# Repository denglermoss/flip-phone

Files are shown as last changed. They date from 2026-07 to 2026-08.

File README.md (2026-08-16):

# Custom Phone Project

## Overview

Designing and building a custom cell phone from scratch — hardware (PCB, electronics), embedded firmware, cellular communication, and eventually mechanical/enclosure design. Candybar / single-board form factor (locked 2026-08-16 — flip/clamshell deferred to v2). Long-term vision: the phone is the hub of a personal ecosystem of USB-connected devices. See `docs/ref/problem-definition.md` for full architecture, MVP, risks, and ecosystem vision.

## Goals

- **Learning / Portfolio**: Deepen hardware and embedded systems skills; build something impressive.
- **Actually Usable**: End goal is a device that can make real phone calls on a real cellular network.
- **The Challenge**: Push beyond prior experience (microcontrollers, simple PCBs) into RF, cellular comms, power management, and eventually mechanical integration.

## Scope

### In Scope
- Custom PCB design (candybar / single-board — display via ZIF connector, no hinge flex)
- Microcontroller + off-the-shelf cellular module architecture
- Firmware: call handling, UI, contacts, power management
- Making real phone calls on a real network
- Mechanical/enclosure design (deferred — decided after electronics are proven)
- Hardware selection constrained to preserve USB connectivity for future ecosystem modules

### Out of Scope (for now)
- Custom cellular modem / baseband processor design
- FCC certification (prototype stage; revisit if moving toward production)
- App store, browser, or smartphone features (camera IS included on rev1 — see `docs/ref/project-log.md` 2026-08-16)
- Custom OS (will use RTOS or bare metal)
- Ecosystem module design (car system, etc.) — future projects, not this one

## Documentation

Full doc index and source-of-truth assignments in `AGENTS.md`. Key docs:

- `docs/ref/problem-definition.md` — architecture, MVP, risks, ecosystem vision
- `docs/ref/requirements.md` — functional & non-functional requirements
- `docs/ref/constraints.md` — technical, budget, regulatory constraints
- `docs/ref/project-log.md` — decision log (dated), phase breakdown
- `docs/ref/bom.md` — bill of materials with prices and links
- `docs/work/` — active planning docs (block-diagram, pin assignment, task tracker, schematic completion plan, UI design)
- `docs/archive/` — completed/superseded plans + all revisit prompts

## Status

**Phase 1 (Research & Component Selection) — Complete.** All guiding hardware decisions locked: MCU (STM32H743ZI), modem (SIM7600NA-H), codec (ALC5651-CG), display (ST7789V SPI TFT), keypad (SMD tactile switches), USB architecture (modem-direct tethering, no ULPI). Zephyr development environment set up (2026-06-29).

**Phase 2 (HAT-Based Prototype) — Complete.** MVP achieved (2026-07-13): MCU firmware places and receives VoLTE calls with audio on Mint LTE. Keypad integrated + verified (2026-07-18): standalone dialer — user types phone numbers and places real calls with no PC involvement. See `docs/ref/project-log.md` Phase Breakdown.

**Phase 3 (Schematic Design) — In Progress (2026-07-28).** All parts sourced with KiCad models (no consignment). Schematic approach: flat sheet + global labels, MPCIe modem form factor (primary), LGA fallback. **Per-sheet progress** (see `docs/work/schematic-completion-plan.md` for details): Power ✅, MCU ~92%, Modem ~90%, Codec ✅ (restored), Keypad ✅, Display main ~80% (backlight FET pending), Display daughter ~70%, SIM/SD ✅. ERC: 0 errors, 15 warnings. Remaining work tracked in `docs/work/schematic-completion-plan.md`; full Phase 3-5 plan in `docs/work/task-tracker.md`.

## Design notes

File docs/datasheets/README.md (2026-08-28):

---
status: reference
updated: 2026-08-02
---
# Reference Documentation

Local copies of vendor datasheets, reference manuals, hardware design docs, and saved wiki pages that this project relies on. These are **not** version-controlled (see `.gitignore` — everything in this directory except this README is ignored). They are large binary files that vendors update independently. This index records what belongs here, the exact part numbers, and where to download each so anyone can re-fetch the current version.

## How to populate

Download each file below into this directory (`docs/datasheets/`). Browser "Save Page As" creates an `.html` file plus a `_files/` subdirectory of assets — both belong here. The `.gitignore` excludes everything except this README, so the files stay local-only.

## Mandatory: add missing datasheets before citing them

**If you need to reference a datasheet that is not already in this directory, you MUST find and download it first — do not cite specs from memory, web search snippets, or session context alone.** The local PDF is the source of truth for every part used in this project.

Workflow when a datasheet is missing:
1. Find the official PDF on the vendor's website (manufacturer product page → "Datasheet" link) or a reputable mirror (LCSC product page, Mouser, DigiKey, Analog Devices, TI, ST, etc.).
2. Download it into `docs/datasheets/` with a descriptive lowercase filename (e.g., `max17048.pdf`, `tps7a02.pdf`).
3. Add a row to the "Index → PDFs" table below with the filename, part/document name (including revision if known), and source URL.
4. Then cite the local PDF in project docs (e.g., `docs/datasheets/max17048.pdf §Pin Description`).

This rule exists because datasheet specs vary by revision and package variant — citing from memory risks the kind of pinout/voltage/package errors that are expensive to catch after PCB fab. If a datasheet cannot be found (rare — most parts have public datasheets), say so explicitly in the project log and flag the spec as unverified.

## Index

### PDFs

| File | Part / Document | Source |
|---|---|---|
| `SIM7600 Series Hardware Design_V1.03.pdf` | SIMCom SIM7600 Series Hardware Design Manual V1.03 (the version cited in project docs — §3.6 PCM interface, Table 32 1.8V Digital I/O) | https://simcom.ee/documents/SIM7600E/SIM7600%20Series%20Hardware%20Design_V1.03.pdf |
| `SIM7600_Series_PCIE_Hardware_Design_V1.03.pdf` | SIMCom SIM7600 Series PCIE Hardware Design Manual V1.03 (2020-03-20, 59pp) — Mini PCIe form factor variant. §2.2 edge connector pin description (PCM on pins 45/47/49/51 for PCIE variant, NC for PCIEA variant). §3.10.1 PCM interface spec (master, short sync, 16-bit, 2048kHz — same as LGA). §3.7 USIM (manual claims onboard SIM socket but Techship spec lists it as optional `o` — stock card does NOT have it; both variants need PCB SIM socket). §3.8 UART (1.8V logic — level shifter needed for 3.3V MCU). §3.6 USB 2.0 HS. Key: PCIE = no onboard codec = PCM digital audio (what we want); PCIEA = onboard NAU8810 = analog audio. | https://www.simcom.com/download/list-863-en.html (SIMCom download portal — search "SIM7600 PCIE Hardware Design") |
| `SIM7600_Series_Hardware_Design_V1.08.pdf` | SIMCom SIM7600 Series Hardware Design Manual V1.08 (newer, same PCM spec, may have fixes) | https://edworks.co.kr/wp-content/uploads/2022/04/SIM7600_Series_Hardware_Design_V1.08.pdf |
| `max9880a.pdf` | Analog Devices MAX9880A datasheet (Rev 2) — dual-port codec, TQFN-48. **SUPERSEDED 2026-07-19**: MAX9880A replaced by ALC5651 (see below). Retained for historical reference. | https://www.analog.com/media/en/technical-documentation/data-sheets/MAX9880A.pdf |
| `alc5651.pdf` | Realtek ALC5651 datasheet (Rev 0.9) — dual I2S/PCM audio hub codec, QFN-40 5×5mm. **Current codec (LOCKED 2026-07-19).** §7.5.1 Two I2S/PCM Interface (PCM Mode A = short sync, compatible with SIM7600). §7.4.1 PLL (2.048–40MHz input). §10 Application Circuit (Figure 36). Pinout Figure 4 (40-pin QFN). | https://www.lcsc.com/product-detail/C963633.html (datasheet link) |
| `tps63021.pdf` | Texas Instruments TPS6302x (TPS63020/TPS63021) datasheet (SLVS916I, Rev. I, Oct 2019) — 4A-switch buck-boost converter, VSON-14 (DSJ). TPS63021 = fixed 3.3V out; TPS63020 = adjustable. Covers L1 inductor selection (§8.2.1, recommended 1.5µH Coilcraft XFL4020-152ML). | https://www.ti.com/lit/ds/symlink/tps63021.pdf |
| `max17048.pdf` | Analog Devices/Maxim MAX17048-MAX17049 datasheet (Rev 7, Nov 2016, 19pp) — 3µA 1-Cell/2-Cell ModelGauge fuel gauge, TDFN-8 2×2mm + WLP. **MAX17048 senses battery voltage on VDD (pin 3); CELL (pin 2) is NC on the 1-cell part.** §Pin/Bump Descriptions p6, §Quick-Start p9, §Hibernate Mode p9. | https://www.analog.com/media/en/technical-documentation/data-sheets/MAX17048-MAX17049.pdf (mirror used: https://media.digikey.com/pdf/Data%20Sheets/Maxim%20PDFs/MAX17048-49_Rev7_Nov2016.pdf) |
| `mcp73831.pdf` | Microchip MCP73831/MCP73832 datasheet (DS20001984H, Rev H, 2020, 29pp) — Li-Ion/Li-Po linear charge management controller. **DFN-8 2×3mm + SOT-23-5 variants** (LCSC C150772 maps to DFN-8 despite "/MC" suffix). Pinout p1, electrical characteristics §1.0 p3-4. | https://ww1.microchip.com/downloads/aemDocuments/documents/APID/ProductDocuments/DataSheets/MCP73831-Family-Data-Sheet-DS20001984H.pdf (mirror used: https://cdn.sparkfun.com/assets/5/b/0/3/1/MCP73831_Datasheet.pdf) |
| `usblc6-2.pdf` | STMicroelectronics USBLC6-2 datasheet (DS4260 Rev 7, Dec 2021, 14pp) — very low capacitance ESD protection for USB 2.0. **Protects D+, D-, AND VBUS** (6-pin SOT-23-6: pins 1/6 = I/O1 D+, pins 3/4 = I/O2 D-, pin 2 = GND, pin 5 = VBUS). IEC 61000-4-2 Level 4 (±15kV air, ±8kV contact). 3.5pF max capacitance — USB 2.0 high-speed compatible. | https://www.st.com/content/ccc/resource/technical/document/datasheet/06/1d/48/9c/6c/20/4a/b2/CD00050750.pdf/files/CD00050750.pdf/jcr:content/translations/en.CD000507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 (mirror used: https://file.huaqiu.com/web1/M00/7F/9E/pIYBAFwjN3uAIFePAANr_4V7kNY752.pdf?filename=USBLC6-2_ST.pdf) |
| `stm32h743zi.pdf` | STMicroelectronics STM32H743ZI datasheet (LQFP-144 electrical/mechanical/pinout) | https://www.st.com/resource/en/datasheet/stm32h743zi.pdf |
| `dm00314099-stm32h742-stm32h743753-and-stm32h750-value-line-advanced-armbased-32bit-mcus-stmicroelectronics.pdf` | STMicroelectronics RM0433 Rev 8 — STM32H742/H743/753/H750 reference manual (peripheral registers, 3353 pp) | https://www.st.com/resource/en/reference_manual/dm00314099-stm32h742-stm32h743753-and-stm32h750-value-line-advanced-armbased-32bit-mcus-stmicroelectronics.pdf |
| `dm00499160-stm32h7-nucleo144-boards-mb1364-stmicroelectronics.pdf` | STMicroelectronics UM2407 Rev 5 — STM32H7 Nucleo-144 boards (MB1364) user manual (board schematics, jumper config, ST-Link) | https://www.st.com/resource/en/user_manual/dm00499160-stm32h7-nucleo144-boards-mb1364-stmicroelectronics.pdf |
| `ST7789V.pdf` | Sitronix ST7789V LCD controller datasheet (240RGB×320, 262K color TFT controller/driver) — covers main display (ST7789T3). ~~Also covered outer display (ST7789V3)~~ **outer display DROPPED 2026-08-16** (candybar pivot). Datasheet still valid for main display. | https://newhavendisplay.com/content/datasheets/ST7789V.pdf |
| `HS20HS072RX-main-display.pdf` | HS HS20HS072RX panel datasheet — 2.0" IPS TFT, 240×RGB×320, ST7789T3, 12-pin 0.5mm ZIF FPC (main display, LOCKED 2026-07-19). Pinout: 1=GND, 2=CS, 3=RS(DC), 4=SCL, 5=SDA, 6=RST, 7=NC, 8=I/O-VCC, 9=VCC, 10=LEDA, 11=LEDK, 12=GND. **SPI 4-wire** (not I2C — SCL/SDA are Sitronix SPI naming, confirmed against ST7789V §8.4). Backlight: 4 white LEDs in parallel, Vf=3.0V, IL=80mA. **Schematic pinout verified 2026-08-27** — J_DISP1 matches datasheet (was previously wrong, corrected). ⚠️ Re-review FPC connector orientation during PCB layout. | https://www.lcsc.com/product-detail/C5329582.html |
| ~~`ER-TFT1.14-2-outer-display.pdf`~~ | ~~EastRising ER-TFT1.14-2 panel datasheet~~ — **DROPPED 2026-08-16** (outer display eliminated with candybar pivot). ~~1.14" IPS TFT, 135×240, ST7789V, 8-pin 0.5mm FPC (outer display, LOCKED 2026-07-19).~~ PDF retained in datasheets/ for historical reference but part is no longer in the design. See project-log.md 2026-08-16 Form Factor Pivot. | https://www.buydisplay.com/1-14-inch-tft-lcd-display-ips-panel-screen-135x240-for-smart-watch |
| `sn74axc4t774.pdf` | TI SN74AXC4T774 datasheet (SCES898C, Rev C, May 2022) — 4-bit dual-supply bus transceiver with independent direction control. TSSOP-16 (PWR suffix). Used as U12 for I2S-2 level shifting (3.3V↔1.8V) between MCU and ALC5651 codec. Direction-controlled (not auto-sensing like TXB0108 — TXB0108 is NOT recommended for I2S per TI SCEA135). LCSC C1849453. | https://www.ti.com/lit/ds/symlink/sn74axc4t774.pdf |
| `alps-ssss8.pdf` | ALPS Alpine SSSS8 Series slide switch datasheet — 1.4(H)mm, 1.5/2.0mm-travel, surface mount (reflow) SPDT. SSSS811101 = horizontal actuator, 1-pole 2-position, 300mA 5V DC, 10k cycles, 6.7×2.6×1.4mm. **SUPERSEDED 2026-08-02**: SSSS811101 (maintained slide) replaced by SSAL120100 (momentary pushbutton) for soft on/off + 5s hard off architecture. See project-log 2026-08-02. LCSC C109335. **Note: the previous `alps-ssss2.pdf` (SSSS2 Series, 3.5mm through-hole) was the wrong series datasheet — SSSS811101 is SSSS8 Series (1.4mm SMD). Replaced 2026-07-28.** | https://tech.alpsalpine.com/cms.media/product_catalog_sw_02_ssss8_en_e99db3d0b9.pdf |
| *(not downloaded)* | ALPS Alpine SSAL120100 — momentary SPDT slide switch ("Single-side Recoil Type", spring-return). 7.6×1.2×4.1mm, SMD right-angle, 10mA@5V DC, gull wing. LCSC C335996. **Datasheet PDF not downloadable** — ALPS tech site returns 403 on direct PDF access, LCSC returns HTML wrapper. Specs verified from ALPS product page (https://tech.alpsalpine.com/e/products/detail/SSAL120100/) and LCSC product page (https://www.lcsc.com/product-detail/C335996.html). If the PDF becomes accessible, download as `alps-ssal120100.pdf`. | https://tech.alpsalpine.com/e/products/detail/SSAL120100/ |
| `gct-usb4085.pdf` | GCT (Global Connector Technology) USB4085-GF-A product drawing — USB 2.0 Type-C receptacle, 16-pin through-hole, right-angle horizontal, 5A VBUS, 10k cycles. Replaces SMD TYPE-C-31-M-12. DigiKey + LCSC C7095263. | https://gct.co/files/drawing/usb4085.pdf |
| `tps7a02.pdf` | Texas Instruments TPS7A02 datasheet (SBVS277C, Rev. C) — nanopower-IQ (25 nA), 200-mA LDO with enable. Covers all fixed-output variants incl. **TPS7A0218PDBVR** (1.8V fixed, SOT-23-5/DBV, 5-pin) used as U9 (1.8V codec rail). §Pin Functions (DBV: 1=IN, 2=GND, 3=EN, 4=NC, 5=OUT), §Electrical Characteristics, §8.2 Application Circuit (1µF Cin, 1µF Cout min, EN smart pulldown). VIN 1.5–6.0V, VOUT 0.8–5.0V fixed, 1.5% accuracy, 205mV typ dropout @200mA (3.3V). | https://www.ti.com/lit/ds/symlink/tps7a02.pdf |

### Saved wiki pages (HTML + `_files/` subdirectory)

| File (+ assets dir) | Resource | Source URL |
|---|---|---|
| `2inch LCD Module - Waveshare Wiki.html` (+ `2inch LCD Module - Waveshare Wiki_files/`) | Waveshare 2inch LCD Module wiki — pinout, schematic, example code (ST7789VW) | https://www.waveshare.com/wiki/2inch_LCD_Module |
| `SIM7600NA-H 4G HAT - Waveshare Wiki.html` (+ `SIM7600NA-H 4G HAT - Waveshare Wiki_files/`) | Waveshare SIM7600NA-H 4G HAT wiki — HAT pinout, audio port, AT commands, antennas | https://www.waveshare.com/wiki/SIM7600NA-H_4G_HAT |

### Non-PDF references (bookmark, don't download)

| Resource | URL |
|---|-----|
| Waveshare 2inch LCD Module product page | https://www.waveshare.com/2inch-lcd-module.htm |
| Waveshare SIM7600NA-H 4G HAT product page | https://www.waveshare.com/product/sim7600na-h-4g-hat.htm |
| STMicroelectronics STM32H743/753 documentation hub | https://www.st.com/en/microcontrollers-microprocessors/stm32h743-753/documentation.html |
| ~~Analog Devices MAX9880A product page~~ **SUPERSEDED** | https://www.analog.com/en/products/max9880a.html |

## Exact part numbers (for cross-checking on vendor sites)

- **MCU**: STM32H743ZIT6 (LQFP-144, 2MB Flash, 1MB RAM)
- **MCU dev board**: NUCLEO-H753ZI (substitute for obsolete NUCLEO-H743ZI; H753 = H743 + crypto, identical for this project)
- **Cellular module (final PCB)**: SIM7600NA-H (JLC pre-order C5380303; "SIM7600A-H" was a misnomer — corrected 2026-07-19)
- **Cellular module (prototyping HAT)**: SIM7600NA-H (Waveshare HAT, SKU 30717)
- **Audio codec**: Realtek ALC5651-CG (QFN-40, 5×5mm) — LCSC C963633 (JLC Extended)
- **Display dev module**: Waveshare 2inch LCD Module, SKU 17344 (ST7789VW driver)
- **Display controller**: ST7789V (Sitronix; Waveshare module uses ST7789VW variant — same datasheet covers both)
- **Display raw panel (final PCB — LOCKED 2026-07-19)**: HS HS20HS072RX (LCSC C5329582) — 2.0" IPS TFT, ST7789T3, 12-pin 0.5mm ZIF FPC
- ~~**Outer display raw panel (final PCB — LOCKED 2026-07-19)**: EastRising ER-TFT1.14-2 (BuyDisplay) — 1.14" IPS TFT, ST7789V, 8-pin 0.5mm FPC (purchased from BuyDisplay, not LCSC — user assembles post-PCB)~~ **DROPPED 2026-08-16** — outer display eliminated with candybar pivot. See project-log.md 2026-08-16 Form Factor Pivot.

## Maintenance

When a vendor publishes a new revision, replace the local file and update the "Source" URL (and the version in the filename) in this index. If a document is cited by version in the project docs (e.g., "Hardware Design Manual V1.03 §3.6"), note the version change in `docs/ref/project-log.md` so the citation trail stays accurate.

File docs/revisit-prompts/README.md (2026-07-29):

# Revisit Prompts

## Active

| Prompt | Status | Created | Summary |
|---|---|---|---|
| _(none — all prompts resolved and archived)_ | — | — | — |

## Archived

The following prompts have been resolved and locked. The files are in `archive/` and retained for historical reference only — do not re-run them.

| Prompt | Status | Archived | Resolution |
|---|---|---|---|
| Parts Sourcing (`parts-sourcing-revisit.md`) | RESOLVED | 2026-07-28 | 16 of 16 items resolved; 2 deferred to Phase 7 (speakers LS1/LS2 — case-mounted, not PCB-assembled). All parts sourced: J3 nano-SIM = SHOU HAN NANO SIM XG6P H1.35 (C7529386), J4 microSD = Molex 472192001 (C164170). All other parts: U1-U12 ICs (U5 codec = ALC5651-CG), USBC1 USB-C (Korean Hroparts), J2 test points, J5/J6 U.FL (Hirose), J7-J10 FPC (HDGC 0.5K-HX), SW1-SW20 (ALPS SKQGABE010), Y1 crystal (ECS AEC-Q200), L1 inductor (Coilcraft XFL4020-152MEC), MK1 mic (ZILLTEK ZTS6117). **No consignment parts remain. All parts have KiCad models.** |
| Cellular Module Selection (`modem-revisit.md`) | RESOLVED & LOCKED | 2026-06-28 | SIM7600 confirmed after two rounds. LARA-R6401 disqualified (911 not supported). EC25-AF documented as PCB fallback. |
| Codec / Audio Path (`codec-audio-path-revisit.md`) | RESOLVED & LOCKED | 2026-06-28 | ~~MAX9880A dual-port codec selected~~ → **Realtek ALC5651-CG** (2026-07-19 — JLC Extended, no consignment). MCU not in voice path. Fallback: MCU bridge with NAU8822. |
| Display Type (`display-decision.md`) | RESOLVED & LOCKED | 2026-06-28 | ST7789V SPI color TFT (2.0" 240×320, RGB565) selected. Five options evaluated. |
| USB HS / ULPI (`zephyr-usb-hs-ulpi-revisit.md`) | RESOLVED & LOCKED | 2026-06-28 | USB3300 ULPI dropped. SIM7600's own USB 2.0 HS port does tethering directly. MCU USB OTG_FS sufficient. |

See `docs/project-log.md` for the full decision log and rationale.

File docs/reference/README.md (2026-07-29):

# Reference Documentation

Local copies of vendor datasheets, reference manuals, hardware design docs, and saved wiki pages that this project relies on. These are **not** version-controlled (see `.gitignore` — everything in this directory except this README is ignored). They are large binary files that vendors update independently. This index records what belongs here, the exact part numbers, and where to download each so anyone can re-fetch the current version.

## How to populate

Download each file below into this directory (`docs/reference/`). Browser "Save Page As" creates an `.html` file plus a `_files/` subdirectory of assets — both belong here. The `.gitignore` excludes everything except this README, so the files stay local-only.

## Mandatory: add missing datasheets before citing them

**If you need to reference a datasheet that is not already in this directory, you MUST find and download it first — do not cite specs from memory, web search snippets, or session context alone.** The local PDF is the source of truth for every part used in this project.

Workflow when a datasheet is missing:
1. Find the official PDF on the vendor's website (manufacturer product page → "Datasheet" link) or a reputable mirror (LCSC product page, Mouser, DigiKey, Analog Devices, TI, ST, etc.).
2. Download it into `docs/reference/` with a descriptive lowercase filename (e.g., `max17048.pdf`, `tps7a02.pdf`).
3. Add a row to the "Index → PDFs" table below with the filename, part/document name (including revision if known), and source URL.
4. Then cite the local PDF in project docs (e.g., `docs/reference/max17048.pdf §Pin Description`).

This rule exists because datasheet specs vary by revision and package variant — citing from memory risks the kind of pinout/voltage/package errors that are expensive to catch after PCB fab. If a datasheet cannot be found (rare — most parts have public datasheets), say so explicitly in the project log and flag the spec as unverified.

## Index

### PDFs

| File | Part / Document | Source |
|---|---|---|
| `SIM7600 Series Hardware Design_V1.03.pdf` | SIMCom SIM7600 Series Hardware Design Manual V1.03 (the version cited in project docs — §3.6 PCM interface, Table 32 1.8V Digital I/O) | https://simcom.ee/documents/SIM7600E/SIM7600%20Series%20Hardware%20Design_V1.03.pdf |
| `SIM7600_Series_PCIE_Hardware_Design_V1.03.pdf` | SIMCom SIM7600 Series PCIE Hardware Design Manual V1.03 (2020-03-20, 59pp) — Mini PCIe form factor variant. §2.2 edge connector pin description (PCM on pins 45/47/49/51 for PCIE variant, NC for PCIEA variant). §3.10.1 PCM interface spec (master, short sync, 16-bit, 2048kHz — same as LGA). §3.7 USIM (manual claims onboard SIM socket but Techship spec lists it as optional `o` — stock card does NOT have it; both variants need PCB SIM socket). §3.8 UART (1.8V logic — level shifter needed for 3.3V MCU). §3.6 USB 2.0 HS. Key: PCIE = no onboard codec = PCM digital audio (what we want); PCIEA = onboard NAU8810 = analog audio. | https://www.simcom.com/download/list-863-en.html (SIMCom download portal — search "SIM7600 PCIE Hardware Design") |
| `SIM7600_Series_Hardware_Design_V1.08.pdf` | SIMCom SIM7600 Series Hardware Design Manual V1.08 (newer, same PCM spec, may have fixes) | https://edworks.co.kr/wp-content/uploads/2022/04/SIM7600_Series_Hardware_Design_V1.08.pdf |
| `max9880a.pdf` | Analog Devices MAX9880A datasheet (Rev 2) — dual-port codec, TQFN-48. **SUPERSEDED 2026-07-19**: MAX9880A replaced by ALC5651 (see below). Retained for historical reference. | https://www.analog.com/media/en/technical-documentation/data-sheets/MAX9880A.pdf |
| `alc5651.pdf` | Realtek ALC5651 datasheet (Rev 0.9) — dual I2S/PCM audio hub codec, QFN-40 5×5mm. **Current codec (LOCKED 2026-07-19).** §7.5.1 Two I2S/PCM Interface (PCM Mode A = short sync, compatible with SIM7600). §7.4.1 PLL (2.048–40MHz input). §10 Application Circuit (Figure 36). Pinout Figure 4 (40-pin QFN). | https://www.lcsc.com/product-detail/C963633.html (datasheet link) |
| `tps63021.pdf` | Texas Instruments TPS6302x (TPS63020/TPS63021) datasheet (SLVS916I, Rev. I, Oct 2019) — 4A-switch buck-boost converter, VSON-14 (DSJ). TPS63021 = fixed 3.3V out; TPS63020 = adjustable. Covers L1 inductor selection (§8.2.1, recommended 1.5µH Coilcraft XFL4020-152ML). | https://www.ti.com/lit/ds/symlink/tps63021.pdf |
| `max17048.pdf` | Analog Devices/Maxim MAX17048-MAX17049 datasheet (Rev 7, Nov 2016, 19pp) — 3µA 1-Cell/2-Cell ModelGauge fuel gauge, TDFN-8 2×2mm + WLP. **MAX17048 senses battery voltage on VDD (pin 3); CELL (pin 2) is NC on the 1-cell part.** §Pin/Bump Descriptions p6, §Quick-Start p9, §Hibernate Mode p9. | https://www.analog.com/media/en/technical-documentation/data-sheets/MAX17048-MAX17049.pdf (mirror used: https://media.digikey.com/pdf/Data%20Sheets/Maxim%20PDFs/MAX17048-49_Rev7_Nov2016.pdf) |
| `mcp73831.pdf` | Microchip MCP73831/MCP73832 datasheet (DS20001984H, Rev H, 2020, 29pp) — Li-Ion/Li-Po linear charge management controller. **DFN-8 2×3mm + SOT-23-5 variants** (LCSC C150772 maps to DFN-8 despite "/MC" suffix). Pinout p1, electrical characteristics §1.0 p3-4. | https://ww1.microchip.com/downloads/aemDocuments/documents/APID/ProductDocuments/DataSheets/MCP73831-Family-Data-Sheet-DS20001984H.pdf (mirror used: https://cdn.sparkfun.com/assets/5/b/0/3/1/MCP73831_Datasheet.pdf) |
| `usblc6-2.pdf` | STMicroelectronics USBLC6-2 datasheet (DS4260 Rev 7, Dec 2021, 14pp) — very low capacitance ESD protection for USB 2.0. **Protects D+, D-, AND VBUS** (6-pin SOT-23-6: pins 1/6 = I/O1 D+, pins 3/4 = I/O2 D-, pin 2 = GND, pin 5 = VBUS). IEC 61000-4-2 Level 4 (±15kV air, ±8kV contact). 3.5pF max capacitance — USB 2.0 high-speed compatible. | https://www.st.com/content/ccc/resource/technical/document/datasheet/06/1d/48/9c/6c/20/4a/b2/CD00050750.pdf/files/CD00050750.pdf/jcr:content/translations/en.CD000507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 (mirror used: https://file.huaqiu.com/web1/M00/7F/9E/pIYBAFwjN3uAIFePAANr_4V7kNY752.pdf?filename=USBLC6-2_ST.pdf) |
| `stm32h743zi.pdf` | STMicroelectronics STM32H743ZI datasheet (LQFP-144 electrical/mechanical/pinout) | https://www.st.com/resource/en/datasheet/stm32h743zi.pdf |
| `dm00314099-stm32h742-stm32h743753-and-stm32h750-value-line-advanced-armbased-32bit-mcus-stmicroelectronics.pdf` | STMicroelectronics RM0433 Rev 8 — STM32H742/H743/753/H750 reference manual (peripheral registers, 3353 pp) | https://www.st.com/resource/en/reference_manual/dm00314099-stm32h742-stm32h743753-and-stm32h750-value-line-advanced-armbased-32bit-mcus-stmicroelectronics.pdf |
| `dm00499160-stm32h7-nucleo144-boards-mb1364-stmicroelectronics.pdf` | STMicroelectronics UM2407 Rev 5 — STM32H7 Nucleo-144 boards (MB1364) user manual (board schematics, jumper config, ST-Link) | https://www.st.com/resource/en/user_manual/dm00499160-stm32h7-nucleo144-boards-mb1364-stmicroelectronics.pdf |
| `ST7789V.pdf` | Sitronix ST7789V LCD controller datasheet (240RGB×320, 262K color TFT controller/driver) — covers both main display (ST7789T3) and outer display (ST7789V3) | https://newhavendisplay.com/content/datasheets/ST7789V.pdf |
| `HS20HS072RX-main-display.pdf` | HS HS20HS072RX panel datasheet — 2.0" IPS TFT, 240×RGB×320, ST7789T3, 12-pin 0.5mm ZIF FPC (main display, LOCKED 2026-07-19). Pinout: 1=GND, 2=CS, 3=RS(DC), 4=SCL, 5=SDA, 6=RST, 7=NC, 8=I/O-VCC, 9=VCC, 10=LEDA, 11=LEDK, 12=GND. | https://www.lcsc.com/product-detail/C5329582.html |
| `ER-TFT1.14-2-outer-display.pdf` | EastRising ER-TFT1.14-2 panel datasheet — 1.14" IPS TFT, 135×240, ST7789V, 8-pin 0.5mm FPC top contact (outer display, LOCKED 2026-07-19). Pinout: 1=LEDA, 2=GND, 3=RESET, 4=RS(DC), 5=SDA, 6=SCL, 7=VDD, 8=CS. Purchased from BuyDisplay (not LCSC) — assembled by user post-PCB-assembly. | https://www.buydisplay.com/1-14-inch-tft-lcd-display-ips-panel-screen-135x240-for-smart-watch |
| `sn74axc4t774.pdf` | TI SN74AXC4T774 datasheet (SCES898C, Rev C, May 2022) — 4-bit dual-supply bus transceiver with independent direction control. TSSOP-16 (PWR suffix). Used as U12 for I2S-2 level shifting (3.3V↔1.8V) between MCU and ALC5651 codec. Direction-controlled (not auto-sensing like TXB0108 — TXB0108 is NOT recommended for I2S per TI SCEA135). LCSC C1849453. | https://www.ti.com/lit/ds/symlink/sn74axc4t774.pdf |
| `alps-ssss2.pdf` | ALPS Alpine SSSS2 Series slide switch datasheet — 3.5(H)mm, 2mm-travel, through-hole SPDT. SSSS213100 = horizontal actuator, 1-pole 2-position, 300mA 6V DC, 10k cycles. Used as SW21 (power on/off via TPS63021 EN pin). LCSC C115374. **Note: SSSS213100 not confirmed on DigiKey — may need LCSC sourcing or C&K SS-12D1505-G 2 alternative.** | http://www.stm32circle.com/resources/Datasheets/ALPS_SSSS2.pdf |
| `gct-usb4085.pdf` | GCT (Global Connector Technology) USB4085-GF-A product drawing — USB 2.0 Type-C receptacle, 16-pin through-hole, right-angle horizontal, 5A VBUS, 10k cycles. Replaces SMD TYPE-C-31-M-12. DigiKey + LCSC C7095263. | https://gct.co/files/drawing/usb4085.pdf |

### Saved wiki pages (HTML + `_files/` subdirectory)

| File (+ assets dir) | Resource | Source URL |
|---|---|---|
| `2inch LCD Module - Waveshare Wiki.html` (+ `2inch LCD Module - Waveshare Wiki_files/`) | Waveshare 2inch LCD Module wiki — pinout, schematic, example code (ST7789VW) | https://www.waveshare.com/wiki/2inch_LCD_Module |
| `SIM7600NA-H 4G HAT - Waveshare Wiki.html` (+ `SIM7600NA-H 4G HAT - Waveshare Wiki_files/`) | Waveshare SIM7600NA-H 4G HAT wiki — HAT pinout, audio port, AT commands, antennas | https://www.waveshare.com/wiki/SIM7600NA-H_4G_HAT |

### Non-PDF references (bookmark, don't download)

| Resource | URL |
|---|-----|
| Waveshare 2inch LCD Module product page | https://www.waveshare.com/2inch-lcd-module.htm |
| Waveshare SIM7600NA-H 4G HAT product page | https://www.waveshare.com/product/sim7600na-h-4g-hat.htm |
| STMicroelectronics STM32H743/753 documentation hub | https://www.st.com/en/microcontrollers-microprocessors/stm32h743-753/documentation.html |
| ~~Analog Devices MAX9880A product page~~ **SUPERSEDED** | https://www.analog.com/en/products/max9880a.html |

## Exact part numbers (for cross-checking on vendor sites)

- **MCU**: STM32H743ZIT6 (LQFP-144, 2MB Flash, 1MB RAM)
- **MCU dev board**: NUCLEO-H753ZI (substitute for obsolete NUCLEO-H743ZI; H753 = H743 + crypto, identical for this project)
- **Cellular module (final PCB)**: SIM7600NA-H (JLC pre-order C5380303; "SIM7600A-H" was a misnomer — corrected 2026-07-19)
- **Cellular module (prototyping HAT)**: SIM7600NA-H (Waveshare HAT, SKU 30717)
- **Audio codec**: Realtek ALC5651-CG (QFN-40, 5×5mm) — LCSC C963633 (JLC Extended)
- **Display dev module**: Waveshare 2inch LCD Module, SKU 17344 (ST7789VW driver)
- **Display controller**: ST7789V (Sitronix; Waveshare module uses ST7789VW variant — same datasheet covers both)
- **Display raw panel (final PCB — LOCKED 2026-07-19)**: HS HS20HS072RX (LCSC C5329582) — 2.0" IPS TFT, ST7789T3, 12-pin 0.5mm ZIF FPC
- **Outer display raw panel (final PCB — LOCKED 2026-07-19)**: EastRising ER-TFT1.14-2 (BuyDisplay) — 1.14" IPS TFT, ST7789V, 8-pin 0.5mm FPC (purchased from BuyDisplay, not LCSC — user assembles post-PCB)

## Maintenance

When a vendor publishes a new revision, replace the local file and update the "Source" URL (and the version in the filename) in this index. If a document is cited by version in the project docs (e.g., "Hardware Design Manual V1.03 §3.6"), note the version change in `docs/project-log.md` so the citation trail stays accurate.

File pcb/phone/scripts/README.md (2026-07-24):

# Schematic Generation Scripts

These Python scripts generate KiCad schematic sheets (`.kicad_sch`) via direct
s-expression manipulation. They were used during Phase 3 (schematic design) to
create the hierarchical sub-sheets from the block diagram.

## Scripts

| Script | Output |
|---|---|
| `gen_schematics.py` | Root sheet (`phone.kicad_sch`) — hierarchical sheet boxes |
| `gen_modem_sch.py` | `modem.kicad_sch` — MPCIe socket + TXB0108 level shifter |
| `gen_codec_sch.py` | `codec.kicad_sch` — ALC5651 codec + I2S shifter + transducers |
| `gen_display_sch.py` | `display.kicad_sch` + `display_daughter.kicad_sch` |
| `gen_keypad_sch.py` | `keypad.kicad_sch` — 5×4 tactile switch matrix |
| `gen_sim_sd.py` | `sim_sd.kicad_sch` — SIM socket + microSD |

## Usage

```powershell
cd pcb/phone/scripts
python gen_schematics.py   # generates root sheet
python gen_modem_sch.py    # generates modem sheet
# etc.
```

## Notes

- These scripts are snapshots of the initial schematic generation. The `.kicad_sch`
  files have since been edited directly (via MCP tools, Python scripts, and KiCad
  GUI). Re-running these scripts will **overwrite** manual edits.
- Library tools (rebuild, verify, extract pins) are in `pcb/phone/lib/`, not here.

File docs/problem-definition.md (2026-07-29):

# Problem Definition

## The Problem

Design and build a custom cell phone from scratch that can make and receive real voice calls on a live cellular network in the United States. The device must eventually become a usable daily-driver, not just a lab prototype.

**Form factor: flip/clamshell (LOCKED 2026-07-19).** Two PCBs (main board + display daughterboard) connected via a hinge flex cable. The display daughterboard is trivial (~5 components + 3 ZIF connectors). Hinge mechanism and enclosure design are deferred to Phase 7 (mechanical). See `docs/project-log.md` 2026-07-19 Display Panel Selection + Flip Form Factor Locked.

## Modular Ecosystem Vision (Future — Does Not Affect MVP)

The phone is the first and primary project. However, the long-term vision is a **personal ecosystem of targeted devices** that can connect to the phone (or each other) for connectivity and shared data. The phone acts as the hub — providing LTE, contacts, music storage — while satellite modules handle specific tasks with their own UIs.

**First envisioned module: Car System**
- Display navigation (Google Maps alternatives — Organic Maps, OsmAnd, Mapbox)
- Play music (local files, phone storage, Spotify via librespot)
- Connect to phone via **USB** for tethered LTE + data + charging (primary), or Bluetooth/WiFi (future wireless modules)
- This is essentially a custom head unit / infotainment system

**Design principle**: The phone's hardware and firmware decisions must not prevent ecosystem integration. Specifically, the phone must expose connectivity interfaces (USB at minimum) that allow a future module to access LTE tethering, file storage, and potentially audio. This does not change the MVP scope — it only constrains hardware choices to leave the door open.

**Tethering architecture (updated 2026-06-28)**: LTE tethering to the car module uses the **SIM7600's own USB 2.0 HS port (480 Mbps)** directly — the modem presents itself as a USB network adapter (RNDIS/ECM via `AT+CUSBPIDSWITCH`), bypassing the MCU entirely. The MCU's USB (OTG_FS, 12 Mbps) handles firmware updates, file/MSC transfer, and debug. A future internal USB 2.0 hub (USB2514) presents both the modem (LTE) and the MCU (files) to the car module over one USB-C cable. The earlier "MCU bridges LTE to USB CDC ECM, needs USB HS via ULPI" plan is superseded — no USB3300 ULPI transceiver needed. See `docs/project-log.md` 2026-06-28 USB HS/ULPI Revisit.

## Why This Is Hard

A cell phone is a convergence of five engineering disciplines, each non-trivial on its own:

1. **Cellular Communication** — The device must register on a real LTE network, authenticate via SIM, and establish VoLTE calls. This requires a cellular module, correct AT command sequencing, audio path configuration, and antenna integration. Get any of this wrong and there's no call.

2. **Hardware / PCB Design** — MCU, cellular module, power management, audio circuit, display, keypad, SIM, and antenna all on a custom PCB. RF trace impedance control, power rail integrity for 2A+ module peaks, and component placement all matter.

3. **Embedded Firmware** — An RTOS must concurrently manage: UART communication with the cellular module (parsing async AT responses), UI rendering on a display, keypad input handling, call state machine, and power management policies. All within tight memory and power constraints.

4. **Power Management** — Cellular modules draw 2A+ peaks during transmission. The battery, regulators, and charging circuit must handle this while fitting in a small enclosure. Standby time needs to be at least 24 hours.

5. **Mechanical Integration** (Phase 7) — Enclosure, keypad feel, display mounting, antenna placement, and hinge mechanism. Form factor is locked (flip/clamshell); mechanical design is a separate phase that depends on the electronics being proven first.

## Architecture (Flip/Clamshell — Locked 2026-07-19)

```
┌─────────────────────────────┐
│        Main Board            │
│  - MCU (RTOS)                │
│  - Cellular Module (LTE)     │
│  - SIM Card Slot             │
│  - Keypad                    │
│  - Mic + Battery + Charging  │
│  - Power Regulation          │
│  - Antenna                   │
│  - USB (data + power) ←──┐   │ ← Ecosystem interconnect
│  - (future: BT/WiFi)     │   │
└──────────────────────────┼──┘
                           │
    ┌──────────────────────┘
    │ Hinge flex (14-pin 0.5mm FFC)
    │ — display SPI, backlight,
    │   earpiece, outer display CS2/DC2
    │
┌─────────────────────────────┐
│   Display Daughterboard       │
│  - Main display (ST7789V 2.0")│
│  - Outer display (1.14" TFT)  │
│  - Earpiece speaker            │
│  - Backlight FET + resistors  │
└─────────────────────────────┘

    ┌──────────────────────┐
    │  Future Module (Car)  │
    │  - SBC (Linux)         │
    │  - Display (5-7" TFT)  │
    │  - Audio out            │
    │  - USB host to phone    │
    │  - Uses phone LTE       │
    └────────────────────────┘
Ecosystem modules are future scope.
```

## MVP Definition

**Minimum Viable Phone**: A device that can make and receive voice calls on a US LTE network.

| Feature | MVP | Daily Driver |
|---|-----|---|
| Make calls | ✅ | ✅ |
| Receive calls | ✅ | ✅ |
| Contacts | ❌ | ✅ |
| SMS | ❌ | ✅ |
| Menu system | ❌ | ✅ |
| Battery indicator | ❌ | ✅ |
| Signal indicator | ❌ | ✅ |
| Bluetooth | ❌ | Maybe |
| USB data (ecosystem) | ❌ | ✅ |
| Enclosure | Test jig | ✅ |

## Key Constraints Summary

| Constraint | Value |
|---|---|
| Region | United States |
| Network | LTE (VoLTE) |
| Carrier | T-Mobile/Mint recommended (prepaid) |
| Firmware | Zephyr RTOS |
| PCB EDA | KiCad |
| Budget | Keep low; flexible |
| Prototype BOM | < $150/unit |
| Form factor | Flip/clamshell (LOCKED 2026-07-19) — two PCBs + hinge flex; mechanical design in Phase 7 |
| Assembly | Hand-solderable for prototypes |
| Enclosure | 3D print (FDM/SLA) or CNC |
| Ecosystem interconnect | USB (data + power); BT/WiFi deferred |

## Key Risks

1. **VoLTE configuration** — Getting VoLTE working via AT commands may require carrier-specific settings. Need to validate early with a breakout board before committing to PCB design.
2. **Antenna/RF** — LTE antenna design on a custom PCB may have poor performance. May need PCB respin.
3. **Power budget** — Meeting 24h standby with a small battery while powering an LTE module is tight.
4. **Carrier device whitelisting** — Some US carriers block unknown IMEIs. T-Mobile prepaid is the most lenient, but this needs validation.
5. **Mechanical/form factor** — Flip/clamshell locked 2026-07-19 (two PCBs + hinge flex). Hinge mechanism, enclosure fit, and keypad feel are Phase 7 concerns. The display daughterboard is trivial (~5 components); the main board complexity is unchanged vs single-board.
6. **Ecosystem compatibility** (future risk) — Hardware choices (MCU USB capability, modem USB routing, connector selection) must not preclude future module connectivity. **Resolved 2026-06-28**: tethering uses the SIM7600's own USB 2.0 HS port directly (no MCU USB HS / ULPI needed); rev1 routes the modem USB to a connector footprint to preserve the option, with an internal USB hub planned for the ecosystem respin. Low risk.
7. ~~**MAX9880A codec availability/compatibility**~~ **→ ALC5651 codec availability/compatibility** (pre-PCB risk — **FULLY RESOLVED 2026-07-19**): ~~The selected dual-port codec (MAX9880A) has been verified...~~ **SUPERSEDED 2026-07-19**: MAX9880A replaced by **Realtek ALC5651-CG** (LCSC C963633, QFN-40 5×5mm, JLC Extended — no consignment). All three pre-PCB items verified for ALC5651: (1) PCM short-frame sync is confirmed compatible — ALC5651 §7.5.1 PCM Mode A (short sync, Figures 10-11) in slave mode matches SIM7600 §3.6 (master, short sync, 16-bit, 2048/4096kHz BCLK); (2) stock is available at LCSC (407 units, JLC Extended — no consignment needed); (3) SIM7600 PCM pin voltage is 1.8V — confirmed 2026-06-30 from HW Design Manual V1.03 (Table 32 + §3.6.2). PCM lines connect directly to the ALC5651 (also 1.8V). Datasheet (Rev 0.9, 134pp) is complete — full pinout, registers, application circuit, timing, package. The fallback (MCU bridge with NAU8822) remains documented. The Waveshare HAT prototyping (NAU8810) validates the SIM7600 PCM voice output independent of this risk. See project-log.md 2026-07-19 Codec Swap MAX9880A→ALC5651.

## Success Criteria

- **MVP**: ~~Successfully place and receive a voice call from the custom-built device to another phone, with intelligible audio, on a US LTE network.~~ **ACHIEVED 2026-07-13** — MCU firmware places outgoing VoLTE call (`ATD6078821755;` → `VOICE CALL: BEGIN` → `VOICE CALL: END`) and receives incoming calls (detects `RING` URC → auto-answers with `ATA` → `VOICE CALL: BEGIN`). Audio works both directions through HAT's NAU8810 codec. Running on Nucleo H753ZI + Waveshare SIM7600NA-H HAT (not yet custom PCB). See project-log.md 2026-07-13.
- **Daily driver**: Use the device as primary phone for one week, including contacts, SMS, and acceptable battery life.

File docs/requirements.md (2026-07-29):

# Requirements

## Functional Requirements

### FR-1: Cellular Communication
- **FR-1.1**: Device shall place outgoing voice calls to any phone number.
- **FR-1.2**: Device shall receive incoming voice calls and alert the user (ring).
- **FR-1.3**: Device shall support SMS send/receive (post-MVP, required for daily-driver).
- **FR-1.4**: Device shall connect to a real cellular network via a standard SIM card.
- **FR-1.5**: Device shall operate on networks currently active in the user's region (see constraints — 2G sunset issue).

### FR-2: User Interface
- **FR-2.1**: Device shall have a numeric keypad (0-9, *, #) plus call/end buttons.
  - **Prototype status (2026-07-18)**: Implemented on the Nucleo+HAT prototype using a 4×4 matrix keypad (Adafruit PID 3844) via Zephyr's `gpio-kbd-matrix` input driver. Keys: 0-9/\*/# = digits, A = Call, B = End/Cancel/Reject, C = Backspace, D = Menu (future). Final PCB will use SMD tactile switches in a 5×4 matrix (same driver, different devicetree pins).
- **FR-2.2**: Device shall have a display capable of showing: call status, dialed digits, contacts list, signal strength, battery level.
  - **Prototype status (2026-07-18)**: Call status + dialed digits implemented (LVGL labels on ST7789V). Signal strength and battery level not yet implemented (signal indicator is next; battery indicator is PCB-phase — needs MAX17048 fuel gauge in the battery power path).
- **FR-2.3**: Device shall support navigation buttons (up/down/select or D-pad) for menu interaction.
- **FR-2.4**: Device shall provide audible feedback (ringtones, key tones, call audio).

### FR-3: Contacts & Storage
- **FR-3.1**: Device shall store contacts locally (name + phone number). (Post-MVP)
- **FR-3.2**: Device shall persist contacts across power cycles. (Post-MVP)
- **FR-3.3**: Device shall allow adding, deleting, and editing contacts. (Post-MVP)

### FR-4: Power Management
- **FR-4.1**: Device shall be battery-powered and rechargeable via USB.
- **FR-4.2**: Device shall monitor and display battery level.
- **FR-4.3**: Device shall enter low-power mode when idle (display off, modem standby).
- **FR-4.4**: Device shall support a standby time of at least 24 hours (target).

### FR-5: Form Factor (Flip/Clamshell — LOCKED 2026-07-19)
- **FR-5.1**: Device form factor is flip/clamshell — two PCBs (main board + display daughterboard) connected via a 14-pin 0.5mm hinge flex cable. Main display (ST7789V 2.0") + outer display (1.14" TFT) on the daughterboard; keypad, MCU, modem, battery, and connectors on the main board.
- **FR-5.2**: Mechanical design (enclosure, hinge mechanism, keypad feel) is deferred to Phase 7 — depends on electronics being proven first. See `docs/project-log.md` 2026-07-19 Display Panel Selection + Flip Form Factor Locked.
- **FR-5.3**: User has access to FDM, SLA, and CNC for enclosure fabrication.

### FR-6: Ecosystem Connectivity (Future — Constrains Hardware Selection Now)
- **FR-6.1**: Device MCU shall have USB capability (device or OTG mode) to enable future module connectivity. This is a hardware selection constraint, not an MVP feature.
- **FR-6.2**: Device PCB shall include a USB data connector (not charge-only) routed to the MCU. Physical connector type TBD.
- **FR-6.3**: Future scope (post-daily-driver): USB tethering to expose LTE connectivity to external modules. **Architecture (2026-06-28)**: tethering uses the SIM7600's own USB 2.0 HS port directly (RNDIS/ECM via `AT+CUSBPIDSWITCH`), bypassing the MCU — the modem is the USB network adapter, not the MCU. The MCU's USB (OTG_FS) is not in the tethering path. See project-log.md 2026-06-28 USB HS/ULPI Revisit.
- **FR-6.4**: Future scope: File access (contacts, music storage) over USB for external modules.
- **FR-6.5**: Bluetooth/WiFi for wireless ecosystem modules is deferred — not a hardware selection constraint at this time.

## Non-Functional Requirements

### NFR-1: Performance
- Call setup time < 10 seconds from pressing "call" to hearing ringback.
- UI response time < 200ms for keypad input.
- Boot time (MCU firmware ready + UI displayed): < 15 seconds. Note: full LTE network registration is a separate, longer sequence (~15–30s depending on carrier and signal) and is not included in this target. The phone shall show a "searching for network" indicator during registration.

### NFR-2: Reliability
- Device shall not crash during a phone call.
- Device shall recover gracefully from network disconnection.
- Device shall handle power-on/power-off cycles without data loss.

### NFR-3: Manufacturability
- PCB design shall be producible by standard PCB fab houses (e.g., JLCPCB, PCBWay).
- Components shall be sourced from available distributors (DigiKey, Mouser, LCSC).
- Assembly shall be feasible with hand soldering for prototypes, **except the cellular module** — all LTE/VoLTE modules are LGA and require reflow or JLCPCB assembly. Realistic approach: JLCPCB assembles the modem section (~$57–72), hand-solder the rest. No LTE module exists in a hand-friendly package; this is an industry reality. (Updated 2026-06-28 per modem revisit.) **MPCIe option (primary 2026-07-22)**: the SIM7600NA-H-PCIE Mini PCIe socketed card plugs into an SMD socket that reflows with the rest of the board — no LGA reflow, no JLC PCBA required for the modem. The MPCIe card is the primary form factor; bare LGA is the fallback. See `docs/constraints.md` MPCIe section and `docs/project-log.md` 2026-07-22 Schematic Approach entry.

### NFR-4: Maintainability
- Firmware shall be modular and well-structured.
- Hardware design files shall be version-controlled and documented.
- Schematics and PCB layouts shall be in KiCad (open-source EDA).

### NFR-5: Cost
- Prototype BOM cost target: < $150 per unit (excluding PCB fab costs).
- Total project budget: keep relatively low; avoid gold-plating.

## Resolved Decisions

- **Region**: United States
- **Network**: LTE with VoLTE (2G/3G are shut down in the US)
- **Carrier**: No preference — will use cheapest/easiest prepaid SIM. T-Mobile/Mint recommended (most lenient with non-certified devices, good LTE band coverage).
- **MVP scope**: Voice calls only (make/receive). Contacts, SMS, menus are post-MVP.
- **Daily-driver scope**: Calls + contacts + SMS + basic menu system (feature phone experience).
- **Display**: ST7789V SPI color TFT, 2.0" 240×320, RGB565. See research-notes.md Display Options section and project-log.md 2026-06-28 Display Selection.
- **Keypad**: SMD tactile switches on custom PCB traces (LOCKED 2026-06-28). See Resolved Questions below and project-log.md 2026-06-28 Keypad Selection.
- **Enclosure/Form factor**: Flip/clamshell — two PCBs (main board + display daughterboard) connected via hinge flex cable. **LOCKED 2026-07-19** (supersedes 2026-06-28 deferral). Hinge mechanism + enclosure design deferred to Phase 7 (mechanical design). User has FDM, SLA, and CNC access.
- **Firmware**: Zephyr RTOS — balances concurrency needs with maintainability for a daily-driver device. See project-log.md 2026-06-28 RTOS Selection.

## Open Questions (Requirements)

- [ ] **MCU-to-modem UART stress test** (post-MVP, pre-PCB): Run a long-duration stress test of the LPUART1 ↔ SIM7600 UART link — send 100+ AT commands back-to-back with no delay, verify zero data loss (every response contains expected result code). Test with varied response sizes (short `AT`→`OK`, long `AT+CGMM`, multi-line `AT+COPS?`). Also test GPS NMEA streaming (continuous data into the 1KB ring buffer — verify no overflow). This validates the interrupt-driven UART + ring buffer architecture is reliable enough for the final PCB. Deferred until after the MVP call works — the current 4-command test is sufficient for MVP development. See project-log.md 2026-07-13 entries.

## Resolved Questions (moved from Open)

- [x] **Bluetooth support**: Deferred to post-MVP. Will be added as an external module (e.g., BM83 for classic BT + BLE) when the Bluetooth feature (rated 6) is implemented. Neither STM32H7 nor ESP32-S3 has classic BT (A2DP), so an external module is needed regardless of MCU choice.
- [x] **MCU selection**: STM32H743ZI (LQFP-144, 480MHz Cortex-M7). See project-log.md 2026-06-28 MCU Selection.
- [x] **FreeRTOS vs Zephyr**: Zephyr RTOS. See project-log.md 2026-06-28 RTOS Selection.
- [x] **USB mode (partial)**: ~~USB FS (built-in PHY) for MVP; USB HS via external ULPI transceiver (USB3300) is a board-level upgrade path preserved by the LQFP-144 package.~~ **SUPERSEDED 2026-06-28**: USB FS (built-in PHY, 12 Mbps) is the committed MCU USB path for all MCU-originated USB (firmware, files/MSC, CDC ACM debug). USB HS via ULPI is **dropped** — no longer needed: the SIM7600's own USB 2.0 HS port (480 Mbps) does ecosystem tethering directly via RNDIS/ECM (`AT+CUSBPIDSWITCH`), bypassing the MCU. Do NOT populate USB3300. The phone (MCU) and the modem are both USB **devices** in ecosystem scenarios (car module is host); a future internal USB 2.0 hub (USB2514) presents both to the host over one cable. OTG host capability is a bonus, not a requirement. See project-log.md 2026-06-28 USB HS/ULPI Revisit.
- [x] **USB mode (device-only vs OTG)**: The phone (MCU) and modem are both USB **devices** in ecosystem scenarios — the car module is the USB host. OTG host capability on the MCU is a bonus, not a requirement. The STM32H743's OTG_FS supports device mode (sufficient for firmware, files, debug). No scenario currently requires the phone to be a USB host. See FR-6.1 and project-log.md 2026-06-28 USB HS/ULPI Revisit.
- [x] **Modem revisit (2026-06-28, first round)**: SIM7600 selection confirmed after reviewing standby power, B71 validation, simultaneous VoLTE+data, and LGA assembly. Two changes: (1) switch prototyping HAT to SIM7600NA-H (~$89, has B71 + NAU8810 codec) — resolves B71 validation gap; (2) make simultaneous VoLTE+data the first HAT test — if it fails, it blocks a future ecosystem feature (not the MVP). Standby power figure corrected: 17.5 mA idle/DRX (not 3 mA deep-sleep). NFR-3 updated to acknowledge LGA assembly reality. See project-log.md 2026-06-28 Modem Revisit.
- [x] **Modem revisit (2026-06-28, second round — LOCKED)**: SIM7600 selection **locked** after full re-evaluation. Key findings: (1) **LARA-R6401 disqualified** — 911/E911 not supported (safety disqualifier); (2) **EC25-AF evaluated** as fallback — T-Mobile voice certified, B71, but no codec breakout and higher idle current (23.3 mA); (3) **PDP context conflict is AT+NETOPEN-specific** — the project uses CMUX+PPP which bypasses it (standard pattern: Linux n_gsm, RT-Thread, ESP-IDF); (4) **simultaneous VoLTE+data is NOT a requirement** — not needed for MVP or daily driver; "pause data during call" is acceptable for the future ecosystem too. EC25-AF documented as PCB fallback if SIM7600 HAT testing reveals a blocking issue. See project-log.md 2026-06-28 Modem Revisit (Second Round).
- [x] **Codec selection (2026-06-28 — LOCKED, updated 2026-07-19)**: ~~**MAX9880A** selected as audio codec (Maxim/ADI, TQFN-48, ~$1.70).~~ **SUPERSEDED 2026-07-19**: MAX9880A replaced by **Realtek ALC5651-CG** (LCSC C963633, QFN-40 5×5mm, JLC Extended — no consignment). Same dual-port architecture: SIM7600 PCM → codec I2S-1 (voice), STM32H743 I2S → codec I2S-2 (music). **MCU is NOT in the voice audio path during calls.** Key findings: (1) all common codecs (WM8960, NAU8810, NAU8822, SGTL5000, TLV320AIC3204/3104, ES8316/8388) have only ONE digital audio port — cannot accept PCM and I2S simultaneously (the original "single codec unifies voice and music" claim was false); (2) the SIM7600 outputs PCM only (fixed master mode, short-frame sync, 16-bit linear — no I2S mode); (3) dual-port codecs are rare — MAX9880A (Maxim/ADI) and ALC5651/ALC5640/ALC5642 (Realtek) are the hobbyist-accessible options. ALC5651 selected over MAX9880A because it's JLC-sourced (eliminates Mouser consignment), has better specs (100dBA DAC vs 96dB, 94dBA ADC vs 82dB), smaller package (QFN-40 5×5mm vs TQFN-48 6×6mm), and has ASRC (asynchronous sample rate conversion per interface). PCM compatibility verified: ALC5651 §7.5.1 PCM Mode A (short sync) matches SIM7600 §3.6 (master, short sync, 16-bit, 2048/4096kHz). Fallback: MCU bridge with NAU8822 if ALC5651 unavailable. See project-log.md 2026-07-19 Codec Swap MAX9880A→ALC5651 and research-notes.md Codec Selection section.
- [x] **Display selection (2026-06-28 — LOCKED)**: **ST7789V SPI color TFT** (2.0" 240×320, 4-wire SPI, RGB565, ~$5–8). Five options evaluated: (1) ST7789V TFT — selected; (2) SSD1351 color OLED — rejected (actually higher power ~57–71mA vs TFT ~30–50mA, 3–5x cost at $15–24, 128×128 too low, not in Zephyr main tree); (3) E-ink — **DISQUALIFIED** (blocks three 5+ features: camera preview 6 at ~0.5–3fps refresh, photo capture 6 with spot-color only, video 5; true color e-ink not available at 1.5–2.4"); (4) LTDC parallel RGB — rejected (20–28 GPIO, needs external SDRAM, overkill res); (5) ST7735 1.8" — rejected (too low res). ST7789v driver (`display_st7789v.c`) is the most mature SPI display driver in Zephyr main tree with native LVGL support. 6 GPIO pins, 150KB framebuffer fits internal 1MB SRAM (no external SDRAM), color-capable (satisfies "no 5+ blocked"), lower power than the OLED alternative. Backlight PWM-dimmable/off during standby (modem dominates standby power). Pre-PCB: verify ST7789v driver on STM32H7 + target Zephyr version (MIPI DBI API conversion had teething issues). See project-log.md 2026-06-28 Display Selection and research-notes.md Display Options section.
- [x] **Keypad selection (2026-06-28 — LOCKED)**: **SMD tactile switches on custom PCB traces** for the final PCB. Three options evaluated: (1) SMD tactile switches — selected (snappy, cheap ~$1–2, easy to source, no custom tooling); (2) conductive-rubber (silicone dome) over PCB pads — phone-like feel but requires custom silicone sheet (~$50–150 mold run); (3) membrane keypad (PET stack) — sealed but flat feel, hard to source in small qty. 5×4 matrix = 9 GPIO for ~20 keys (12 numeric + 2 call/end + 3–5 nav + 1 spare). Matrix/GPIO allocation identical regardless of switch technology. Phase 2 prototyping: off-the-shelf 4×4 matrix module + loose tactile buttons (identical electrical interface, no firmware rework). Keypad feel is a Phase 7 (mechanical/enclosure) concern. See project-log.md 2026-06-28 Keypad Selection.
- [x] **USB-C connector type (2026-07-19 — LOCKED)**: 16-pin USB-C (USB 2.0) for the main MCU USB connector. USB FS/HS only needs D+/D- — 24-pin USB 3.x is unnecessary. Micro-USB is obsolete and not considered. See project-log.md 2026-07-19.
- [x] **Modem USB HS port on rev1 (2026-07-19 — LOCKED)**: Route SIM7600 USB HS D+/D- to an **unpopulated connector footprint** on rev1. Preserves tethering + modem FW update + USB diagnostics + GNSS-over-USB + ecosystem options without a respin. MCU USB OTG_FS goes to the main populated USB-C. See project-log.md 2026-07-19.
- [x] **GNSS antenna on rev1 (2026-07-19 — LOCKED)**: Include **U.FL footprint** for GNSS antenna on rev1. SIM7600 has built-in GNSS (validated 2026-07-12). User wants this board to potentially be the final version — deferring would mean a respin. See project-log.md 2026-07-19.
- [x] **Loudspeaker on rev1 (2026-07-19 — LOCKED)**: Include **both earpiece and loudspeaker** on rev1. MAX9880A stereo outputs drive both at no extra codec cost. See project-log.md 2026-07-19.
- [x] **SIM + microSD connector strategy (2026-07-19 — DEFERRED TO SOURCING)**: Combo SIM+microSD socket vs separate sockets — decision deferred to BOM finalization based on reliable availability. If combo is reliably sourceable, use it (saves space); else use separate sockets. Both blocks appear in the block diagram. See project-log.md 2026-07-19.

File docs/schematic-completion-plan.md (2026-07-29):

# Schematic Completion Plan

> **Created**: 2026-07-28
> **Purpose**: Track remaining work to complete the PCB schematic (Phase 3) based on a full per-sheet review.
> **Source**: Per-sheet subagent reviews (9 sheets) + KiCad MCP ERC run + git history investigation.

---

## Current State (verified 2026-07-28)

| Sheet | Status | Notes |
|---|---|---|
| Power | ✅ Complete | Functionally done; refdes mismatches with docs (see §A) |
| MCU | ✅ ~92% | VDDA ferrite + caps DONE 2026-07-28. Still missing bulk cap, footprint fixes (see §B) |
| Modem | ✅ ~90% | C20 footprint assigned (2026-07-28). USB not routed, socket part doc discrepancy (see §C) |
| Codec | ✅ Restored from git HEAD 2026-07-28 | Was accidentally wiped in working tree by `add_headphone_jack.py` script. Restored via `git checkout HEAD -- pcb/phone/codec.kicad_sch`. ERC now clean (0 violations on codec sheet). HP_DET still dangling (headphone jack not yet added). (see §D) |
| Keypad | ✅ Complete | Footprint overrides blanked; no key labels (see §E) |
| Display (main) | ⚠️ ~80% | Missing backlight FET (see §F) |
| Display daughter | ⚠️ ~70% | Missing backlight FET, J_HINGE2 footprint empty (see §G) |
| SIM/SD | ✅ Complete | **Initially flagged as broken by subagent — RE-VERIFIED via ERC: no errors, no shorts.** Subagent's coordinate-based analysis was wrong. Sheet is fine. |

**ERC result (2026-07-28, after VDDA ferrite + caps)**: 0 errors, 15 warnings (lib_symbol_mismatch ×9 including 3 new for VDDA parts, endpoint_off_grid ×4, isolated_pin_label ×1 for HP_DET, unconnected_wire_endpoint ×1). All 8 sub-sheets individually clean.

---

## Action Items

### §A — Power Sheet: Reference Designator Mismatches

**Status**: DONE 2026-07-28 (docs updated to match schematic — no schematic changes needed)

**DONE 2026-07-28**: Docs updated to match schematic refdes (not the other way around). The schematic refdes are canonical. 12 refdes were updated across 11 doc files:

| Component | Doc (old) | Schematic (canonical) |
|---|---|---|
| ALC5651 codec | U3 | U5 |
| TPS63021 buck-boost | U4 | U8 |
| TPS7A0218 LDO | U5 | U9 |
| MCP73831 charger | U6 | U11 |
| MAX17048 fuel gauge | U7 | U10 |
| TXB0108 level shifter | U8 | U3 |
| SN74AXC4T774 level shifter | U9 | U12 |
| USBLC6-2 ESD | U10 | D1 |
| ESDA6V1 ESD (SIM) | U11 | U6 |
| ESDA6V1 ESD (SD) | U11 | U7 |
| USB-C connector | J1 | USBC1 |
| Battery connector | J_BATT | CN1 |
| Slide switch | SW1 | SW21 |

Note: ESDA6V1 was a single U11 in docs but is two separate chips in the schematic (U6 for SIM, U7 for SD). U1 (MCU) and U2 (modem/MPCIe socket) were already consistent.

- [x] Get user approval for refdes direction (docs match schematic)
- [x] Update all 11 doc files via automated script (update_refdes.py)
- [x] Fix historical project-log.md entries that described the old schematic→doc rename
- [x] Handle ESDA6V1 (U11→U6/U7) manually — one doc refdes maps to two schematic refdes
- [ ] Run ERC to verify no breakage (N/A — no schematic changes, docs only)

### §B — MCU Sheet: Missing Components & Footprint Fixes

- [x] **Add VDDA ferrite bead + 1µF + 10nF caps** — **DONE 2026-07-28.** Added BLM18KG601SN1D ferrite bead (L1) between +3.3V and VDDA/VREF+, with 1µF (C18, GRM188R61C105KA93D) and 10nF (C19, CC0603KRX7R9BB103) decoupling caps to GND. Added PWR_FLAG on VDDA net for ERC. Also added CC0603KRX7R9BB103 to passives.kicad_sym library. ERC: 0 errors, 15 warnings (3 new lib_symbol_mismatch for new parts, rest pre-existing).
- [ ] **Add 4.7µF bulk cap** on +3.3V near MCU (docs say "100nF per pair + 4.7µF bulk")
- [ ] **Fix C4/C13 part-number mismatch** — lib_id is 4.7µF (GRM188R61C475KE11D) but value overridden to "2.2µF". Either use correct 2.2µF part or update value to match.
- [ ] **Fix R1/R2/R3 footprints** — have `C0603` instead of `R0603`
- [ ] **Assign USBC1 (SWD header) footprint** — Conn_01x04 with empty footprint
- [ ] **Add NRST to SWD header** (optional) — expand to 5-pin for debug reset
- [ ] **Add UART debug header** (optional) — for Zephyr console
- [ ] **Add test points** (optional) — SWDIO, SWCLK, NRST, USB_DP/DN, VBUS
- [ ] **Add hardware reset button** (optional) — tactile switch on NRST to GND
- [ ] **Update `docs/mcu-pin-assignment.md`** — add HP_DET on PA2; correct VDD/VSS pin numbers

### §C — Modem Sheet: Missing Footprint & USB Routing

- [x] **Assign C20 footprint** (470µF tantalum) — **DONE 2026-07-28.** Temp library `temp_470uf` already had both symbol (`6TPF470MAH`) and footprint (`CAP-SMD_L7.3-W4.3`, Case E 7.3×4.3mm). The schematic instance had an empty Footprint property override blanking the library-level value. Set instance Footprint to `temp_470uf:CAP-SMD_L7.3-W4.3`. ERC verified: 0 errors, 11 warnings (all pre-existing), Modem sheet 0 violations.
- [ ] **Route modem USB or document deferral** — pins 36/38 (USB_DN/DP) marked NC. AGENTS.md says "Rev1 routes modem USB to a connector footprint." Either route + ESD, or document deferral in project-log.
- [ ] **Resolve socket part discrepancy** — AGENTS.md says Techship S2-109KS-Z30G9; schematic uses SOFNG PCIE-52P40H (C444926). Reconcile docs.
- [ ] **Add PWR_FLAG symbols** on +3.3V and +1V8 (if needed for ERC)
- [ ] **Add OE RC ramp cap** (optional) — on TXB0108 OE pin for power sequencing
- [ ] **Add test points** (optional)

### §D — Codec Sheet: RESTORED FROM GIT (DONE)

**The codec sheet was complete at git HEAD but accidentally wiped in the working tree by the `add_headphone_jack.py` script (untracked, deleted 4856 lines, leaving only lib_symbols).**

**RESTORED 2026-07-28** via `git checkout HEAD -- pcb/phone/codec.kicad_sch`. ERC verified: 0 violations on codec sheet, I2S2/PCM isolated-pin warnings resolved.

HEAD version contains: U5 (ALC5651), U12 (SN74AXC4T774 level shifter), C23-C26/C41-C45 (caps), R10/R11 (resistors), J_MIC1 (mic connector), J_SPK1 (speaker connector), CN (connector), 37 power symbols, wires, and global labels.

- [x] **Restore codec sheet from HEAD** — DONE 2026-07-28
- [x] **Verify restored content** — ERC clean (0 violations on codec sheet)
- [ ] **Re-review restored codec sheet** for completeness against `docs/block-diagram.md` §Codec
- [ ] **Open questions to verify after restore**:
  - Does ALC5651 symbol have a RESETB pin? (subagent flagged it missing — verify against `docs/reference/alc5651.pdf`)
  - DCVDD (pin 40) pin type — `power_in` but docs say internal LDO (needs datasheet check)
  - MCLK level-shifting — 5th channel beyond U12's 4 bits (design decision needed)
  - Loudspeaker amp — ALC5651 has no integrated speaker driver; is an external amp in the design?
  - Headphone jack — the `add_headphone_jack.py` script was attempting to add one; HP_DET still dangling. Decide whether to re-attempt carefully.
- [ ] **Clean up**: delete or fix `pcb/phone/scripts/add_headphone_jack.py`
- [ ] **Update `docs/task-tracker.md`** — codec "Done" entry is now correct again

### §E — Keypad Sheet: Footprint Fixes & Labels

- [ ] **Fix 9 resistor footprint overrides** — R8-R18 have instance Footprint = `""` (blanked), should inherit `easyeda2kicad:R0603`
- [ ] **Add key-function text labels** — SW1-SW20 need silkscreen labels (1, 2, ..., CALL, END, UP, DOWN, OK, SPARE)
- [ ] **Add scan-algorithm note** — document the mixed pull-up/pull-down topology (active-low column drive, read rows)
- [ ] **Update `docs/block-diagram.md` §Keypad** — remove "to be specified", add SKQGABE010 part + topology + matrix map
- [ ] **Add project-log entry** for SKQGABE010 selection and pull topology

### §F — Display (Main Board): Backlight FET

- [ ] **Add N-channel logic-level MOSFET** for backlight PWM switching (CRITICAL — without it, MCU GPIO would need to sink ~64-80mA, exceeding 20mA max)
  - Recommended: AO3400A (LCSC C20917), SI2302 (C66355), or BSS138 (C85568)
  - Drain → LEDK, Source → GND, Gate → MCU PWM GPIO (BL_PWM)
- [ ] **Add gate resistor** (100Ω-1kΩ) on FET gate
- [ ] **Add gate pull-down** (10kΩ-100kΩ) to ensure backlight OFF during MCU reset
- [ ] **Resolve backlight architecture** — docs say FET + resistors on main board with LEDA/LEDK through hinge; schematic uses BL_PWM through hinge with R19 on daughterboard. Decide which architecture and update docs.
- [ ] **Add ESD protection on EARPIECE+/-** (optional — user's ear is ESD source)
- [ ] **Reconcile net names** — DISP_MOSI/SCK vs docs' DISP_SDA/SCL; EARPIECE+/- vs docs' SPK+/SPK-

### §G — Display Daughterboard: Footprint & Backlight

- [ ] **Fix J_HINGE2 footprint** — empty footprint property, should be `easyeda2kicad:FPC-SMD_14P-P0.50_HDGC_0.5K-HX-14PWB`
- [ ] **Add backlight FET** (if architecture decision puts it on daughterboard — see §F)
- [ ] **Add second decoupling cap** for outer display (C27 only covers main display)
- [ ] **Address outer display backlight** — ER-TFT1.14-2 has its own LED backlight; no resistor/FET for it
- [ ] **Verify earpiece coupling caps** — check ALC5651 datasheet if AC-coupling needed on EARPIECE+/-
- [ ] **Verify connector shell pins tied to GND** — 12P/14P/8P shell tabs

### §H — SIM/SD Sheet: NO ACTION NEEDED

**Initially flagged as broken by subagent (labels shifted by one pin pitch). Re-verified via KiCad MCP ERC: 0 errors, no shorts.** The subagent's coordinate-based net connectivity inference was incorrect — it miscalculated the socket symbol's geometric transform. The sheet is electrically correct.

- [x] ~~Re-align SIM socket labels~~ — NOT NEEDED (ERC clean)
- [x] ~~Re-align SD socket labels~~ — NOT NEEDED (ERC clean)
- [ ] (Optional) Add test points on USIM_VDD, USIM_DATA, SD_CMD, SD_CK
- [ ] (Optional) Document SD card-detect choice (pins tied to GND = polling-only)

### §I — Structural / Cross-Sheet Issues

- [ ] **Page number conflict** — Codec and Keypad both assigned page 4 in root sheet
- [ ] **Delete orphan `main.kicad_sch`** — not referenced by project, empty skeleton
- [ ] **Reconcile flat-vs-hierarchical structure** — docs say "flat sheet + global labels"; actual implementation uses hierarchical sheets (with no sheet pins, global labels only). Functionally equivalent but contradicts documented decision. Either update docs or restructure.
- [ ] **Add title blocks** to all sheets (no title/date/rev metadata currently)

### §J — Documentation Sync

- [ ] **`docs/task-tracker.md`**: Update §3.2-3.8 checkboxes to reflect actual completion; fix cap refdes (C40/C41/C42 → C18-C22); codec entry correct for HEAD but note working-tree issue
- [ ] **`docs/block-diagram.md`**: Update sections marked "to be specified" that are actually drawn (MCU, modem, keypad, display, SIM/SD); reconcile backlight architecture (LEDA/LEDK vs BL_PWM); reconcile net names (DISP_SDA/SCL vs DISP_MOSI/SCK, SPK+/SPK- vs EARPIECE+/-)
- [ ] **`docs/project-log.md`**: Add entries for SKQGABE010 keypad switch selection, SOFNG socket selection, backlight architecture change, codec sheet restore
- [ ] **`AGENTS.md`**: Reconcile refdes (USBC1, CN1, U8-U10, D1) and socket part (Techship vs SOFNG) with schematic

---

## Priority Order

1. **§D: Restore codec sheet from git HEAD** ✅ DONE 2026-07-28
2. **§F: Add backlight FET** (critical — without it, MCU GPIO will be damaged)
3. **§B: Fix MCU footprints** (C4/C13, R1-R3, USBC1) + add VDDA ferrite + bulk cap
4. **§C: Assign C20 footprint** (blocks PCB layout)
5. **§G: Fix J_HINGE2 footprint** (blocks PCB layout)
6. **§E: Fix keypad resistor footprints** (blocks PCB layout)
7. **§A: Reconcile power refdes** (needs user approval — locked section)
8. **§I: Structural fixes** (page numbers, orphan file)
9. **§J: Documentation sync** (after all schematic fixes are done)

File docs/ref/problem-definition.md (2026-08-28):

---
status: reference
updated: 2026-08-27
---
# Problem Definition

## The Problem

Design and build a custom cell phone from scratch that can make and receive real voice calls on a live cellular network in the United States. The device must eventually become a usable daily-driver, not just a lab prototype.

**Form factor: candybar / single-board (LOCKED 2026-08-16).** One PCB with all components — display mounts directly via ZIF connector, no hinge flex, no daughterboard. Flip/clamshell deferred to a potential v2. See `docs/ref/project-log.md` 2026-08-16 Form Factor Pivot.

## Modular Ecosystem Vision (Future — Does Not Affect MVP)

The phone is the first and primary project. However, the long-term vision is a **personal ecosystem of targeted devices** that can connect to the phone (or each other) for connectivity and shared data. The phone acts as the hub — providing LTE, contacts, music storage — while satellite modules handle specific tasks with their own UIs.

**First envisioned module: Car System**
- Display navigation (Google Maps alternatives — Organic Maps, OsmAnd, Mapbox)
- Play music (local files, phone storage, Spotify via librespot)
- Connect to phone via **USB** for tethered LTE + data + charging (primary), or Bluetooth/WiFi (future wireless modules)
- This is essentially a custom head unit / infotainment system

**Design principle**: The phone's hardware and firmware decisions must not prevent ecosystem integration. Specifically, the phone must expose connectivity interfaces (USB at minimum) that allow a future module to access LTE tethering, file storage, and potentially audio. This does not change the MVP scope — it only constrains hardware choices to leave the door open.

**Tethering architecture (updated 2026-08-27)**: LTE tethering to the car module uses the **SIM7600's own USB 2.0 HS port (480 Mbps)** directly — the modem presents itself as a USB network adapter (RNDIS/ECM via `AT+CUSBPIDSWITCH`), bypassing the MCU entirely. The MCU's USB (OTG_FS, 12 Mbps) handles firmware updates, file/MSC transfer, and debug. An **internal USB 2.0 HS hub (USB2512)** on rev1 presents both the modem (LTE) and the MCU (files) to the car module over a **single USB-C cable** — ecosystem is a hard rev1 requirement, no future respin needed. The earlier "MCU bridges LTE to USB CDC ECM, needs USB HS via ULPI" plan is superseded — no USB3300 ULPI transceiver needed. See `docs/ref/project-log.md` 2026-06-28 USB HS/ULPI Revisit and 2026-08-27 USB Hub on Rev1.

## Why This Is Hard

A cell phone is a convergence of five engineering disciplines, each non-trivial on its own:

1. **Cellular Communication** — The device must register on a real LTE network, authenticate via SIM, and establish VoLTE calls. This requires a cellular module, correct AT command sequencing, audio path configuration, and antenna integration. Get any of this wrong and there's no call.

2. **Hardware / PCB Design** — MCU, cellular module, power management, audio circuit, display, keypad, SIM, and antenna all on a custom PCB. RF trace impedance control, power rail integrity for 2A+ module peaks, and component placement all matter.

3. **Embedded Firmware** — An RTOS must concurrently manage: UART communication with the cellular module (parsing async AT responses), UI rendering on a display, keypad input handling, call state machine, and power management policies. All within tight memory and power constraints.

4. **Power Management** — Cellular modules draw 2A+ peaks during transmission. The battery, regulators, and charging circuit must handle this while fitting in a small enclosure. Standby time needs to be at least 24 hours.

5. **Mechanical Integration** (Phase 7) — Enclosure, keypad feel, display mounting, antenna placement. Form factor is locked (candybar / single-board); mechanical design is a separate phase that depends on the electronics being proven first.

## Architecture (Candybar / Single-Board — Locked 2026-08-16)

```
┌─────────────────────────────────┐
│        Single Board              │
│  - MCU (RTOS)                    │
│  - Cellular Module (LTE)         │
│  - SIM Card Slot                 │
│  - Keypad                        │
│  - Mic + Battery + Charging      │
│  - Power Regulation              │
│  - Antenna                       │
│  - USB (data + power) ←──┐       │ ← Ecosystem interconnect
│  - (future: BT/WiFi)     │       │
│  - Main display (ST7789V 2.0")   │ ← ZIF connector, mounts on board
│  - Earpiece speaker              │
│  - Loudspeaker                   │
│  - 3.5mm headphone jack (rev1)   │ ← Wired audio out (2026-08-16)
│  - Camera module (rev1, OV5640)  │ ← DCMI, OV5640 5MP AF (selected 2026-08-17)
│  - Notification LED (rev1)       │ ← Missed-call/SMS alert (2026-08-16)
│  - Vibration motor driver (rev1) │ ← Silent alert, off-board motor (2026-08-16)
│  - Backlight FET + resistors     │
│  - microSD slot                  │
│  - GNSS U.FL footprint           │
└──────────────────────────────────┘

    ┌──────────────────────┐
    │  Future Module (Car)  │
    │  - SBC (Linux)         │
    │  - Display (5-7" TFT)  │
    │  - Audio out            │
    │  - USB host to phone    │
    │  - Uses phone LTE       │
    └────────────────────────┘
Ecosystem modules are future scope.
```

## MVP Definition

**Minimum Viable Phone**: A device that can make and receive voice calls on a US LTE network.

| Feature | MVP | Daily Driver |
|---|-----|---|
| Make calls | ✅ | ✅ |
| Receive calls | ✅ | ✅ |
| Contacts | ❌ | ✅ |
| SMS | ❌ | ✅ |
| Menu system | ❌ | ✅ |
| Battery indicator | ❌ | ✅ |
| Signal indicator | ❌ | ✅ |
| Bluetooth | ❌ | Maybe |
| USB data (ecosystem) | ❌ | ✅ |
| Enclosure | Test jig | ✅ |

## Key Constraints Summary

| Constraint | Value |
|---|---|
| Region | United States |
| Network | LTE (VoLTE) |
| Carrier | T-Mobile/Mint recommended (prepaid) |
| Firmware | Zephyr RTOS |
| PCB EDA | KiCad |
| Budget | Keep low; flexible |
| Prototype BOM | < $150/unit |
| Form factor | Candybar / single-board (LOCKED 2026-08-16) — one PCB, display via ZIF; flip deferred to v2 |
| Assembly | Hand-solderable for prototypes |
| Enclosure | 3D print (FDM/SLA) or CNC |
| Ecosystem interconnect | USB (data + power); BT/WiFi deferred |

## Key Risks

1. **VoLTE configuration** — Getting VoLTE working via AT commands may require carrier-specific settings. Need to validate early with a breakout board before committing to PCB design.
2. **Antenna/RF** — LTE antenna design on a custom PCB may have poor performance. May need PCB respin.
3. **Power budget** — Meeting 24h standby with a small battery while powering an LTE module is tight.
4. **Carrier device whitelisting** — Some US carriers block unknown IMEIs. T-Mobile prepaid is the most lenient, but this needs validation.
5. **Mechanical/form factor** — Candybar / single-board locked 2026-08-16 (one PCB, display via ZIF). Enclosure fit and keypad feel are Phase 7 concerns. The single-board approach eliminates hinge mechanism risk (deferred to v2 with the flip form factor).
6. **Ecosystem compatibility** (rev1 hard requirement) — Hardware choices (MCU USB capability, modem USB routing, USB hub, single USB-C connector) must enable module connectivity on rev1. **Resolved 2026-06-28 + 2026-08-27**: tethering uses the SIM7600's own USB 2.0 HS port directly (no MCU USB HS / ULPI needed); an internal USB2512 hub on rev1 presents both modem (LTE) and MCU (files) over one USB-C. No second physical port. Low risk.
7. ~~**MAX9880A codec availability/compatibility**~~ **→ ALC5651 codec availability/compatibility** (pre-PCB risk — **FULLY RESOLVED 2026-07-19**): ~~The selected dual-port codec (MAX9880A) has been verified...~~ **SUPERSEDED 2026-07-19**: MAX9880A replaced by **Realtek ALC5651-CG** (LCSC C963633, QFN-40 5×5mm, JLC Extended — no consignment). All three pre-PCB items verified for ALC5651: (1) PCM short-frame sync is confirmed compatible — ALC5651 §7.5.1 PCM Mode A (short sync, Figures 10-11) in slave mode matches SIM7600 §3.6 (master, short sync, 16-bit, 2048/4096kHz BCLK); (2) stock is available at LCSC (407 units, JLC Extended — no consignment needed); (3) SIM7600 PCM pin voltage is 1.8V — confirmed 2026-06-30 from HW Design Manual V1.03 (Table 32 + §3.6.2). PCM lines connect directly to the ALC5651 (also 1.8V). Datasheet (Rev 0.9, 134pp) is complete — full pinout, registers, application circuit, timing, package. The fallback (MCU bridge with NAU8822) remains documented. The Waveshare HAT prototyping (NAU8810) validates the SIM7600 PCM voice output independent of this risk. See project-log.md 2026-07-19 Codec Swap MAX9880A→ALC5651.

## Success Criteria

- **MVP**: ~~Successfully place and receive a voice call from the custom-built device to another phone, with intelligible audio, on a US LTE network.~~ **ACHIEVED 2026-07-13** — MCU firmware places outgoing VoLTE call (`ATD6078821755;` → `VOICE CALL: BEGIN` → `VOICE CALL: END`) and receives incoming calls (detects `RING` URC → auto-answers with `ATA` → `VOICE CALL: BEGIN`). Audio works both directions through HAT's NAU8810 codec. Running on Nucleo H753ZI + Waveshare SIM7600NA-H HAT (not yet custom PCB). See project-log.md 2026-07-13.
- **Daily driver**: Use the device as primary phone for one week, including contacts, SMS, and acceptable battery life.

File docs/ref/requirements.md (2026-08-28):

---
status: reference
updated: 2026-08-27
---
# Requirements

## Functional Requirements

### FR-1: Cellular Communication
- **FR-1.1**: Device shall place outgoing voice calls to any phone number.
- **FR-1.2**: Device shall receive incoming voice calls and alert the user (ring).
- **FR-1.3**: Device shall support SMS send/receive (post-MVP, required for daily-driver).
- **FR-1.4**: Device shall connect to a real cellular network via a standard SIM card.
- **FR-1.5**: Device shall operate on networks currently active in the user's region (see constraints — 2G sunset issue).

### FR-2: User Interface
- **FR-2.1**: Device shall have a numeric keypad (0-9, *, #) plus call/end buttons.
  - **Prototype status (2026-07-18)**: Implemented on the Nucleo+HAT prototype using a 4×4 matrix keypad (Adafruit PID 3844) via Zephyr's `gpio-kbd-matrix` input driver. Keys: 0-9/\*/# = digits, A = Call, B = End/Cancel/Reject, C = Backspace, D = Menu (future). Final PCB will use SMD tactile switches in a 5×4 matrix (same driver, different devicetree pins).
- **FR-2.2**: Device shall have a display capable of showing: call status, dialed digits, contacts list, signal strength, battery level.
  - **Prototype status (2026-07-18)**: Call status + dialed digits implemented (LVGL labels on ST7789V). Signal strength and battery level not yet implemented (signal indicator is next; battery indicator is PCB-phase — needs MAX17048 fuel gauge in the battery power path).
- **FR-2.3**: Device shall support navigation buttons (up/down/select or D-pad) for menu interaction.
- **FR-2.4**: Device shall provide audible feedback (ringtones, key tones, call audio).

### FR-3: Contacts & Storage
- **FR-3.1**: Device shall store contacts locally (name + phone number). (Post-MVP)
- **FR-3.2**: Device shall persist contacts across power cycles. (Post-MVP)
- **FR-3.3**: Device shall allow adding, deleting, and editing contacts. (Post-MVP)

### FR-4: Power Management
- **FR-4.1**: Device shall be battery-powered and rechargeable via USB.
- **FR-4.2**: Device shall monitor and display battery level.
- **FR-4.3**: Device shall enter low-power mode when idle (display off, modem standby).
- **FR-4.4**: Device shall support a standby time of at least 24 hours (target).
- **FR-4.5**: Device shall power on via a maintained power switch that physically connects the battery to the system. Flipping the switch on brings up the +BATT net → TPS63021 EN rises → +3.3V rail comes up → MCU boots. See `docs/ref/project-log.md` 2026-08-17 Power Switch Simplification.
- **FR-4.6**: Device shall support soft off — MCU enters STOP mode after an inactivity timer expires. This is firmware-driven. All firmware behavior details (modem sleep state, wake sources, timer duration, graceful shutdown sequence, network reachability during sleep) are deferred until after PCB is ordered. See `docs/ref/project-log.md` 2026-08-17.
- **FR-4.7**: Device shall support hard power off via the maintained power switch — physically disconnects the battery from the system, resulting in 0 power draw. No latch circuit, no MCU involvement. Charging while off is not supported (accepted tradeoff). See `docs/ref/project-log.md` 2026-08-17.

### FR-5: Form Factor (Candybar / Single-Board — LOCKED 2026-08-16)
- **FR-5.1**: Device form factor is candybar / single-board — one PCB with all components. Display (ST7789V 2.0") mounts directly via ZIF connector (J7, 12-pin 0.5mm). No hinge flex, no daughterboard, no outer display. Flip/clamshell deferred to v2. See `docs/ref/project-log.md` 2026-08-16 Form Factor Pivot.
- **FR-5.2**: Mechanical design (enclosure, keypad feel) is deferred to Phase 7 — depends on electronics being proven first. Single-shell enclosure (no hinge mechanism).
- **FR-5.3**: User has access to FDM, SLA, and CNC for enclosure fabrication.

### FR-6: Camera (rev1 expansion — 2026-08-16)
- **FR-6.1**: Device shall include a camera module connected via the MCU DCMI interface (8-bit parallel). Camera module selected: OV5640 (5MP, auto-focus, 8-bit DVP via 20-pin FPC). See `docs/ref/project-log.md` 2026-08-17.
- **FR-6.2**: Device shall support photo capture to SD card storage. (Post-MVP firmware; hardware present on rev1.)
- **FR-6.3**: Device display (ST7789V, color) shall be capable of showing a live camera preview. (Post-MVP firmware.)
- **FR-6.4**: Camera module selection shall be finalized before schematic entry for the camera section. See `docs/ref/project-log.md` 2026-08-16.

### FR-7: Audio Output (rev1 expansion — 2026-08-16)
- **FR-7.1**: Device shall include a 3.5mm TRS headphone jack for wired audio output from the ALC5651 codec.
- **FR-7.2**: Device shall mute the earpiece and loudspeaker when headphones are inserted (jack-detect GPIO).
- **FR-7.3**: Device shall support MP3/music playback via SD card storage + codec I2S-2 path. (Firmware-only — hardware already on rev1: SD card + codec I2S-2 + level shifter. See `docs/ref/feature-wishlist.md`.)

### FR-8: Notifications (rev1 expansion — 2026-08-16)
- **FR-8.1**: Device shall include an LED notification light for missed-call/SMS alerts (single GPIO + LED).
- **FR-8.2**: Device shall include a vibration motor for silent call/SMS alerts (GPIO + N-FET driver + off-board motor via connector).

### FR-9: Ecosystem Connectivity (Rev1 Hard Requirement — updated 2026-08-27)
- **FR-9.1**: Device MCU shall have USB capability (device mode) for ecosystem connectivity. This is a hardware selection constraint, satisfied by STM32H743 OTG_FS.
- **FR-9.2**: Device PCB shall include a single USB-C data connector (not charge-only) as the ecosystem interconnect port. USB-C 16-pin (USB 2.0), LOCKED 2026-07-19.
- **FR-9.3**: Device shall expose LTE tethering to external USB hosts via the SIM7600's own USB 2.0 HS port (RNDIS/ECM via `AT+CUSBPIDSWITCH`), bypassing the MCU — the modem is the USB network adapter, not the MCU. The MCU's USB (OTG_FS) is not in the tethering path. See project-log.md 2026-06-28 USB HS/ULPI Revisit.
- **FR-9.4**: Device shall present both the modem (LTE tethering) and the MCU (file access / firmware / debug) to an external USB host over the **single USB-C port** via an **internal USB 2.0 HS hub** (USB2512-class) on rev1. No second physical USB port. See project-log.md 2026-08-27 USB Hub on Rev1.
- **FR-9.5**: File access (contacts, music storage) over USB for external modules is enabled by the hub (MCU enumerates as MSC device on hub downstream 2).
- **FR-9.6**: Bluetooth/WiFi for wireless ecosystem modules is deferred — not a hardware selection constraint at this time.

## Non-Functional Requirements

### NFR-1: Performance
- Call setup time < 10 seconds from pressing "call" to hearing ringback.
- UI response time < 200ms for keypad input.
- Boot time (MCU firmware ready + UI displayed): < 15 seconds. Note: full LTE network registration is a separate, longer sequence (~15–30s depending on carrier and signal) and is not included in this target. The phone shall show a "searching for network" indicator during registration.

### NFR-2: Reliability
- Device shall not crash during a phone call.
- Device shall recover gracefully from network disconnection.
- Device shall handle power-on/power-off cycles without data loss.

### NFR-3: Manufacturability
- PCB design shall be producible by standard PCB fab houses (e.g., JLCPCB, PCBWay).
- Components shall be sourced from available distributors (DigiKey, Mouser, LCSC).
- Assembly shall be feasible with hand soldering for prototypes, **except the cellular module** — all LTE/VoLTE modules are LGA and require reflow or JLCPCB assembly. Realistic approach: JLCPCB assembles the modem section (~$57–72), hand-solder the rest. No LTE module exists in a hand-friendly package; this is an industry reality. (Updated 2026-06-28 per modem revisit.) **MPCIe option (primary 2026-07-22)**: the SIM7600NA-H-PCIE Mini PCIe socketed card plugs into an SMD socket that reflows with the rest of the board — no LGA reflow, no JLC PCBA required for the modem. The MPCIe card is the primary form factor; bare LGA is the fallback. See `docs/ref/constraints.md` MPCIe section and `docs/ref/project-log.md` 2026-07-22 Schematic Approach entry.

### NFR-4: Maintainability
- Firmware shall be modular and well-structured.
- Hardware design files shall be version-controlled and documented.
- Schematics and PCB layouts shall be in KiCad (open-source EDA).

### NFR-5: Cost
- Prototype BOM cost target: < $150 per unit (excluding PCB fab costs).
- Total project budget: keep relatively low; avoid gold-plating.

## Resolved Decisions

- **Region**: United States
- **Network**: LTE with VoLTE (2G/3G are shut down in the US)
- **Carrier**: No preference — will use cheapest/easiest prepaid SIM. T-Mobile/Mint recommended (most lenient with non-certified devices, good LTE band coverage).
- **MVP scope**: Voice calls only (make/receive). Contacts, SMS, menus are post-MVP.
- **Daily-driver scope**: Calls + contacts + SMS + basic menu system (feature phone experience).
- **Display**: ST7789V SPI color TFT, 2.0" 240×320, RGB565. See research-notes.md Display Options section and project-log.md 2026-06-28 Display Selection.
- **Keypad**: SMD tactile switches on custom PCB traces (LOCKED 2026-06-28). See Resolved Questions below and project-log.md 2026-06-28 Keypad Selection.
- **Enclosure/Form factor**: Candybar / single-board — one PCB, display via ZIF connector. **LOCKED 2026-08-16** (supersedes 2026-07-19 flip/clamshell, which is deferred to v2). Enclosure design deferred to Phase 7 (mechanical design). Single-shell enclosure, no hinge. User has FDM, SLA, and CNC access.
- **Firmware**: Zephyr RTOS — balances concurrency needs with maintainability for a daily-driver device. See project-log.md 2026-06-28 RTOS Selection.

## Open Questions (Requirements)

- [ ] **MCU-to-modem UART stress test** (post-MVP, pre-PCB): Run a long-duration stress test of the LPUART1 ↔ SIM7600 UART link — send 100+ AT commands back-to-back with no delay, verify zero data loss (every response contains expected result code). Test with varied response sizes (short `AT`→`OK`, long `AT+CGMM`, multi-line `AT+COPS?`). Also test GPS NMEA streaming (continuous data into the 1KB ring buffer — verify no overflow). This validates the interrupt-driven UART + ring buffer architecture is reliable enough for the final PCB. Deferred until after the MVP call works — the current 4-command test is sufficient for MVP development. See project-log.md 2026-07-13 entries.

## Resolved Questions (moved from Open)

Full rationale for each decision is in `docs/ref/project-log.md` — entries below are one-line summaries with links.

- [x] **Bluetooth support**: Deferred to post-MVP (external module needed — no MCU has classic BT A2DP). See project-log.md 2026-06-28.
- [x] **MCU selection**: STM32H743ZI. See project-log.md 2026-06-28 MCU Selection.
- [x] **FreeRTOS vs Zephyr**: Zephyr. See project-log.md 2026-06-28 RTOS Selection.
- [x] **USB mode**: USB FS only (12 Mbps) for MCU; ULPI/USB3300 dropped — SIM7600's own USB HS does tethering. See project-log.md 2026-06-28 USB HS/ULPI Revisit.
- [x] **USB device vs OTG**: Device-only sufficient (car module is host). See project-log.md 2026-06-28 USB HS/ULPI Revisit.
- [x] **Modem selection**: SIM7600 locked after two rounds. LARA-R6401 disqualified (no 911). EC25-AF is PCB fallback. See project-log.md 2026-06-28 Modem Revisit (Second Round).
- [x] **Codec selection**: ALC5651-CG (dual I2S/PCM, MCU not in voice path). ~~MAX9880A~~ superseded. See project-log.md 2026-07-19 Codec Swap.
- [x] **Display selection**: ST7789V SPI TFT 2.0" (color-capable, no 5+ features blocked). See project-log.md 2026-06-28 Display Selection.
- [x] **Keypad selection**: SMD tactile switches, 5×4 matrix. See project-log.md 2026-06-28 Keypad Selection.
- [x] **USB-C connector type**: 16-pin USB-C (USB 2.0). See project-log.md 2026-07-19.
- [x] **Modem USB HS port on rev1**: ~~Routed to unpopulated connector footprint.~~ **SUPERSEDED 2026-08-27**: Routed to USB hub downstream port (USB2512). No second physical connector. See project-log.md 2026-08-27 USB Hub on Rev1.
- [x] **GNSS antenna on rev1**: U.FL footprint included. See project-log.md 2026-07-19.
- [x] **Loudspeaker on rev1**: Both earpiece and loudspeaker included. See project-log.md 2026-07-19.
- [x] **SIM + microSD connector strategy**: Resolved during sourcing — separate sockets. See `docs/ref/bom.md` and project-log.md 2026-07-19.

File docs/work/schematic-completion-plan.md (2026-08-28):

---
status: active
updated: 2026-08-27
---
# Schematic Completion Plan

> **Created**: 2026-07-28
> **Purpose**: Track remaining work to complete the PCB schematic (Phase 3) based on a full per-sheet review.
> **Source**: Per-sheet subagent reviews (9 sheets) + KiCad MCP ERC run + git history investigation.

---

## Current State (verified 2026-07-28)

| Sheet | Status | Notes |
|---|---|---|
| Power | ✅ Complete | Functionally done; refdes mismatches with docs (see §A) |
| MCU | ✅ ~92% | VDDA ferrite + caps DONE 2026-07-28. Still missing bulk cap, footprint fixes (see §B) |
| Modem | ✅ ~90% | C20 footprint assigned (2026-07-28). USB now routes to hub (2026-08-27 — see §C). Socket part doc discrepancy (see §C) |
| Codec | ✅ Restored from git HEAD 2026-07-28 | Was accidentally wiped in working tree by `add_headphone_jack.py` script. Restored via `git checkout HEAD -- pcb/phone/codec.kicad_sch`. ERC now clean (0 violations on codec sheet). HP_DET still dangling (headphone jack not yet added). (see §D) |
| Keypad | 🔶 **SOFT-LOCKED** | **Reviewed 2026-08-27 (netlist-based). All 20 switches (SW1-SW20) + 9 pull resistors (R8/R9/R12-R18) correctly wired in 5×4 matrix. All 9 MCU pins match pin-assignment doc. May change during layout/enclosure modeling — switch placement/part selection could shift. See §E.** |
| Display (main) | 🔒 **LOCKED** | **Reviewed 2026-08-27 (netlist-based). J_DISP1 pinout corrected to match HS20HS072RX datasheet (was almost entirely wrong — 1/12 pins correct). Backlight FET circuit added (Q1 AO3400A + R20 100Ω gate + R5 10kΩ pulldown + R19 4.7Ω current-limit). R19 MPN fixed (was 470Ω part with 4.7Ω value — swapped to RC0603JR-074R7L). All 14 pins verified correct, ERC 0 violations. ⚠️ Re-review FPC connector orientation (pin 1 side, contact-side vs solder-side) during PCB layout — schematic doesn't encode mechanical orientation. See §F.** |
| ~~Display daughter~~ | **DROPPED 2026-08-16** | Sheet removed from scope — candybar form factor eliminates the daughterboard. J8/J9 hinge connectors and J10 outer display removed. See §G. |
| SIM/SD | 🔒 **LOCKED** | **Reviewed 2026-08-27 (netlist-based). R20 (10kΩ USIM_DATA pull-up) removed — violated SIM7600 datasheet ("Do not pull it up or down externally", page 14 Table 3). Re-reviewed by 2 parallel kicad-inspector subagents: SIM side PASS, SD side PASS, zero collateral impact. All pins correct on J_SIM1, U6, C28, J_SD1, U7, R29-R33, C29. MCU SDMMC1 pins match pin-assignment doc.** |

**ERC result (2026-07-28, after VDDA ferrite + caps)**: 0 errors, 15 warnings (lib_symbol_mismatch ×9 including 3 new for VDDA parts, endpoint_off_grid ×4, isolated_pin_label ×1 for HP_DET, unconnected_wire_endpoint ×1). All 8 sub-sheets individually clean.

---

## Action Items

### §A — Power Sheet: Reference Designator Mismatches

**Status**: DONE 2026-07-28 (docs updated to match schematic — no schematic changes needed)

**DONE 2026-07-28**: Docs updated to match schematic refdes (not the other way around). The schematic refdes are canonical. 12 refdes were updated across 11 doc files:

| Component | Doc (old) | Schematic (canonical) |
|---|---|---|
| ALC5651 codec | U3 | U5 |
| TPS63021 buck-boost | U4 | U8 |
| TPS7A0218 LDO | U5 | U9 |
| MCP73831 charger | U6 | U11 |
| MAX17048 fuel gauge | U7 | U10 |
| TXB0108 level shifter | U8 | U3 |
| SN74AXC4T774 level shifter | U9 | U12 |
| USBLC6-2 ESD | U10 | D1 |
| ESDA6V1 ESD (SIM) | U11 | U6 |
| ESDA6V1 ESD (SD) | U11 | U7 |
| USB-C connector | J1 | USBC1 |
| Battery connector | J_BATT | CN1 |
| Slide switch | SW1 | SW21 | *(2026-08-27: switch on EN pin — signal-level OS102011MA1QN1, 100mA SPDT. Was battery-path 2026-08-17, reversed 2026-08-27. See project-log 2026-08-27.)* |

Note: ESDA6V1 was a single U11 in docs but is two separate chips in the schematic (U6 for SIM, U7 for SD). U1 (MCU) and U2 (modem/MPCIe socket) were already consistent.

- [x] Get user approval for refdes direction (docs match schematic)
- [x] Update all 11 doc files via automated script (update_refdes.py)
- [x] Fix historical project-log.md entries that described the old schematic→doc rename
- [x] Handle ESDA6V1 (U11→U6/U7) manually — one doc refdes maps to two schematic refdes
- [ ] Run ERC to verify no breakage (N/A — no schematic changes, docs only)

### §B — MCU Sheet: Missing Components & Footprint Fixes

**Required for Phase 3 gate:**

- [x] **Add VDDA ferrite bead + 1µF + 10nF caps** — **DONE 2026-07-28.** Added BLM18KG601SN1D ferrite bead (L1) between +3.3V and VDDA/VREF+, with 1µF (C18, GRM188R61C105KA93D) and 10nF (C19, CC0603KRX7R9BB103) decoupling caps to GND. Added PWR_FLAG on VDDA net for ERC. Also added CC0603KRX7R9BB103 to passives.kicad_sym library. ERC: 0 errors, 15 warnings (3 new lib_symbol_mismatch for new parts, rest pre-existing).
- [ ] **Add 4.7µF bulk cap** on +3.3V near MCU (docs say "100nF per pair + 4.7µF bulk")
- [ ] **Fix C4/C13 part-number mismatch** — lib_id is 4.7µF (GRM188R61C475KE11D) but value overridden to "2.2µF". Either use correct 2.2µF part or update value to match.
- [ ] **Fix R1/R2/R3 footprints** — have `C0603` instead of `R0603`
- [ ] **Assign USBC1 (SWD header) footprint** — Conn_01x04 with empty footprint
- [ ] **Add USB2512 hub** (new component — 2026-08-27 USB Hub on Rev1 decision): 2-port USB 2.0 HS hub (QFN-24). Upstream → USBLC6-2 ESD → USB-C. Downstream 1 → modem USB (pins 36/38). Downstream 2 → MCU OTG_FS. Needs 24MHz crystal, decoupling caps, +3.3V power, reset (RC or 1 MCU GPIO), VBUS_DET (tap existing VBUS net via divider). Likely new schematic sheet or lives on modem sheet. See project-log.md 2026-08-27.
- [ ] **Re-route MCU USB OTG_FS to hub downstream 2** — was direct to USB-C via USBLC6-2; now routes to USB2512 hub downstream 2. The USBLC6-2 ESD stays on the USB-C side (upstream of hub). No ESD needed between hub and MCU (short on-board traces).
- [ ] **Update `docs/work/mcu-pin-assignment.md`** — add HP_DET on PA2; correct VDD/VSS pin numbers

**Optional / defer:**

- [ ] **Add NRST to SWD header** — expand to 5-pin for debug reset
- [ ] **Add UART debug header** — for Zephyr console
- [ ] **Add test points** — SWDIO, SWCLK, NRST, USB_DP/DN, VBUS
- [ ] **Add hardware reset button** — tactile switch on NRST to GND

### §C — Modem Sheet: Missing Footprint & USB Routing

**Required for Phase 3 gate:**

- [x] **Assign C20 footprint** (470µF tantalum) — **DONE 2026-07-28.** Temp library `temp_470uf` already had both symbol (`6TPF470MAH`) and footprint (`CAP-SMD_L7.3-W4.3`, Case E 7.3×4.3mm). The schematic instance had an empty Footprint property override blanking the library-level value. Set instance Footprint to `temp_470uf:CAP-SMD_L7.3-W4.3`. ERC verified: 0 errors, 11 warnings (all pre-existing), Modem sheet 0 violations.
- [ ] **Route modem USB to hub downstream 1** — pins 36/38 (USB_DN/DP) were marked NC. Per 2026-08-27 USB Hub on Rev1 decision, these now route to the USB2512 hub downstream port 1 (ecosystem tethering, RNDIS/ECM). No ESD needed on-board (short traces, ESD is upstream at USB-C). See project-log.md 2026-08-27.
- [ ] **Resolve socket part discrepancy** — AGENTS.md says Techship S2-109KS-Z30G9; schematic uses SOFNG PCIE-52P40H (C444926). Reconcile docs.
- [ ] **Add PWR_FLAG symbols** on +3.3V and +1V8 (if needed for ERC)

**Optional / defer:**

- [ ] **Add OE RC ramp cap** — on TXB0108 OE pin for power sequencing
- [ ] **Add test points**

### §D — Codec Sheet: RESTORED FROM GIT (DONE)

**The codec sheet was complete at git HEAD but accidentally wiped in the working tree by the `add_headphone_jack.py` script (untracked, deleted 4856 lines, leaving only lib_symbols).**

**RESTORED 2026-07-28** via `git checkout HEAD -- pcb/phone/codec.kicad_sch`. ERC verified: 0 violations on codec sheet, I2S2/PCM isolated-pin warnings resolved.

HEAD version contains: U5 (ALC5651), U12 (SN74AXC4T774 level shifter), C23-C26/C41-C45 (caps), R10/R11 (resistors), J_MIC1 (mic connector), J_SPK1 (speaker connector), CN (connector), 37 power symbols, wires, and global labels.

- [x] **Restore codec sheet from HEAD** — DONE 2026-07-28
- [x] **Verify restored content** — ERC clean (0 violations on codec sheet)
- [ ] **Re-review restored codec sheet** for completeness against `docs/work/block-diagram.md` §Codec
- [ ] **Open questions to verify after restore**:
  - Does ALC5651 symbol have a RESETB pin? (subagent flagged it missing — verify against `docs/datasheets/alc5651.pdf`)
  - DCVDD (pin 40) pin type — `power_in` but docs say internal LDO (needs datasheet check)
  - MCLK level-shifting — 5th channel beyond U12's 4 bits (design decision needed)
  - Loudspeaker amp — ALC5651 has no integrated speaker driver; is an external amp in the design?
  - Headphone jack — the `add_headphone_jack.py` script was attempting to add one; HP_DET still dangling. Decide whether to re-attempt carefully.
- [ ] **Clean up**: delete or fix `pcb/phone/scripts/add_headphone_jack.py`
- [ ] **Update `docs/work/task-tracker.md`** — codec "Done" entry is now correct again

### §E — Keypad Sheet: 🔶 SOFT-LOCKED (Reviewed 2026-08-27)

**Full netlist-based review completed 2026-08-27.** All 20 switches (SW1-SW20, SKQGABE010) verified in 5×4 matrix. All 9 pull resistors (R8/R9/R12-R14 row pull-ups to +3.3V, R15-R18 column pull-downs to GND) verified. All 9 MCU pins (PE7-PE15) match `docs/work/mcu-pin-assignment.md`. No wiring errors.

**Soft-locked**: Electrically correct and reviewed, but switch placement/part selection may change during PCB layout and enclosure modeling. The matrix topology (5×4, 9 GPIO) is unlikely to change, but physical switch refdes or part numbers could shift.

- [x] **Full netlist review** — DONE 2026-08-27 (PASS, no errors)
- [ ] **Fix 9 resistor footprint overrides** — R8-R18 have instance Footprint = `""` (blanked), should inherit `easyeda2kicad:R0603`
- [ ] **Add key-function text labels** — SW1-SW20 need silkscreen labels (1, 2, ..., CALL, END, UP, DOWN, OK, SPARE)
- [ ] **Add scan-algorithm note** — document the mixed pull-up/pull-down topology (rows pulled to +3.3V, columns pulled to GND, active-low column drive, read rows)
- [ ] **Update `docs/work/block-diagram.md` §Keypad** — remove "to be specified", add keypad topology + matrix design intent (pin-level detail lives in the schematic)
- [ ] **Add project-log entry** for SKQGABE010 selection and pull topology

### §F — Display (Single Board): 🔒 LOCKED (Reviewed 2026-08-27)

> **2026-08-16 update**: The backlight FET architecture conflict is **resolved** by the candybar pivot. The FET lives on the single board, directly switching LEDK — no hinge flex, no daughterboard, no "which board does the FET live on?" question. The old conflict (docs said FET on main board with LEDA/LEDK through hinge; schematic used BL_PWM through hinge with R19 on daughterboard) no longer applies.
>
> **2026-08-27 update**: Full review completed. J_DISP1 pinout was almost entirely wrong (1/12 pins correct) — corrected to match HS20HS072RX datasheet page 11. Backlight FET circuit (Q1 + R20 + R5) added. R19 MPN fixed (470Ω → 4.7Ω). Sheet is LOCKED. Any change requires explicit approval + project-log entry per `pcb/AGENTS.md` rule 9.

**Completed:**

- [x] **Add N-channel logic-level MOSFET** — Q1 (AO3400A, LCSC C20917), drain → LEDK (pin 11), source → GND, gate → BL_PWM via R20
- [x] **Add gate resistor** — R20 (100Ω, 0603WAF1000T5E, LCSC C22775) in series between BL_PWM and FET gate
- [x] **Add gate pull-down** — R5 (10kΩ, RC0603JR-0710KL) from gate to GND — ensures backlight OFF during MCU reset
- [x] **Remove hinge flex connectors (J8/J9)** — done during 2026-08-27 display restructure
- [x] **Remove outer display connector (J10)** + OUTER_CS/OUTER_DC — done during 2026-08-27 display restructure
- [x] **Wire display directly** — J_DISP1 (12-pin ZIF) connects directly to MCU SPI + GPIO + power + backlight
- [x] **Reconcile net names** — schematic uses DISP_MOSI/DISP_SCK (SPI naming), datasheet uses SDA/SCL (Sitronix SPI terminology for same signals). Both correct — see ST7789V §8.4. EARPIECE+/- net names retained.
- [x] **Fix J_DISP1 pinout** — all 14 pins now match HS20HS072RX datasheet page 11
- [x] **Fix R19 MPN** — was RC0603JR-07470RL (470Ω) with 4R7 value; swapped to RC0603JR-074R7L (correct 4.7Ω part, LCSC C137621)

**⚠️ Re-review during PCB layout (Phase 4):**

- [ ] **FPC connector orientation** — The schematic doesn't encode mechanical orientation. Verify during layout that J_DISP1 is placed with pin 1 on the correct side, contacts facing the correct direction (toward the display panel, not away), and the FPC insertion direction matches the physical display module. A 180° rotation or wrong contact-side would mirror the pinout and break everything. Check against the HS20HS072RX datasheet §5 (Module Outline Dimension) for the FPC exit direction and contact side.

**Optional / defer:**

- [ ] **Add ESD protection on EARPIECE+/-** — user's ear is ESD source
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

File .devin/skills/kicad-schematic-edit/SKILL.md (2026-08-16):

---
name: kicad-schematic-edit
description: "DORMANT (2026-08-16 role change): Governed write workflow for .kicad_sch files. Invoke only on explicit user request — user now drives all KiCad edits, agent reviews."
status: dormant
triggers:
  - user
subagent: true
agent: kicad-author
---

> **DORMANT as of 2026-08-16** — Per the Workflow Role Change decision (project-log.md 2026-08-16), the user handles all KiCad work and the agent acts as reviewer/guide. This skill remains available but should only be invoked when the user **explicitly** asks the agent to make a KiCad edit. Do not auto-invoke. The active review path is `/kicad-review` (read-only, via kicad-inspector subagent).
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

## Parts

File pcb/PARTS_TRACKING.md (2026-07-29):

# PCB Parts Library Tracking

> **Purpose**: Track the sourcing status of every part for the phone PCB. Update this as you download footprints/symbols/3D models from JLC, SnapEDA, Ultra Librarian, or create them from datasheets.
>
> **Library location**: `pcb/phone/lib/` — project-local KiCad library
> - `lib/passives.kicad_sym` — resistors, capacitors, inductors, ferrite beads, LEDs (16 symbols)
> - `lib/ics.kicad_sym` — ICs: MCU, modem, codec, power, level shifters, ESD, mic (12 symbols)
> - `lib/connectors.kicad_sym` — USB-C, SIM, microSD, U.FL, FPC, battery connectors (8 symbols)
> - `lib/electromech.kicad_sym` — tactile switches, crystals (2 symbols)
> - `lib/easyeda2kicad.pretty/` — footprint libraries (KiCad `.pretty` format)
> - `lib/easyeda2kicad.3dshapes/` — 3D STEP/WRL models
>
> **Library rebuild 2026-07-22**: All 38 symbols have correct pin electrical types
> (were all `unspecified`/`input` from easyeda2kicad auto-generation), `ki_description`
> properties (<20 char), and consistent property ordering. The original single
> `easyeda2kicad.kicad_sym` was split into 4 categorized libraries. Schematic
> references updated from `easyeda2kicad:SYM` to `passives:/ics:/connectors:SYM`.
> Old `easyeda2kicad.kicad_sym` and `missing_parts.kicad_sym` removed
> (superseded by the 4 split libraries).
>
> **How to use**: When you download a part from JLC/SnapEDA/etc., drop the files into the appropriate `lib/` subfolder and check the boxes below. Record the JLC part # (C-number) so the BOM can be filled in later.

## Status legend
- [ ] **Not sourced** — part not yet downloaded
- [x] **Sourced** — files downloaded and placed in `lib/`
- [~] **N/A** — part uses KiCad built-in library (no download needed)
- [!] **Blocker** — needs decision or datasheet work before sourcing

---

## A. ICs (downloaded from JLC via easyeda2kicad — 2026-07-19)

| Ref | Part | Package | JLC Part # | Source | Symbol | Footprint | 3D | Notes |
|-----|---|---|---|---|---|---|-----|---|
| U1 | STM32H743ZIT6 | LQFP-144 | C114408 | JLC (in stock) | [x] | [x] | [x] | ST OEM. 131 in stock. |
| U2 | SIM7600NA-H | LCC+LGA 119-pin | C5380303 | JLC (pre-order) | [x] | [x] | [!] | SIMCom OEM. 3D model not available (pre-order part). 135 pads in footprint — verify against HW Design Manual V1.08. |
| U5 | Realtek ALC5651-CG (dual I2S/PCM audio hub codec) | QFN-40-EP 5×5mm | C963633 | JLC (Extended, 407 in stock at LCSC) | [x] | [x] | [x] | **LOCKED 2026-07-19 (replaces MAX9880A).** Dual I2S/PCM interface audio codec — I2S-1 = PCM voice from SIM7600 (slave mode, PCM Mode A short-sync), I2S-2 = I2S music from MCU. ASRC per interface (asynchronous independent clocks). 100dBA DAC SNR, 94dBA ADC SNR. Stereo differential mic inputs + adjustable MICBIAS. Stereo cap-free headphone amp + line out + PDM output for ext Class-D. 1.8V analog (AVDD/DACREF/CPVDD), 1.2V digital core (internal LDO), 3.3V MICVDD. I2C control. QFN-40 5×5mm (smaller than MAX9880A's TQFN-48 6×6mm). **JLC Extended — no consignment needed** (eliminates the last Mouser consignment part). 407 in stock at LCSC. **PCM compatibility verified**: SIM7600 HW Design Manual V1.08 §3.6 = master mode, short sync, 16-bit linear, 2048/4096kHz BCLK; ALC5651 §7.5.1 supports PCM Mode A (short sync) in slave mode — exact match. KiCad model downloaded via easyeda2kicad: symbol `ALC5651-CG`, footprint `QFN-40_L5.0-W5.0-P0.40-BL-EP3.7`, 3D `QFN-40_L5.0-W5.0-H0.9-P0.4-BL-EP`. Datasheet: `docs/datasheets/alc5651.pdf` (Rev 0.9, 134pp — full pinout, registers, application circuit, timing, package dimensions). See project-log.md 2026-07-19 Codec Swap MAX9880A→ALC5651. |
| U8 | TPS63021DSJR | VSON-14 (DSJ, 3×4mm) + EP | C202140 | JLC (in stock) | [x] | [x] | [x] | **RESOLVED & LOCKED 2026-07-19.** Fixed 3.3V, 4A switches / ~3A output, Vin 1.8–5.5V. Downloaded via easyeda2kicad: symbol `TPS63021DSJR`, footprint `VSON-14_L4.0-W3.0-P0.50-BL-EP_TI_DSJ`, 3D `VSON-14_L4.0-W3.0-H1.0-P0.50`. **"TPS630201" was a phantom part number** (TI never made it) — carried in docs since 2026-06-28, corrected 2026-07-19. TPS63021 is the real fixed-3.3V part; TPS63020 (C15483) is the adjustable sibling (rejected — would need feedback divider). JLC-stocked → no consignment needed. See project-log.md 2026-07-19 U8 Buck-Boost Correction. |
| U9 | TPS7A0218PDBVR | SOT-23-5 | C3748843 | JLC | [x] | [x] | [x] | TI OEM. 1284 in stock. |
| U11 | MCP73831-2ACI/MC | TDFN-8 2×3mm | C150772 | JLC | [x] | [x] | [x] | Microchip OEM. 318 in stock. |
| U10 | MAX17048G+T10 | TDFN-8 2×2mm | C2682616 | JLC | [x] | [x] | [x] | ADI/Maxim OEM. 10228 in stock. |
| U3 | TXB0108PWR | TSSOP-20 | C53406 | JLC | [x] | [x] | [x] | TI OEM. **PWR (TSSOP-20) used instead of DGSR (VSSOP-20)** — DGSR (C44861261) failed EasyEDA API fetch. PWR matches block diagram spec, larger/easier to hand-solder. 45,922 in stock. |
| U12 | TXB0104D | SOIC-14 | C1549752 | JLC | [x] | [x] | [x] | TI OEM. 37 in stock. |
| D1 | USBLC6-2SC6 | SOT-23-6 | C7519 | JLC | [x] | [x] | [x] | ST OEM (swapped from TECH PUBLIC clone C2827654). |
| U6/U7 | ESDA6V1-5SC6 | SOT-23-6 | C6650 | JLC | [x] | [x] | [x] | ST OEM (swapped from TECH PUBLIC clone C2827672). Two chips: U6 for SIM ESD, U7 for SD ESD. 3D model shared with C7519 (same SOT-23-6 package). |

## B. Connectors (download from JLC or SnapEDA)

| Ref | Part | Package | JLC Part # | Source | Symbol | Footprint | 3D | Notes |
|-----|---|---|---|---|---|---|-----|---|
| USBC1 | Korean Hroparts TYPE-C-31-M-12 (USB-C 16-pin, USB 2.0, 5A, 10K cycles) | SMD USB-C 7.35mm | C165948 | JLC (94,755 in stock) | [x] | [x] | [x] | **LOCKED 2026-07-19.** 16-pin USB 2.0 (matches block diagram spec — not 24-pin USB 3.x). 5A/20V (headroom for future power-path chargers; MCP73831 only needs 500mA). 10,000 mating cycles. Korean Hroparts Elec (HRO) — reputable Korean USB-C connector brand, higher tier than generic Shenzhen brands. $0.186 qty 5+. Low C-number (C165948) = long-standing JLC catalog part, well-supported for assembly. KiCad model downloaded via easyeda2kicad: symbol `TYPE-C-31-M-12`, footprint `USB-C_SMD-TYPE-C-31-M-12_1`, 3D `USB-C_SMD-TYPE-C-31-M-12_1` (.wrl + .step). See project-log.md 2026-07-19 USBC1 USB-C Selection. |
| J2 | Modem USB — test points only (DNP rev1) | 4 test pads (VBUS, D+, D-, GND) | N/A | KiCad built-in | [~] | [~] | [~] | **LOCKED 2026-07-19.** Test points only — no connector. Per SIM7600 HW Design Manual V1.08 §3.4: "The USB interface is a frequently used debug port; it is suggested to reserve test points." Future ecosystem respin routes modem USB through internal USB 2.0 hub (USB2514) to USBC1 — J2 will never be user-facing. Use KiCad built-in `TestPoint:TestPoint_Pad_D1.0mm` or similar. See project-log.md 2026-07-19 J2/J3/J4 Decisions. |
| J3 | SHOU HAN NANO SIM XG6P H1.35 (nano-SIM hinged 6-pin) | SMD hinged, 1.45mm height | C7529386 | JLC (Extended, 38,255 at LCSC / 22,052 at JLC) | [x] | [x] | [x] | **LOCKED 2026-07-19.** Nano-SIM (4FF), hinged lid, 6-pin (no card detect — SIM7600 manual §3.5.1 says optional, "keep USIM_DET open" if unused). 1.45mm height, -20°C to +85°C. $0.146 qty 5+. SHOU HAN (Shenzhen connector brand — lower tier than Amphenol/Molex but established, 38K+ stock). Amphenol G85D1160022HHR (C5429441) rejected — out of stock + expensive. Molex doesn't make nano-SIM hinged (78800 hinged = micro-SIM only; 104224 nano-SIM = push-pull only). Hinged chosen over push-push per user preference (top-loading, no lateral clearance needed). KiCad model downloaded via easyeda2kicad: symbol `NANO SIM XG6P H1.35`, footprint `SIM-SMD_NANO-SIM-XG6P-H1.35` (10 pads = 6 signal + 4 shell/mounting), 3D `.wrl` + `.step`. See project-log.md 2026-07-19 J3/J4 Sourcing. |
| J4 | Molex 472192001 (microSD hinged 8-pin) | SMD hinged, 1.9mm height | C164170 | JLC (16,177 at LCSC / 9,107 at JLC) | [x] | [x] | [x] | **LOCKED 2026-07-19.** MicroSD (TF), hinged lid, 8-pin, 1.10mm pitch. 1.9mm height, -20°C to +85°C (LCSC) / -40°C to +85°C (Molex datasheet). No card detect. 5,000 mating cycles. Gold-over-nickel contacts, stainless steel shell, shielded. Molex OEM (top-tier US connector brand). $0.765 qty 1, $0.502 qty 100+. Hinged chosen over push-push per user preference. KiCad model downloaded via easyeda2kicad: symbol `472192001`, footprint `TF-SMD_472192001` (12 pads = 8 signal + 4 shell/mounting), 3D `.wrl` + `.step`. See project-log.md 2026-07-19 J3/J4 Sourcing. |
| J5 | Hirose U.FL-R-SMT-1(10) (cellular antenna) | U.FL SMD | C88373 | JLC (53,805 in stock) | [x] | [x] | [x] | **LOCKED 2026-07-19.** Original U.FL connector from Hirose (invented the U.FL standard). 6 GHz, 50Ω, 53,805 in stock, $0.227 qty 5+. KiCad model downloaded via easyeda2kicad: symbol `U.FL-R-SMT-1`, footprint `ANT-SMD_UFL-R-SMT-1-10`, 3D `ANT-SMD_UFL-R-SMT-1-10` (.wrl + .step). See project-log.md 2026-07-19 B4/B6/B10 Sourcing. |
| J6 | Hirose U.FL-R-SMT-1(10) (GNSS antenna) | U.FL SMD | C88373 | (same as J5) | [x] | [x] | [x] | Same part as J5. |
| J7 | HDGC 0.5K-HX-12PWB (12-pin 0.5mm FPC, hinged lid, double-sided, 1mm) | SMD FFC/FPC | C2919494 | JLC | [x] | [x] | [x] | **LOCKED 2026-07-19.** For main display HS20HS072RX (C5329582), 12-pin 0.5mm ZIF. Pinout: 1=GND, 2=CS, 3=RS(DC), 4=SCL, 5=SDA, 6=RST, 7=NC, 8=I/O-VCC, 9=VCC, 10=LEDA, 11=LEDK, 12=GND. Double-sided contacts eliminate top/bottom orientation risk (FPC folds under panel — contacts face down). 1mm height — thinnest available. Same series as J8/J9/J10. **KiCad model downloaded** via easyeda2kicad: symbol `0.5K-HX-12PWB`, footprint `FPC-SMD_12P-P0.50_HDGC_0.5K-HX-12PWB` (14 pads = 12 signal + 2 mounting, verified). |
| J8 | HDGC 0.5K-HX-14PWB (14-pin 0.5mm FPC, hinged lid, double-sided, 1mm) | SMD FFC/FPC | C2919495 | JLC | [x] | [x] | [!] | **LOCKED 2026-07-19.** Hinge flex between main board and display daughterboard. ~13 signals on 14-pin FFC (1 spare). Same series as J7/J9/J10. Need matching 14-pin 0.5mm FFC cable (deferred to Phase 7 — length depends on hinge geometry). **KiCad model downloaded** via easyeda2kicad: symbol `0.5K-HX-14PWB`, footprint `FPC-SMD_14P-P0.50_HDGC_0.5K-HX-14PWB` (16 pads = 14 signal + 2 mounting, verified). **No 3D model** from JLC — 3D view will be missing for J8 (acceptable). |
| J9 | HDGC 0.5K-HX-14PWB (14-pin 0.5mm FPC, hinged lid, double-sided, 1mm) | SMD FFC/FPC | C2919495 | JLC | [x] | [x] | [!] | Same part as J8. Daughterboard side of hinge flex. No 3D model (same as J8). |
| J10 | HDGC 0.5K-HX-8PWB (8-pin 0.5mm FPC, hinged lid, double-sided, 1mm) | SMD FFC/FPC | C2919492 | JLC | [x] | [x] | [x] | **LOCKED 2026-07-19.** For outer display ER-TFT1.14-2 (BuyDisplay, $3.27), 8-pin 0.5mm FPC. Pinout: 1=LEDA, 2=GND, 3=RESET, 4=RS(DC), 5=SDA, 6=SCL, 7=VDD, 8=CS. Double-sided contacts (datasheet says top contact, but double-sided works either way). Same series as J7/J8/J9. **Panel purchased separately from PCB — user plugs into ZIF post-assembly.** **KiCad model downloaded** via easyeda2kicad: symbol `0.5K-HX-8PWB`, footprint `FPC-SMD_8P-P0.50_HDGC_0.5K-HX-8PWB` (10 pads = 8 signal + 2 mounting, verified). |
| CN1 | JST S2B-PH-SM4-TB(LF)(SN) (battery, 2-pin PH, SMD right-angle) | SMD, P=2mm, 7.9×8.6×5.5mm | C295747 | JLC (Extended) | [x] | [x] | [x] | **LOCKED 2026-07-21.** Battery connector for single-cell LiPo. JST PH series, 2-pin, 2mm pitch, 2A rated (matches modem 2A TX bursts), SMD right-angle (chosen over through-hole C173752 — SMD goes through JLC pick-and-place, no wave soldering surcharge). Mates with standard JST-PH plugs pre-crimped on Adafruit/SparkFun/Amazon LiPo batteries. "Extended" = JLC sources on-demand. KiCad model downloaded via easyeda2kicad: symbol `S2B-PH-SM4-TB`, footprint `CONN-SMD_P2.00_S2B-PH-SM4-TB-LF-SN`, 3D `.wrl` + `.step`. **Battery itself is NOT JLC-sourced** (hazmat shipping) — buy separately from Adafruit/Amazon/AliExpress with JST-PH plug attached. See project-log.md 2026-07-21 Battery Connector. |

## C. Switches (keypad matrix — ~20 switches)

| Ref | Part | Package | JLC Part # | Source | Symbol | Footprint | 3D | Notes |
|-----|---|---|---|---|---|---|-----|---|
| SW1–SW20 | ALPS SKQGABE010 (5.2×5.2×1.5mm, 1.57N, 1M cycles) | 5.2×5.2×1.5mm SMD | C115351 | JLC (1,344 in stock; 41,590 at LCSC) | [x] | [x] | [x] | **LOCKED 2026-07-19.** Symbol+footprint+3D downloaded via easyeda2kicad. Force 160gf (in 160–180gf target), 1M cycle life (exceeds 300K min), 0.25mm travel (low end of numeric-keypad range — accepted for thinness), 1.5mm height (thinnest practical SMD tactile with push plate). Same 5.2×5.2mm footprint across SKQG stem-height variants (3.1/3.4/5.0mm) — can swap up without respin if feel is too snappy. ~$0.089 @ 50+ qty → ~$3.50 for 40 switches (2 boards × 20 + overage). See project-log.md 2026-07-19 Keypad Switch Selection. |

## D. Transducers

| Ref | Part | Package | JLC Part # | Source | Symbol | Footprint | 3D | Notes |
|-----|---|---|---|---|---|---|-----|---|
| LS1 | Earpiece speaker (10mm, 8Ω, DEFERRED) | 10mm round, wire leads | TBD | External (not JLC PCB-assembled) | [~] | [~] | [~] | **DEFERRED 2026-07-19.** Speakers are case-mounted mechanical parts (wire-soldered during final assembly, not PCB-assembled by JLC). No need to spec now — PCB will have wire solder pads (2× 1mm pads, ~5mm apart). Candidate: Taoglas SPKM.10.8.A (C6297624, 10mm, 8Ω, 500mW, 100Hz-11kHz, Irish brand) — 0 stock on JLC but available from other distributors. Revisit at Phase 7 (mechanical/enclosure). |
| LS2 | Loudspeaker (20mm+, 8Ω, DEFERRED) | 20mm+ round/square, wire leads | TBD | External (not JLC PCB-assembled) | [~] | [~] | [~] | **DEFERRED 2026-07-19.** Same as LS1 — case-mounted, not PCB-assembled. PCB will have wire solder pads. Candidates: CUI CMS0201KLX (C3312002, 20×20mm, 2W, 424Hz-20kHz, 9.5mm), PUI Audio AS02708CO-WR-R (C7217683, 27×20mm, 1W, 250Hz-20kHz, 6.3mm), PUI Audio AS02008MR-5-R (C3311274, 20mm, 500mW, 500Hz-4kHz, 3.8mm). Revisit at Phase 7. |
| MK1 | ZILLTEK ZTS6117 (MEMS analog microphone) | SMD-4P 2.75×1.85mm | C481300 | JLC (5,129 in stock) | [x] | [x] | [x] | **LOCKED 2026-07-19.** Analog output (pairs directly with ALC5651 differential mic inputs IN1P/IN2P/IN2N + adjustable MICBIAS 0.9×MICVDD ≈ 2.97V). -42dB sensitivity, 59dB SNR, omnidirectional, 1.5V-3.6V supply, 120µA current, 2.75×1.85×0.9mm. ZILLTEK (钰太) — Taiwanese MEMS sensor brand. $0.53. 5,129 in stock. Knowles SPU0410LR5H-QB (C2918083, gold standard, -38dB/63dB SNR) has 0 stock on JLC — ZILLTEK is best available. TDK InvenSense MMICT390200012 (C3171752) is EOL + PDM digital (more complex). KiCad model downloaded via easyeda2kicad: symbol `ZTS6117`, footprint `MIC-SMD_4P-L2.8-W1.9-P1.84-TL_ZTS6117`, 3D `MIC-SMD_4P-L2.8-W1.9-P1.84-TL_ZTS6117` (.wrl + .step). See project-log.md 2026-07-19 B4/B6/B10 Sourcing. |

## E. Crystal / Inductor / LEDs

| Ref | Part | Package | JLC Part # | Source | Symbol | Footprint | 3D | Notes |
|-----|---|---|---|---|---|---|-----|---|
| Y1 | ECS ECS-80-12-33Q-GN-TR (8MHz crystal HSE) | SMD 3225 4-pin (3.2×2.5mm) | C2595911 | JLC (150 in stock) | [x] | [x] | [x] | **LOCKED 2026-07-19.** 8MHz, 12pF CL, ±30ppm tolerance, ±30ppm stability, ESR 500Ω, -40 to +85°C. ECS Inc (US brand), AEC-Q200 automotive qualified. STM32H743 datasheet Table 34 confirms HSE characterized with 8MHz crystal at CL=10pF; Figure 20 shows "Typical application with an 8 MHz crystal." Load caps: with CL=12pF crystal and Cs≈3pF, CL1=CL2=18pF each. $1.39 qty 1, 150 in stock (enough for prototyping). LIMING 3225-8.00-12-10-10/A (C518155, ±10ppm, $0.32, 1,973 stock) is the production fallback — same SMD3225-4P footprint. KiCad model downloaded via easyeda2kicad: symbol `ECS-80-12-33Q-GN-TR`, footprint `CRYSTAL-SMD_4P-L3.2-W2.5-BL`, 3D `CRYSTAL-SMD_4P-L3.2-W2.5-BL` (.wrl + .step). See project-log.md 2026-07-19 B4/B6/B10 Sourcing. |
| L1 | Coilcraft XFL4020-152MEC (1.5µH, Isat 4.4A @20% drop, DCR 14.4mΩ, Irms 9.1A) | SMD 4×4×2.1mm | C3033018 | JLC (Extended, 757 in stock at LCSC) | [x] | [x] | [x] | **LOCKED 2026-07-19.** Datasheet-recommended part for TPS63021DSJR (TI SLVS916I Table 2 + Table 4 — XFL4020-152ME/ML family). 1.5µH ±20%, magnetic shielded. Isat 4.4A at 20% inductance drop (Coilcraft datasheet authoritative — LCSC's "4.6A" is at 30% drop; TI datasheet's "5.1A" uses a looser definition). DCR 14.4mΩ typ / 15.8mΩ max — lowest DCR available at this size → best efficiency on the 3.3V rail. Irms 9.1A (40°C rise) — way above any phone load. Isat 4.4A vs the datasheet's "20% above calculated peak" guidance (≥4.8A): adequate because (a) 4A is the TPS63021 switch current LIMIT (fault), not operating current; (b) actual phone peak currents are 2–3A (modem TX burst + display + audio + MCU); (c) calculated peak inductor current at 3A out buck mode ≈ 3.1A, at 3A out boost mode ≈ 3.7A — both well under 4.4A. Alternative rejected: Taiyo Yuden LSDND4040WKT1R5MM (C6653414, Isat 7A but DCR 35mΩ — 2.4× higher, noticeable efficiency hit on the most critical rail). The "ML" low-DCR variant from TI Table 4 is not on LCSC (broker-only). KiCad model downloaded via easyeda2kicad: symbol `XFL4020-152MEC`, footprint `IND-SMD_L4.0-W4.0-A`, 3D `IND-SMD_L4.0-W4.0-A` (.wrl + .step). See project-log.md 2026-07-19 L1 Inductor Selection. |
| D1–D3 | LEDs (status/notification) | 0603 | C99290 | JLC | [x] | [x] | [x] | LITEON LTST-C191TBKT blue LED 0603, 468nm. Downloaded. Pick color(s) — currently blue; may want different colors for status vs notification. |

## F. Passives (downloaded from JLC + KiCad built-in)

| Ref | Part | JLC Part # | Source | Notes |
|-----|---|---|---|---|
| 100nF decoupling caps | YAGEO CC0603KRX7R9BB104 | C14663 | JLC (downloaded) | 0603, X7R, 50V. 43M+ in stock. Use for per-IC decoupling. |
| 10uF bulk caps | muRata GRM21BR61H106KE43L | C440198 | JLC (downloaded) | 0805, X5R, 50V. 2.4M in stock. |
| 22uF bulk caps | muRata GRM21BR61A226ME51L | C77074 | JLC (downloaded 2026-07-21) | 0805, X5R, 10V, ±20%. Same GRM21BR family as 10uF bulk (C440198) — uniform 0805 bulk-cap footprint. Used for TPS63021 VOUT (3× 22µF on +3V3 to GND, per datasheet §8.2.2.4). 10V rating gives 3× margin on the 3.3V rail. KiCad symbol `GRM21BR61A226ME51L`, footprint `C0805` (shared with 10uF cap), 3D `C0805_L2.0-W1.3-H1.3`. |
| 4.7µF cap | muRata GRM188R61C475KE11D | C77045 | JLC (downloaded 2026-07-21) | 0603, X5R, 16V, ±10%. Used for MCP73831 VBUS bypass. KiCad symbol `GRM188R61C475KE11D`, footprint `C0603` (shared), 3D `C0603_L1.6-W0.8-H0.8`. |
| 1µF cap | muRata GRM188R61C105KA93D | C77404 | JLC (downloaded 2026-07-21) | 0603, X5R, 16V, ±10%. Used for TPS7A0218 input/output + MCU VDDA decoupling. KiCad symbol `GRM188R61C105KA93D`, footprint `C0603` (shared), 3D `C0603_L1.6-W0.8-H0.8`. |
| Bulk caps (VBAT) | 100–470µF ceramic + tantalum | TBD | JLC | Values TBD from schematic — VBAT rail stability |
| 1MΩ resistor | YAGEO RC0603JR-071ML | C107698 | JLC (downloaded 2026-07-21) | 0603, 1MΩ ±5%, 100mW, 75V, thick film. Used for TPS63021 EN pin pullup to VBAT (always-on). Matches our Yageo 0603 passive standard. KiCad symbol `RC0603JR-071ML`, footprint `R0603`. |
| 2kΩ resistor | YAGEO RC0603FR-072KL | C105576 | JLC (downloaded 2026-07-21) | 0603, 2kΩ ±1%, 100mW, thick film. Used for MCP73831 R_PROG (500mA charge current). 1% precision matters — sets charge current. KiCad symbol `RC0603FR-072KL`, footprint `R0603` (shared), 3D `R0603`. |
| 470Ω resistor | YAGEO RC0603JR-07470RL | C114433 | JLC (downloaded 2026-07-21) | 0603, 470Ω ±5%, 100mW, thick film. Used for LED current limiting. KiCad symbol `RC0603JR-07470RL`, footprint `R0603` (shared), 3D `R0603`. |
| 10kΩ resistor | YAGEO RC0603JR-0710KL | C99198 | JLC (downloaded 2026-07-21) | 0603, 10kΩ ±5%, 100mW, thick film. Used for STAT/PG/ALRT pullups. KiCad symbol `RC0603JR-0710KL`, footprint `R0603` (shared), 3D `R0603`. |
| 100kΩ resistor | YAGEO RC0603FR-07100KL | C14675 | JLC (downloaded 2026-07-21) | 0603, 100kΩ ±1%, 100mW, thick film. Used for VBUS voltage divider (high side). 1% precision matters for ADC reading. KiCad symbol `RC0603FR-07100KL`, footprint `R0603` (shared), 3D `R0603`. |
| 47kΩ resistor | YAGEO RC0603FR-0747KL | C105579 | JLC (downloaded 2026-07-21) | 0603, 47kΩ ±1%, 100mW, thick film. Used for VBUS voltage divider (low side). 1% precision matters for ADC reading. KiCad symbol `RC0603FR-0747KL`, footprint `R0603` (shared), 3D `R0603`. |
| 5.1kΩ resistor | YAGEO RC0603FR-075K1L | C105580 | JLC (downloaded 2026-07-21) | 0603, 5.1kΩ ±1%, 100mW, thick film. Used for USB-C CC pull-downs (Rd). 1% tolerance per USB-C spec for correct UFP identification. KiCad symbol `RC0603FR-075K1L`, footprint `R0603` (shared), 3D `R0603`. |
| 4.7kΩ resistor | YAGEO RC0603JR-074K7L | C105428 | JLC (downloaded 2026-07-21) | 0603, 4.7kΩ ±5%, 100mW, thick film. Used for I2C pullups. KiCad symbol `RC0603JR-074K7L`, footprint `R0603` (shared), 3D `R0603`. |
| Ferrite bead (VDDA) | muRata BLM18KG601SN1D | C85833 | JLC (downloaded 2026-07-21) | 0603, 600Ω ±25% @ 100MHz, 150mΩ DCR, 1.3A. Used for MCU VDDA analog rail isolation. muRata BLM18K high-current series. KiCad symbol `BLM18KG601SN1D`, footprint `L0603`, 3D `L0603_L1.6-W0.8-H0.5_BEAD`. |
| Other resistors | 0402/0603 | — | KiCad built-in `Device:R` | Pullups, dividers — values from schematic. Will download specific LCSC parts as values are finalized. |

---

## Decisions needed before all parts can be sourced

These block the parts marked [!] above:

1. **Modem USB connector type** (J2) — USB-C vs micro-USB for the unpopulated rev1 footprint
2. ~~**SIM/microSD: combo vs separate** (J3, J4) — check JLC stock for combo sockets~~ **RESOLVED 2026-07-19** — separate sockets, both sourced and KiCad models downloaded. See project-log.md 2026-07-19 J3/J4 Sourcing.
3. ~~**Specific keypad switch** (SW1–SW20)~~ **RESOLVED 2026-07-19** — ALPS SKQGABE010 (C115351). See project-log.md 2026-07-19 Keypad Switch Selection.
4. ~~**Specific ST7789V panel** (J7) — needed to know FPC pin count~~ **RESOLVED 2026-07-19** — HS HS20HS072RX (C5329582), 12-pin 0.5mm ZIF FPC. See project-log.md 2026-07-19 Display Panel Selection. J7 blocker cleared — now just need to source a 12-pin 0.5mm ZIF receptacle. New connectors J8-J10 added for flip form factor (hinge FFC + outer OLED).
5. **Loudspeaker part** (LS2) — pick a JLC-stocked 20mm+ mylar speaker
6. **Microphone part** (MK1) — pick a JLC-stocked MEMS mic
7. **Earpiece confirmation** (LS1) — is Taoglas SPKM.10.8.A the final choice, or pick a JLC-stocked alternative?
8. **Power inductor for TPS63021DSJR** (L1) — must meet datasheet specs *(part reference corrected from TPS630201 2026-07-19)*
9. **8MHz crystal** (Y1) — pick a specific JLC-stocked part

## Sourcing priority

1. **JLC parts library** (parts.jlcpcb.com) — for anything JLC will place. Get the C# for the BOM.
2. **Ultra Librarian** (manufacturer official) — for ST, TI, Microchip, ADI ICs not on JLC.
3. **SnapEDA** — fallback for anything not on Ultra Librarian.
4. **KiCad built-in** — passives, U.FL (if standard), LEDs, generic crystals.

## Workflow

1. Search JLC for each part below.
2. Download the KiCad footprint + symbol + 3D model (JLC offers these on each part page).
3. Drop files into `pcb/phone/lib/` (symbols into `.kicad_sym` libs, footprints into `easyeda2kicad.pretty/`, 3D into `easyeda2kicad.3dshapes/`).
4. Record the JLC C# in the table above.
5. Check the Symbol/Footprint/3D boxes.
6. Once all parts are sourced, import the libraries into KiCad (Preferences → Manage Libraries → add project-local `lib/` paths).

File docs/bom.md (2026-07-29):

# Bill of Materials (BOM)

> **Status**: Preliminary — reflects component selections locked as of 2026-06-28 (MCU, modem, codec, display, keypad). Items not yet selected (power ICs, transducers) are listed as candidates with price ranges. Prices are USD, captured 2026-06-28 from publicly listed distributor pages. Verify current pricing/stock before ordering. **Updated 2026-06-28 (documentation review)**: VBAT buck regulator removed (direct-from-LiPo); 3.3V buck-boost (TPS630201) and fuel gauge (MAX17048) added; ESD protection added; MCP73831 note corrected. **Updated 2026-06-28 (keypad selection)**: Keypad locked — SMD tactile switches on custom PCB traces; prototyping keypad module added to §1. **Updated 2026-06-28 (Nucleo substitution)**: NUCLEO-H743ZI/ZI2 obsolete — NUCLEO-H753ZI is the substitute (H753 = H743 + crypto, identical for this project). DigiKey links added for all prototyping parts. Order consolidation: DigiKey (electronics) + Waveshare (HAT + display) + Mint Mobile (SIM).

## How to Read This BOM

- **LOCKED**: Component decision is final (see `docs/project-log.md`). Do not substitute without a documented revisit.
- **CANDIDATE**: Component not yet locked. Listed option(s) are recommended based on current docs; a selection revisit is pending.
- **TBD**: No candidate selected yet — deferred to a later phase per the docs.
- Prices are unit price at qty 1 unless noted. Bulk pricing reduces cost significantly for most components.

---

## 1. Prototyping Platform (Phase 2 — HAT-Based Prototype)

These items are for Phase 2 validation (VoLTE on a real carrier) before any custom PCB work. See `docs/project-log.md` Phase Breakdown.

**Order consolidation (3 sources, all free/fast shipping):**
- **DigiKey** (one order): Nucleo H753ZI, Adafruit keypad, tactile buttons, breadboard, jumper wires
- **Amazon** (free shipping): SIM7600NA-H HAT + 2" LCD (Waveshare parts — Amazon is cheaper than Waveshare direct once shipping is factored in; Waveshare ships from China with paid shipping and 1-2 week delivery)
- **Mint Mobile**: SIM + plan

| # | Component | Part Number | Status | Qty | Unit Price | Ext Price | Source / Link |
|---|---|---|---|-----|---|---|---|
| 1 | LTE Cat-4 HAT (NA variant, B71, NAU8810 codec, GNSS) | Waveshare SIM7600NA-H 4G HAT (SKU 30717) | LOCKED | 1 | ~$77–89 | ~$77–89 | [Amazon — SIM7600NA-H HAT](https://www.amazon.com/SIM7600NA-H-4G-HAT-Communication-Positioning/dp/B0F24NBYKC) · [Waveshare direct](https://www.waveshare.com/sim7600na-h-4g-hat.htm) |
| 2 | Prepaid SIM (T-Mobile/Mint, most lenient with non-cert devices) | Mint Mobile Starter Kit / plan | CANDIDATE | 1 | ~$0–15 (starter) + $15–30/mo plan | ~$15–45 | [Mint Mobile](https://www.mintmobile.com) · [Amazon — Mint plans](https://www.amazon.com/Mint-Mobile-Wireless-Unlimited-3-Months/dp/B0741FV7ZV) |
| 3 | STM32H7 dev board (Nucleo-144, for MCU-side prototyping with HAT) | NUCLEO-H753ZI (substitute — see note) | CANDIDATE | 1 | $28.15 | $28.15 | [DigiKey — NUCLEO-H753ZI](https://www.digikey.com/en/products/detail/stmicroelectronics/NUCLEO-H753ZI/21348937) · [Mouser — NUCLEO-H753ZI](https://www.mouser.com/ProductDetail/STMicroelectronics/NUCLEO-H753ZI) |
| 4 | 2.0" SPI IPS TFT display (ST7789VW, for MCU prototyping) | Waveshare 2inch LCD Module (SKU 17344) | LOCKED | 1 | $14.39 | $14.39 | [Amazon — 2inch LCD Module](https://www.amazon.com/waveshare-2inch-LCD-Display-Module/dp/B081Q79X2F) · [Waveshare direct](https://www.waveshare.com/product/2inch-lcd-module.htm) |
| 5 | 4×4 matrix keypad module (membrane, for firmware prototyping) | Adafruit 4×4 Matrix Keypad (PID 3844) | CANDIDATE | 1 | $5.95 | $5.95 | [DigiKey — Adafruit 3844](https://www.digikey.com/en/products/detail/adafruit-industries-llc/3844/9561536) | 16-key membrane matrix. For Phase 2 firmware development (matrix scan + debounce). Electrical interface (rows/cols → MCU GPIO) identical to final PCB. |
| 6 | Tactile buttons, 6×6mm, for call/end/nav (breadboard) | Adafruit Tactile Button Switch 6mm, 20-pack (PID 367) | CANDIDATE | 1 | $2.50 | $2.50 | [DigiKey — Adafruit 367](https://www.digikey.com/en/products/detail/adafruit-industries-llc/367/10669771) | Loose buttons on breadboard for call/end/nav keys not on the 4×4 matrix. |
| 7 | Breadboard, 830 tie-point, solderless | Adafruit Full-size Breadboard (PID 239) | CANDIDATE | 1 | $2.95 | $2.95 | [DigiKey — Adafruit 239](https://www.digikey.com/en/products/detail/adafruit-industries-llc/239/7244929) | Standard full-size breadboard for prototyping. |
| 8 | Jumper wires, M/M, 40×3" (75mm) | Adafruit Premium M/M Jumper Wires (PID 759) | CANDIDATE | 1 | $1.95 | $1.95 | [DigiKey — Adafruit 759](https://www.digikey.com/en/products/detail/adafruit-industries-llc/759/5353615) | 40 male-to-male jumpers for breadboard connections. |
| | **Prototyping subtotal** | | | | | **~$148–180** | |

> **Nucleo board note (2026-06-28)**: Both NUCLEO-H743ZI2 and NUCLEO-H743ZI are **obsolete** on DigiKey and ST eStore. The **NUCLEO-H753ZI** is the recommended substitute — the STM32H753ZI is an STM32H743ZI with crypto peripherals (AES, HASH, TRNG) added; everything else (core, Flash, RAM, package, peripherals, pinout) is identical. The crypto peripherals are irrelevant to this project. The locked MCU decision (STM32H743ZIT6 for the final PCB) is unaffected — the Nucleo is only for prototyping. DigiKey has 387 in stock ($28.15); Mouser has 898 in stock ($27.00). DigiKey is recommended to consolidate with the Adafruit parts (Mouser does not carry the Adafruit keypad).

> **Bare chip stock (STM32H743ZIT6, for final PCB — not needed now)**: Confirmed in stock at ST eStore ($14.61), Mouser (360 units, $17.37), DigiKey (limited stock, $16.54). No supply concern for the PCB phase.

---

## 2. Core Components — LOCKED (Final PCB)

These are the locked component decisions per `docs/project-log.md`. Prices reflect the bare component for PCB assembly.

| # | Component | Part Number | Package | Status | Qty | Unit Price | Ext Price | Source / Link | Notes |
|---|---|---|---|---|-----|---|---|---|---|
| 4 | MCU — STM32H7 Cortex-M7 480MHz, 2MB Flash, 1MB RAM | STM32H743ZIT6 | LQFP-144 20×20mm | LOCKED | 1 | $14.61 (qty 1) / $9.13 (10ku) | $14.61 | [ST eStore](https://estore.st.com/en/stm32h743zit6-cpn.html) · [DigiKey](https://www.digikey.com/en/products/detail/stmicroelectronics/STM32H743ZIT6/6371188) | Hand-solderable LQFP. USB OTG_FS built-in (12 Mbps). USB HS via ULPI **dropped** 2026-06-28 — modem-direct USB tethering replaces it. LQFP-144 retained for GPIO margin (41 spare). |
| 5 | Cellular module — LTE Cat-4, VoLTE, B66/B71, NA variant | SIM7600NA-H | LCC+LGA 30×30mm, 119-pin | LOCKED | 1 | ~~$31.42~~ **$59.00 (JLC pre-order, corrected 2026-07-22)** | $59.00 | [JLC pre-order — SIM7600NA-H (C5380303)](https://jlcpcb.com/partdetail/SIMCom_WirelessSolutions-SIM7600NA-H/C5380303) | LGA — requires JLCPCB assembly or DIY reflow (hardest DIY part). **JLC price corrected 2026-07-22**: was $31.42 in docs (stale, from 2026-07-19) — current JLC price is **$59.00/ea**, 8-day lead time. **Broker quotes (2026-07-22, bare modules shipped to you)**: UniKey $35/ea (DC 26+, 5-8 working days, EXW Hong Kong), Worldway $41/ea (DC 23+, 3-4 days). **MPCIe form factor (primary 2026-07-22)**: SIM7600NA-H-PCIE (S2-109KS-Z30G9) from Techship ~$50/ea — Mini PCIe socketed card, eliminates LGA reflow. Same B71/B66/VoLTE/GNSS/PCM specs. **PCM CONFIRMED** from SIM7600 Series PCIE Hardware Design V1.03 §2.2 + §3.10.1: pins 45/47/49/51 (PCM_CLK/OUT/IN/SYNC), master/short-sync/16-bit/2048kHz/1.8V = exact match to ALC5651 PCM Mode A. All MPCIe socket options are **SMD** (0.8mm pitch, right-angle — not through-hole): Amphenol G633A0520022U (C357792, 1589 stock, ~5mm), SOFNG PCIE-52P40H (C444926, 3039 stock, 4mm), Hanbo PCI-E-H52-52P (C3039346), **JLC basic C9900027618** (5.2mm, no extended fee). Socket ~$1-5. SIM socket NOT onboard (§3.7 says "contact local sales" — Techship spec lists as optional `o`, stock card does NOT have it; both variants need PCB SIM socket). No PWRKEY pin on edge connector (TBD how module powers on). **Approach: MPCIe is the primary form factor for the schematic + PCB layout; LGA is the fallback (pivot only if MPCIe proves difficult).** See project-log.md 2026-07-22 Schematic Approach + MPCIe Primary. **Part name corrected 2026-07-19**: "SIM7600A-H" was a misnomer — SIMCom's actual product code is `SIM7600NA-H` (North America H-series). The old LCSC link (C2995537) pointed to the non-H `SIM7600A`, a different/older product (87-pin LCC, not 119-pin LCC+LGA). SIM7600G-H (C5355477, $46.95, 39 in stock) shares the identical 119-pin LCC+LGA package and is the **footprint fallback** if NA-H library data is incomplete. SA-H and E-H are 87-pin LCC (different package) and lack B71 — disqualified. Fallback modem: EC25-AF. See project-log.md 2026-07-19 SIM7600 Variant Selection. |
| 6 | Audio codec — dual I2S/PCM (PCM voice + I2S music) | Realtek ALC5651-CG | QFN-40 5×5mm | LOCKED | 1 | ~$1.00 (LCSC qty 1) | ~$1.00 | [LCSC — ALC5651-CG (C963633)](https://www.lcsc.com/product-detail/C963633.html) · [JLC — C963633](https://jlcpcb.com/partdetail/Realtek-ALC5651CG/C963633) | ~~MAX9880AETM+T~~ **SUPERSEDED 2026-07-19** (was Mouser consignment — replaced to eliminate last consignment part). ALC5651 is JLC Extended (no consignment). Dual I2S/PCM audio hub: I2S-1 = PCM voice from SIM7600 (slave, PCM Mode A short-sync), I2S-2 = I2S music from MCU. 100dBA DAC, 94dBA ADC, ASRC, 7-band EQ, DRC/AGC. 1.8V analog + 1.2V digital (internal LDO) + 3.3V MICVDD. QFN-40 5×5mm (smaller than MAX9880A TQFN-48 6×6mm). PCM compatibility verified (ALC5651 §7.5.1 PCM Mode A = SIM7600 §3.6 short sync). Datasheet: `docs/reference/alc5651.pdf`. KiCad model downloaded. See project-log.md 2026-07-19 Codec Swap. |
| | **Core subtotal** | | | | | **~$43–47** | | |

---

## 3. Supporting Components — Recommended/Candidate

These components are required for the phone but have not been formally locked in `docs/project-log.md` (except the display, which is locked — see §3a). Candidates are listed with prices; a selection revisit is pending for keypad and power ICs.

### 3a. Display (LOCKED — ST7789V SPI color TFT)

| # | Component | Part Number | Status | Qty | Unit Price | Ext Price | Source / Link | Notes |
|---|---|---|---|-----|---|---|---|---|
| 7 | 2.0" SPI IPS TFT color display, 240×320, ST7789VW | Waveshare 2inch LCD Module (SKU 17344) | LOCKED | 1 | $11.99 | $11.99 | [Waveshare — 2inch LCD Module](https://www.waveshare.com/product/2inch-lcd-module.htm) | IPS, 262K color, 4-wire SPI, 58×35mm module. ST7789VW driver. 150KB framebuffer fits internal 1MB SRAM. 6 GPIO pins. See project-log.md 2026-06-28 Display Selection. |
| 7b | 2.0" ST7789V raw panel (FPC, for PCB integration) | HS HS20HS072RX (LCSC C5329582) | LOCKED | 1 | $3.42 | $3.42 | [LCSC — HS20HS072RX (C5329582)](https://www.lcsc.com/product-detail/C5329582.html) · [JLC part page](https://jlcpcb.com/partdetail/HS-HS20HS072RX/C5329582) | **LOCKED 2026-07-19.** 2.0" IPS TFT, 240×RGB×320, ST7789T3 (compatible variant — same Zephyr driver), 4-wire SPI, 262K color. Outline 51.80×36.20×2.1mm. 12-pin 0.5mm ZIF FPC (backlight LEDs broken out as LEDA/LEDK — enables PWM dimming). 4 parallel white LEDs, 80mA, Vf 3.0V. LCSC: 1,786 in stock. JLC: Extended (pre-order). EasyEDA footprint available. See project-log.md 2026-07-19 Display Panel Selection. **Backlight**: 4 parallel white LEDs (common anode, ~3.0V Vf, 80mA total). Driven by 3.3V rail through current-limiting resistors + PWM-controlled N-FET on a timer-output GPIO. No dedicated LED driver IC needed. |
| 7c | 1.14" ST7789V raw panel (FPC, outer display for flip lid) | EastRising ER-TFT1.14-2 (BuyDisplay) | LOCKED | 1 | $3.27 | $3.27 | [BuyDisplay — ER-TFT1.14-2](https://www.buydisplay.com/1-14-inch-tft-lcd-display-ips-panel-screen-135x240-for-smart-watch) | **LOCKED 2026-07-19** (replaces Wisevision N114 — see note). 1.14" IPS TFT, 135×240, ST7789V (same driver family as main display — Zephyr `solomon,st7789v`), 4-wire SPI, 65K/262K color. Outline 17.6×31.0×1.6mm. Active area 14.86×24.91mm. **8-pin 0.5mm pitch FPC (top contact)** — standard JLC-stockable ZIF connector (HDGC C2919539). Backlight: 1 white LED, 3.0V, 15mA (PWM dimmable). Supply 2.5–3.3V (3.3V only — no boost converter). Brightness 400 cd/m². Contrast 500:1. Pinout: 1=LEDA, 2=GND, 3=RESET, 4=RS(DC), 5=SDA, 6=SCL, 7=VDD, 8=CS. **Purchased separately from PCB and assembled by user** (ZIF FPC plugs in post-PCB-assembly). 10-year continuity supply promise. See project-log.md 2026-07-19 Outer Display Re-Selection. **Note**: Replaces Wisevision N114-2413THBIG01-H13 (C2890618) — that panel used 0.7mm FPC pitch, which is non-standard and has no JLC-stocked connectors. |

### 3b. Power (CANDIDATE)

| # | Component | Part Number | Status | Qty | Unit Price | Ext Price | Source / Link | Notes |
|---|---|---|---|-----|---|---|---|---|
| 8 | LiPo battery, 3.7V, ~1000–1200mAh (24h standby needs ≥420mAh) | Adafruit 258 (1200mAh) | CANDIDATE | 1 | $9.95 | $9.95 | [Adafruit — 1200mAh LiPo](https://www.adafruit.com/product/258) | 34×62×5mm. 1200mAh gives ~45h standby. Currently out of stock at Adafruit — check alternatives. |
| 9 | Battery charger IC, single-cell LiPo, USB input | MCP73831-2ACI/MC | CANDIDATE | 1 | ~$1.00 | ~$1.00 | [DigiKey — MCP73831](https://www.digikey.com/en/products/detail/microchip-technology/MCP73831-2ACI-MC/1874108) · [Microchip](https://www.microchip.com/en-us/product/mcp73831) | DFN-8 2×3mm, up to 500mA charge current. Charges battery from USB; battery supplies modem peaks (2A+). For production: consider a power-path charger (e.g., BQ25895, 5A) that can supply system load + charge simultaneously. For prototype, MCP73831 is sufficient — battery handles transient peaks. |
| 10 | 3.3V buck-boost regulator (MCU/system rail from LiPo) | TPS63021DSJR (3.3V fixed, 4A switches / ~3A output) | LOCKED | 1 | ~$3.50 | ~$3.50 | [LCSC — TPS63021DSJR (C202140)](https://www.lcsc.com/product-detail/DC-DC-Converters_Texas-Instruments-TPS63021DSJR_C202140.html) | LiPo (3.0–4.2V) → 3.3V. Buck-boost needed: LiPo drops below 3.3V at ~40% charge. Powers MCU, display, SD card, codec I2S side, level shifter. **Part corrected 2026-07-19**: "TPS630201" was a phantom part number (TI never made it). TPS63021DSJR is the real fixed-3.3V part (VSON-14/DSJ, 4A switches, ~3A output — exceeds the original 2A spec). JLC-stocked (C202140) — no consignment needed. See project-log.md 2026-07-19 U8 Buck-Boost Correction. |
| 10a | Power inductor for item 10 (TPS63021DSJR) | Coilcraft XFL4020-152MEC (1.5µH, Isat 4.4A, DCR 14.4mΩ) | LOCKED | 1 | ~$1.25 | ~$1.25 | [LCSC — XFL4020-152MEC (C3033018)](https://www.lcsc.com/product-detail/C3033018.html) | **LOCKED 2026-07-19.** Datasheet-recommended part (TI SLVS916I Table 2 + Table 4 — XFL4020-152ME/ML family). 1.5µH ±20%, 4×4×2.1mm, magnetic shielded. Lowest DCR available at this size (14.4mΩ) → best efficiency on the 3.3V rail. Isat 4.4A at 20% inductance drop — adequate for actual phone load currents (2–3A peak; 4A is the switch current limit, not operating current). JLC "Extended" (757 in stock at LCSC). KiCad model downloaded. Alternative rejected: Taiyo Yuden LSDND4040WKT1R5MM (C6653414, Isat 7A but DCR 35mΩ — 2.4× higher). See project-log.md 2026-07-19 L1 Inductor Selection. |
| 11 | 1.8V LDO regulator (for ALC5651 codec supply, from 3.3V rail) | TPS7A0218PDBVR | CANDIDATE | 1 | ~$0.84 | ~$0.84 | [DigiKey — TPS7A0218PDBVR](https://www.digikey.com/en/products/detail/texas-instruments/TPS7A0218PDBVR/12165118) | 1.8V fixed, 200mA, SOT-23-5. Fed from 3.3V buck-boost (item 10). Low current (~10–20mA codec). |
| 12 | Battery fuel gauge (coulomb-counting, I2C) | MAX17048G+T10 | CANDIDATE | 1 | ~$2.50 | ~$2.50 | [DigiKey — MAX17048](https://www.digikey.com/en/products/detail/analog-devices-inc-maxim-integrated/MAX17048G-T10/5263689) | ModelGauge IC, I2C. Provides state-of-charge (%), voltage, current estimation. Required for FR-4.2 (battery level display). Shares I2C bus with ALC5651. 3.3V-compatible. Alternative: ADC voltage-only (cheaper, less accurate — no coulomb counting). |
| | **Power subtotal** | | | | | **~$9–10** | | |

### 3c. Audio Transducers (CANDIDATE)

| # | Component | Part Number | Status | Qty | Unit Price | Ext Price | Source / Link | Notes |
|---|---|---|---|-----|---|---|---|---|
| 13 | Earpiece speaker, 10mm, 8Ω | Taoglas SPKM.10.8.A | CANDIDATE | 1 | ~$1.69 | ~$1.69 | [Taoglas — SPKM.10.8.A](https://www.taoglas.com/product/10-mm-round-miniature-speaker-500mw/) · [ichome](https://www.ichome.com/product-detail/taoglas/spkm-10-8-a) | 10×4mm, 200mW RMS. For call audio (held to ear). |
| 14 | Loudspeaker (ringtones, speakerphone) | TBD — 20mm+ mylar speaker | CANDIDATE (include on rev1 — locked 2026-07-19) | 1 | ~$2–5 | ~$2–5 | — | Rated 3 on wishlist. ALC5651 has stereo outputs for both. **Rev1 decision (2026-07-19)**: include both earpiece + loudspeaker — stereo outputs drive both at no extra codec cost. Specific part TBD at schematic time. |
| 15 | Microphone (MEMS or electret) | TBD — e.g. Knowles SPQ | TBD | 1 | ~$1–3 | ~$1–3 | — | MEMS preferred for SMD. |
| | **Audio transducer subtotal** | | | | | **~$5–10** | | |

### 3d. Level Shifting (CANDIDATE — required for ALC5651 1.8V↔3.3V)

| # | Component | Part Number | Status | Qty | Unit Price | Ext Price | Source / Link | Notes |
|---|---|---|---|-----|---|---|---|---|
| 16 | 4-bit bidirectional level shifter, 1.8V↔3.3V | TXB0104D | CANDIDATE | 1 | ~$0.76 | ~$0.76 | [TI — TXB0104](https://www.ti.com/product/TXB0104) · [Digi-Key via DiGi Electronics](https://www.digi-electronics.com/en/products/detail/texas-instruments/TXB0104D/1837198.html) | SOIC-14. For MCU I2S lines (SCK, FS, SD, MCLK) to ALC5651. Unidirectional — simple divider also works. |
| | **Level shifting subtotal** | | | | | **~$1** | | |

### 3e. Connectors (CANDIDATE)

| # | Component | Part Number | Status | Qty | Unit Price | Ext Price | Source / Link | Notes |
|---|---|---|---|-----|---|---|---|---|
| 17 | USB-C receptacle, 16-pin, SMD (data + power) — main MCU USB | GCT USB4081 or similar | LOCKED (USB-C locked 2026-07-19) | 1 | ~$1–3 | ~$1–3 | [DigiKey — GCT USB-C](https://www.digikey.com/en/product-highlight/g/gct/usb-type-c) | USB-C 16-pin for USB 2.0 + power. Routes to MCU USB OTG_FS (firmware/files/debug). |
| 17b | USB-C receptacle (or micro-USB) — modem USB HS port footprint | TBD | CANDIDATE (unpopulated on rev1 — locked 2026-07-19) | 1 | ~$1–3 | ~$0 (unpopulated) | — | **Rev1 decision (2026-07-19)**: route SIM7600 USB HS D+/D- to an unpopulated connector footprint. Preserves tethering + modem FW update + diagnostics + GNSS-over-USB + ecosystem options. May be USB-C (consistent) or micro-USB (smaller footprint) — TBD at schematic time. |
| 18 | Nano SIM card socket, SMD, hinged | SHOU HAN NANO SIM XG6P H1.35 | LOCKED | 1 | $0.146 | $0.15 | [LCSC — C7529386](https://www.lcsc.com/product-detail/C7529386.html) | **LOCKED 2026-07-19.** Nano-SIM (4FF), hinged lid, 6-pin (no card detect — optional per SIM7600 manual), 1.45mm height. 38,255 in stock. Hinged chosen over push-push (top-loading, no lateral clearance). See project-log.md 2026-07-19 J3/J4 Sourcing. |
| 19 | MicroSD card socket, SMD, hinged | Molex 472192001 | LOCKED | 1 | $0.765 | $0.77 | [LCSC — C164170](https://www.lcsc.com/product-detail/C164170.html) | **LOCKED 2026-07-19.** MicroSD (TF), hinged lid, 8-pin, 1.9mm height, 1.10mm pitch. Molex OEM. 16,177 in stock. 5,000 cycles. For music/photo storage (rated 7). See project-log.md 2026-07-19 J3/J4 Sourcing. |
| 20a | FPC ZIF connector 12-pin 0.5mm (main display J7) | HDGC 0.5K-HX-12PWB | LOCKED | 1 | ~$0.11 | ~$0.11 | [JLC — C2919494](https://jlcpcb.com/partdetail/HDGC-0_5K_HX12PWB/C2919494) | **LOCKED 2026-07-19.** Hinged lid, double-sided contacts, 1mm height. Same series as J8/J9/J10. Double-sided eliminates top/bottom contact orientation risk (FPC folds under display). |
| 20b | FPC ZIF connector 8-pin 0.5mm (outer display J10) | HDGC 0.5K-HX-8PWB | LOCKED | 1 | ~$0.11 | ~$0.11 | [JLC — C2919492](https://jlcpcb.com/partdetail/HDGC-0_5K_HX8PWB/C2919492) | **LOCKED 2026-07-19.** Same series as J7/J8/J9. For ER-TFT1.14-2 outer display. |
| 20c | FPC ZIF connector 14-pin 0.5mm (hinge flex J8 + J9) | HDGC 0.5K-HX-14PWB | LOCKED | 2 | ~$0.11 | ~$0.22 | [JLC — C2919495](https://jlcpcb.com/partdetail/HDGC-0_5K_HX14PWB/C2919495) | **LOCKED 2026-07-19.** Same series as J7/J10. Two needed (one on main board, one on daughterboard). Need matching 14-pin 0.5mm FFC cable. |
| | **Connector subtotal** | | | | | **~$3–10** | | |

### 3f. Antenna (CANDIDATE)

| # | Component | Part Number | Status | Qty | Unit Price | Ext Price | Source / Link | Notes |
|---|---|---|---|-----|---|---|---|---|
| 20 | LTE cellular antenna, U.FL/IPEX, 700–2700MHz | Pulse W3907B0100 | CANDIDATE | 1 | $5.54 | $5.54 | [ArcAntenna — W3907B0100](https://www.arcantenna.com/products/antenna-for-embedded-iot-modules-lte-catm1-catnb1-egprs-like-quectel-bg96-w3907b0100-with-100mm-cable-ufl-ipex-mhf-connector) | Flexible patch, 100mm cable, U.FL. Covers B2/B4/B66/B71. |
| 21 | GNSS antenna (for SIM7600 built-in GNSS) | TBD — U.FL GPS antenna | CANDIDATE (include on rev1 — locked 2026-07-19) | 1 | ~$2–5 | ~$2–5 | — | SIM7600 has built-in GNSS (validated 2026-07-12 on HAT — valid fix in ~60s cold start). **Rev1 decision (2026-07-19)**: include U.FL footprint on rev1 — user wants this board to potentially be the final version; deferring would mean a respin. Specific antenna part TBD at schematic time. |
| | **Antenna subtotal** | | | | | **~$8–11** | | |

### 3g. Keypad (LOCKED — SMD tactile switches on custom PCB traces)

| # | Component | Part Number | Status | Qty | Unit Price | Ext Price | Source / Link | Notes |
|---|---|---|---|-----|---|---|---|---|
| 22 | SMD tactile switches, 5.2×5.2×1.5mm (keypad matrix) | ALPS Alpine SKQGABE010 (LCSC C115351) | LOCKED | ~20 | ~$0.089 | ~$1.78 | [LCSC — C115351](https://www.lcsc.com/product-detail/C115351.html) · [JLCPCB part page](https://jlcpcb.com/partdetail/ALPSALPINE-SKQGABE010/C115351) | **LOCKED 2026-07-19**: ALPS SKQGABE010 selected. Specs: 1.57N (160gf), 0.25mm travel, 1M cycle life, 1.5mm height, SPST-NO gull-wing SMD. LCSC stock 41,590; JLC stock 1,344. KiCad model downloaded to `pcb/phone/lib/`. Same 5.2×5.2mm footprint across SKQG stem-height variants (3.1/3.4/5.0mm) — swap up without respin if feel is too snappy. See project-log.md 2026-07-19 Keypad Switch Selection. |
| | **Keypad subtotal** | | | | | **~$1–2** | | |

### 3h. ESD Protection (CANDIDATE — required for external connectors)

| # | Component | Part Number | Status | Qty | Unit Price | Ext Price | Source / Link | Notes |
|---|---|---|---|-----|---|---|---|---|
| 23 | USB-C ESD protection (D+/D- lines) | USBLC6-2SC6 | CANDIDATE | 1 | ~$0.50 | ~$0.50 | [DigiKey — USBLC6-2SC6](https://www.digikey.com/en/products/detail/stmicroelectronics/USBLC6-2SC6/6035358) | SOT-23-6, bidirectional ESD for USB 2.0. Protects MCU USB OTG_FS D+/D-. |
| 24 | SIM/SD ESD protection (data lines) | ESDA6V1-5SC6 or similar | CANDIDATE | 1 | ~$0.50 | ~$0.50 | [DigiKey — ESDA6V1-5SC6](https://www.digikey.com/en/products/detail/stmicroelectronics/ESDA6V1-5SC6/6034568) | 5-line ESD array for SIM + microSD data lines. |
| | **ESD subtotal** | | | | | **~$1** | |
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

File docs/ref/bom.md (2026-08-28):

---
status: reference
updated: 2026-08-27
---
# Bill of Materials (BOM)

> **Status**: Preliminary — reflects component selections locked as of 2026-06-28 (MCU, modem, codec, display, keypad). Items not yet selected (power ICs, transducers) are listed as candidates with price ranges. Prices are USD, captured 2026-06-28 from publicly listed distributor pages. Verify current pricing/stock before ordering. **Updated 2026-06-28 (documentation review)**: VBAT buck regulator removed (direct-from-LiPo); 3.3V buck-boost (TPS630201) and fuel gauge (MAX17048) added; ESD protection added; MCP73831 note corrected. **Updated 2026-06-28 (keypad selection)**: Keypad locked — SMD tactile switches on custom PCB traces; prototyping keypad module added to §1. **Updated 2026-06-28 (Nucleo substitution)**: NUCLEO-H743ZI/ZI2 obsolete — NUCLEO-H753ZI is the substitute (H753 = H743 + crypto, identical for this project). DigiKey links added for all prototyping parts. Order consolidation: DigiKey (electronics) + Waveshare (HAT + display) + Mint Mobile (SIM).
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

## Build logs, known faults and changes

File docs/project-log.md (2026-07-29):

# Project Log

## User Background

- Senior year Computer and Systems Engineering student.
- Experience level: between "some hardware experience" and "moderate hardware" — has worked with microcontrollers and designed a few simple PCBs.
- Wants this project to push beyond prior experience into RF, cellular comms, power management, and multi-discipline integration.
- Open to simplifying initial versions but wants the overall project to be challenging and time-consuming.
- Has access to FDM, SLA, and CNC for enclosure fabrication.

## Decision Log

### 2026-06-28: Problem Definition Session
- **Decision**: Target US market — LTE with VoLTE is the only viable network path.
  - *Rationale*: 2G and 3G are shut down in the US. No point building for dead networks.
- **Decision**: Carrier-agnostic, but recommend T-Mobile/Mint for testing.
  - *Rationale*: T-Mobile is most lenient with non-certified devices on prepaid. Good LTE band 2/4/66 coverage.
- **Decision**: MVP = voice calls only (make/receive). Contacts, SMS, menus are post-MVP.
  - *Rationale*: Get to a working call as fast as possible to validate the hardest part (cellular + audio + firmware). Everything else is additive.
- **Decision**: Use RTOS (FreeRTOS or Zephyr) for firmware, not bare metal.
  - *Rationale*: Concurrent requirements (AT command parsing, UI, power management, call state machine) make bare metal unwieldy for a daily-driver. RTOS provides task scheduling without sacrificing control. FreeRTOS vs Zephyr TBD.
- **Decision**: ~~Form factor/mechanical design deferred. Start with single-board design.~~
  - *Rationale*: ~~The hard problems (cellular, firmware, power, RF) are form-factor independent. Locking into flip early adds constraints (flex cable, hinge, multi-board) before core electronics are validated. Decide mechanical design after the phone works on a single board.~~
  - **SUPERSEDED 2026-07-19**: Flip form factor re-locked. Two PCBs (main + display daughterboard) + hinge flex. The display daughterboard is trivial (~5 components), and the main board is the same complexity either way — deferring flip no longer reduces rev1 risk meaningfully. See "2026-07-19: Display Panel Selection + Flip Form Factor Locked" entry below.
- **Decision**: ~~Display type deferred — will recommend based on constraints.~~
  - **SUPERSEDED 2026-06-28**: Display selected — ST7789V SPI color TFT (2.0" 240×320, RGB565). See "Display Selection" decision below.
- **Decision**: ~~Keypad design deferred to Phase 2 prototyping.~~
  - **SUPERSEDED 2026-06-28**: Keypad selected — SMD tactile switches on custom PCB traces (LOCKED). Phase 2 prototyping uses off-the-shelf 4×4 matrix module + loose tactile buttons. See "Keypad Selection" decision below.

### 2026-06-28: Modular Ecosystem Vision
- **Decision**: Adopt a long-term vision of a personal ecosystem of targeted devices, with the phone as the connectivity hub.
  - *Rationale*: Building one perfect do-everything phone is unrealistic as a first project. Decomposing into targeted modules (car system, etc.) makes each piece achievable. The phone remains the primary project.
- **Decision**: First envisioned module is a car system (navigation + music), connecting to phone via USB.
  - *Rationale*: Car dock scenario makes USB ideal — provides data + power in one cable, higher bandwidth than Bluetooth, lower latency. Phone charges while docked. Android USB tethering is native. Car system offloads the hardest work (cellular) to the phone.
- **Decision**: USB is the primary ecosystem interconnect; Bluetooth/WiFi deferred for future wireless modules.
  - *Rationale*: USB is simpler, higher bandwidth, and provides power. Wireless is needed only for modules that can't be physically docked — that's a future problem.
- **Decision**: Ecosystem vision does not change MVP scope, but does constrain hardware selection — MCU must have USB capability.
  - *Rationale*: Selecting an MCU without USB would preclude future ecosystem integration. This is a low-cost constraint (many candidate MCUs have USB) that keeps the door open.

### 2026-06-28: Cellular Module Architecture & Selection
- **Decision**: Use Architecture A — LTE Cat 4 data module + external MCU + external audio codec (not OpenCPU, not analog-audio voice module, not premium carrier-certified module).
  - *Rationale*: Four architectures were evaluated:
    - A: Cat 4 module + MCU + codec (SIM7600/EG25-G class)
    - B: Cat 1 voice module with analog audio pins (Quectel EG912U-GL) — eliminates codec for voice, but music playback needs a separate DAC, creating two audio paths instead of one
    - C: OpenCPU/QuecPython smart module (module IS the MCU, Python firmware) — eliminates MCU/RTOS learning, which is a core project goal
    - D: Premium carrier-certified module (u-blox LARA-R6401, now Trasna) — best VoLTE/carrier support but **disqualified: 911/E911 not supported** (updated 2026-06-28 second round; originally eliminated for supply chain risk, but the 911 issue is the real disqualifier)
  - Architecture A chosen because: (1) music player goal requires a real audio DAC regardless of module, so the codec isn't redundant — it handles both voice (PCM from module) and music (I2S from MCU); (2) preserves full MCU + RTOS + embedded firmware learning; (3) lowest supply risk; (4) Cat 4 gives headroom for ecosystem tethering. **Note (2026-06-28)**: The original claim that a single codec "unifies" PCM and I2S "into one audio path" was found to be false for common single-port codecs (WM8960, NAU8810, etc.) — they have only one digital audio port. The MAX9880A (dual-port codec) is what makes Architecture A actually work. See Codec Selection decision below.
- **Decision**: Select SIMCom SIM7600 series as the cellular module (not Quectel EG25-G).
  - *Rationale*: SIM7600A-H (NA variant) has B66 and B71 (T-Mobile 600MHz Extended Range LTE); EG25-G lacks both. SIM7600A-H has explicit T-Mobile carrier certification; EG25-G does not. Forum evidence shows EG25-G VoLTE falls back to CS (which fails on T-Mobile since 3G shutdown) with carrier-provisioning dependencies that hobbyists can't resolve; SIM7600 has a documented, workable PDP context quirk instead. Waveshare SIM7600G-H 4G HAT provides a complete prototyping platform (NAU8810 codec, SIM slot, antennas, USB-to-UART) ready for immediate VoLTE validation — no equivalent EG25-G breakout with audio.
  - *Tradeoff*: SIM7600's IMS PDP context (cid=2 for VoLTE) can conflict with data on cid=1, requiring careful firmware management of multiple PDP contexts. This is relevant for the ecosystem goal of simultaneous VoLTE + data tethering. Manageable but a real firmware complexity item.
- **Decision**: ~~Prototyping path — Waveshare SIM7600G-H 4G HAT + Mint Mobile SIM for initial VoLTE/audio validation on a PC via USB-to-UART, before any MCU or PCB work.~~
  - **SUPERSEDED 2026-06-28**: Switched to Waveshare SIM7600NA-H 4G HAT (~$89) which has B71 + NAU8810 codec. See "Modem Revisit" decision below. The G-H HAT lacks B71 (T-Mobile 600 MHz), creating a validation gap. The NA-H HAT resolves this.
  - *Rationale*: De-risks the hardest part (VoLTE on a real US carrier) this week with zero custom hardware. HAT includes the NAU8810 codec so voice audio can be tested immediately.
- **Decision**: ~~Final PCB will use SIM7600A-H (NA variant with B66/B71) + a codec capable of both PCM (voice from module) and I2S (music from MCU), e.g., WM8960 or NAU8810-class.~~
  - *Rationale*: ~~Single codec handles both voice and music through one audio path. A-H variant gets full T-Mobile band coverage for the daily-driver goal.~~
  - **SUPERSEDED 2026-06-28**: The codec choice (WM8960 or NAU8810-class) is superseded by the MAX9880A selection. WM8960 and NAU8810 are single-port codecs that cannot accept PCM and I2S simultaneously — the "single codec handles both" claim was false for these parts. The MAX9880A (dual-port codec) is the selected replacement. The SIM7600A-H module choice is retained. See "Codec Selection / Audio Path Architecture" decision below.

### 2026-06-28: RTOS Selection
- **Decision**: Use Zephyr RTOS (not FreeRTOS).
  - *Rationale*: Every subsystem the phone needs is built into Zephyr: USB device stack (CDC ACM, ~~CDC ECM for tethering~~ [superseded — see USB HS/ULPI Revisit: tethering now uses the SIM7600's own USB port, not MCU CDC ECM], MSC for storage access), PPP networking over cellular modem, FatFs/LittleFS for SD card, LVGL for display, power management subsystem for battery policy, BLE stack. With FreeRTOS these would be 5+ separate third-party integrations (TinyUSB, lwIP, FatFs, LVGL, vendor BT stack) that don't always compose cleanly.
  - *Learning alignment*: User explicitly wants a challenging, time-consuming project that pushes beyond prior experience. Zephyr's devicetree + Kconfig + west + subsystems model teaches modern embedded industry practices (Linux-grade workflows) that transfer to Nordic, NXP, Intel, TI ecosystems. The steep learning curve is a feature, not a bug, for this project's goals.
  - *Ecosystem advantage*: ~~CDC ECM (Ethernet-over-USB) is a built-in Zephyr USB function — the phone-as-USB-Ethernet-device for the car module tethering scenario is a config flag, not a from-scratch USB class implementation.~~ **SUPERSEDED 2026-06-28**: The phone-as-USB-Ethernet-device (MCU bridging LTE to CDC ECM) is no longer the tethering architecture — the SIM7600's own USB port does RNDIS/ECM directly. The Zephyr CDC ECM function is no longer needed for tethering (though it remains available if a future use case wants MCU-originated Ethernet-over-USB). See "USB HS / ULPI Revisit" decision below.
  - *Nordic native path*: nRF Connect SDK is Zephyr-based. If nRF52840 is selected for MCU, Zephyr is the native RTOS.
  - *Tradeoff*: Zephyr has a steep learning curve (devicetree, Kconfig, west build system). Expect 1-2 weeks of ramp-up before productive phone firmware work. Mitigation: complete the "Practical Zephyr" tutorial series (memfault) and Shawn Hymel's Zephyr guide before starting phone firmware.
  - *Cellular modem note*: Neither Zephyr nor FreeRTOS has ready-made SIM7600 support. Zephyr's modem subsystem (modem_chat + CMUX + PPP + pipelink) provides a real architecture to plug a SIM7600 port into; FreeRTOS Cellular Library would require building that infrastructure from scratch. This is a wash on effort but Zephyr provides better scaffolding.
- **Decision**: Adopt a "no feature blocking" principle for component selection — all features rated 5+ on the wishlist must remain achievable (hardware-capable, even if not implemented in MVP).
  - *Rationale*: Avoiding rework and respins. If a component choice blocks a 5+ feature, we'd need to swap the component later (MCU change = PCB respin + firmware rewrite). Selecting components with headroom for 5+ features costs little upfront and preserves all options.
  - *5+ features that constrain MCU selection*: USB device (8), SPI/SDIO for MicroSD (7), BLE (6), I2S/audio DAC (6), camera interface (6), color display interface (5-6), video recording processing headroom (5).

### 2026-06-28: Modem Revisit (SIM7600 Selection Review)
- **Decision**: **Stick with SIMCom SIM7600 series** — the four concerns raised in the modem revisit prompt do not collectively justify switching. Two changes adopted.
  - *Rationale*: Four concerns were researched against SIM7600, EG25-G, EG912U-GL, and LARA-R6401:
    1. **Standby power**: The docs' "3 mA sleep" figure was deep-sleep (cannot receive calls), not idle/DRX. Actual SIM7600 LTE idle/DRX current is **17.5 mA** (datasheet: SIM7600E Hardware Design V1.00 Table 26). 24h standby needs ~420 mAh — achievable with an 800+ mAh battery. The modem still dominates standby; MCU sleep (~20 µA) is negligible. EG25-G is worse (22 mA); EG912U-GL is better (14 mA) but eliminated for the two-audio-path problem; LARA-R6401 claims ~1.1 mA (unverified). This concern does not justify switching.
    2. **B71 validation gap (RESOLVED)**: Waveshare makes a **SIM7600NA-H 4G HAT** (~$89) with B71 and the same NAU8810 codec. Switching the prototyping HAT from G-H to NA-H closes the gap — B71 can be validated early without a custom PCB. B71 is supplementary in the user's area (good coverage) but cheap to validate.
    3. **Simultaneous VoLTE + data (real risk, future feature)**: Forum evidence (TinyGSM #649, LilyGO #90) shows SIM7600 PDP context conflicts (IMS cid=2 interferes with data cid=1). No clear hobbyist evidence of successful simultaneous VoLTE+data on SIM7600. EG25-G has better-documented multi-PDP support (PinePhone-proven); LARA-R6401 has best multi-PDN docs. **However**: this is a future ecosystem feature (tethering while on a call), NOT an MVP or daily-driver requirement. The MVP (make/receive calls) is unaffected. Make this the first HAT test; if it fails, it blocks a future feature, not the core phone. Fallback: EG25-G (loses B71) or LARA-R6401 (supply risk).
    4. **LGA assembly (wash)**: All candidate LTE modules are LGA — none are hand-solderable. No LTE/VoLTE module exists in a hand-friendly package. NFR-3 ("hand-solderable for prototypes") is unachievable for any LTE module. Realistic path: JLCPCB assembly for the modem section (~$57–72), hand-solder the rest.
- **Change 1**: Switch prototyping HAT from SIM7600G-H to **SIM7600NA-H** (~$89) — resolves B71 validation gap. Has B71 + NAU8810 codec + GNSS.
- **Change 2**: Make **simultaneous VoLTE + data the first HAT test** (AT command sequence in research-notes.md modem revisit findings). If it fails after genuine effort, revisit with EG25-G or LARA-R6401 as fallbacks — but only for the ecosystem tethering feature, not the MVP.
- **Carrier note**: T-Mobile/Mint is a recommendation, not a lock-in. T-Mobile is most lenient with non-certified devices on prepaid. AT&T/Verizon are stricter on IMEI whitelisting. SIM7600A-H supports bands for all three major US carriers — switching later is possible.
- **Tradeoff**: The SIM7600's PDP context management is a real firmware complexity item and simultaneous VoLTE+data is unproven. The EG25-G would be safer for the ecosystem feature but loses B71 (the original reason for choosing SIM7600). The decision is to validate on the HAT first rather than switch speculatively.
- **SUPERSEDED 2026-06-28 (same day, second round)**: The framing of simultaneous VoLTE+data as "the first HAT test" and as a real risk was overstated. The second-round re-evaluation (below) determined that (a) the PDP context conflict is specific to the `AT+NETOPEN` code path, not the CMUX+PPP path the project uses; (b) simultaneous VoLTE+data is not a requirement for any current phase; and (c) LARA-R6401 is disqualified entirely (911 not supported). See "Modem Revisit (Second Round)" decision below. The two changes (NA-H HAT, VoLTE+data testing) are retained but de-prioritized — VoLTE+data is now an informational HAT test, not a blocking one.

### 2026-06-28: Modem Revisit (Second Round — Full Re-evaluation)
- **Decision**: **SIM7600 confirmed and locked.** No alternative module justifies switching. The modem selection is resolved.
  - *Rationale*: A deeper re-evaluation examined LARA-R6401 supply chain, EC25-AF as a new candidate, the EG25-G T-Mobile VoLTE issue, and the true scope of the SIM7600 PDP context conflict.
    1. **LARA-R6401 — DISQUALIFIED (911/E911 not supported)**: The LARA-R6401 datasheet explicitly states "The 911 and E911 services are not supported." A phone that cannot call 911 is a safety issue. This is a hard disqualifier regardless of its strengths (best multi-PDN, I2S audio, ~1.1 mA idle, carrier certs). Supply risk (Trasna transition) was the initial concern but is secondary — the module is in mass production and available at DigiKey. No built-in GNSS. Small community.
    2. **EC25-AF — strong alternative, not worth switching**: T-Mobile voice certified (unlike EG25-G which is data-only), B71, optional GNSS, 911/eCall supported, multi-PDP with IMS auto-isolated. Available at DigiKey (Mini PCIe ~$60). However: no breakout with integrated codec (slower prototyping), higher idle current (23.3 mA vs 17.5 mA), and the multi-PDP advantage is irrelevant (simultaneous VoLTE+data not required). **Documented as fallback for final PCB if SIM7600 testing reveals a blocking issue.**
    3. **EG25-G T-Mobile VoLTE — clarified**: The EG25-G's VoLTE CS fallback on T-Mobile is a carrier provisioning issue (T-Mobile certifies EG25-G for data only, not voice), not a hardware limitation. The EC25-AF is the proper Quectel alternative (T-Mobile voice certified).
    4. **SIM7600 PDP context conflict — RESOLVED (not a blocker)**: The conflict is confirmed in the `AT+NETOPEN` code path only. This project uses CMUX+PPP (`ATD*99***<cid>#`), which bypasses `AT+NETOPEN` entirely. CMUX+PPP is the standard documented pattern for simultaneous data + AT commands on the SIM7600 (Linux n_gsm, RT-Thread, ESP-IDF). Whether data stays active *during* a live VoLTE call via PPP is unverified but likely (3GPP bearers should coexist). Fallback: pause data during calls — acceptable.
    5. **Simultaneous VoLTE+data — NOT a requirement**: MVP is make/receive calls. Daily driver adds SMS/contacts/menu. None need data during a call. The future ecosystem (car tethering while on a call) is the only scenario, and "pause data during call" is acceptable there too. This was incorrectly treated as a near-term constraint in the first revisit; corrected.
  - *Why SIM7600 wins*: Waveshare NA-H HAT with codec (fast prototyping), built-in GNSS, large community, lower idle current (17.5 mA vs EC25-AF's 23.3 mA), 911 supported. The one advantage EC25-AF had (better multi-PDP) addresses a need the project doesn't have.
  - *Fallback*: EC25-AF for the final PCB if SIM7600 HAT testing reveals a blocking issue. Both are Cat 4, T-Mobile voice certified, B71-capable — switching at PCB time is low-cost.
  - *Tradeoff*: The SIM7600's `AT+NETOPEN` bug is real but irrelevant to this project's CMUX+PPP architecture. Data-during-VoLTE-call is unverified via PPP; if it fails, pause data during calls. No modem switch needed.

### 2026-06-28: MCU Selection
- **Decision**: Select STM32H743 (Cortex-M7 @ 480MHz) as the MCU, in LQFP-144 package (STM32H743ZI).
  - *Rationale*: Four MCU candidates were evaluated against the "no 5+ features blocked" principle and the concurrent processing load requirement:
    - **nRF52840**: Eliminated — no camera interface (blocks photo capture 6, video 5), I2S clock accuracy problems, USB device only (no OTG), 64MHz is tight for MP3 decode.
    - **ESP32-S3**: Viable but with Zephyr USB support only 8 months old (risk for ecosystem tethering), and BLE advantage is moot since neither ESP32-S3 nor STM32 has classic BT (A2DP) — external BT module needed either way.
    - **ESP32-P4**: Most capable for multimedia (hardware H.264, MIPI camera/display) but too new — limited availability, immature Zephyr support, no built-in wireless, likely BGA-only. Too risky for first custom PCB.
    - **STM32L4R5**: Questionable on processing power — 120MHz cacheless M4 running Zephyr's full networking + USB + LVGL + audio stack concurrently is tight, especially for ecosystem tethering (PPP routing + USB CDC ECM + audio + display).
    - **STM32H743**: 480MHz Cortex-M7 with L1 cache (16KB I + 16KB D), hardware JPEG codec, USB OTG FS + HS, DCMI camera, 4x SAI audio, 2x SDMMC, LTDC display controller. Handles the worst-case concurrent load (tethering + music + UI + call) comfortably. ARM Cortex-M7 (career-relevant). Mature Zephyr support (multiple H7 boards in mainline). ~$12-15, within budget.
  - *Processing power analysis*: The real CPU demand isn't any single feature — it's the concurrent subsystem load. Worst case: ~~ecosystem tethering (USB CDC ECM + PPP routing + potentially NAT)~~ [superseded 2026-06-28 — tethering now runs on the modem's USB, not the MCU; MCU load for tethering is ~zero], MP3 decode, LVGL rendering, and modem AT command management all running simultaneously. This is essentially a media player + UI + phone (the router role moved off the MCU). The H7's 480MHz + L1 cache is still the right class of part for this; cacheless M4 parts (L4) would struggle with the remaining media + UI + modem load.
  - *Package choice (LQFP-144)*: The H743 comes in LQFP-100, -144, and -176 (all 0.5mm pitch). LQFP-100 loses USB HS (ULPI requires 12 dedicated pins that don't fit). LQFP-144 retains USB HS and all needed peripherals. LQFP-176 adds little for this project. LQFP-144 is hand-solderable with practice; JLCPCB assembly is the fallback (and will be needed for the SIM7600 LGA module regardless).
  - *Tradeoffs*: Higher power consumption (~20 µA sleep vs 0.4 µA for L4) — but modem dominates at 17,500 µA (17.5 mA LTE idle/DRX, verified 2026-06-28), so MCU sleep current is negligible. Larger package than L4. No built-in BLE — external BT module needed (same as any STM32 path, and same as ESP32-S3 for classic BT).
  - *USB HS note*: ~~True USB High-Speed (480 Mbps) requires an external ULPI transceiver (e.g., USB3300, ~$2). Can start with USB FS (built-in PHY) for MVP and populate ULPI transceiver later for ecosystem tethering. LQFP-144 keeps this option open.~~ **SUPERSEDED 2026-06-28**: USB3300 ULPI dropped — the SIM7600's own USB 2.0 HS port does tethering directly, bypassing the MCU. MCU USB OTG_FS is sufficient. LQFP-144 retained for GPIO margin. See "USB HS / ULPI Revisit" decision below.
- **Decision**: Bluetooth will be added as an external module (not built into MCU).
  - *Rationale*: Neither STM32H7 nor ESP32-S3 has classic Bluetooth (A2DP for audio streaming). Both have BLE (ESP32-S3 built-in, STM32 via external module). Since an external BT module is needed for classic BT regardless of MCU choice, the STM32's lack of built-in BLE is not a disadvantage. An external BT module (e.g., BM83 for classic BT + BLE) can be added when the Bluetooth feature (rated 6) is implemented. This defers the BT component decision without blocking the feature.

### 2026-06-28: Codec Selection / Audio Path Architecture
- **Decision**: Select **MAX9880A** (Maxim/ADI, TQFN-48, ~$1.70) as the audio codec. Dual-port architecture: SIM7600 PCM → MAX9880A primary port (voice), STM32H743 I2S → MAX9880A secondary port (music). **MCU is NOT in the voice audio path during calls.** LOCKED 2026-06-28.
  - *Rationale*: The revisit was triggered by a HIGH PRIORITY open question: the docs claimed a single codec (e.g., WM8960) "unifies" voice (PCM from module) and music (I2S from MCU) into one audio path, but most codecs appeared to be I2S-only with no second PCM port. Three research threads confirmed:
    1. **SIM7600 is PCM-only** (Hardware Design Manual V1.03 §3.6): fixed master mode, short-frame sync, 16-bit linear, 2048/4096kHz clock. No I2S mode, not configurable via AT commands. The Waveshare HAT's NAU8810 is wired in PCM mode to match.
    2. **All common codecs have ONE digital audio port** — WM8960, NAU8810, NAU8822, SGTL5000, TLV320AIC3204/3104, ES8316/8388. They can be configured for I2S *or* PCM, but not both simultaneously. The original "single codec unifies voice and music" claim was **false** for all these parts. The TLV320AIC3106's "alternate bus" is pin multiplexing, not a second independent port (confirmed by TI forum).
    3. **MAX9880A is the only hobbyist-accessible dual-port codec** — two truly independent digital audio interfaces (primary for voiceband PCM/TDM, secondary for stereo I2S/TDM), running simultaneously and asynchronously. ~$1.70 in TQFN-48 (hand-solderable with hot air). Designed specifically for smartphones (voice + media). The TLV320AIC34 is also dual-port but BGA-only (not hobbyist-friendly).
  - *Why MAX9880A over MCU bridge*: The alternative was an MCU bridge (SAI1 PCM slave from SIM7600 → SAI2 I2S master to single-port codec). This is feasible on the H743 (~8-10ms latency, <1% CPU, well within ITU G.114) but has two problems: (a) the MCU is always in the voice audio path, adding latency and firmware complexity (real-time DMA bridging, cache coherency, codec rate switching between 8kHz calls and 48kHz music); (b) Zephyr's STM32H7 SAI driver is immature (PR #92887 in progress, not confirmed merged) — could require driver porting or direct HAL usage. The MAX9880A avoids both issues: voice goes directly module→codec (MCU not involved), and the MCU I2S for music is simpler and more tolerant. The MAX9880A is also cheaper ($1.70 vs WM8960 $6-12 obsolete) and matches real smartphone architecture.
  - *Why not two codecs* (NAU8810 for voice PCM + PCM5102 for music I2S): This is the "two audio paths" problem originally rejected — needs an analog mixer/switch to combine outputs to the speaker, more components, more PCB complexity. The MAX9880A does the mixing internally. Eliminated.
  - *Pre-PCB verification items*: (1) Confirm MAX9880A primary port supports PCM short-frame sync, 16-bit, master clock from module (check datasheet — subagent reported "TDM and I2S formats"; PCM short-frame is a common TDM subset but must be confirmed). (2) Verify stock availability at DigiKey/Mouser (Maxim/ADI parts can have long lead times). (3) MAX9880A is 1.8V supply — add 1.8V LDO and level shifter for MCU's 3.3V I2S lines (unidirectional, simple). (4) MAX9880A is NOT on the Waveshare HAT (HAT has NAU8810) — committed for final PCB, not prototyped on HAT.
  - *Fallback*: If MAX9880A is unavailable or PCM-incompatible, fall back to MCU bridge architecture with NAU8822 (single-port I2S codec, ~$1.20). SAI1 as PCM slave, SAI2 as I2S master. Run codec at 8/16kHz during calls, 48kHz for music. Requires Zephyr H7 SAI driver. See research-notes.md Codec Selection Finding 3.
  - *Prototyping impact*: The Waveshare NA-H HAT prototyping step is **unchanged** — it validates the SIM7600's PCM voice output on T-Mobile VoLTE using the NAU8810. This is the riskiest unknown and is independent of the final codec choice.
  - *Tradeoff*: The MAX9880A is less documented in the hobbyist community than WM8960/NAU8810. The 1.8V supply adds a small amount of power-supply complexity (one LDO + one level shifter). These are minor compared to the firmware complexity of the MCU bridge alternative.

### 2026-06-28: Display Selection
- **Decision**: Select **ST7789V SPI color TFT** (2.0" 240×320, 4-wire SPI, RGB565, ~$5–8) as the display. LOCKED 2026-06-28.
  - *Rationale*: The display decision was triggered by the approaching schematic phase (display interface affects PCB routing and GPIO allocation) and the "no 5+ features blocked" principle — the display must be color-capable (photo capture rated 6, camera preview rated 6, video recording rated 5; a monochrome display would block these). Five options were evaluated:
    1. **SPI color TFT (ST7789V, 2.0" 240×320)** — SELECTED. 6 GPIO pins, 150KB framebuffer fits internal 1MB SRAM (no external SDRAM), ~$5–8, ~30–50mA with backlight (off during standby — modem dominates at 17.5mA). Zephyr `display_st7789v.c` is the most mature SPI display driver in main tree; LVGL has native ST7789 support. Camera preview ~15–25fps partial updates (adequate for rated-6 casual photos). 240×320 @ 2.0" ≈ 200 PPI — standard feature-phone resolution.
    2. **SPI color OLED (SSD1351, 1.5" 128×128)** — rejected. **Actually higher power than TFT** (~57–71mA: VCI 23–29mA + Vcc 33–42mA per datasheet — self-emissive OLED draws current per pixel; for bright text/menus it's less efficient than a backlit TFT). 3–5x more expensive ($15–24 vs $5–8). 128×128 too low for phone UI/camera preview. Not in Zephyr main tree (issue #88923 open; only out-of-tree driver nktsb/zephyr-ssd1351-driver). SSD1327 is in Zephyr but grayscale, not color. No larger color OLED options exist at reasonable prices.
    3. **E-ink (B/W or spot-color BWRY)** — **DISQUALIFIED** by "no 5+ blocked" on two grounds: (a) refresh rate makes camera preview impossible — monochrome partial refresh ~0.3s (3fps best case), color full refresh 12–22 seconds; camera preview (rated 6) needs ~15+ fps; (b) "color" e-ink at 1.5–2.4" is spot-color only (black/white/red/yellow — no blue, no green, no gradients), cannot display photos; true full-color e-ink (ACeP) starts at 6"+ and $100+. Blocks three 5+ features: photo capture (6), camera preview (6), video recording (5). E-ink's advantages (ultra-low power, bistable, sunlight readable) are genuine but don't outweigh blocking three 5+ features. Worth revisiting only if camera/photo/video are ever downgraded below 5 on the wishlist.
    4. **Parallel RGB TFT via LTDC (2.0" 320×480)** — rejected. 20 (RGB565) or 28 (RGB888) GPIO pins — eats the spare-GPIO margin on LQFP-144 needed for future peripherals (BT 4 pins, modem USB 2 pins; ~~ULPI 12 pins~~ dropped 2026-06-28). Needs external SDRAM via FMC for comfortable double-buffering (320×480 RGB565 = 300KB single, 600KB double — very tight in internal SRAM). More complex Zephyr devicetree (timings/porches/polarity). 320×480 overkill for a feature-phone UI. The smoother camera preview (parallel bus + DMA2D) does not justify the GPIO/memory/complexity cost for a rated-6 "casual photos" feature. (Note: the spare margin was 31 with ULPI planned; it is now 41 after the USB HS/ULPI Revisit dropped ULPI — see that decision below. The LTDC rejection stands regardless.)
    5. **SPI TFT 1.8" 128×160 (ST7735)** — rejected. Too low resolution for a usable phone UI. 240×320 (ST7789) is strictly better for the same effort/cost.
  - *Why ST7789V wins*: (1) Zephyr driver maturity — `display_st7789v.c` in main tree, widely used, native LVGL support; (2) GPIO-efficient (6 pins preserves spare margin for future 6+ ecosystem features); (3) no external SDRAM (150KB fits internal SRAM); (4) color-capable (satisfies "no 5+ blocked"); (5) **lower power than the color OLED alternative** (backlight off during standby, modem dominates; OLED actually draws more during use at ~57–71mA vs ~30–50mA); (6) 240×320 is the right feature-phone resolution; (7) lowest cost of viable color options (~$5–8 vs $15–24 for OLED).
  - *"No 5+ blocked" confirmation*: Photo capture (6) ✓, camera preview (6) ✓ (SPI ~15–25fps adequate), video recording (5) ✓, MP3/music (6) ✓, MMS (6) ✓, Bluetooth (6) ✓, hotspot/tethering (6) ✓, MicroSD (7) ✓, USB data (8) ✓. No 5+ feature blocked.
  - *Pre-PCB verification items*: (1) Confirm ST7789v Zephyr driver works on STM32H7 with target Zephyr version — the MIPI DBI API conversion (issue #73750) had teething issues (SPI word size, data transfer), verify on dev board before PCB. (2) Select specific panel module (ST7789V + 240×320 + SPI) from LCSC/DigiKey/Adafruit/Waveshare; confirm FPC/connector footprint. (3) Confirm panel max SPI clock (typically 40MHz) and STM32H7 SPI can drive it. (4) Plan backlight PWM on timer-output GPIO for dimming/power management (display off during standby per FR-4.3).
  - *Tradeoff*: SPI bandwidth limits camera preview to ~15–25fps partial updates (not smooth video). LTDC would be smoother but costs 14–22 more GPIO + external SDRAM + complexity. For a feature-phone camera (casual photos, rated 6), SPI is adequate. If video recording (rated 5) becomes a priority later, the LTDC path remains available on the H743 — but it would require revisiting the GPIO budget and likely the LQFP-176 package.
  - *Form factor note*: 2.0" is the primary recommendation. 2.4" is an acceptable alternative (same controller/resolution, larger physical size, lower PPI ~167 — easier to read but bulkier). Form factor is still deferred; the display choice is reasonable for an eventual phone enclosure. IPS variant preferred for viewing angle.

### 2026-06-28: USB HS / ULPI Revisit — Architecture Change to Modem-Direct USB Tethering

- **Decision**: **Drop the USB3300 ULPI transceiver / MCU USB OTG_HS path.** Use the SIM7600's own USB 2.0 HS port for ecosystem tethering (RNDIS/ECM via `AT+CUSBPIDSWITCH`), bypassing the MCU entirely. Use the MCU's USB OTG_FS (12 Mbps, built-in PHY) for all MCU-originated USB (firmware updates, file/MSC transfer, CDC ACM debug).
  - *Rationale*: Two findings drive this:
    1. **Zephyr STM32H7 USB OTG_HS + ULPI is viable but no longer needed.** ULPI support is in mainline Zephyr (PR #52772, merged Dec 2022; issue #52420 closed/completed 2024-05-14; bugs #61464 ECM-assertion and #75179 new-stack-ULPI both fixed by #104825/#76115). The STM32H747I-DISCO is a mainline board using ULPI (USB3300), confirmed working with the `cdc_acm` sample. The scary "H743 HS can't receive data" bug (#57499) was **hardware** — a floating USB3300 IO power rail; the reporter fixed it and confirmed "USB reliable and matches dev boards." So ULPI works, but it is the less-trodden path (only one mainline H7 board uses it; clock config is confusing — issue #71248 has open TODOs; ULPI pinctrl slew rate must be "high-speed"; new UDC stack is less battle-tested for ULPI than FS).
    2. **The SIM7600's own USB port does tethering directly and better.** The SIM7600 has a USB 2.0 HS (480 Mbps) device port (SIMCom hardware design PDF: "USB2.0 is up to 480Mbps"). It presents itself as a USB network adapter via RNDIS (`AT+CUSBPIDSWITCH=9011,1,1`) or ECM (`=9018,1,1`), simultaneously exposing AT/ttyUSB serial ports (composite device — confirmed via `lsusb` on Raspberry Pi). This is the module's native, best-supported tethering path (used by RPi, routers), independent of the `AT+NETOPEN` bug and independent of the project's CMUX+PPP-over-UART path. The modem's USB is free to be dedicated to tethering because the MCU controls the modem via UART.
  - *Architecture impact*: For ecosystem tethering, the car module (USB host) connects to the modem's USB (USB device) and gets LTE at 480 Mbps — no MCU bridging, no ULPI, no USB3300, no Zephyr USB HS stack, no 12 GPIO pins. The MCU USB FS bottleneck only existed when the MCU bridged LTE data to CDC ECM; that bridge is eliminated. MCU USB FS (12 Mbps) is sufficient for firmware, file transfer, and debug.
  - *Topology*: The phone has two USB device ports (MCU OTG_FS, modem USB HS) and the car module is a host. Connecting two devices to one host over one cable requires a USB hub. **Rev1 (minimal commitment)**: route the modem USB D+/D- to a connector footprint or test points; MCU USB on the main USB-C. **Future ecosystem respin**: add an internal USB 2.0 hub (e.g., USB2514, ~$1–2) so a single USB-C presents both the modem (RNDIS for LTE) and the MCU (MSC for files) to the car module — simultaneous LTE + file access over one cable.
  - *Supersedes*: The "USB HS via external ULPI transceiver (USB3300) is a board-level upgrade path preserved by the LQFP-144 package" claim (requirements.md Resolved Questions "USB mode", research-notes.md USB HS/ULPI Clarification practical path). LQFP-144 is retained — it was also chosen for its GPIO margin (now 41 spare after dropping ULPI), camera bit depth, and overall peripheral fit, not ULPI alone.
  - *Tradeoff*: Defers the hub topology to a future respin (tethering is rated 6, post-daily-driver scope). The modem USB routing footprint on rev1 keeps the door open at near-zero cost. If a future use case ever needs the MCU itself to do HS USB (not tethering), the ULPI path remains available on LQFP-144 and Zephyr supports it — but that is not a current requirement.
  - *Pre-PCB / prototype verification*: (1) Validate `AT+CUSBPIDSWITCH=9018,1,1` (ECM) and `=9011,1,1` (RNDIS) on the Waveshare NA-H HAT connected to a Linux host — confirm enumeration as a network adapter and LTE data flow (cheap HAT test). (2) Confirm whether the modem can run PPP-over-UART (MCU data) simultaneously with RNDIS-over-USB (car module data) — two PDP contexts; likely yes but unverified. See research-notes.md "USB HS / ULPI Revisit" section.

### 2026-06-28: Documentation Review — Stale Items Fixed, Missed Power/Hardware Factors Resolved
- **Decision**: Conducted in-depth cross-document review for conflicts, stale items, and missed factors. Fixed 5 stale items and resolved 6 missed hardware factors with PCB impact.
  - *Rationale*: The project has made guiding hardware choices (MCU, modem, codec, display, USB architecture all locked). Before moving to schematic design, the docs must be internally consistent and all PCB-impacting factors must be identified and resolved — not deferred.
  - *Stale items fixed*:
    1. **BOM item 4 (MCU) notes**: Removed "USB HS via ULPI transceiver (future)" — USB HS/ULPI was dropped 2026-06-28. Replaced with correct note (USB OTG_FS, LQFP-144 for GPIO margin).
    2. **research-notes.md Package Selection table**: Struck through USB HS (ULPI) column and "LQFP-144 selected to preserve USB HS option" rationale. Annotated as SUPERSEDED — LQFP-144 retained for GPIO margin (41 spare), not USB HS.
    3. **problem-definition.md constraints table**: Changed "RTOS (FreeRTOS or Zephyr)" to "Zephyr RTOS" (locked decision).
    4. **requirements.md Resolved Decisions**: Changed "RTOS (FreeRTOS or Zephyr)" to "Zephyr RTOS" (locked decision).
    5. **requirements.md Open Questions**: Moved "USB mode: device-only vs OTG" to Resolved Questions (answered: device mode sufficient, OTG host is a bonus not a requirement).
  - *Missed factors resolved (all have PCB impact — resolved now, not deferred)*:
    1. **VBAT regulator**: The docs specified a "dedicated high-current buck regulator for the modem VBAT rail." This was **incorrect** — the SIM7600 VBAT range (3.4–4.3V) matches the LiPo operating range (3.4–4.2V), so VBAT is powered **directly from the LiPo** with a separate power net (not shared with MCU 3.3V) and bulk capacitance (100–470µF). No buck regulator needed. The "dedicated rail" requirement is satisfied by a separate PCB power net, not a separate regulator. BOM item 11 removed; cost saving ~$3–6.
    2. **3.3V system rail regulator (was missing from BOM)**: The MCU, display, SD card, and codec I2S side need a stable 3.3V supply. The LiPo (3.0–4.2V) drops below 3.3V at ~40% charge — a buck-only regulator is insufficient. **Selected: TPS630201 buck-boost** (3.3V fixed, 2A, ~$3.50). Added to BOM as item 10. This was a critical gap — the BOM had no 3.3V regulator at all.
    3. **Battery fuel gauge (was missing — FR-4.2 requires battery monitoring)**: **Selected: MAX17048** I2C fuel gauge (ModelGauge, coulomb counting, ~$2.50). Shares I2C bus with MAX9880A. More accurate than ADC voltage-only (coulomb counting tracks charge during 2A modem bursts; ADC-only has ~10% error). Added to BOM as item 12.
    4. **ESD protection (was not documented)**: All external connectors need ESD protection diodes. **Selected: USBLC6-2SC6** for USB-C D+/D- (~$0.50), **ESDA6V1-5SC6** for SIM/microSD data lines (~$0.50). Added to BOM as items 23-24. Standard practice for any device with external connectors.
    5. **Display backlight driver (raw panel)**: The Waveshare module has onboard backlight circuit, but the raw panel (BOM 7b) does not. Most 2.0" ST7789V panels use 4 parallel white LEDs (common anode, ~3.1V Vf, 80mA total) — driven by 3.3V rail through current-limiting resistors + PWM-controlled N-FET. No dedicated LED driver IC needed for parallel-LED panels. Series LEDs would need a boost driver. **Pre-PCB: verify panel backlight config (parallel vs series).** Documented in constraints.md Display section and BOM item 7b notes.
    6. **Modem PWRKEY/STATUS GPIO (was implied but not documented)**: The SIM7600 requires a PWRKEY GPIO (pulse to power on/off) and a STATUS output GPIO (module ready). **Allocated 2 GPIO pins** in the GPIO budget. Documented in constraints.md MCU section. Not optional — the MCU cannot power-cycle the modem without them.
  - *MCP73831 BOM note corrected*: The original note said "May need higher-current variant for 2A modem peaks" — this conflated charging current with system load current. The charger IC charges the battery; the battery supplies modem peaks. MCP73831 (500mA) is sufficient for charging a 1200mAh battery. Note corrected in BOM.
  - *Revisit prompts archived*: All four revisit prompts (modem, codec, display, USB HS/ULPI) confirmed RESOLVED & LOCKED. Moved to `docs/revisit-prompts/archive/`. Added `docs/revisit-prompts/README.md` with archive index.
  - *BOM cost impact*: Net change approximately +$2.50 (removed ~$3–6 buck regulator, added ~$3.50 buck-boost + ~$2.50 fuel gauge + ~$1 ESD). New BOM total: ~$98–146 (was ~$94–145). NFR-5 target (< $150) still achievable.

### 2026-06-28: BOM Document Created
- **Decision**: Created `docs/bom.md` — preliminary Bill of Materials with prices and links to active online listings.
  - *Rationale*: Needed a consolidated, sourced cost estimate for the prototype BOM (NFR-5: < $150/unit) and total project budget (`docs/constraints.md`: $200–500 realistic). Prices captured 2026-06-28 from publicly listed distributor pages (ST eStore, DigiKey, LCSC, Waveshare, Adafruit, BuyDisplay, Taoglas, Analog Devices, etc.).
  - *Key findings*:
    - **Components-only BOM**: ~$91 (low) to ~$147 (high) — NFR-5 target (< $150) is achievable at the low end, tight at the high end. ~~These figures are pre-documentation-review.~~ **UPDATED 2026-06-28 (documentation review)**: ~$98 (low) to ~$146 (high) — VBAT buck regulator removed, 3.3V buck-boost + fuel gauge + ESD added. See "Documentation Review" decision below and `docs/bom.md` §5 for current figures.
    - **Dominant cost**: Cellular module (~$28–32) + JLCPCB LGA assembly (~$57–72/board). Minimizing PCB respins is the biggest cost lever.
    - **Total per unit (BOM + PCB fab/assembly)**: ~$153–269. PCB fab/assembly is correctly excluded from the NFR-5 BOM target per `docs/requirements.md`.
    - **Total project estimate**: ~$380–686 (prototyping + first PCB + 1–2 respins + tools). High end exceeds $500 if multiple respins needed.
  - *Status of components in BOM*:
    - **LOCKED**: MCU (STM32H743ZIT6, $14.61), modem (~~SIM7600A-H~~ → **SIM7600NA-H**, ~$28–32 → $31.42 JLC pre-order; name corrected 2026-07-19 — see 2026-07-19 entry), codec (MAX9880AETM+T, ~$1.70), display (ST7789V 2.0" 240×320 SPI TFT, $11.99 module / ~$5–8 raw panel), prototyping HAT (Waveshare SIM7600NA-H, $76.99).
    - **CANDIDATE** (not yet locked, revisit pending): battery (1200mAh LiPo, $9.95), charger (MCP73831, ~$1), **3.3V buck-boost (TPS630201, ~$3.50)**, 1.8V LDO (TPS7A0218, ~$0.84), **fuel gauge (MAX17048, ~$2.50)**, level shifter (TXB0104, ~$0.76), **ESD protection (USBLC6-2SC6 + ESDA6V1-5SC6, ~$1)**, USB-C connector, nano SIM socket, microSD socket, cellular antenna (Pulse W3907B0100, $5.54), earpiece speaker (Taoglas SPKM.10.8.A, ~$1.69).
    - **TBD** (deferred): loudspeaker, microphone, GNSS antenna. ~~Keypad~~ **RESOLVED 2026-06-28 — SMD tactile switches on custom PCB traces (LOCKED).** ~~High-current buck regulator for modem VBAT~~ **RESOLVED 2026-06-28 — not needed (direct from LiPo).**
  - *Open verification items carried forward*: MAX9880A PCM short-frame sync + stock; ~~SIM7600A-H JLCPCB consignment~~ **RESOLVED 2026-07-19 — SIM7600NA-H via JLC pre-order (C5380303, $31.42), not consignment**; ST7789V Zephyr driver on STM32H7; ~~keypad design~~ **RESOLVED 2026-06-28 (SMD tactile switches, LOCKED)**; ~~buck regulator selection~~ **RESOLVED (direct from LiPo)**; 3.3V buck-boost verification; fuel gauge I2C address check; display backlight config (parallel vs series). See `docs/bom.md` §6.

### 2026-06-28: Project Kickoff
- **Decision**: Use off-the-shelf cellular module + custom MCU architecture (not designing custom modem).
  - *Rationale*: Designing a custom cellular modem is impractical. Off-the-shelf modules handle the radio protocol stack while still being challenging in PCB/firmware/mechanical design.
- **Decision**: Target LTE (not 2G/3G) for network compatibility.
  - *Rationale*: 2G and 3G networks are decommissioned or sunsetting in the US. LTE with VoLTE is the only viable long-term option.
- **Decision**: Use KiCad for PCB design.
  - *Rationale*: Open-source, well-supported, no license cost.
- **Decision**: ~~Flip/clamshell form factor with two PCBs connected via flex cable.~~
  - *Rationale*: ~~Core to the project concept. Adds mechanical and routing complexity (desired challenge).~~
  - **SUPERSEDED 2026-06-28**: Form factor deferred. Single-board first, mechanical design after electronics proven. See "Problem Definition Session" decision above. This entry is retained for history only — do not reference it as an active decision.
  - **RE-LOCKED 2026-07-19**: Flip form factor re-confirmed. Two PCBs (main + display daughterboard) + hinge flex cable. See "2026-07-19: Display Panel Selection + Flip Form Factor Locked" entry below for full rationale. The 2026-06-28 deferral is itself superseded — flip is now the active form factor decision.

### 2026-06-29: MAX9880A Pre-PCB Verification — PASSED

- **Decision**: MAX9880A pre-PCB verification items are **resolved — no blockers found**. The codec is confirmed compatible with the SIM7600's PCM interface and is available for purchase.
  - *Rationale*: The docs listed two pre-PCB verification items for the MAX9880A (PCM short-frame sync compatibility + stock availability). Both are now confirmed, de-risking the final PCB codec choice.
- **Verification 1 — PCM short-frame sync: COMPATIBLE.** The MAX9880A datasheet documents "TDM Short-Sync" mode (TDM=1, FSW=0) with explicit timing parameters for slave mode (MAS=0). PCM short-frame sync is electrically identical to TDM with 1 timeslot — a short FS pulse (1 bit clock wide) marks each 16-bit sample. The MAX9880A's TDM clock range (128–2048 kHz) encompasses the SIM7600's 2048 kHz BCLK. The SIM7600 is always PCM master; the MAX9880A primary port in slave mode accepts external BCLK + FS. Register config at schematic time: TDM=1, FSW=0, MAS=0, 16-bit slot.
- **Verification 2 — Stock: AVAILABLE.** Mouser has 2,250 in stock (700-MAX9880AETM+T, $2.23 qty 1, $1.52 qty 50+). DigiKey temporarily out (normal for ADI/Maxim parts — cycles in/out). Part is active (not discontinued), manufacturer lead time 6–13 weeks. No supply risk.
- **Remaining schematic-time check**: ~~Verify SIM7600 PCM pin I/O voltage in the Hardware Design Manual.~~ **RESOLVED 2026-06-30**: SIM7600 PCM pins are **1.8V** — confirmed from the Hardware Design Manual V1.03 via direct PDF extraction (MCP `mcp-pdf` server, PyMuPDF). Two pieces of evidence: (1) **Table 32: "1.8V Digital I/O characteristics"** (page 47) — VOH = 1.35–1.8V, VIH = 1.17–2.1V, covering all digital I/O pins including PCM_OUT/IN/SYNC/CLK; (2) **§3.6.2 PCM Application Guide** (page 35) — the reference design wires PCM directly to a NAU8810 codec powered by the module's own VDD_1V8 pin (1.8V LDO output, max 50mA), with no level shifter on the PCM lines. **Conclusion: PCM lines connect directly to MAX9880A (also 1.8V) with no level shifter.** The only level shifter needed is on the MCU's 3.3V I2S lines (already planned).
- **Impact**: The MAX9880A fallback (MCU bridge with NAU8822) remains documented but is now unlikely to be needed. The codec is fully de-risked for PCB commit — all pre-PCB verification items (PCM sync, stock, voltage) are resolved.

### 2026-06-30: Reference Docs Infrastructure + PDF MCP Server

- **Decision**: Set up local reference documentation storage (`docs/reference/`) and a PDF MCP server for extracting text/tables from vendor datasheets during design work.
  - *Rationale*: As the project moves toward schematic and PCB design, the agent will need frequent, reliable access to datasheet specs (pin voltages, register addresses, timing parameters, electrical characteristics tables). Web search snippets are incomplete and sometimes wrong — the SIM7600 PCM voltage was confirmed from the actual datasheet's reference design diagram (page 35), which no search snippet exposed. Having local PDFs + an MCP extraction tool means verifiable answers from primary sources.
- **Reference docs directory**: `docs/reference/` holds vendor PDFs and saved wiki pages. Gitignored (`.gitignore` excludes everything except `README.md`) — large binaries don't belong in git. The tracked `docs/reference/README.md` indexes every file with its exact part number and download URL so the set is reproducible. Files present: SIM7600 HW Design V1.03 + V1.08, MAX9880A datasheet, STM32H743ZI datasheet + RM0433 reference manual, NUCLEO-H753ZI UM2407, ST7789V datasheet, Waveshare wiki pages (2" LCD module + SIM7600NA-H 4G HAT).
- **PDF MCP server**: `mcp-pdf` (rsp2k/mcp-pdf, PyPI, MIT license) configured in Windsurf MCP config (`~/.codeium/windsurf/mcp_config.json`), auto-imported by Devin. Provides 14 tool mixins: text extraction (PyMuPDF + pdfplumber + pypdf auto-fallback), table extraction (Camelot + pdfplumber + Tabula), OCR (Tesseract), document structure/TOC, image/SVG extraction, form handling, annotations. Tested against SIM7600 HW Design V1.03 (encrypted PDF) — extracted page 35 in 0.06s via PyMuPDF. Handles encrypted vendor PDFs that `webfetch` cannot parse.
- **Tooling**: `uv`/`uvx` (Astral v0.11.25, installed via `winget install astral-sh.uv`) manages the isolated Python environment for `mcp-pdf` — `uvx mcp-pdf` auto-creates and caches an env with the right Python version (3.11+) and all deps. No manual venv maintenance, no pollution of the Zephyr venv. MCP config uses full path to `uvx.exe` since winget PATH updates aren't visible to the Devin process mid-session.
- **Workflow**: When verifying a spec from a datasheet, call the MCP tools against the local PDFs rather than web search. See AGENTS.md "Reference Documentation & PDF MCP Server" section for details.

### 2026-07-05: Firmware Prep Started — Zephyr App Skeleton

- **Decision**: Begin firmware development while waiting for prototyping hardware. The project-log 2026-06-29 entry identified firmware as the highest-leverage use of downtime — code compiles against `nucleo_h753zi` and is flashable the day hardware arrives.
  - *Rationale*: All four major component decisions are LOCKED (modem, codec, display, keypad). All pre-PCB verification items are resolved. The Zephyr toolchain works. The only thing missing is physical hardware — but firmware architecture, devicetree config, AT parser, call state machine, and keypad scanner can all be developed and compiled without it. Front-loading this work compresses the timeline once hardware arrives.
- **Decision**: Rename project directory from `Personal Projects` to `personal_projects` (underscore, no spaces).
  - *Rationale*: Zephyr's devicetree preprocessor (C preprocessor invocation) splits file paths at spaces — `C:/Users/dengle/Documents/Personal Projects/phone/firmware/app.overlay` was parsed as two separate overlay paths ("Personal" and "Projects/phone/..."), causing a fatal build error. This is a known Zephyr limitation with paths containing spaces. Renaming the directory is the clean fix — no junctions or workarounds needed.
- **RTOS choice reviewed and confirmed**: Re-evaluated Option B (FreeRTOS + hand-integrated libraries) vs Option C (Zephyr application). The key differentiator for this project is **CMUX (GSM 07.10 mux) + PPP over UART** — the SIM7600 data path requires running AT commands and PPP simultaneously on one UART. In FreeRTOS, this is a from-scratch integration of a GSM 07.10 mux with lwIP's PPP (weeks of work, common project-staller). In Zephyr, it's a configured first-class subsystem. The existing Zephyr decision holds.
- **Zephyr adoption verified**: Linux Foundation 10-year report (March 2026) — 70% of surveyed NA organizations use Zephyr in commercial products, 69% plan to increase usage, only 1% plan to decrease. Nordic's nRF Connect SDK (the official SDK for all modern Nordic BLE chips) is Zephyr-based. Devicetree + Kconfig workflow is the same model as the Linux kernel. Learning Zephyr is a genuine career-relevant skill, not a niche tool.
- **Zephyr app architecture**: Four-file separation mirrors Linux's concern model:
  - `CMakeLists.txt` — build manifest (how to build)
  - `prj.conf` — Kconfig feature config (what subsystems to enable)
  - `app.overlay` — devicetree hardware config (what hardware exists, how it's wired)
  - `src/main.c` — application code (what the device does)
  - Each concern changes at a different rate and for a different reason. Hardware config changes when the PCB changes; feature config changes when capabilities are added; app code changes when behavior changes. Separating them means a PCB respin doesn't require touching app logic, and vice versa.
- **Skeleton created and verified**: `firmware/` directory with all four files. `prj.conf` enables shell, logging (INFO level), 4KB heap. `app.overlay` is an empty placeholder (skeleton uses only board built-ins). `main.c` is a heartbeat loop with `LOG_INF` startup message. Build succeeds: 60,476 B flash (3% of 2MB), 32,000 B RAM (3% of 1MB+). For comparison, blinky was 19,666 B / 4,544 B — the difference is shell + logging + heap, all expected.
- **Build issues encountered and fixed**:
  - (1) Space in directory path broke devicetree preprocessor → renamed `Personal Projects` to `personal_projects`.
  - (2) `CONFIG_PREEMPT_ENABLED` is not directly user-settable in Kconfig (it's derived from thread configuration) → removed from prj.conf, added explanatory comment.
  - (3) Kconfig doesn't support inline `#` comments on config value lines (`CONFIG_X=3  # comment` is parsed as value `3  # comment`) → moved comment to its own line above the config.
  - (4) `KERNEL_VERSION_STRING` macro needs an include we didn't have → removed the line (non-essential for skeleton).
- **Next steps**: Add modem UART to `app.overlay` + begin AT command parser/URC handler in `src/`. The AT command test sequences are already documented in `docs/research-notes.md` lines 624–652. The parser will be testable without hardware via mock UART input.

### 2026-06-29: Zephyr Development Environment Setup

- **Decision**: Set up the Zephyr development environment on Windows (native, not WSL) ahead of hardware delivery, to learn the west/devicetree/Kconfig workflow and enable firmware development the moment the Nucleo board arrives.
  - *Rationale*: Zephyr's learning curve is the critical path for firmware (per RTOS Selection decision — "the steep learning curve is a feature, not a bug"). Setting it up while waiting for parts is the highest-value use of downtime. Native Windows (not WSL) per Zephyr docs — WSL flashing is not supported.
- **Environment installed**:
  - **Host tools** (via winget): CMake 4.3.3, Ninja 1.13.2, gperf 3.1, dtc 1.6.1, 7-Zip 26.01, Python 3.12.10 (separate from system Python 3.10).
  - **Zephyr workspace**: `C:\Users\dengle\zephyrproject` (external to the phone repo — multi-GB tree). Python 3.12 venv at `zephyrproject\.venv` (contains west 1.5.0 + all Zephyr Python deps).
  - **Zephyr source**: main branch (version 4.4.99 / `v4.4.0-6582-g191d4b5cada0`), fetched via `west init` + `west update` (all modules including STM32 HAL).
  - **Zephyr SDK**: v1.0.1 at `C:\Users\dengle\zephyr-sdk-1.0.1`. ARM toolchain (`arm-zephyr-eabi-gcc` 14.3.0, GNU ld 2.43.1) confirmed working. Host tools (QEMU/OpenOCD) not available for Windows from SDK — will install OpenOCD separately when needed for flashing via ST-Link.
  - **CMake package registry**: Zephyr and Zephyr-sdk registered via `west zephyr-export` + SDK setup.
- **Verification**: Built `samples/basic/blinky` for `nucleo_h753zi` (the exact prototyping board). Build succeeded: 159/159 compile steps, `zephyr.elf` linked, FLASH 19660 B (0.94%), RAM 4544 B (0.87%). Toolchain is fully operational.
- **Convenience script**: `scripts/activate-zephyr.ps1` in the phone repo — dot-source it (`. .\scripts\activate-zephyr.ps1`) to refresh PATH and activate the venv in a new terminal.
- **Known limitation**: Zephyr SDK Windows host tools (QEMU, OpenOCD) are "not available yet" per the SDK setup. For flashing the Nucleo (onboard ST-Link), install OpenOCD separately (e.g., via winget or xpack-openocd) before Phase 2 bring-up. Building works now; flashing needs this one extra step.
- **Next firmware steps** (no hardware needed): learn devicetree overlays + Kconfig for STM32H7, write AT command parser/URC handler, call state machine, keypad matrix scanner — all compilable against the `nucleo_h753zi` board target and flashable the day the board arrives.

### 2026-06-28: Keypad Selection
- **Decision**: **SMD tactile switches on custom PCB traces** for the final PCB keypad. **LOCKED.**
  - *Rationale*: Three switch technologies were evaluated for the final PCB: (1) SMD tactile switches on PCB traces — snappy, mechanical, individual parts, easy to source from DigiKey/Mouser/LCSC, no custom tooling; (2) conductive-rubber (silicone dome) keypad over PCB pad pairs — soft dome feel, sealed, most "phone-like" (classic feature-phone construction, e.g. Nokia 3310), but requires a custom silicone dome sheet (~$50–150 mold run from Chinese vendors, harder to source in prototype qty); (3) membrane keypad (PET/FPC stack) — thinnest, fully sealed, but flat feel and harder to source in small qty. SMD tactile selected for simplicity, sourcing, and alignment with the custom-PCB learning goal. The key matrix (5×4 = 9 GPIO for ~20 keys) is identical regardless of switch technology, so the schematic/GPIO allocation is unaffected by this choice.
  - *Key layout*: ~17–19 keys minimum per FR-2.1/FR-2.3 — 12 numeric (0–9, *, #) + 2 call/end + 3–5 nav (up/down/select or D-pad). 5×4 matrix (20 keys) cleanly fits with 1 spare.
  - *GPIO*: 5×4 matrix = 9 GPIO pins. Non-issue with 41 spare GPIO on LQFP-144.
  - *Cost*: ~20 SMD tactile switches at ~$0.05–0.10 each = ~$1–2. Cheaper than membrane or conductive-rubber alternatives.
  - *Tradeoff*: SMD tactile switches are not dust/water sealed (unlike conductive-rubber or membrane). Acceptable for a personal prototype/daily-driver; sealing can be revisited if needed via a silicone overlay sheet on top of the SMD switches.
- **Decision**: **Off-the-shelf 4×4 matrix keypad module + loose tactile buttons** for Phase 2 prototyping.
  - *Rationale*: A $2–5 4×4 matrix membrane module plus ~6–8 loose 6×6mm tactile buttons on a breadboard (for call/end/nav) enables immediate firmware development (matrix scan + debounce) with zero custom hardware. The electrical interface (matrix rows/cols → MCU GPIO) is identical to the final PCB, so no firmware rework when moving to the custom board.
  - *Tradeoff*: The prototyping keypad feel is unrelated to the final PCB keypad feel (SMD tactile). This is acceptable — Phase 2 validates firmware, not mechanical feel. Keypad feel is a Phase 7 (mechanical/enclosure) concern.

### 2026-07-18: UI Design Session

- **Context**: MVP complete (corrected criteria). Keypad + arbitrary dialing working on hardware. User wants to fix the UI and map out everything that should be part of it before adding more features (signal indicator, SMS, contacts). This is a design session — no code written yet, just decisions recorded.
- **Decision**: Both firmware and PCB schematic tracks in parallel. UI/firmware work in sessions; PCB schematic in between. Rationale: they're different kinds of work and don't block each other. The 2026-07-13 roadmap put PCB schematic next; this session adds a parallel firmware track (daily-driver features) without displacing PCB work.
- **Decision**: Full daily-driver UI screen map committed. Screens: idle/dialer, main menu, contacts (list/detail/add-edit), messages (list/conversation/compose), settings (deferred), in-call, incoming call. See `docs/ui-design.md` for the full map with ASCII diagram.
- **Decision**: Input model for the prototype 4×4 keypad — 2/8 as up/down in menus (Nokia-style feature-phone convention), A=select, B=back. Digits 2/8 double as nav in menu context and as digits in dialer context. Rationale: familiar to anyone who used a feature phone; the final PCB's 5×4 matrix will have dedicated nav keys, so this is a prototype-only mapping. Full key mapping table in `docs/ui-design.md`.
- **Decision**: Visual style — 80s sci-fi HUD as an explorative starting point (amber/orange on black, chunky borders, all-caps, vector icons, industrial/utilitarian vibe). User explicitly said "this will be an explorative process" — the visual style is not a fixed spec, it's a starting direction to iterate from on hardware. Three starting points were proposed (CRT terminal, cyberpunk neon, 80s sci-fi HUD); user chose HUD. See `docs/ui-design.md` Visual Style section.
- **Decision**: Contact storage — Zephyr settings subsystem for now (key-value in existing 256KB `storage_partition`). Simplest option, no filesystem setup, good for dozens of contacts. Rationale: user said "simplest version for now, and decide proper/better location later." Migrate to littlefs when we need SMS archives / call logs / hundreds of contacts. SMS storage leans on the SIM7600's own message store (read on demand via `AT+CMGR`).
- **New doc**: `docs/ui-design.md` created — screen map, persistent elements (status bar / content / soft-key labels), input model table, visual style direction, implementation notes. Living document — screen map and input model are stable; visual style evolves.
- **Next step**: Build the idle/dialer screen in the 80s sci-fi HUD style as the first explorative iteration. Get it on hardware, react, iterate. Then proceed to signal indicator, then menu skeleton, then contacts, then SMS.

### 2026-07-18: MVP Criteria Correction

- **Decision**: Move battery indicator and signal indicator out of the MVP column in `docs/problem-definition.md` (both changed from ✅ to ❌ in MVP, remain ✅ in Daily Driver).
  - *Rationale*: The MVP narrative and success criterion have always been "make and receive voice calls with intelligible audio on a US LTE network" — nothing more. The success criterion was achieved 2026-07-13. The table listing battery + signal indicators as ✅ in the MVP column was an inconsistency that contradicted the narrative and the success criterion. Signal indicator is daily-driver polish (doable now via `AT+CSQ`, but not required for MVP). Battery indicator is daily-driver polish blocked on PCB phase (MAX17048 fuel gauge needs battery power path). Neither blocks MVP completion.
  - *Impact*: **MVP is now fully complete** per the corrected criteria. All MVP-column items (make calls, receive calls, enclosure=test jig) are done. The 2026-07-13 roadmap entry that planned "complete all doable-now MVP items" was based on the inconsistent table — signal indicator is still worth implementing as a daily-driver feature, but it's no longer framed as MVP completion work.

### 2026-07-18: Keypad Integration — gpio-kbd-matrix + Dial String UI

- **Context**: Post-MVP roadmap (2026-07-13) identified 4×4 matrix keypad + arbitrary-number dialing as the next step. User has the Adafruit 4×4 membrane keypad (PID 3844) on hand. This session implements keypad input, dial string accumulation, and replaces the hardcoded `CALL_NUMBER` with a user-typed number.
- **Decision**: Use Zephyr's built-in `gpio-kbd-matrix` input driver (not a manual matrix scan).
  - *Rationale*: The driver handles scanning, per-key debouncing, ghost-key detection, and idle wake (interrupt mode) in its own thread. The app just receives `(col, row)` events via an input callback. This is the idiomatic Zephyr approach (the old `kscan` API was renamed to `input` in recent Zephyr), teaches the input subsystem (aligned with the project's learning goal), and requires **no firmware rework when moving to the custom PCB** — only the devicetree GPIO pins change. A manual scan would reinvent debounce/ghost-detection and be thrown away at PCB time.
- **Decision**: Pin assignment for the 4×4 matrix on the Nucleo Arduino headers (user-selected):
  - Rows: R1→D3 (PE13), R2→D4 (PE14), R3→D5 (PE11), R4→D6 (PE9) — inputs, pull-up, active-low
  - Cols: C1→A1 (PC0), C2→A2 (PC3), C3→A3 (PB1), C4→D2 (PG14) — outputs, active-low
  - *Rationale*: All 8 pins are free (not used by SPI1 display, LPUART1 modem, I2C1, USART3 console, B1 button, or ADC1 on A0). A1–A3 are Arduino analog-header pins but used as digital GPIO (the keypad needs digital I/O, not ADC). All 4 row pins support EXTI interrupts (required for the driver's `idle-mode = "interrupt"` wake).
- **Devicetree**: Added `kbd_matrix` node to `app.overlay` with `compatible = "gpio-kbd-matrix"`, 4 `row-gpios` + 4 `col-gpios`, `debounce-down-ms = <10>`, `debounce-up-ms = <20>`, `poll-timeout-ms = <100>`, `idle-mode = "interrupt"`. Added `CONFIG_INPUT=y` to `prj.conf` (the driver auto-selects via `DT_HAS_GPIO_KBD_MATRIX_ENABLED`, but the explicit config documents intent). Build verified: the driver bound to the node (`gpio_kbd_matrix_cb_0` + `gpio_kbd_matrix_init` in the linker map), devicetree compiled with correct pin flags (`0x11` = `GPIO_PULL_UP | GPIO_ACTIVE_LOW` on rows, `0x1` = `GPIO_ACTIVE_LOW` on cols).
- **Firmware architecture** (main.c):
  - **Input callback** (`keypad_callback`): registered via `INPUT_CALLBACK_DEFINE(DEVICE_DT_GET(DT_NODELABEL(kbd_matrix)), ...)`. Runs in the input subsystem thread (not ISR, not main loop). Captures `INPUT_ABS_X` (col) and `INPUT_ABS_Y` (row) on the ABS events, then on `INPUT_BTN_TOUCH` press (value=1, sync=true) looks up `keymap[row][col]` and puts the character into `key_msgq` via `k_msgq_put(..., K_NO_WAIT)`.
  - **Key event queue** (`K_MSGQ_DEFINE(key_msgq, sizeof(char), 16, 4)`): passes key characters from the input callback (driver thread) to the main loop (owns LVGL + modem). This is the thread-safety boundary — the callback never touches LVGL or the modem UART directly, avoiding cross-thread LVGL/modem calls. `k_msgq` is designed for cross-thread communication.
  - **Keymap** (`keymap[4][4]`): maps `(row, col)` → character per the Adafruit 4×4 membrane layout: row 0 = `1 2 3 A`, row 1 = `4 5 6 B`, row 2 = `7 8 9 C`, row 3 = `* 0 # D`.
  - **Dial string** (`dial_string[21]` + `dial_len`): replaces the hardcoded `CALL_NUMBER`. Digits `0-9/*/#` append (IDLE state only, max 20 chars), `C` backspaces, `A` triggers `ATD<dial_string>;` via `snprintf`, `B` hangs up / cancels / rejects, `D` is a no-op (menu, future).
  - **handle_key(char key)**: replaces `handle_button()`. State-dependent key actions: IDLE → digits append / A=call / C=backspace; CALLING → B=cancel; RINGING → A=answer / B=reject; CONNECTED → B=hang up.
  - **B1 button removed**: the Nucleo's user button (PC13) was the previous call control. Now redundant — A/B keys do the same things. Removed `gpio_dt_spec`, `gpio_callback`, `button_isr`, button init, and button polling from the main loop. Also removed `#include <zephyr/drivers/gpio.h>` (no longer needed — the input driver handles GPIO internally).
  - **Main loop**: drains `key_msgq` first (`k_msgq_get` with `K_NO_WAIT`), then processes modem URCs (`modem_readline`), then `lv_timer_handler()`. All LVGL and modem access stays in the main loop — no cross-thread issues.
- **Thread safety**: The input callback runs in the input subsystem thread. It only does `k_msgq_put()` (thread-safe by design). All LVGL calls, modem UART calls, and `call_state` transitions happen in the main loop (which drains the queue and processes URCs). `call_state` is read/written only in the main loop now — no race. The only cross-thread data path is `key_msgq`, which is purpose-built for that.
- **Build result**: Firmware compiles clean (exit 0, no warnings). Flash 333,956 B (15.92%), RAM 56,980 B (10.87%). Delta from before: +292 B flash (keymap, callback, handle_key, msgq plumbing), +80 B RAM (msgq buffer + dial string). The input driver + matrix library add ~5 KB flash (already counted in the first build with the overlay).
- **Not yet tested on hardware**: The firmware compiles and the driver binds, but the keypad wiring + functional test (press key → digit appears on display → type number → press A → call places) is the next step. The user has the keypad on hand.
- **Hardware test — FIXED and VERIFIED same day**: First flash showed `<err> input_gpio_kbd_matrix: Pin 0 interrupt configuration failed: -16` (EBUSY). Root cause: STM32 EXTI line conflict — our row 0 is PE13 (needs EXTI13), but the board DTS defines the B1 user button on PC13 (also EXTI13). STM32 EXTI lines 0–15 are port-shared (only one port per line), and the `gpio-keys` driver claimed PC13/EXTI13 first at boot, blocking PE13. Fix: added `&user_button { status = "disabled"; }` to `app.overlay` — we removed B1 from app code (keypad A/B replaced it), so disabling the board's button node frees EXTI13 for PE13. Build verified the `status = "disabled"` propagated to the compiled DTS. After reflash: clean boot, no `<err>` lines, keypad fully functional.
- **Functional test confirmed**: User typed `6077936142` (with a `123` typo cleared via C/backspace), pressed A → `ATD6077936142;` → `VOICE CALL: BEGIN` (connected in ~10s) → pressed B → `AT+CHUP` → `VOICE CALL: END: 000044`. **Real VoLTE call to an arbitrary user-typed number, no PC involvement, controlled entirely from the keypad + display.** This is the standalone-dialer milestone — the phone is no longer a hardcoded test jig.
- **Remaining MVP items**: Signal indicator (`AT+CSQ` polling + bars on idle screen) is the last doable-now MVP item. Battery indicator remains PCB-phase (MAX17048 fuel gauge needs battery power path — HAT's regulator prevents validation).

### 2026-07-13: Post-MVP Roadmap Planning
- **Context**: MVP success criterion achieved (place/receive VoLTE calls with audio). Reviewed remaining MVP feature table items and next-phase priorities with user.
- **MVP status audit**: The MVP feature table in `docs/problem-definition.md` lists four MVP items: make calls (done), receive calls (done), battery indicator (not done — blocked on PCB/MAX17048 fuel gauge), signal indicator (not done — doable now via `AT+CSQ`). Caller ID (`AT+CLIP=1`) is NOT a listed MVP item — it's an enhancement to "receive calls" (success criterion already met with hardcoded number on RINGING screen).
- **Decision**: Battery indicator deferred to PCB phase. Verified from SIM7600 HW Design Manual V1.03 §3.1 (Table 6: VBAT 3.4–4.2V, 2A peaks) and Waveshare HAT wiki that the current Nucleo+HAT setup has no battery path — the HAT's onboard regulator sits between USB 5V and the module's VBAT pins, and `AT+CBC` would monitor the regulator output (always ~3.8V), not a battery. The fuel gauge (MAX17048) needs to be in the battery's power path, which neither dev board provides. Power architecture (VBAT direct from LiPo, TPS630201 buck-boost, MAX17048, MCP73831) must be validated on the custom PCB following SIMCom's §3.1 reference circuit. No battery hardware ordered for prototyping.
- **Decision**: Next session (~90 min) targets completing all doable-now MVP items in one go:
  1. Wire 4×4 matrix keypad module to Nucleo GPIO (4 row + 4 col = 8 pins)
  2. Devicetree `kscan-matrix` node in app.overlay (Zephyr built-in driver handles debouncing)
  3. Keypad → dial string: 0-9/\*/# accumulate digits, A=Call (`ATD<number>;`), B=End (`AT+CHUP`), C=Backspace, D=Menu (future)
  4. LVGL dialer screen: typed digits shown on display, replaces hardcoded `CALL_NUMBER`
  5. Signal indicator: poll `AT+CSQ` periodically, render signal bars on idle screen
  - After this, MVP feature table is complete except battery indicator (PCB-phase).
- **Decision**: After MVP-complete session, priority is PCB schematic design (KiCad) — all component selections are locked. During PCB fab/assembly wait, parallel firmware track: AT command parser refactor (separate echo/response/URC), UART stress test (open item in requirements.md), multi-thread architecture (modem/UI/keypad threads), then daily-driver features (SMS, contacts).
- *Rationale*: The 2026-07-13 session demonstrated high throughput (7 milestones in one session). Keypad + arbitrary calling + signal indicator is achievable in a single ~90 min session. PCB schematic is the critical path to a standalone device — starting it immediately after MVP completion keeps the project moving toward the daily-driver goal. Filling the PCB fab lead time with firmware hardening avoids dead time.

### 2026-07-19: PCB Schematic Kickoff — Pre-Schematic Decisions
- **Context**: Phase 3 (Schematic Design) started. Approach chosen: **block-diagram-first (Option D)** — draw the system block diagram showing every block and the signals between them before opening the KiCad schematic editor, then implement it as a ~~hierarchical KiCad design (root sheet = block diagram, one sub-sheet per block)~~ **flat sheet structure with global labels** (**SUPERSEDED 2026-07-22** — board is ~30-40 parts, hierarchical overhead not worth it; see 2026-07-22 Schematic Approach entry). The block-diagram-first step is retained. This catches pin conflicts, missing level shifters, bus topology issues, and power-net count problems early. See `docs/block-diagram.md`.
- **Decision**: **Modem USB HS port — route to unpopulated connector footprint on rev1.**
  - *Rationale*: Preserves the locked modem-direct tethering architecture (RNDIS/ECM via `AT+CUSBPIDSWITCH`) without committing a 2nd populated USB connector. Reasons to keep the footprint beyond tethering: modem firmware updates (some versions only flash over USB), USB-based AT/diagnostics (higher bandwidth than UART), GNSS NMEA over USB (alternative to UART), and the future ecosystem (car module). Cost is small (footprint + 2 ESD diodes + short traces); the space is the real tradeoff. User wants this board to potentially be the final version, so preserving all options without a respin is worth the footprint area.
  - *Tradeoff*: Slightly larger board. Acceptable.
- **Decision**: **GNSS antenna — include U.FL footprint on rev1.**
  - *Rationale*: User wants this board to potentially be the final version. SIM7600 has built-in GNSS (validated 2026-07-12 on HAT — valid fix in ~60s cold start, works while registered on network). U.FL is a tiny SMD coaxial connector (~2mm) that connects the PCB to an off-board antenna via a short pigtail — standard for cellular/GPS modules. Low cost (~$0.50 for the connector + ~$2–5 for a GNSS antenna). Deferring would mean a respin to add it later.
  - *Tradeoff*: One RF trace + connector. Acceptable.
- **Decision**: **Loudspeaker — include earpiece + loudspeaker on rev1.**
  - *Rationale*: MAX9880A has stereo outputs — using both earpiece (call audio, held to ear) and loudspeaker (ringtones, speakerphone) costs nothing extra in codec capacity. BOM §3c already lists both. Speakerphone is rated 3 on the wishlist (nice to have) but the hardware cost is just the transducer + routing.
  - *Tradeoff*: Slightly more board area for the second transducer + its traces. Acceptable.
- **Decision**: **SIM + microSD connector — defer combo-vs-separate to sourcing; mark as a sourcing problem.**
  - *Rationale*: Combo SIM+microSD sockets save board space (common in phones) but are slightly harder to source. Separate sockets are easier to source with more placement flexibility but take more area. Both blocks appear in the block diagram either way. Decision will be made at the time of BOM finalization based on what's reliably sourceable from DigiKey/Mouser/LCSC. If a combo socket is reliably in stock at a reasonable price, use it; otherwise use separate sockets.
  - *Tradeoff*: Block diagram and BOM must accommodate both options until sourcing is settled.
- **Decision**: **USB-C connector type — formally locked (was effectively decided, pending formal lock per requirements.md Open Questions).**
  - *Rationale*: USB-C is strongly recommended for any new design (micro-USB is obsolete). 16-pin USB-C (USB 2.0) is sufficient — USB FS/HS only needs D+/D-. Moves from Open Questions to Resolved in requirements.md.

### 2026-07-19: SIM7600 Variant Selection for PCB — Part Name Correction + Footprint/Purchase Plan
- **Context**: Started assembling the KiCad parts library for the PCB. Needed to download the SIM7600 footprint from JLCPCB's parts library. Discovered two issues: (1) the locked part name "SIM7600A-H" doesn't exist in SIMCom's H-series lineup, and (2) the BOM's LCSC link (C2995537) pointed to the non-H `SIM7600A` — a different, older product with a different package.
- **Correction**: **"SIM7600A-H" was a misnomer.** SIMCom's actual H-series variants are: E-H (Europe), G-H (Global), NA-H (North America), SA-H (South America), JC-H (Japan/China). There is no "A-H". The intended part was always the North America H-series variant with B71 — which is **`SIM7600NA-H`**. The "A" was likely shorthand for "Americas"; the actual product code is "NA". The locked decision (NA H-series, B71, T-Mobile) is unchanged — only the part name was wrong in the docs since 2026-06-28.
- **Band comparison (from SIMCom product spec)**:
  | Variant | B71? | B66? | Package | Pins | JLC status |
  |---------|------|------|---------|------|------------|
  | SIM7600NA-H | ✅ | ✅ | LCC+LGA | 119 | Pre-order (C5380303, $31.42) |
  | SIM7600G-H R2 | ❌ | ✅ | LCC+LGA | 119 | In stock (C5355477, $46.95, 39 units) |
  | SIM7600SA-H | ❌ | ✅ | LCC | 87 | Pre-order (C17702592, $26.25) |
  | SIM7600E-H | ❌ | ❌ | LCC | 87 | In stock (C5338795, $39.05, 224 units) |
  - **B71 is only on NA-H.** B71 is T-Mobile's 600 MHz extended-range band — a locked requirement for in-building/rural coverage on Mint/T-Mobile. G-H (global) has the widest band set but is missing B71 specifically.
  - **Package matters**: NA-H and G-H are 119-pin LCC+LGA (same mechanical package). SA-H and E-H are 87-pin LCC (different package, different pad layout). The BOM's "LCC+LGA 30×30mm" matches only NA-H and G-H.
- **Decision**: **Purchase SIM7600NA-H via JLC pre-order (C5380303, $31.42).**
  - *Rationale*: Only variant with B71 (locked requirement). Same H-series 119-pin LCC+LGA package as the design intent. JLC pre-order means JLC sources it from SIMCom on demand — lead time ≤18 days = auto-proceed, >18 days = email confirmation. Part is stored in your private JLC library until the PCBA order. Can start PCB fab in parallel; SMT assembly waits for both board + part.
  - *Tradeoff*: 0 in stock — lead time unknown but bounded (JLC auto-proceeds if ≤18 days). Pre-order early (at schematic start) so it arrives while designing.
- **Decision**: **Download the SIM7600NA-H footprint from JLC (C5380303). Use SIM7600G-H (C5355477) as footprint fallback only if NA-H library data is incomplete.**
  - *Rationale*: NA-H is the exact part being purchased — cleanest to use its own footprint. G-H shares the identical 119-pin LCC+LGA package (verified from SIMCom product spec), so it's a mechanical stand-in if NA-H's CAD data is missing. Do NOT buy G-H for the board (lacks B71).
  - *Tradeoff*: None — footprint is the same either way. Using NA-H directly avoids a "footprint stand-in" mental note.
- **Disqualified variants**:
  - **SIM7600SA-H**: 87-pin LCC (different package from NA-H), no B71. Wrong package + wrong bands.
  - **SIM7600E-H**: 87-pin LCC, no B71, no B66. Europe variant — wrong package + wrong bands.
  - **SIM7600A (non-H, C2995537)**: Older product, 87-pin LCC. This is what the old BOM link pointed to — a documentation error. Different package from the H-series.
- **JLC pre-order mechanics** (from jlcpcb.com/help/article/what-is-jlcpcb-parts-pre-order-service):
  - Prepay for parts → JLC sources from SIMCom/LCSC → stored in your private JLC library (not shipped to you).
  - Lead time ≤18 days: JLC auto-proceeds. >18 days: email confirmation required (check email after ordering).
  - Parts only usable for PCBA orders — not shipped separately (pickup available but incurs fees).
  - Can place PCB fab order first and add pre-ordered parts to assembly order when they arrive (parallel workflow).
  - MOQ applies for non-stock extended parts (NA-H shows Min: 1, so qty 1 is fine).
- **Docs updated**: bom.md (part name, link, price, assembly method), constraints.md (consignment → pre-order, package info), AGENTS.md (key decisions), README.md, block-diagram.md (4 occurrences), research-notes.md (7 references), docs/reference/README.md. Historical/superseded decision text in project-log.md left as-is (the decision intent was always NA-H; only the name was wrong). Archived revisit-prompts not touched (historical artifacts).

### 2026-07-19: Parts Library Build — JLC/LCSC KiCad Models Downloaded + Assembly Method Locked
- **Context**: Started building the KiCad project-local parts library at `pcb/phone/lib/`. Needed footprints/symbols/3D models for all components before schematic work. Discovered JLC's parts library only offers EasyEDA format downloads, not KiCad — solved by using `easyeda2kicad` (Python tool, run via `uvx`) which fetches from LCSC C-numbers and outputs KiCad V6+ format.
- **Decision**: **Assembly method locked: JLCPCB PCBA, 2-board MOQ.**
  - *Rationale*: Evaluated JLC vs PCBWay vs NextPCB. JLC has the lowest MOQ (2 boards vs 5 for PCBWay/NextPCB Rev0), the only integrated parts library (LCSC C-number auto-matching at order time), and the cheapest assembly for LCSC-stocked BOMs. For 2 boards, JLC saves ~$100+ vs NextPCB (which forces 5 boards = 3 extra SIM7600 modules at $31 each). PCBWay has no parts library at all (manual RFQ model). Misconceptions corrected: "PCBWay allows single board" (backwards — JLC MOQ is 2, PCBWay is 5), "PCBWay has greater parts library" (backwards — JLC/LCSC is the industry exception).
  - *Tradeoff*: 2 parts not on JLC (MAX9880A, TPS630201) require consignment (buy from Mouser/DigiKey, ship to JLC). ~$8 shipping. Acceptable — far cheaper than the 3-extra-boards penalty at NextPCB.
- **Decision**: **Use OEM/brand-name parts where available on JLC.**
  - *Rationale*: Initial cart had TECH PUBLIC clones for USBLC6-2SC6 and ESDA6V1-5SC6. Swapped to ST originals (C7519, C6650) for quality/authenticity. Also swapped TXB0108DQSR (SON/leadless, clone-friendly) → TXB0108PWR (TSSOP-20, TI OEM, hand-solderable, matches block diagram).
- **Parts downloaded (12 total via `easyeda2kicad`)**:
  | Ref | Part | C# | Status |
  |-----|------|-----|--------|
  | U1 | STM32H743ZIT6 | C114408 | ✅ symbol+footprint+3D |
  | U2 | SIM7600NA-H | C5380303 | ✅ symbol+footprint (no 3D — pre-order part) |
  | U9 | TPS7A0218PDBVR | C3748843 | ✅ |
  | U11 | MCP73831-2ACI/MC | C150772 | ✅ |
  | U10 | MAX17048G+T10 | C2682616 | ✅ |
  | U3 | TXB0108PWR | C53406 | ✅ (PWR used — DGSR C44861261 failed EasyEDA API) |
  | U12 | TXB0104D | C1549752 | ✅ |
  | D1 | USBLC6-2SC6 | C7519 | ✅ (ST OEM, swapped from TECH PUBLIC clone) |
  | U6/U7 | ESDA6V1-5SC6 | C6650 | ✅ (ST OEM, swapped from TECH PUBLIC clone) |
  | — | 100nF 0603 cap (YAGEO) | C14663 | ✅ |
  | — | 10uF 0805 cap (muRata) | C440198 | ✅ |
  | — | Blue LED 0603 (LITEON) | C99290 | ✅ |
- **Parts NOT on JLC (need Ultra Librarian + Mouser/DigiKey consignment)**:
  - U5: MAX9880AETM+T (ADI audio codec) — not on LCSC
  - U8: TPS630201 (TI buck-boost) — not on LCSC (only TPS63020DSJR, different part)
- **Remaining parts (need JLC part selection or design decisions)**: Created revisit prompt `docs/revisit-prompts/parts-sourcing-revisit.md` documenting all open items: 2 ICs (Ultra Librarian), 8 mechanical parts (connectors, switches, transducers, crystal, inductor), 3 design decisions (J2 modem USB type, J3/J4 SIM+SD combo vs separate, J7 display panel pick). See the revisit prompt for the full list and workflow.
- **Docs updated**: `pcb/PARTS_TRACKING.md` (sourcing status for all parts), `pcb/JLCPCB_BOM.xls` (C-numbers filled in for downloaded parts), `docs/revisit-prompts/README.md` (new active prompt), `docs/revisit-prompts/parts-sourcing-revisit.md` (created).

### 2026-07-19: Keypad Switch Selection — ALPS SKQGABE010 (LOCKED)
- **Context**: Working through `docs/revisit-prompts/parts-sourcing-revisit.md` item B5 (SW1–SW20). The keypad *technology* (SMD tactile on PCB traces, 5×4 matrix) was locked 2026-06-28; what was open is the *specific switch part*. User-driven selection process — user defined the constraints (force, lifecycle, package, height, travel) and proposed candidate parts; agent verified specs against datasheets/JLC stock and confirmed the fit.
- **User-defined requirements (settled in discussion)**:
  - **Force**: 160–180gf (1.57–1.77N) — classic phone keypad range.
  - **Lifecycle**: "more is better" → agent recommended 300K min, 1M if cheap. User accepted 1M target.
  - **Package**: smaller is better (denser layout).
  - **Height**: minimize — thinness is the dominant enclosure constraint.
  - **Travel**: agent recommended 0.25–0.35mm for numeric keypad comfort; user accepted 0.25mm to win thinness + 1M cycle life.
  - **Board location**: main board (base) — keypad is on the main board in the flip architecture (LOCKED 2026-07-19). The display daughterboard (lid) has only the display + outer OLED + earpiece speaker.
- **Decision**: **ALPS Alpine SKQGABE010** (LCSC C115351).
  - *Specs*: 5.2×5.2×1.5mm SMD, 1.57N (160gf) operating force, 0.25mm travel, 1,000,000 cycle life, SPST-NO top-actuated, gull-wing, rated 50mA @ 12V (way overkill for a keypad matrix signal). Operating temp −40 to +90°C. ALPS OEM (project principle: brand-name preferred ✓).
  - *Sourcing*: LCSC C115351 — 41,590 in stock at LCSC, 1,344 in stock at JLC for PCBA. Price $0.089 @ 50+ qty → ~$3.50 for 40 switches (2 boards × 20 + overage). JLC has it as a basic/extended part — confirm at order time, but C115351 is the LCSC number.
  - *KiCad library*: Downloaded via `uvx easyeda2kicad --full --lcsc_id=C115351 --output "pcb/phone/lib"`. Symbol `SKQGABE010` in `easyeda2kicad.kicad_sym`, footprint `KEY-SMD_4P-L5.2-W5.2-P3.70-LS6.4`, 3D model `KEY-SMD_4P-L5.2-W5.2-H1.5-LS6.4-P3.70` (.wrl + .step).
- **Rationale (why this part over alternatives)**:
  - Evaluated against the Panasonic EVQPL series (C79172, 4.9×4.9mm, 0.8/1.5mm height, 500K–2M cycles, 0.25mm travel) — comparable specs, but user preferred the ALPS SKQG footprint (5.2×5.2mm gull-wing is a more standard JLC assembly package than EVQPL's film-scratch-sensitive push-plate design).
  - Beats the 6×6×3.5mm C&K PTS645 class the revisit prompt pre-loaded: smaller footprint (5.2 vs 6mm), thinner (1.5 vs 3.5mm = 2mm stackup saved), higher lifecycle (1M vs 300K), same force target (160gf). Tradeoff: less travel (0.25 vs ~0.35mm).
  - 1M cycle life = 10× the 100K minimum math (heavy texter ~200 presses/day × 3 years ≈ 220K on the most-used key). Comfortable margin even allowing for gradual dome fatigue.
- **Tradeoffs accepted**:
  - **0.25mm travel** is at the low end of the numeric-keypad-comfortable range (smartphone side-button class, not feature-phone class). Accepted to win 1.5mm height + 1M cycles. Mitigation: the SKQG series has 3.1mm, 3.4mm, and 5.0mm stem-height variants on the **same 5.2×5.2mm footprint** — if the first build feels too snappy, swap up without respinning the PCB.
  - **Non-washable marking** on the datasheet — investigated and confirmed non-issue for JLC PCBA. JLC's standard flow uses no-clean flux and only washes "when applicable" (their after-sales FAQ: residue is "normal and acceptable ... safe for use"). The "non washable" marking is industry-standard conservative text that appears even on IP67-rated sealed switches (e.g., Panasonic EVPBV, EVPAW) — it's about the wash process, not ambient moisture. No special JLC order notes needed.
  - **Unsealed** (no IP rating) — consistent with the locked keypad decision (SMD tactile accepted as unsealed for prototype; sealing is a Phase 7 silicone-overlay concern).
- **What is NOT decided here** (deferred as before):
  - Side buttons (power, volume) — not in the revisit prompt's SW1–SW20 scope; would be a different switch family (side-actuated). Revisit at schematic time.
  - Keycap / overlay design — Phase 7 (mechanical/enclosure).
  - Specific key layout / matrix mapping beyond "5×4, 20 keys" — schematic-time decision.
- **Docs updated**: `pcb/PARTS_TRACKING.md` (SW1–SW20 row filled in, decision #3 marked resolved), `docs/constraints.md` (Keypad section — specific part added), `docs/bom.md` (§3g keypad row — specific part + C#), `docs/revisit-prompts/parts-sourcing-revisit.md` (B5 marked resolved), `docs/revisit-prompts/README.md` (parts-sourcing prompt summary updated to reflect partial progress).

### 2026-07-19: U8 Buck-Boost Correction — TPS630201 → TPS63021DSJR (LOCKED) + U5 MAX9880A Integrated
- **TI's actual buck-boost lineup (verified via TI.com + datasheet SLVS916I)**:
  - **TPS6302x family** (4A switches, ~3A output, VSON-14 / DSJ package, 3×4mm with exposed pad): TPS63020 = adjustable, **TPS63021 = fixed 3.3V**. This is the family the project wants.
  - **TPS6300x family** (1.8A switches, ~1.5A output, VSON-10 / DRC package, 3×3mm): TPS63000/1/2. Lower current — not what the project needs.
  - There is **no 4A part in the DRC package**. The revisit prompt's "DRC VQFN-10 4A" spec was impossible.
- **Decision**: **U8 = TPS63021DSJR** (LCSC C202140). **LOCKED 2026-07-19.**
  - *Specs*: Fixed 3.3V output (matches BOM spec exactly — no external feedback divider needed), 4A switch current limit, ~3A output current in buck mode (exceeds the BOM's "2A" spec with headroom), Vin 1.8–5.5V (covers LiPo 3.0–4.2V range), 2.4MHz fixed-frequency PWM, VSON-14 (DSJ, 3×4mm) with exposed pad. TI lists it as **Active Production**.
  - *Sourcing*: LCSC C202140 — user confirmed in stock at JLC for PCBA (LCSC web page showed "Out of stock" but JLC's assembly stock can differ; user verified directly). **This eliminates U8 as a consignment part** — it can go through normal JLC PCBA assembly. Only MAX9880A remains as a consignment part (Mouser → JLC).
  - *KiCad library*: Downloaded via `uvx easyeda2kicad --full --lcsc_id=C202140 --output "pcb/phone/lib"`. Symbol `TPS63021DSJR` in `easyeda2kicad.kicad_sym`, footprint `VSON-14_L4.0-W3.0-P0.50-BL-EP_TI_DSJ` (confirms DSJ package, 4×3mm, 0.5mm pitch, exposed pad), 3D model `VSON-14_L4.0-W3.0-H1.0-P0.50` (.wrl + .step).
- **Alternative considered (TPS63020DSJR, C15483)**: Adjustable version, in stock at LCSC, same DSJ package. Would need 2 external resistors to set 3.3V output. Rejected because TPS63021 (fixed 3.3V) matches the BOM spec exactly and is available at JLC — no reason to add a feedback divider when the fixed-output variant is sourced.
- **U5 MAX9880A integrated**: User downloaded the Ultra Librarian KiCad v6 package for MAX9880AETM+T. Files integrated into `pcb/phone/lib/`:
  - ~~Symbol: `lib/symbols/ultralibrarian.kicad_sym`~~ **Removed 2026-07-22** (library rebuild — MAX9880A superseded by ALC5651, ultralibrarian files deleted to avoid confusion).
  - ~~Footprint: `lib/footprints.pretty/21-0141I_T4866-1_MXM.kicad_mod`~~ **Removed 2026-07-22** (same reason).
  - 3D model: **Not available** from Ultra Librarian for this part.
  - *Sourcing*: Still needs Mouser consignment — MAX9880AETM+T is not on LCSC. BOM has Mouser stock (2,250 units, $2.23 qty 1). Buy from Mouser, ship to JLC with the PCB fab order.
- **Impact on assembly**: Consignment parts reduced from 2 → 1 (only MAX9880A). Simplifies JLC ordering — one consignment shipment instead of two.
- **Revisit prompt status**: A1 (MAX9880A) and A2 (TPS63021) both resolved. Parts-sourcing prompt now 3 of 13 items resolved (B5 switches, A1, A2). Next priority per the prompt: C13 (display panel pick, blocks J7), then B7 (L1 inductor — now needs TPS63021 datasheet specs, not the phantom TPS630201).
- **Docs updated**: `pcb/PARTS_TRACKING.md` (U5 + U8 rows filled in, L1 row + decision #8 reference updated), `docs/bom.md` (item 10 part number/link/notes + verification checklist), `docs/constraints.md` (Power section), `docs/research-notes.md` (component table), `docs/block-diagram.md` (3 occurrences), `AGENTS.md` (Power architecture key decision), `docs/revisit-prompts/parts-sourcing-revisit.md` (A1/A2 marked resolved, B7 L1 spec reference corrected), `docs/revisit-prompts/README.md` (parts-sourcing summary updated). Historical entries in project-log.md (2026-06-28 documentation review, 2026-07-19 parts library build) left as-is per the SIM7600A-H→NA-H precedent — the decision intent was always "fixed 3.3V buck-boost"; only the part number was wrong.
- **`pcb/JLCPCB_BOM.xls` deleted**: Binary Excel BOM was stale (last modified 2026-07-19 14:04, before today's U5/U8 corrections) and redundant with `pcb/PARTS_TRACKING.md`, which is now the single source of truth for C-numbers and sourcing status. The XLS will be regenerated from PARTS_TRACKING.md at JLC order time (JLC's PCBA order form accepts a CSV upload anyway — an .xls is not the right format for that). References in the revisit prompt updated to point only to PARTS_TRACKING.md. Historical project-log.md entry (2026-07-19 parts library build) left as-is per the no-rewrite-history rule.

### 2026-07-19: ~~Outer Display Selection — Wisevision N114-2413THBIG01-H13 (LOCKED)~~

**SUPERSEDED 2026-07-19**: The Wisevision N114 panel uses a **0.7mm FPC pitch**, which is not a standard connector pitch — no 0.7mm ZIF connectors are stocked on LCSC/JLCPCB. This made J10 unsourceable for JLC assembly. Replaced by the EastRising ER-TFT1.14-2 (BuyDisplay), which uses a standard 8-pin 0.5mm FPC. See "2026-07-19: Outer Display Re-Selection — ER-TFT1.14-2" entry below.

- **Context**: The flip form factor (locked 2026-07-19) calls for an outer display on the lid for closed-phone info (time, caller ID, notifications). Initially explored small I2C OLED (SSD1306/SH1106/SH1107). The user-sourced candidate (Newvisio N130-6428TSWOG01-H13, C2890613) was a raw SH1107 OLED panel requiring 9V VPP (external boost converter on the daughterboard) — adding significant complexity to what was supposed to be a trivial daughterboard. Pivoted to small TFT panels, which run on 3.3V only (transmissive display, no high voltage).
- **Decision**: ~~**Outer display = Wisevision N114-2413THBIG01-H13** (LCSC C2890618). **LOCKED 2026-07-19.**~~ **SUPERSEDED** — 0.7mm FPC pitch has no JLC-stocked connectors.
  - *Specs*: 1.14" IPS TFT, 240×135 (landscape), ST7789V3 controller (**same driver family as the main display** — Zephyr `solomon,st7789v`), 4-wire SPI, 65K color. Outline 17.6×31.0×1.6mm. Active area 14.86×24.91mm. 13-pin FPC. Backlight: 1 white LED, 3.2V, 20mA (PWM dimmable). Supply 2.4–3.3V (3.3V rail compatible). Brightness 400 cd/m². IPS full viewing angle.
  - *Sourcing*: LCSC C2890618 — **463 in stock**, $2.54 qty 1, $2.14 qty 10. Wisevision/Newvisio OEM. EasyEDA footprint available.
  - *Why TFT over OLED*: Raw OLED panels need 7-16V VPP (external boost converter + support components on the daughterboard — ~10-15 extra components). Raw TFT panels run on 3.3V only — daughterboard stays trivial (ZIF connector + decoupling cap). The ST7789V3 controller is the same family as the main display's ST7789T3, so the same Zephyr driver (`display_st7789v.c`) handles both — just different CS/DC pins.
  - *Hinge flex impact*: Shares the SPI bus with the main display. Only 2 new hinge flex signals (CS2, DC2). RST can be shared. Backlight can tie to 3.3V or share the main display's PWM. Hinge flex stays at ~14 pins.
- **Alternatives evaluated**:
  - **Newvisio N130-6428TSWOG01-H13 (C2890613)** — 1.3" SH1107 OLED, I2C. Rejected: requires 9V VPP external supply (boost converter on daughterboard). 13-pin complex pinout (VPP, VCOMH, IREF, IM1). Adds ~10-15 daughterboard components. Defeats the "trivial daughterboard" design goal.
  - **HS HS96S01A (C7471924)** — 0.96" ST7735 TFT. Rejected: turned out to be a breakout board (with PCB), not a raw panel. Too thick for a flip phone lid.
  - **4-pin I2C OLED breakout modules** (Adafruit 938, etc.) — have onboard charge pump (no external VPP), but are thick (~6-11mm with PCB + components). Too thick for a flip phone lid.
- **What is NOT decided here** (deferred):
  - ~~**J10 ZIF connector** — 13-pin, pitch TBD from datasheet (likely 0.7mm based on similar Wisevision panels). Source from LCSC.~~ **SUPERSEDED** — 0.7mm pitch not available on LCSC/JLC. See ER-TFT1.14-2 re-selection below.
  - ~~**Exact FPC pinout** — need to download datasheet and verify 13-pin pinout (LED+, LED-, VCC, GND, SCL, SDA, DC, CS, RST, etc.).~~ **Verified then superseded.**
  - **KiCad model** — download via easyeda2kicad.
- **Docs updated**: `docs/project-log.md` (this entry + progress tracking), `docs/bom.md` (new item 7c), `docs/constraints.md` (Form Factor section — outer display specified), `docs/block-diagram.md` (hinge flex table + daughterboard description), `pcb/PARTS_TRACKING.md` (J10 updated), `AGENTS.md` (outer display key decision).
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

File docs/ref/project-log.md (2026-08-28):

---
status: reference
updated: 2026-08-27
---
# Project Log

## User Background

- Senior year Computer and Systems Engineering student.
- Experience level: between "some hardware experience" and "moderate hardware" — has worked with microcontrollers and designed a few simple PCBs.
- Wants this project to push beyond prior experience into RF, cellular comms, power management, and multi-discipline integration.
- Open to simplifying initial versions but wants the overall project to be challenging and time-consuming.
- Has access to FDM, SLA, and CNC for enclosure fabrication.

## Decision Log

### 2026-08-27: Display Sheet Review — J_DISP1 Pinout Corrected, Backlight FET Added, Sheet LOCKED

- **Context**: During the display restructure (candybar pivot, daughterboard removal), a netlist review revealed that J_DISP1's pinout was almost entirely wrong — only 1 of 12 pins matched the HS20HS072RX datasheet. The backlight FET circuit (§F) was also missing.
- **Pinout correction**: J_DISP1 rewired to match HS20HS072RX datasheet page 11 (SPI 4-wire interface, confirmed against ST7789V §8.4 — SCL=SCK, SDA=MOSI, no I2C support in ST7789 at all). All 14 pins (12 signal + 2 mechanical GND) verified correct via netlist extraction. Pin 7 (NC) has no-connect flag. Pins 8/9 (I/O-VCC, VCC) on +3.3V (not +1V8 — 1.8V is below VCC's 2.4V minimum). Pin 10 (LEDA) via R19 from +3.3V. Pin 11 (LEDK) to FET drain.
- **Backlight FET circuit added**: Q1 (AO3400A, N-ch MOSFET, LCSC C20917) — drain → LEDK (pin 11), source → GND, gate → BL_PWM (MCU PA8) via R20 (100Ω gate resistor, LCSC C22775) + R5 (10kΩ gate pulldown to GND, ensures backlight OFF during MCU reset). R19 (4.7Ω current-limit) between +3.3V and LEDA (pin 10). R19 value verified against datasheet: 4 parallel white LEDs, Vf=3.0V, IL=80mA → R = (3.3−3.0)/0.080 = 3.75Ω, 4.7Ω gives ~64mA (safe, slightly dimmer).
- **R19 MPN fix**: R19 was using symbol `RC0603JR-07470RL` (470Ω part) with value field `4R7` (4.7Ω) — MPN and value disagreed. Downloaded correct part `RC0603JR-074R7L` (4.7Ω, LCSC C137621) and swapped symbol in schematic.
- **New library parts added**: `ics:AO3400A` (MOSFET), `passives:0603WAF1000T5E` (100Ω gate resistor). Both downloaded via easyeda2kicad, pin types fixed, footprints corrected to `easyeda2kicad:` convention.
- **ERC**: 0 violations on display sheet. Only warnings are pre-existing `isolated_pin_label` for EARPIECE+/- (codec sheet not wired yet).
- **Sheet LOCKED**: Display sheet is now locked. Any change requires explicit approval + project-log entry per `pcb/AGENTS.md` rule 9.
- **⚠️ Layout review note**: FPC connector orientation (pin 1 side, contact-side vs solder-side, FPC insertion direction) must be re-reviewed during PCB layout (Phase 4). The schematic doesn't encode mechanical orientation — a 180° rotation or wrong contact-side would mirror the pinout and break everything. Check against HS20HS072RX datasheet §5 (Module Outline Dimension).
- **Docs updated**: This entry, `docs/work/schematic-completion-plan.md` (§F → LOCKED, sheet status table), `docs/datasheets/README.md` (pinout confirmed — already correct in README, schematic was wrong).

### 2026-08-27: Power Switch Back on EN Pin — OS102011MA1QN1 Selected

- **Decision**: Move the power switch **back to the TPS63021 EN pin** (signal-level) and select **C&K OS102011MA1QN1** (SPDT slide switch, through-hole right-angle, 100mA, LCSC C226259) as SW21. This reverses the 2026-08-17 battery-path architecture.
  - *Switch wiring*: SW21 pin 2 (common) → U8 EN pin; pin 1 → R21 (1MΩ) → +BATT (ON position: EN sees +BATT through 1MΩ); pin 3 → GND (OFF position: EN pulled low). Pins 4/5 (mounting) → GND.
  - *Part rationale*: The previous part (SSSS811101, ALPS SMD, 6.7×2.6×**1.4mm** height) was too thin to actuate comfortably as a finger-operated power switch. The OS102011MA1QN1 has an **8.4mm actuator height** — usable as a proper power toggle. Through-hole right-angle is also easier to hand-solder than the SMD SSSS811101. Since the switch is now on the EN pin (signal-level, microamps), the 100mA current rating is sufficient — no need for a power-rated ≥3A switch.
  - *Architecture tradeoffs vs 2026-08-17 (battery path)*:
    | | 2026-08-17 (battery path) | Now (EN pin) |
    |---|---|---|
    | Switch rating needed | ≥3A (power) | 100mA (signal) ✅ |
    | Charging while off | ❌ Lost | ✅ Restored |
    | Hard kill (battery disconnect) | ✅ | ❌ Lost |
    | Fuel gauge when off | Off (0 draw) | On (small quiescent drain) |
    | Modem when off | Off (no +BATT) | Off (no +3.3V — modem is on +3.3V via MPCIe) |
  - *What stays the same*: Soft off is still MCU STOP mode via inactivity timer (firmware-deferred). R21 (1MΩ) pullup to +BATT is present but now switched through SW21 rather than permanently on EN.
- *Supersedes*: 2026-08-17 Power Switch Simplification decision (battery-path switch). The battery-path architecture is reversed — the switch returns to the EN pin, the battery is always connected to +BATT, and the switch part is signal-rated (100mA) not power-rated (≥3A). The 2026-08-17 rationale (simplicity of hard battery disconnect) is replaced by the practical need for a usable actuator and the restored ability to charge while off.
- *Note on intermediate SSSS811101*: The SSSS811101 was placed in the committed schematic as the battery-path switch but was never documented in `docs/ref/bom.md` or this log (item 25b remained "TBD"). It was rated 0.3A — also under-spec for the battery path. The OS102011MA1QN1 replaces it before any docs or fab committed the under-spec part.
- **Docs updated**: This entry, `docs/ref/bom.md` (item 25b — part selected), `docs/work/block-diagram.md` (+BATT net + U8 EN pin), `docs/work/task-tracker.md` (O2).

### 2026-08-27: USB Hub on Rev1 — Ecosystem Is a Hard Requirement, Single USB-C Port

- **Decision**: Make the USB ecosystem interconnect a **hard rev1 hardware requirement**. Add an **internal USB 2.0 HS hub** (USB2512-class, 2-port) on rev1 so a **single USB-C port** presents both the modem (RNDIS/ECM for LTE tethering at HS 480 Mbps) and the MCU (MSC for files / CDC ACM for debug at FS 12 Mbps) to an external USB host (e.g., the car module). No second physical USB port.
  - *Rationale*: The user wants ecosystem connectivity on rev1, not a future respin. Two physical USB ports is not an acceptable option (one port, clean enclosure). The 2026-06-28 USB HS/ULPI Revisit already established that the modem does its own tethering (no MCU bridging, no ULPI) — the only open question was *how* to get two USB devices behind one port. A USB 2.0 hub is the standard, transparent, low-cost answer (~$1.20 for USB2512 + ~$0.30 crystal + a few passives). The hub handles the HS/FS speed mismatch via its transaction translator — each downstream port negotiates independently.
  - *Topology*:
    ```
    USB-C (USBC1) ──ESD (USBLC6-2)──┬── Hub upstream (USB2512, HS)
                                     │
                              Hub downstream 1 ─── Modem USB (MODEM_USB_DP/DN, HS 480Mbps, RNDIS/ECM)
                              Hub downstream 2 ─── MCU USB OTG_FS (FS 12Mbps, MSC/CDC ACM)
    ```
  - *What changes from the 2026-06-28 decision*: The "Rev1: route modem USB to connector footprint; future respin adds hub" split is collapsed — the hub is on rev1. The core of the 2026-06-28 decision (drop ULPI, modem does its own tethering, MCU USB is FS-only) is unchanged. Only the hub timing moves forward.
  - *Schematic impact* (user handles all KiCad per 2026-08-16 workflow role change):
    - **USB-C connector (USBC1)**: No physical change — same 16-pin USB-C, same VBUS→MCP73831 charger path, same CC1/CC2 5.1kΩ pull-downs, same USBLC6-2 ESD on D+/D-/VBUS. The connector doesn't care what's downstream.
    - **D+/D- routing**: After ESD, D+/D- now route to the **hub upstream port** (instead of directly to MCU OTG_FS). This is a net destination change on the Power sheet (where USBC1 lives) — the `USB_DP`/`USB_DN` global labels now target the hub.
    - **New component**: USB2512 (2-port HS hub, QFN-24) + 24MHz crystal + decoupling caps + reset (RC power-on reset or 1 MCU GPIO). Hub powered from +3.3V (phone on). Hub VBUS_DET taps the existing `VBUS` net (via divider — VBUS_DET is 3.3V logic, VBUS is 5V; can share the MCU's existing VBUS sense divider node or get its own).
    - **Modem USB (pins 36/38)**: Now routed to hub downstream 1 (was marked NC — now connected). No ESD needed on-board (short traces, ESD is upstream at the connector).
    - **MCU USB OTG_FS**: Now routes to hub downstream 2 (was direct to USB-C). No ESD needed on-board (same reasoning).
    - **New sheet or section**: Hub likely gets its own schematic sheet or lives on the modem sheet (near the modem USB pins). User decides during schematic entry.
  - *BOM impact*: +USB2512 (~$1.20) + 24MHz crystal (~$0.30) + ~4 passives (~$0.10). Item 17b (second USB-C connector footprint, unpopulated) is **dropped** — no second port. Net BOM change: ~+$1.60, -$0 (17b was $0 unpopulated).
  - *Firmware impact*: None for the hub itself — it's transparent hardware. The MCU still enumerates as a USB device, just through a hub. The MCU controls whether the modem's USB is active via `AT+CUSBPIDSWITCH` over UART — when connected to a PC for firmware updates, the modem's RNDIS interface can be disabled (MCU just sees the hub + itself). The hub is powered whenever the phone is on (+3.3V), which is the only time ecosystem tethering makes sense (modem must be alive).
  - *What is lost*: MCU USB OTG host mode (the MCU can never be a USB host with the hub inline). The project never needed this — the MCU is always a device. No real loss.
  - *What is gained*: Single USB-C port, ecosystem-ready on rev1, modem tethering at full HS (480 Mbps, no MCU bottleneck), simultaneous LTE + file access over one cable, no future respin needed for ecosystem.
  - *Supersedes*: The "Rev1 (minimal commitment): route modem USB to connector footprint; Future ecosystem respin: add internal USB hub" topology split in the 2026-06-28 USB HS/ULPI Revisit decision. The hub moves from future to rev1. The drop-ULPI / modem-direct-tethering / MCU-FS-only core of that decision is retained.
- **Docs updated**: This entry, `docs/ref/requirements.md` (FR-9 ecosystem → rev1 hard req + resolved questions), `docs/ref/bom.md` (add USB2512 + crystal, drop item 17b, cost summary), `docs/ref/problem-definition.md` (tethering architecture + risk 6), `docs/work/block-diagram.md` (USB data path topology), `docs/work/schematic-completion-plan.md` (§C modem USB + new hub work + §B MCU USB routing), `docs/work/task-tracker.md` (USB wiring items), `AGENTS.md` (Key Decisions table).

### 2026-08-27: U9 (TPS7A0218PDBVR) Schematic Review — All Checks Pass

- **Context**: User requested a schematic review around U9 (1.8V LDO, TPS7A0218PDBVR). The datasheet was missing from `docs/datasheets/` — downloaded TI SBVS277C (Rev. C, Sep 2022) as `tps7a02.pdf` and added to the datasheet index per the doc-maintain rule.
- **Review method**: kicad-inspector subagent (read-only) — ran ERC + extracted netlist, verified all 5 pins, Cin/Cout, EN connection, NC status, and footprint against the datasheet.
- **Result**: All 6 checks PASS. No issues found.
  - Pin mapping: 1=IN→+3.3V, 2=GND, 3=EN→+3.3V (always-on, tied to IN via shared rail), 4=NC (floating, acceptable), 5=OUT→+1V8. ✅
  - Cin = C35 (1µF X5R 0603), Cout = C36 (1µF X5R 0603) — both meet datasheet requirements. ✅
  - Footprint = SOT-23-5 (easyeda2kicad:SOT-23-5_L2.9-W1.6-P0.95-LS2.8-BL). ✅
  - ERC: 0 of 100 total violations touch U9 or its nets. ✅
- **EN always-on confirmed**: Consistent with the locked 2026-07-21 decision (ALC5651 §7.1 — cutting 1.8V while 3.3V stays up causes leakage; standby handled via I2C registers).
- **Doc fix**: `docs/work/block-diagram.md` line 86 had "OUT (pin 1)" — corrected to "OUT (pin 5)". Pin 1 is IN, pin 5 is OUT per the DBV/SOT-23-5 datasheet pinout. The detailed U9 pinout table (lines 264-270) was already correct.
- **Docs updated**: `docs/datasheets/README.md` (tps7a02.pdf indexed), `docs/work/block-diagram.md` (pin number fix), `docs/work/ic-by-ic-review.md` (U9 section added, status → ✅ Pass, change log entry).

### 2026-08-17: Power Switch Simplification — Hard Switch + MCU Sleep Timer

> **SUPERSEDED 2026-08-27**: The battery-path switch architecture is reversed — the switch moves back to the EN pin (signal-level), and the part changes from a power-rated TBD to C&K OS102011MA1QN1 (100mA, signal-level). See "2026-08-27: Power Switch Back on EN Pin" entry above. The text below is retained for history — do not reference it as the active power switch decision.

- **Decision**: ~~Replace the 2026-08-02 power switch architecture (momentary switch + latch circuit, soft/hard off + unified power on) with a simple **maintained power switch in the battery path** + **MCU inactivity timer for soft off**.~~ **SUPERSEDED 2026-08-27**: Switch returns to EN pin. Battery always connected to +BATT.
  - *Hard off*: ~~Maintained (latching) switch physically disconnects the battery from the +BATT net. 0 power draw. Phone is fully dead — no rail, no modem, no fuel gauge, no charger. Flip the switch back to power on.~~ **SUPERSEDED 2026-08-27**: No hard battery disconnect. Switch disables TPS63021 via EN pin. Battery stays connected — charging works while off, fuel gauge stays powered.
  - *Soft off*: MCU inactivity timer puts the phone to sleep (STOP mode) after a period of no user activity. Firmware-driven. All firmware behavior details (modem sleep state, wake sources, timer duration, graceful shutdown sequence, whether the phone stays reachable for incoming calls) are **deferred until after PCB is ordered**.
  - *Switch location*: ~~Between battery connector (J_BATT) and the +BATT net. Everything downstream (TPS63021, MAX17048, MCP73831 VBAT, modem) connects to +BATT, which is after the switch. Switch must be power-rated (≥3A — TPS63021 can draw 2A+ during LTE TX bursts). Specific part TBD at schematic time.~~ **SUPERSEDED 2026-08-27**: Switch is on the TPS63021 EN pin (signal-level). Part: OS102011MA1QN1 (100mA, sufficient for EN pin).
  - *TPS63021 EN pin*: ~~Reverts to always-on (1MΩ pullup to +BATT). When the switch closes, +BATT appears, EN rises via pullup, rail comes up. No switch on EN.~~ **SUPERSEDED 2026-08-27**: EN is switched by SW21 between +BATT-through-1MΩ (ON) and GND (OFF). R21 (1MΩ) is in series with the switch, not a permanent pullup on EN.
- *Rationale*: Simplicity. The 2026-08-02 latch circuit architecture was over-engineered for a single-board hobby project. A physical battery disconnect is the simplest possible hard off — one component, no latch, no RC timer, no MCU involvement. Soft off via firmware timer is the simplest possible standby. The user explicitly chose simplicity over the 3-function power button model.
- *What is lost*:
  - Charging while off (switch disconnects battery from charger VBAT path). Accepted by user.
  - Graceful shutdown on hard-off (modem gets power-yanked). SIM7600 is robust to power loss; acceptable.
  - No "unified power on from both states" — power on is always via the physical switch (flip on). Soft off wake is firmware-driven (deferred).
  - No 5-second hardware kill for hung MCU — flipping the switch IS the kill (it's a hard disconnect, works unconditionally).
- *What changes*:
  - **No latch circuit needed** — DEF-002 is moot.
  - EN pin reverts to always-on (1MΩ pullup to +BATT, as originally designed pre-2026-07-24).
  - Switch moves from EN pin to battery path (needs power rating ≥3A, not signal-level).
  - Switch part changes from ALPS SSAL120100 (signal-level momentary, 10mA@5V) to TBD maintained power-rated switch.
  - Schematic impact: Current SW21 wiring (on EN pin) must be replaced with a power switch in the battery path. This is a power section change — user handles all KiCad work per 2026-08-16 workflow role change.
- *Supersedes*: 2026-08-02 Power Switch Functionality decision (momentary slide switch + latch circuit, soft/hard off + unified power on). That approach is reversed — the latch circuit is eliminated, the momentary switch is replaced by a maintained power switch, and soft off becomes a firmware timer instead of a switch press.
- *Firmware deferral*: All non-hardware power management decisions (modem sleep behavior during soft off, wake sources from STOP mode, inactivity timer duration, graceful shutdown sequence, network reachability during sleep) are deferred until after PCB is ordered. The hardware provides: (1) hard on/off via switch, (2) always-on 3.3V rail when switch is on, (3) MCU STOP mode capability. Firmware decides what happens during sleep.
- **Docs updated**: This entry, `docs/ref/requirements.md` (FR-4.5/4.6/4.7), `docs/ref/bom.md` (item 25b), `docs/work/block-diagram.md` (+BATT net + U8 EN), `docs/work/ic-by-ic-review.md` (Q3 + DEF-001/DEF-002), `docs/work/task-tracker.md` (O2), `docs/work/schematic-completion-plan.md` (switch refdes row).

### 2026-08-17: Camera Module Selection — OV5640 DVP with Auto-Focus

- **Decision**: Select **OV5640** (5MP, auto-focus) as the rev1 camera module, connected via **8-bit DVP** to the STM32H743 DCMI peripheral. Module sourced as a pre-assembled FPC module (ArduCAM-standard 20-pin 0.5mm pitch) plugged into a ZIF connector on the PCB — same strategy as the display panel.
  - *Rationale*: OV5640 was chosen over OV2640 after a detailed comparison:
    - **Quality**: OV5640 is 5MP (2592×1944) with VCM auto-focus. OV2640 is 2MP (1600×1200) fixed-focus. Auto-focus is the key differentiator — the difference between "camera works" and "camera takes good photos."
    - **Hardware requirements are identical**: Both use 8-bit DVP, same sync/clock signals, same ~13 MCU pins. The PCB complexity is the same either way.
    - **Power is simpler on OV5640**: The ArduCAM OV5640 module has onboard LDOs (takes 3.3V only). The standard OV2640 FPC module (OV2640FSL) exposes bare sensor rails (AVDD 2.8V, DVDD 1.3V, DOVDD 2.8V) on the FFC, requiring extra LDOs on the carrier PCB.
    - **Firmware tradeoff accepted**: The Zephyr OV5640 DVP driver (merged Feb 2025) currently exposes only 480×272 RGB565 — no JPEG, no VGA+, no AF control. Extending the driver (add VGA/SXGA/UXGA modes, expose JPEG format, add AF VCM control) is real firmware work but the register tables exist in Linux/ST/Adafruit reference drivers. The OV2640 Zephyr driver is more mature (JPEG at all resolutions, tested on H743 DCMI), but the lower quality and fixed focus were deemed not worth the firmware savings for a rev1 board that's meant to be daily-driver-capable.
    - **JPEG support confirmed**: OV5640 has on-chip JPEG compression (same as OV2640). The STM32H743 also has a hardware JPEG codec (Zephyr driver `st,stm32-jpeg`, PR #110278). Two independent JPEG paths exist: sensor-side JPEG (lower bandwidth) and H7 HW JPEG encode/decode (works with any sensor output format).
    - **Video recording**: Feasible but deferred. OV5640 JPEG → DCMI → SD card as MJPEG is achievable (VGA@30fps JPEG ≈ 1-1.5 MB/s, well within SDMMC bandwidth). Preview requires H7 HW JPEG decode → display. Marked as firmware-future, not a rev1 hardware concern.
  - *Pin assignment*: 16 new MCU pins + 4 reassigned existing pins. See `docs/work/mcu-pin-assignment.md` DCMI section for the full assignment. Key decisions:
    - DCMI D4/D6/D7 required reassigning PE4 (PWR_3V3_OK → PC4), PE5 (FUEL_ALERT → PC5), PE6 (MODEM_PWR_EN → PG2) — these were the only conflict-free DCMI AF14 pins for those data lines on LQFP-144.
    - XCLK uses PA8/MCO1 (standard ST approach for camera clock). Backlight PWM moved from PA8/TIM1_CH1 to PD12/TIM4_CH1.
    - Camera SCCB uses a **separate I2C2 bus** (PF0/PF1, 3.3V pull-ups) — not the existing I2C1 (PB8/PB9, 1.8V pull-ups for codec). The 1.8V vs 3.3V voltage mismatch makes sharing I2C1 unsafe for the codec and fuel gauge. OV5640 SCCB address is 0x3C (fixed) — no collision with ALC5651 (0x1A) or MAX17048 (0x36), but the voltage isolation forces a separate bus regardless.
  - *Hardware restrictions verified — no blockers*:
    - DCMI 8-bit mode supported on H743 ✅
    - All 11 DCMI AF14 pins available on LQFP-144 (with 3 reassignments) ✅
    - DOVDD 2.8V > STM32H7 VIH min 2.31V — DVP signals recognized ✅ (must verify specific module sets DOVDD to 2.8V, not 1.8V)
    - I2C address 0x3C — no collision ✅
    - Module power: 3.3V only (onboard LDOs) ✅
    - VCM auto-focus power: handled by module ✅
  - *Module selection details*: ArduCAM-standard 20-pin 0.5mm FPC DVP pinout (not the 24-pin MIPI-hybrid variant). Specific module part TBD — needs sourcing verification (confirm DOVDD = 2.8V, confirm onboard LDOs, confirm FFC pinout matches ArduCAM standard). The OV2640FSL (24-pin) and OV5640 ArduCAM (20-pin) have **incompatible** FFC pinouts — the connector is module-specific, not swappable.
  - *Deferred items (2026-08-17)*: All remaining camera-related part selections (specific OV5640 module sourcing, ZIF connector part number, OV5640 datasheet download) and the 3 trivial GPIO assignments (notification LED, vibration motor, headphone jack detect) are **deferred until the PCB framework is built in the schematic phase**. The schematic sheet structure, net labels, and component placeholders can be laid out with generic parts first; specific part numbers and footprints get filled in when placing actual components. This avoids premature part selection before the schematic topology is established.
  - *What is lost*: OV2640's mature Zephyr JPEG driver (works today, tested on H743). Camera firmware on rev1 will require extending the Zephyr OV5640 driver — this is integration work (register tables exist as references) but not trivial. The camera may not be functional at initial bring-up; it's a firmware project after the PCB is built.
  - *Supersedes*: The "Camera module selection is TBD" note in the 2026-08-16 rev1 Hardware Scope Expansion decision. The camera module is now selected.
- **Docs updated**: This entry, `docs/work/mcu-pin-assignment.md` (DCMI pin assignment + PE4/PE5/PE6/PA8 reassignment + I2C2 bus), `docs/ref/bom.md` (OV5640 module selected), `docs/ref/research-notes.md` (camera research marked resolved), `AGENTS.md` (Key Decisions table).
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

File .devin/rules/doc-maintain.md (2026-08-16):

---
trigger: always_on
---

# Documentation Maintenance Rule

This project is documentation-driven. The docs in `docs/` are the single source of truth for decisions, requirements, constraints, and research. **Keeping them accurate, current, and internally consistent is a mandatory part of every task — not an optional cleanup step.**

## Document Structure

```
docs/
  work/         — Active planning & working docs (frequently edited)
  ref/          — Long-term reference (locked decisions, specs, history)
  datasheets/   — Vendor datasheets (PDFs gitignored, only README.md tracked)
  archive/      — Completed/superseded plans + revisit prompts (historical)
```

Each doc has YAML frontmatter: `status: active|reference|archived`, `updated: YYYY-MM-DD`.
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

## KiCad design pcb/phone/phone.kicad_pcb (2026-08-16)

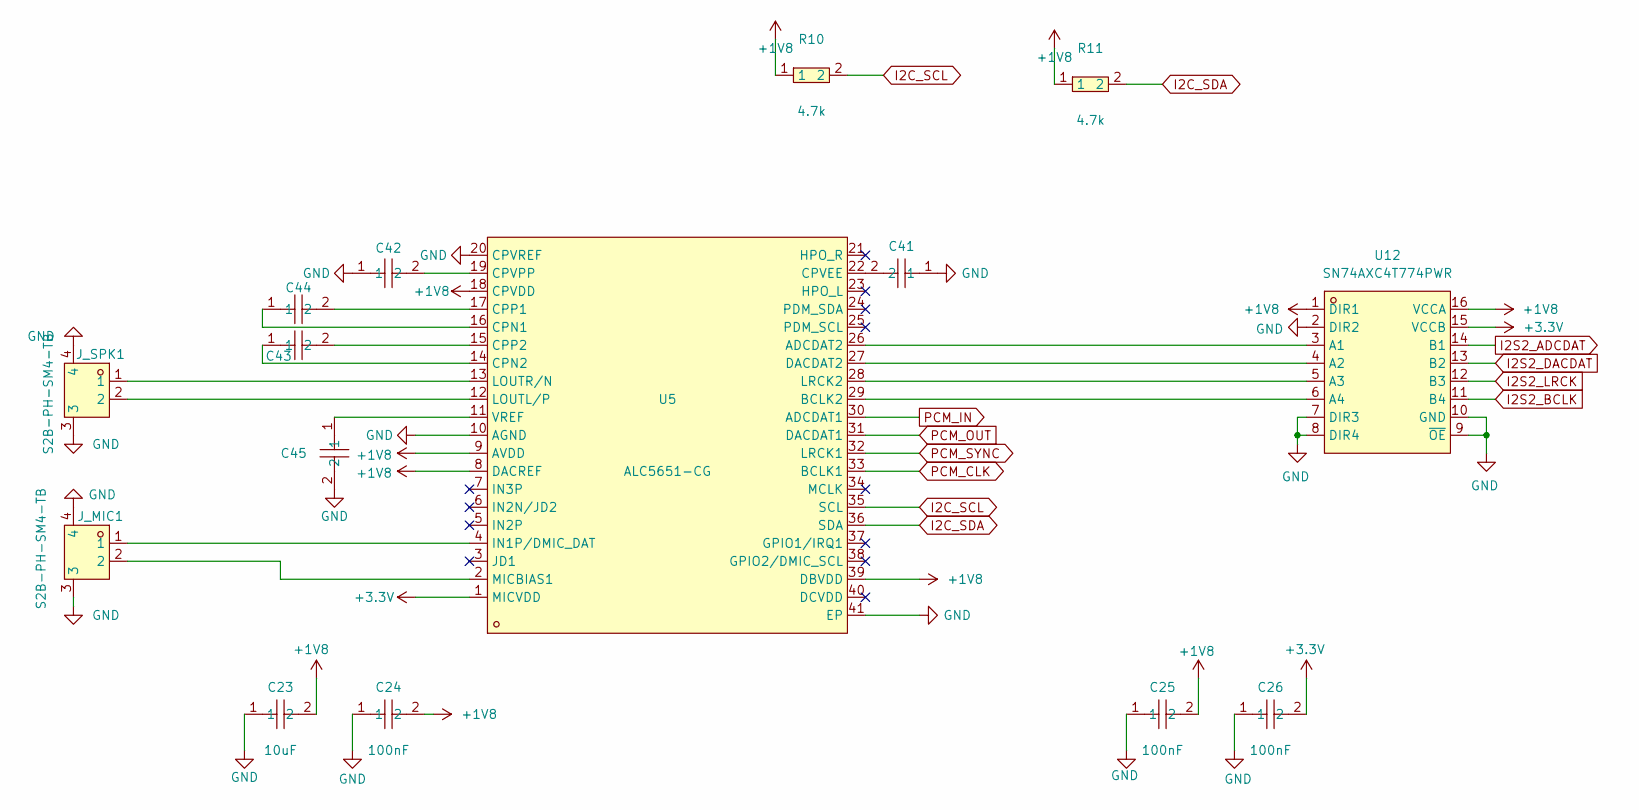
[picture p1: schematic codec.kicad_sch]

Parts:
C23: 10uF; C0805
C24, C25, C26: 100nF; C0603
C41, C42, C43, C44: CC0603KRX5R8BB225; C0603; MPN CC0603KRX5R8BB225; LCSC Part C309478
C45: GRM188R61C475KE11D; C0603; MPN GRM188R61C475KE11D; LCSC Part C77045
J_MIC1: S2B-PH-SM4-TB; CONN-SMD_P2.00_S2B-PH-SM4-TB-LF-SN
J_SPK1: S2B-PH-SM4-TB; CONN-SMD_P2.00_S2B-PH-SM4-TB-LF-SN
R10, R11: 4.7k; R0603
U5: ALC5651-CG; QFN-40_L5.0-W5.0-P0.40-BL-EP3.7
U12: SN74AXC4T774PWR; TSSOP-16_L5.0-W4.4-P0.65-LS6.4-TL; MPN SN74AXC4T774PWR; LCSC Part C1849453

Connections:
+1V8: C23.2, C24.2, C25.2, R10.1, R11.1, U5.8 (DACREF), U5.9 (AVDD), U5.18 (CPVDD), U5.39 (DBVDD), U12.1 (DIR1), U12.16 (VCCA); also elsewhere on the board
+3.3V: C26.2, U5.1 (MICVDD), U12.15 (VCCB); also elsewhere on the board
GND: C23.1, C24.1, C25.1, C26.1, C41.1, C42.1, C45.2, J_MIC1.3, J_MIC1.4, J_SPK1.3, J_SPK1.4, U5.10 (AGND), U5.20 (CPVREF), U5.41 (EP), U12.2 (DIR2), U12.7 (DIR3), U12.8 (DIR4), U12.9 (~OE), U12.10 (GND); also elsewhere on the board
I2C_SCL: R10.2, U5.35 (SCL); also elsewhere on the board
I2C_SDA: R11.2, U5.36 (SDA); also elsewhere on the board
I2S2_ADCDAT: U12.14 (B1); also elsewhere on the board
I2S2_BCLK: U12.11 (B4); also elsewhere on the board
I2S2_DACDAT: U12.13 (B2); also elsewhere on the board
I2S2_LRCK: U12.12 (B3); also elsewhere on the board
unnamed: C44.1, U5.16 (CPN1)
unnamed: C43.1, U5.14 (CPN2)
unnamed: C44.2, U5.17 (CPP1)
unnamed: C43.2, U5.15 (CPP2)
unnamed: C41.2, U5.22 (CPVEE)
unnamed: C42.2, U5.19 (CPVPP)
unnamed: J_MIC1.1, U5.4 (IN1P/DMIC_DAT)
unnamed: J_SPK1.2, U5.12 (LOUTL/P)
unnamed: J_SPK1.1, U5.13 (LOUTR/N)
unnamed: J_MIC1.2, U5.2 (MICBIAS1)
unnamed: C45.1, U5.11 (VREF)
unnamed: U5.26 (ADCDAT2), U12.3 (A1)
unnamed: U5.27 (DACDAT2), U12.4 (A2)
unnamed: U5.28 (LRCK2), U12.5 (A3)
unnamed: U5.29 (BCLK2), U12.6 (A4)
PCM_CLK: U5.33 (BCLK1); also elsewhere on the board
PCM_IN: U5.30 (ADCDAT1); also elsewhere on the board
PCM_OUT: U5.31 (DACDAT1); also elsewhere on the board
PCM_SYNC: U5.32 (LRCK1); also elsewhere on the board

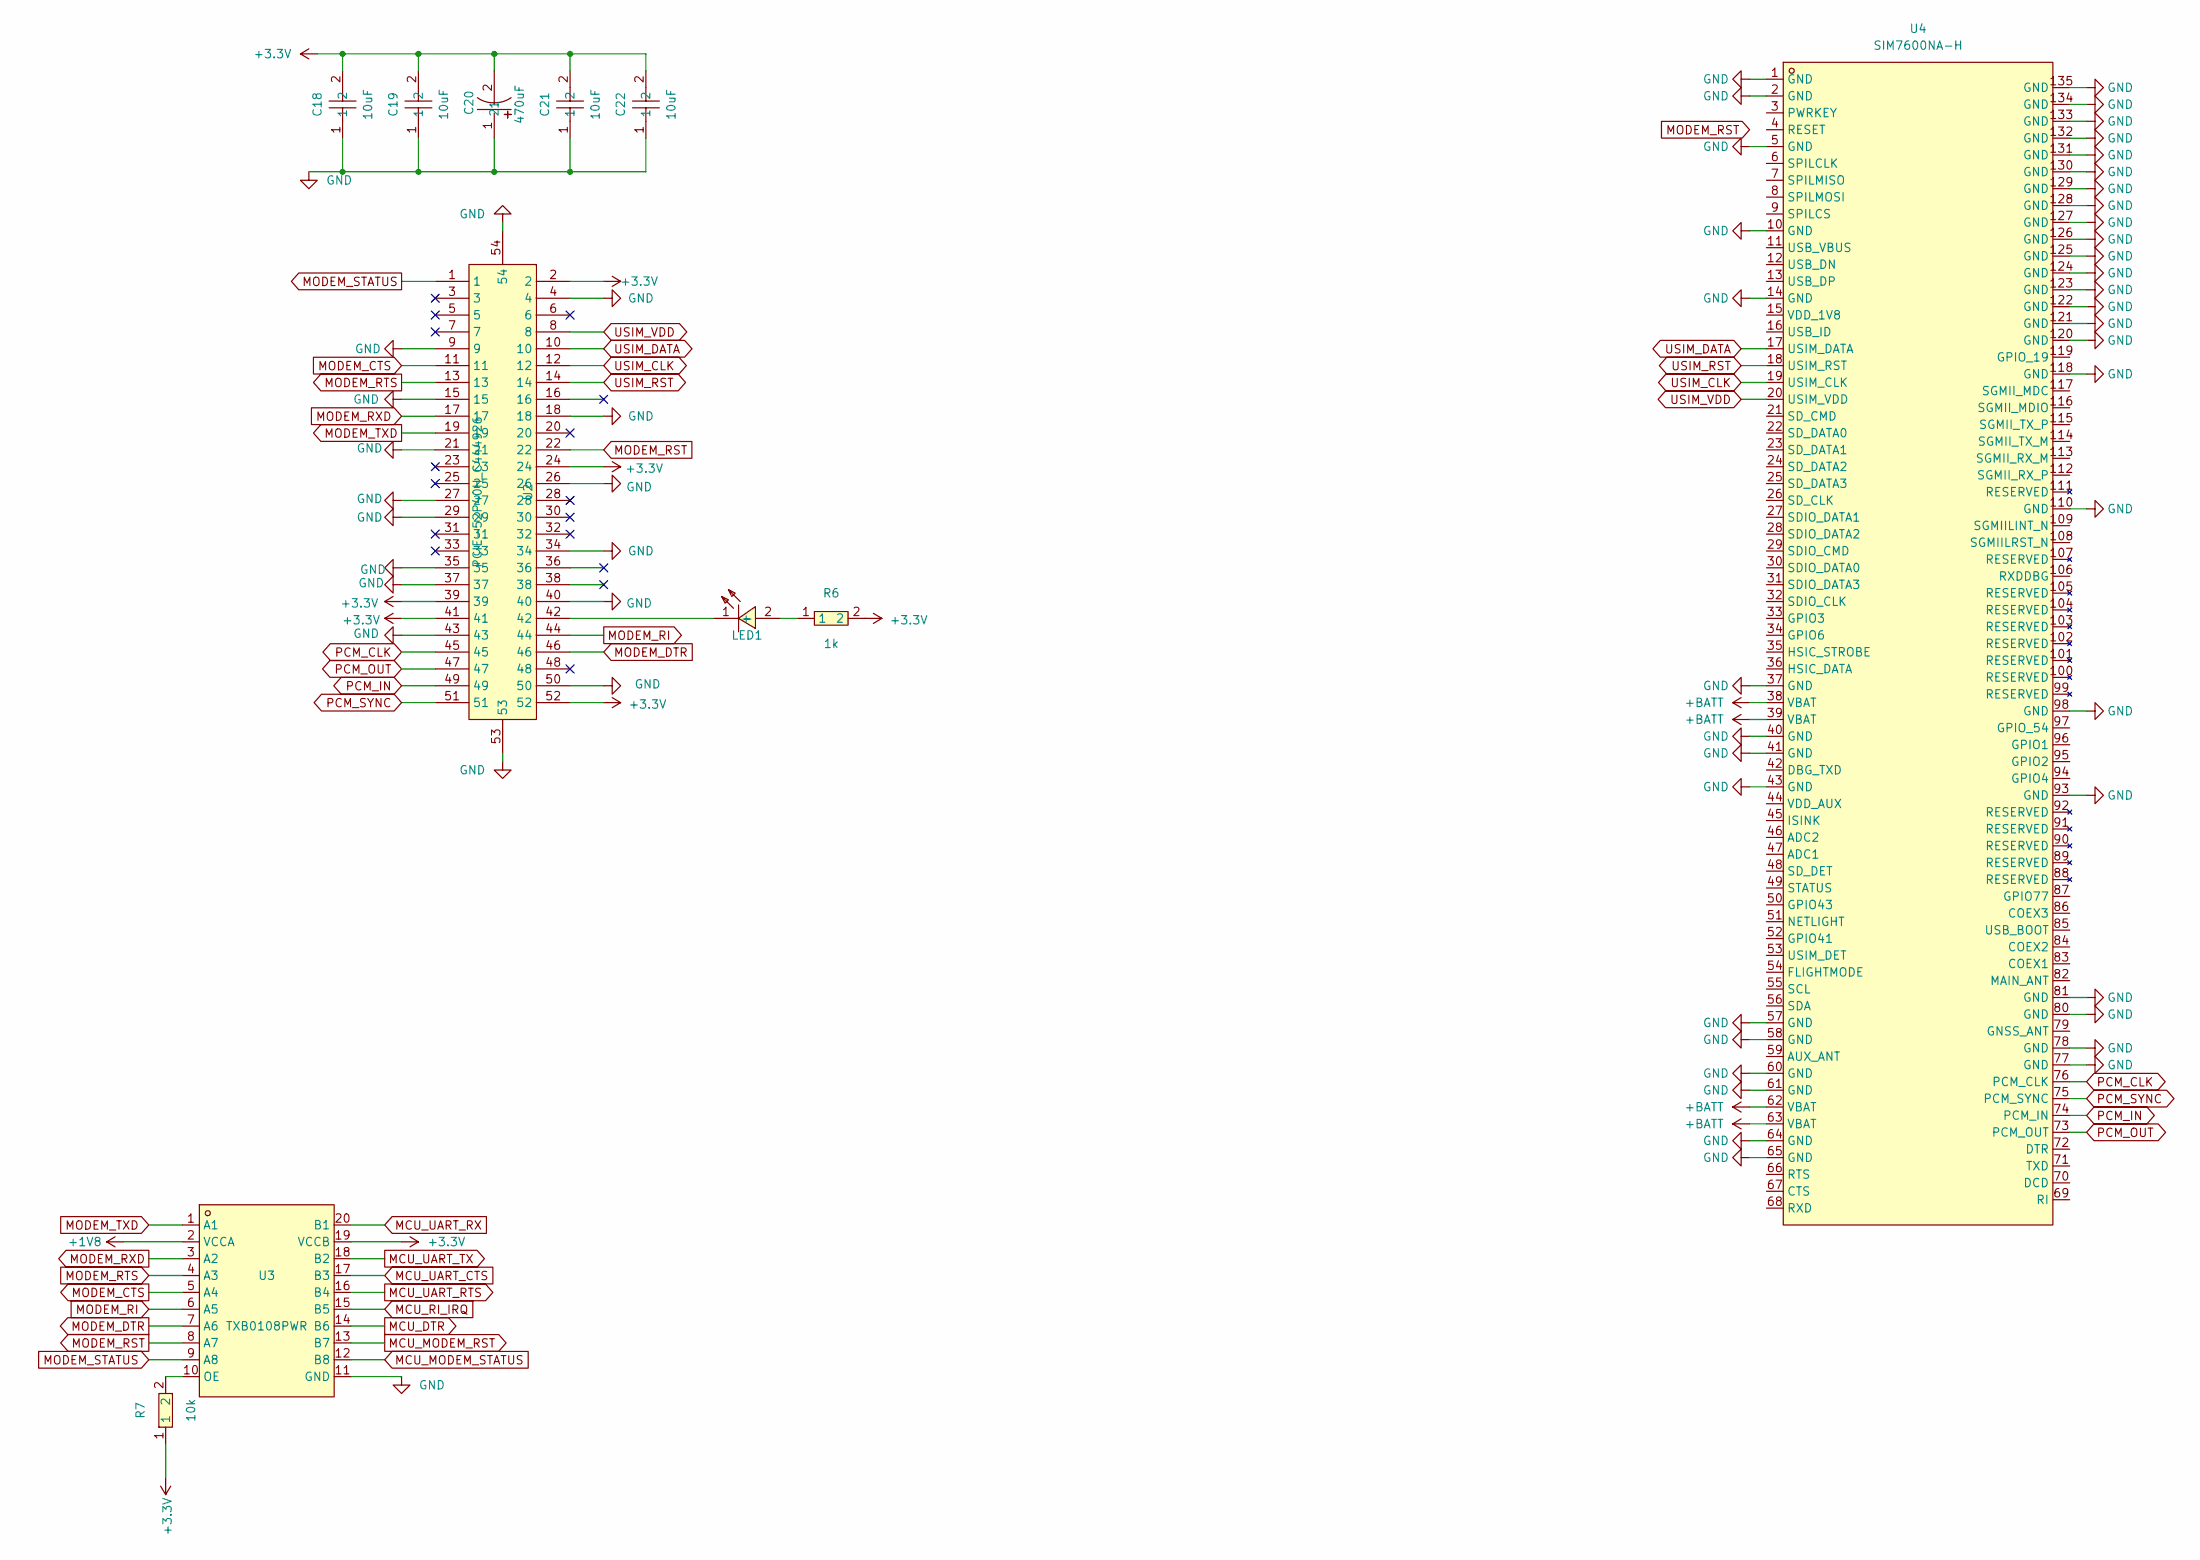
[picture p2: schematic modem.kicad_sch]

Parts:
C18, C19, C21, C22: 10uF; C0805
C20: 470uF; CAP-SMD_L7.3-W4.3
LED1: LTST-C191TBKT; LED0603-RD; MPN LTST-C191TBKT; LCSC Part C99290
R6: 1k; R0603
R7: 10k; R0603
U2: PCIE-52P40H_C444926; PCIE-SMD_PCIE-52P40H-1
U3: TXB0108PWR; TSSOP-20_L6.5-W4.4-P0.65-LS6.4-BL
U4: SIM7600NA-H; COMM-SMD_L13.0-W13.0-P1.0_SIM7600NA-H; MPN SIM7600NA-H; LCSC Part C5380303

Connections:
+1V8: U3.2 (VCCA); also elsewhere on the board
+3.3V: C18.2, C19.2, C20.2, C21.2, C22.2, R6.2, R7.1, U2.2, U2.24, U2.39, U2.41, U2.52, U3.19 (VCCB); also elsewhere on the board
GND: C18.1, C19.1, C20.1, C21.1, C22.1, U2.4, U2.9, U2.15, U2.18, U2.21, U2.26, U2.27, U2.29, U2.34, U2.35, U2.37, U2.40, U2.43, U2.50, U2.53, U2.54, U3.11 (GND), U4.1 (GND), U4.2 (GND), U4.5 (GND), U4.10 (GND), U4.14 (GND), U4.37 (GND), U4.40 (GND), U4.41 (GND), U4.43 (GND), U4.57 (GND), U4.58 (GND), U4.60 (GND), U4.61 (GND), U4.64 (GND), U4.65 (GND), U4.77 (GND), U4.78 (GND), U4.80 (GND), U4.81 (GND), U4.93 (GND), U4.98 (GND), U4.110 (GND), U4.118 (GND), U4.120 (GND), U4.121 (GND), U4.122 (GND), U4.123 (GND), U4.124 (GND), U4.125 (GND), U4.126 (GND), U4.127 (GND), U4.128 (GND), U4.129 (GND), U4.130 (GND), U4.131 (GND), U4.132 (GND), U4.133 (GND), U4.134 (GND), U4.135 (GND); also elsewhere on the board
MCU_DTR: U3.14 (B6); also elsewhere on the board
MCU_MODEM_RST: U3.13 (B7); also elsewhere on the board
MCU_MODEM_STATUS: U3.12 (B8); also elsewhere on the board
MCU_RI_IRQ: U3.15 (B5); also elsewhere on the board
MCU_UART_CTS: U3.17 (B3); also elsewhere on the board
MCU_UART_RTS: U3.16 (B4); also elsewhere on the board
MCU_UART_RX: U3.20 (B1); also elsewhere on the board
MCU_UART_TX: U3.18 (B2); also elsewhere on the board
MODEM_CTS: U2.11, U3.5 (A4)
MODEM_DTR: U2.46, U3.7 (A6)
MODEM_RI: U2.44, U3.6 (A5)
MODEM_RST: U2.22, U3.8 (A7)
MODEM_RTS: U2.13, U3.4 (A3)
MODEM_RXD: U2.17, U3.3 (A2)
MODEM_STATUS: U2.1, U3.9 (A8)
MODEM_TXD: U2.19, U3.1 (A1)
unnamed: LED1.2 (+), R6.1
unnamed: LED1.1 (-), U2.42
unnamed: R7.2, U3.10 (OE)
unnamed: U4.38 (VBAT), U4.39 (VBAT), U4.62 (VBAT), U4.63 (VBAT)
PCM_CLK: U2.45, U4.76 (PCM_CLK); also elsewhere on the board
PCM_IN: U2.49, U4.74 (PCM_IN); also elsewhere on the board
PCM_OUT: U2.47, U4.73 (PCM_OUT); also elsewhere on the board
PCM_SYNC: U2.51, U4.75 (PCM_SYNC); also elsewhere on the board
USIM_CLK: U2.12, U4.19 (USIM_CLK); also elsewhere on the board
USIM_DATA: U2.10, U4.17 (USIM_DATA); also elsewhere on the board
USIM_RST: U2.14, U4.18 (USIM_RST); also elsewhere on the board
USIM_VDD: U2.8, U4.20 (USIM_VDD); also elsewhere on the board

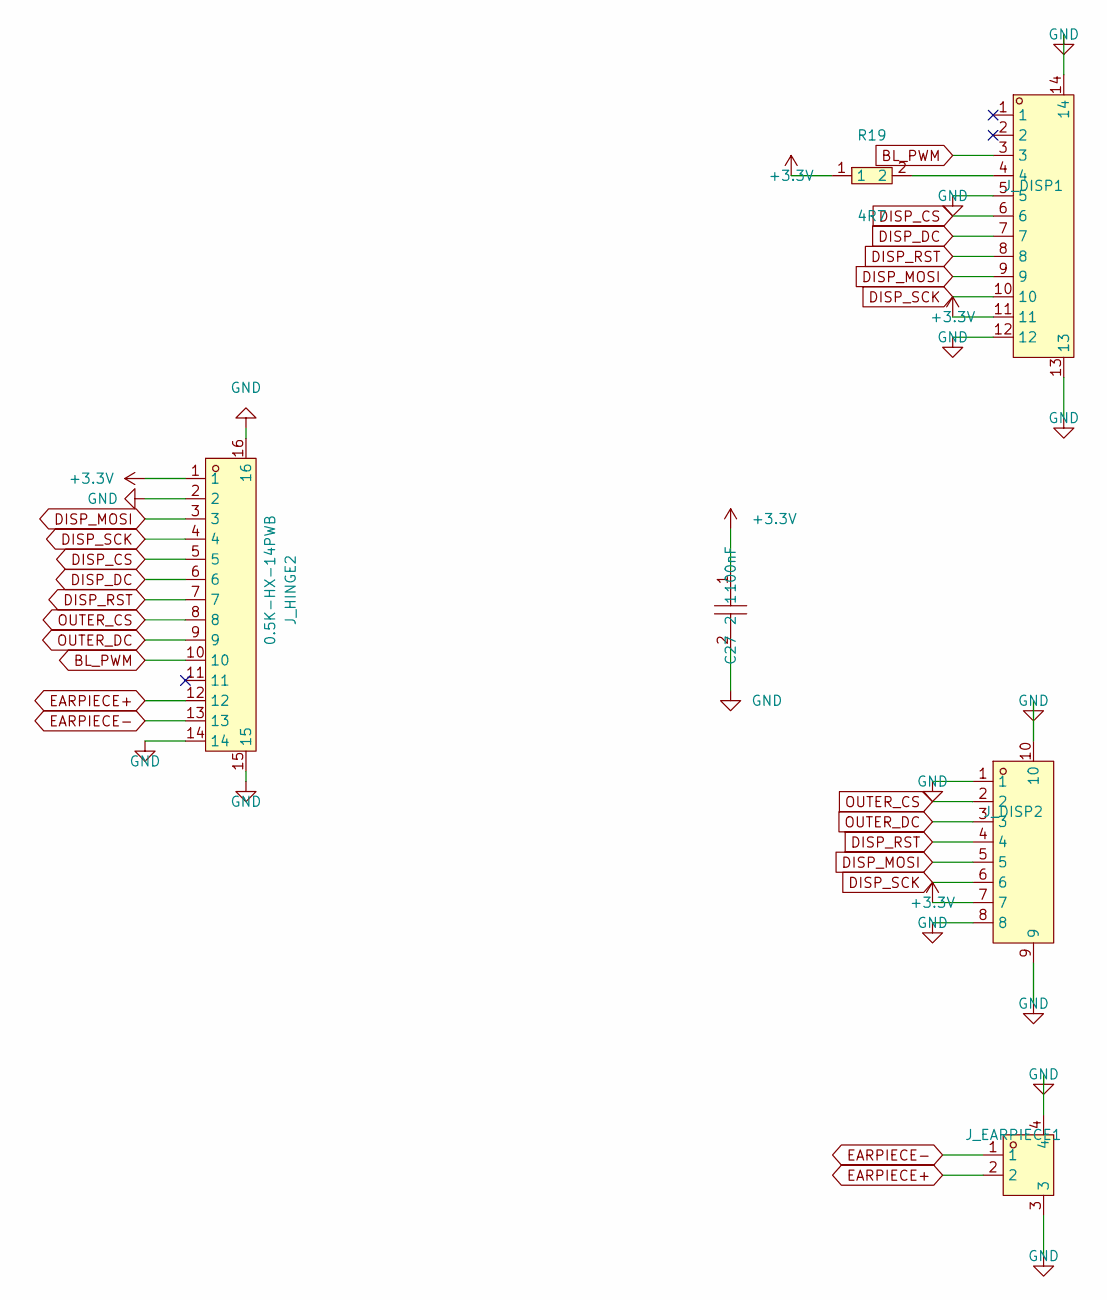
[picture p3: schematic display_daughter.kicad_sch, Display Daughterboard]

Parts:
C27: 100nF; C0603
J_DISP1: 0.5K-HX-12PWB; FPC-SMD_12P-P0.50_HDGC_0.5K-HX-12PWB
J_DISP2: 0.5K-HX-8PWB; FPC-SMD_8P-P0.50_HDGC_0.5K-HX-8PWB
J_EARPIECE1: S2B-PH-SM4-TB; CONN-SMD_P2.00_S2B-PH-SM4-TB-LF-SN
J_HINGE2: 0.5K-HX-14PWB; FPC-SMD_14P-P0.50_HDGC_0.5K-HX-14PWB
R19: 4R7; R0603

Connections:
+3.3V: C27.1, J_DISP1.11, J_DISP2.7, J_HINGE2.1, R19.1; also elsewhere on the board
BL_PWM: J_DISP1.3, J_HINGE2.10; also elsewhere on the board
DISP_CS: J_DISP1.6, J_HINGE2.5; also elsewhere on the board
DISP_DC: J_DISP1.7, J_HINGE2.6; also elsewhere on the board
DISP_MOSI: J_DISP1.9, J_DISP2.5, J_HINGE2.3; also elsewhere on the board
DISP_RST: J_DISP1.8, J_DISP2.4, J_HINGE2.7; also elsewhere on the board
DISP_SCK: J_DISP1.10, J_DISP2.6, J_HINGE2.4; also elsewhere on the board
EARPIECE+: J_EARPIECE1.2, J_HINGE2.12; also elsewhere on the board
EARPIECE-: J_EARPIECE1.1, J_HINGE2.13; also elsewhere on the board
GND: C27.2, J_DISP1.5, J_DISP1.12, J_DISP1.13, J_DISP1.14, J_DISP2.1, J_DISP2.8, J_DISP2.9, J_DISP2.10, J_EARPIECE1.3, J_EARPIECE1.4, J_HINGE2.2, J_HINGE2.14, J_HINGE2.15, J_HINGE2.16; also elsewhere on the board
unnamed: J_DISP1.4, R19.2
OUTER_CS: J_DISP2.2, J_HINGE2.8; also elsewhere on the board
OUTER_DC: J_DISP2.3, J_HINGE2.9; also elsewhere on the board

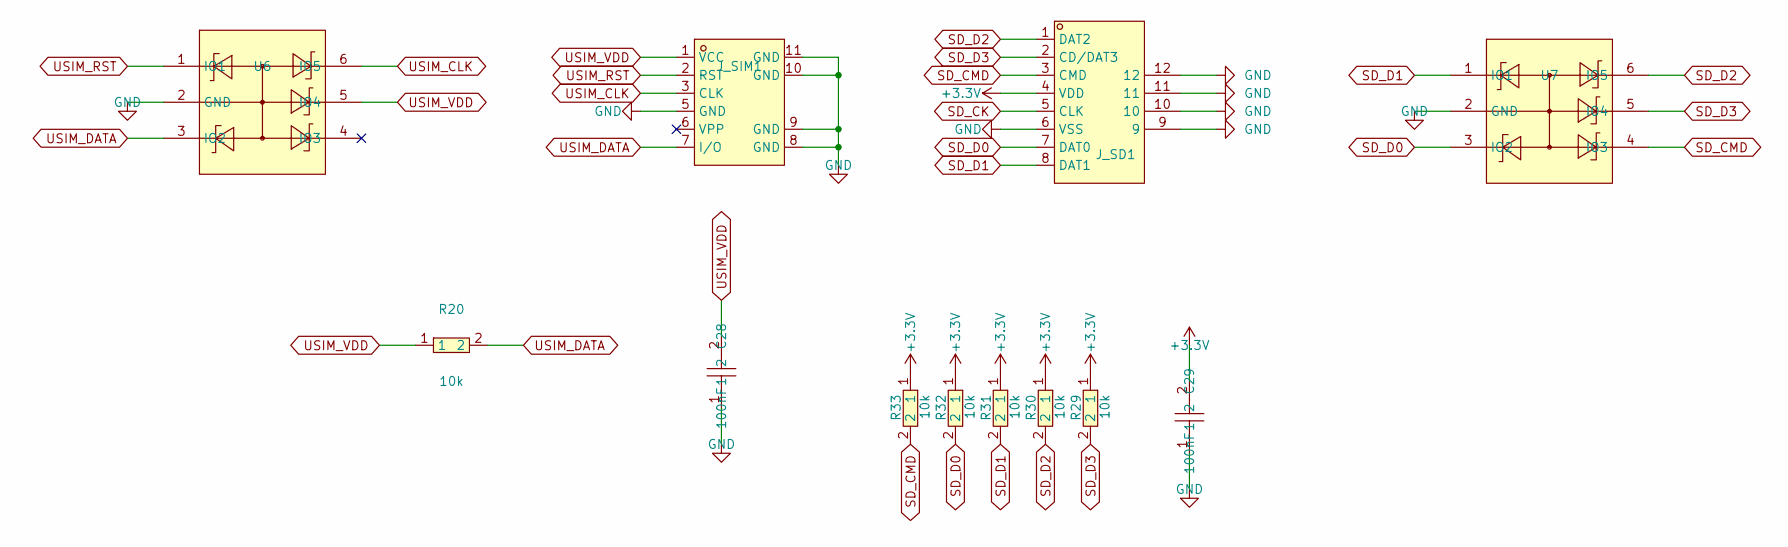
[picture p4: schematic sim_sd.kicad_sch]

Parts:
C28, C29: 100nF; C0603
J_SD1: 472192001; TF-SMD_472192001
J_SIM1: NANOSIMXG6PH1.35; SIM-SMD_NANO-SIM-XG6P-H1.35
R20, R29, R30, R31, R32, R33: 10k; R0603
U6, U7: ESDA6V1-5SC6; SOT-23-6_L2.9-W1.6-P0.95-LS2.8-BR

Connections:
+3.3V: C29.2, J_SD1.4 (VDD), R29.1, R30.1, R31.1, R32.1, R33.1; also elsewhere on the board
GND: C28.1, C29.1, J_SD1.6 (VSS), J_SD1.9, J_SD1.10, J_SD1.11, J_SD1.12, J_SIM1.5 (GND), J_SIM1.8 (GND), J_SIM1.9 (GND), J_SIM1.10 (GND), J_SIM1.11 (GND), U6.2 (GND), U7.2 (GND); also elsewhere on the board
SD_CK: J_SD1.5 (CLK); also elsewhere on the board
SD_CMD: J_SD1.3 (CMD), R33.2, U7.4 (IO3); also elsewhere on the board
SD_D0: J_SD1.7 (DAT0), R32.2, U7.3 (IO2); also elsewhere on the board
SD_D1: J_SD1.8 (DAT1), R31.2, U7.1 (IO1); also elsewhere on the board
SD_D2: J_SD1.1 (DAT2), R30.2, U7.6 (IO5); also elsewhere on the board
SD_D3: J_SD1.2 (CD/DAT3), R29.2, U7.5 (IO4); also elsewhere on the board
USIM_CLK: J_SIM1.3 (CLK), U6.6 (IO5); also elsewhere on the board
USIM_DATA: J_SIM1.7 (I/O), R20.2, U6.3 (IO2); also elsewhere on the board
USIM_RST: J_SIM1.2 (RST), U6.1 (IO1); also elsewhere on the board
USIM_VDD: C28.2, J_SIM1.1 (VCC), R20.1, U6.5 (IO4); also elsewhere on the board

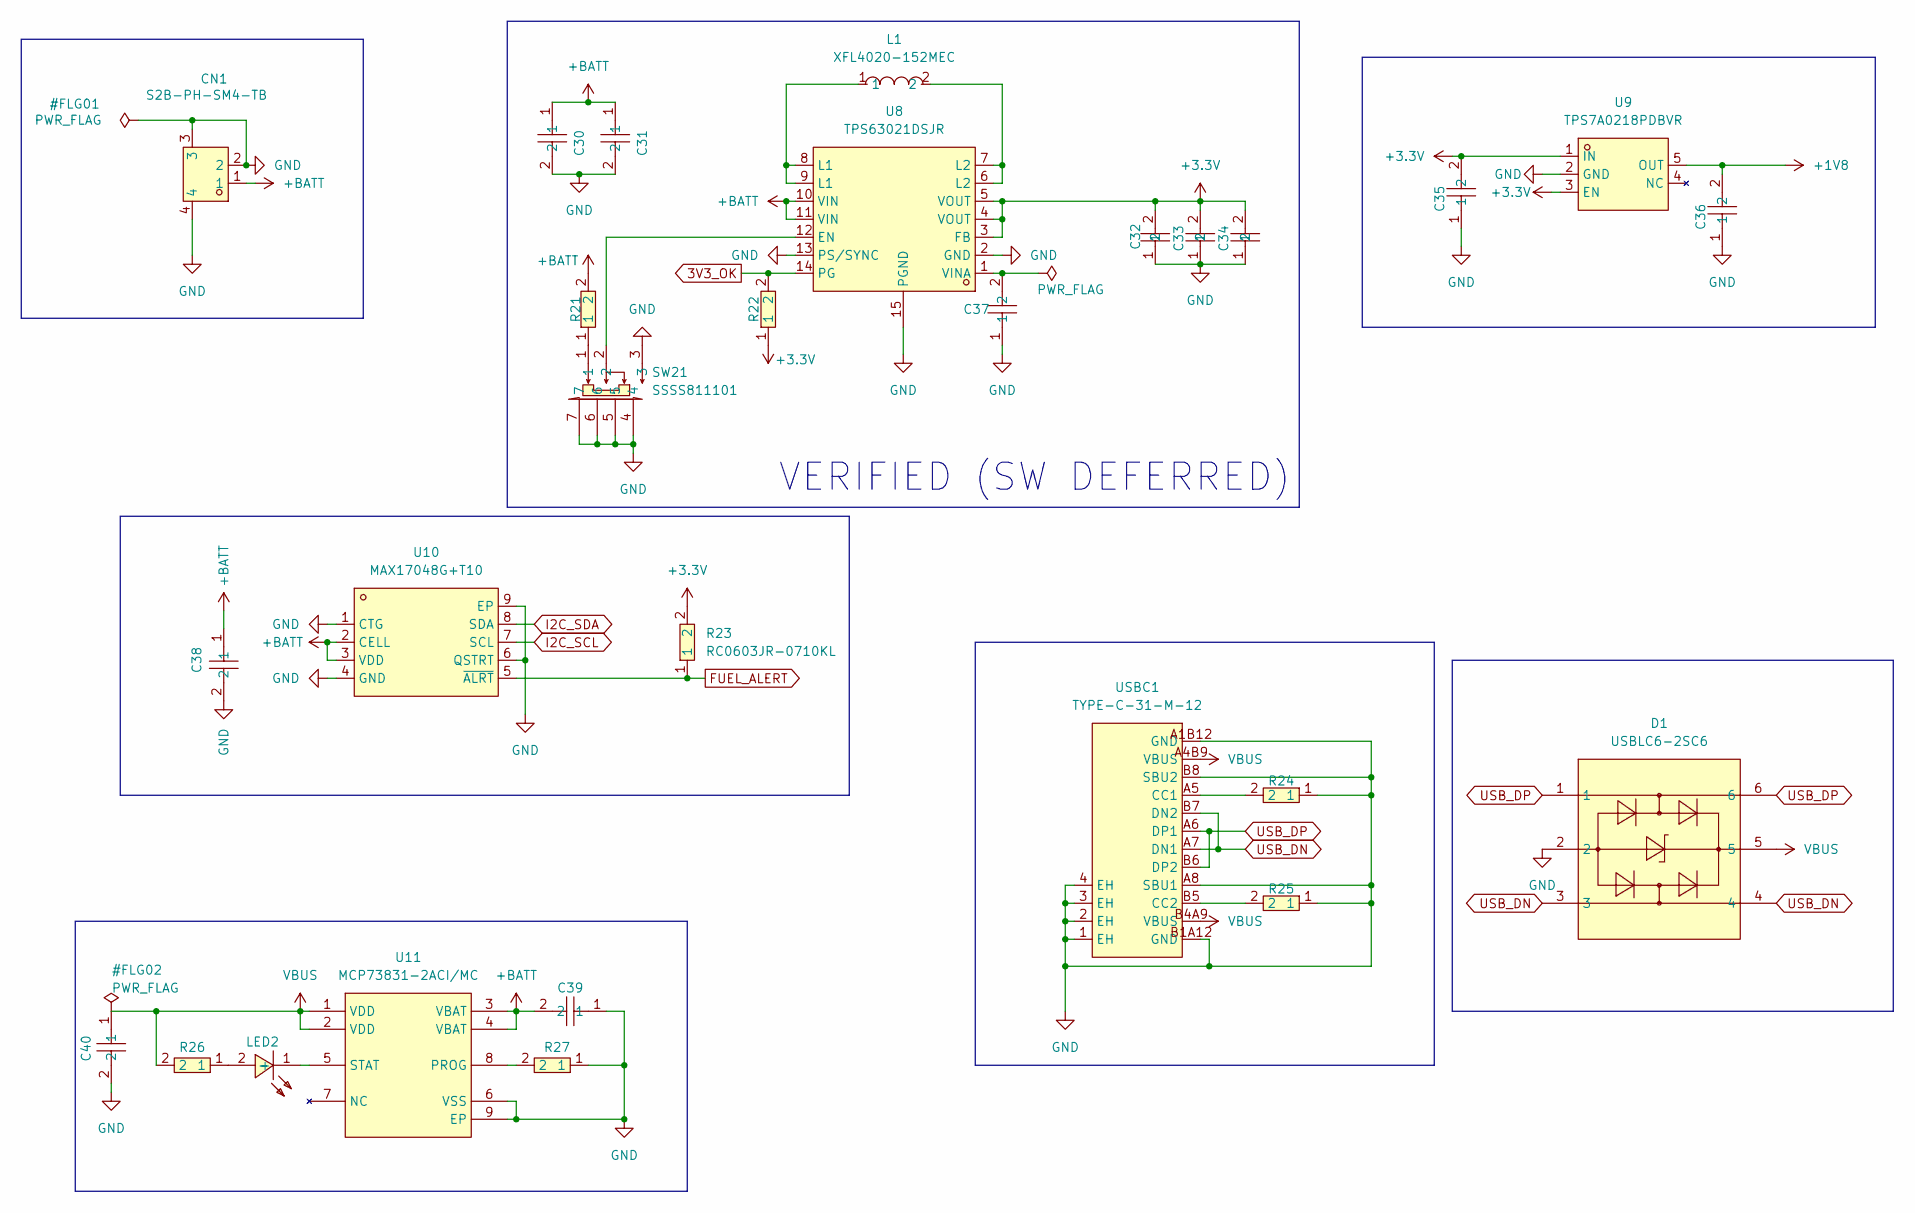
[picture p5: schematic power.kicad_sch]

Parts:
C30, C31: GRM21BR61H106KE43L; C0805; MPN GRM21BR61H106KE43L; LCSC Part C440198
C32, C33, C34: GRM21BR61A226ME51L; C0805; MPN GRM21BR61A226ME51L; LCSC Part C77074
C35, C36: GRM188R61C105KA93D; C0603; MPN GRM188R61C105KA93D; LCSC Part C77404
C37, C38: CC0603KRX7R9BB104; C0603; MPN CC0603KRX7R9BB104; LCSC Part C14663
C39, C40: GRM188R61C475KE11D; C0603; MPN GRM188R61C475KE11D; LCSC Part C77045
CN1: S2B-PH-SM4-TB; CONN-SMD_P2.00_S2B-PH-SM4-TB-LF-SN; MPN S2B-PH-SM4-TB(LF)(SN); LCSC Part C295747
D1: USBLC6-2SC6; SOT-23-6_L2.9-W1.6-P0.95-LS2.8-BL; MPN USBLC6-2SC6; LCSC Part C7519
L1: XFL4020-152MEC; IND-SMD_L4.0-W4.0-A; MPN XFL4020-152MEC; LCSC Part C3033018
LED2: LTST-C191TBKT; LED0603-RD; MPN LTST-C191TBKT; LCSC Part C99290
R21: RC0603JR-071ML; R0603; MPN RC0603JR-071ML; LCSC Part C107698
R22, R23: RC0603JR-0710KL; R0603; MPN RC0603JR-0710KL; LCSC Part C99198
R24, R25: RC0603FR-075K1L; R0603; MPN RC0603FR-075K1L; LCSC Part C105580
R26: RC0603JR-07470RL; R0603; MPN RC0603JR-07470RL; LCSC Part C114433
R27: RC0603FR-072KL; R0603; MPN RC0603FR-072KL; LCSC Part C105576
SW21: SSSS811101; SW-SMD_SSSS811101; MPN SSSS811101; LCSC Part C109335
U8: TPS63021DSJR; VSON-14_L4.0-W3.0-P0.50-BL-EP_TI_DSJ; MPN TPS63021DSJR; LCSC Part C202140
U9: TPS7A0218PDBVR; SOT-23-5_L2.9-W1.6-P0.95-LS2.8-BL; MPN TPS7A0218PDBVR; LCSC Part C3748843
U10: MAX17048G+T10; TDFN-8_L2.0-W2.0-P0.50-BL-EP1.2; MPN MAX17048G+T10; LCSC Part C2682616
U11: MCP73831-2ACI/MC; TDFN-8_L3.0-W2.0-P0.50-BL-EP1.6; MPN MCP73831-2ACI/MC; LCSC Part C150772
USBC1: TYPE-C-31-M-12; USB-C_SMD-TYPE-C-31-M-12_1; MPN TYPE-C-31-M-12; LCSC Part C165948

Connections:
3V3_OK: R22.2, U8.14 (PG); also elsewhere on the board
+1V8: C36.2, U9.5 (OUT); also elsewhere on the board
+3.3V: C32.2, C33.2, C34.2, C35.2, R22.1, R23.2, U8.3 (FB), U8.4 (VOUT), U8.5 (VOUT), U9.1 (IN), U9.3 (EN); also elsewhere on the board
+BATT: C30.1, C31.1, C38.1, C39.2, CN1.1, R21.2, U8.10 (VIN), U8.11 (VIN), U10.2 (CELL), U10.3 (VDD), U11.3 (VBAT), U11.4 (VBAT)
FUEL_ALERT: R23.1, U10.5 (~ALRT); also elsewhere on the board
GND: C30.2, C31.2, C32.1, C33.1, C34.1, C35.1, C36.1, C37.1, C38.2, C39.1, C40.2, CN1.2, CN1.3, CN1.4, D1.2, R24.1, R25.1, R27.1, SW21.3, SW21.4, SW21.5, SW21.6, SW21.7, U8.2 (GND), U8.13 (PS/SYNC), U8.15 (PGND), U9.2 (GND), U10.1 (CTG), U10.4 (GND), U10.6 (QSTRT), U10.9 (EP), U11.6 (VSS), U11.9 (EP), USBC1.1 (EH), USBC1.2 (EH), USBC1.3 (EH), USBC1.4 (EH), USBC1.A1B12 (GND), USBC1.A8 (SBU1), USBC1.B1A12 (GND), USBC1.B8 (SBU2); also elsewhere on the board
I2C_SCL: U10.7 (SCL); also elsewhere on the board
I2C_SDA: U10.8 (SDA); also elsewhere on the board
unnamed: L1.1, U8.8 (L1), U8.9 (L1)
unnamed: L1.2, U8.6 (L2), U8.7 (L2)
unnamed: LED2.2 (+), R26.1
unnamed: LED2.1 (-), U11.5 (STAT)
unnamed: R21.1, SW21.1
unnamed: SW21.2, U8.12 (EN)
unnamed: C37.2, U8.1 (VINA)
unnamed: R27.2, U11.8 (PROG)
unnamed: R24.2, USBC1.A5 (CC1)
unnamed: R25.2, USBC1.B5 (CC2)
USB_DN: D1.3, D1.4, USBC1.A7 (DN1), USBC1.B7 (DN2); also elsewhere on the board
USB_DP: D1.1, D1.6, USBC1.A6 (DP1), USBC1.B6 (DP2); also elsewhere on the board
VBUS: C40.1, D1.5, R26.2, U11.1 (VDD), U11.2 (VDD), USBC1.A4B9 (VBUS), USBC1.B4A9 (VBUS); also elsewhere on the board

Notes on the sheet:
VERIFIED (SW DEFERRED)

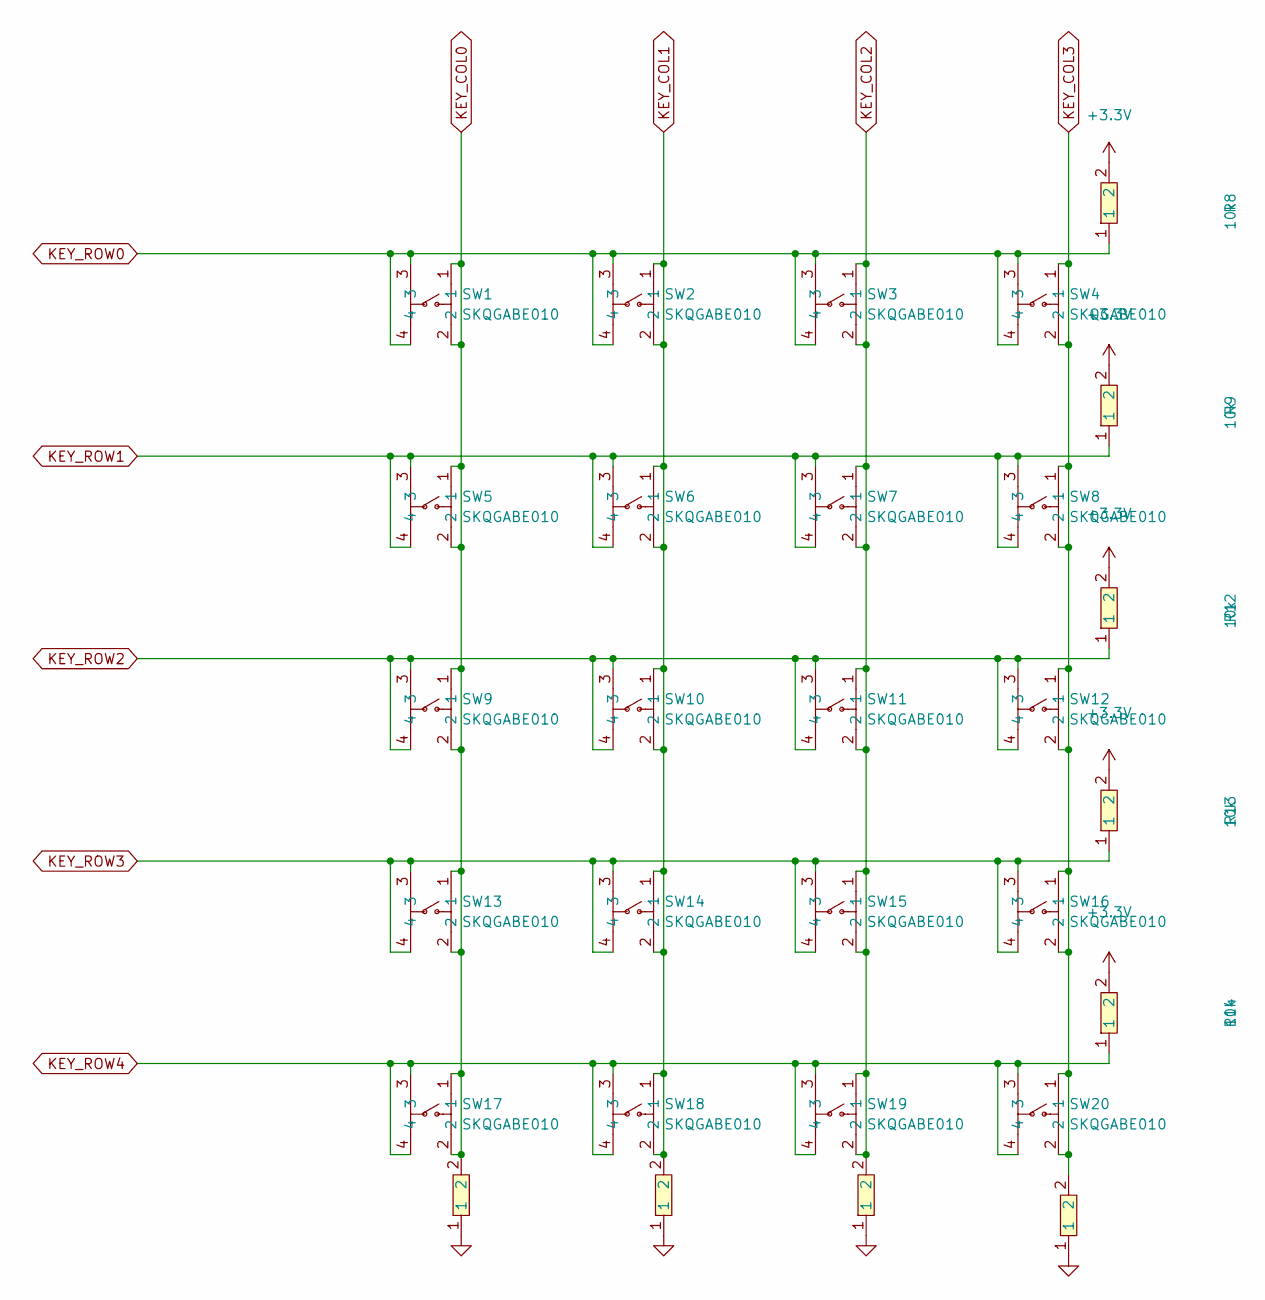
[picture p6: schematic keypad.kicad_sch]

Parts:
R8, R9, R12, R13, R14, R15, R16, R17, R18: 10k; R0603
SW1, SW2, SW3, SW4, SW5, SW6, SW7, SW8, SW9, SW10, SW11, SW12, SW13, SW14, SW15, SW16, SW17, SW18, SW19, SW20: SKQGABE010; KEY-SMD_4P-L5.2-W5.2-P3.70-LS6.4; MPN SKQGABE010; LCSC Part C115351

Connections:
+3.3V: R8.2, R9.2, R12.2, R13.2, R14.2; also elsewhere on the board
GND: R15.1, R16.1, R17.1, R18.1; also elsewhere on the board
KEY_COL0: R15.2, SW1.1, SW1.2, SW5.1, SW5.2, SW9.1, SW9.2, SW13.1, SW13.2, SW17.1, SW17.2; also elsewhere on the board
KEY_COL1: R16.2, SW2.1, SW2.2, SW6.1, SW6.2, SW10.1, SW10.2, SW14.1, SW14.2, SW18.1, SW18.2; also elsewhere on the board
KEY_COL2: R17.2, SW3.1, SW3.2, SW7.1, SW7.2, SW11.1, SW11.2, SW15.1, SW15.2, SW19.1, SW19.2; also elsewhere on the board
KEY_COL3: R18.2, SW4.1, SW4.2, SW8.1, SW8.2, SW12.1, SW12.2, SW16.1, SW16.2, SW20.1, SW20.2; also elsewhere on the board
KEY_ROW0: R8.1, SW1.3, SW1.4, SW2.3, SW2.4, SW3.3, SW3.4, SW4.3, SW4.4; also elsewhere on the board
KEY_ROW1: R9.1, SW5.3, SW5.4, SW6.3, SW6.4, SW7.3, SW7.4, SW8.3, SW8.4; also elsewhere on the board
KEY_ROW2: R12.1, SW9.3, SW9.4, SW10.3, SW10.4, SW11.3, SW11.4, SW12.3, SW12.4; also elsewhere on the board
KEY_ROW3: R13.1, SW13.3, SW13.4, SW14.3, SW14.4, SW15.3, SW15.4, SW16.3, SW16.4; also elsewhere on the board
KEY_ROW4: R14.1, SW17.3, SW17.4, SW18.3, SW18.4, SW19.3, SW19.4, SW20.3, SW20.4; also elsewhere on the board

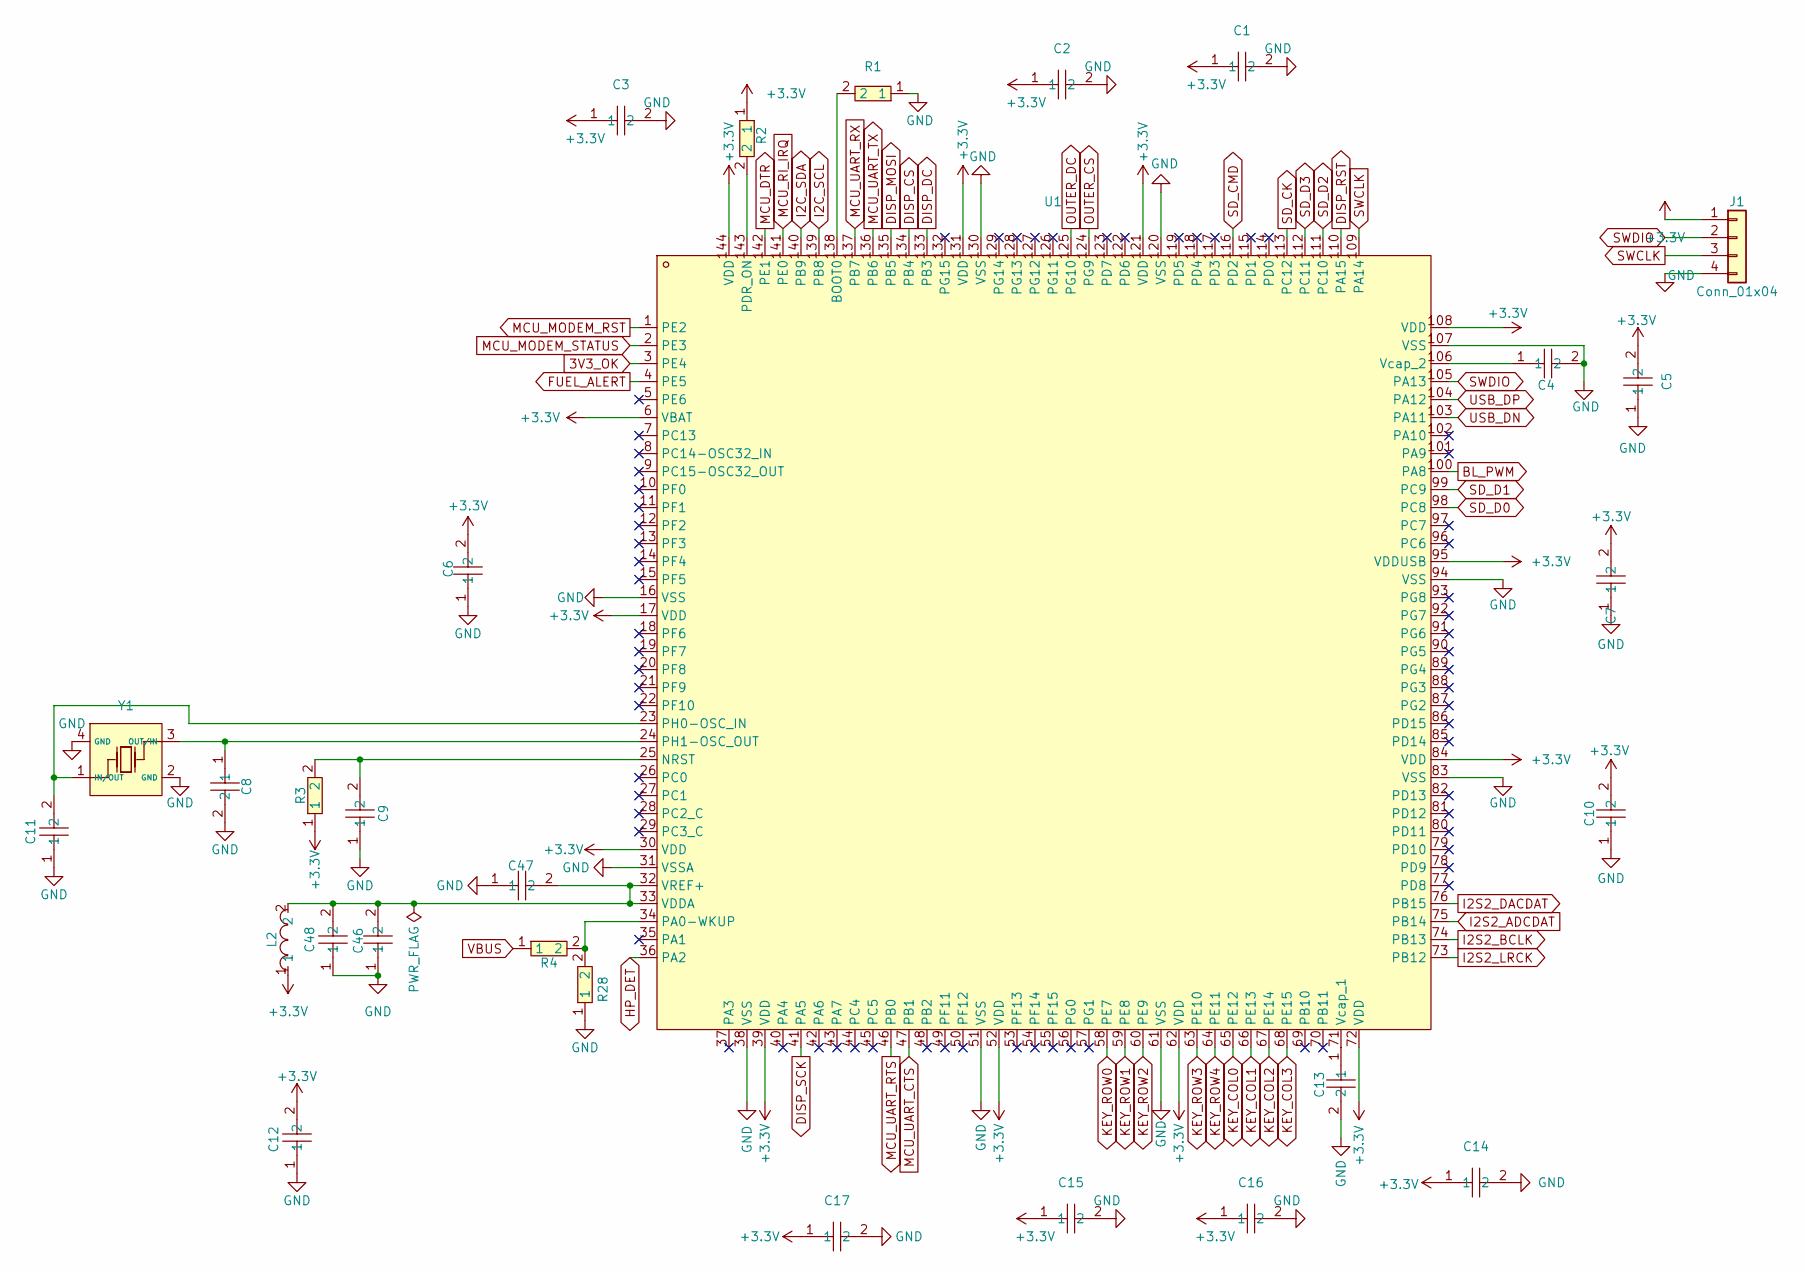
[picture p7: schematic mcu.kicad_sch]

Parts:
C1, C2, C3, C5, C6, C7, C9, C10, C12, C14, C15, C16, C17: 100nF; C0603
C4, C13: 2.2uF; C0603
C8, C11: 22pF; C0603
C46, C47: CC0603KRX7R9BB104; C0603; MPN CC0603KRX7R9BB104; LCSC Part C14663
C48: 1uF; C0603; MPN GRM188R61C105KA93D; LCSC Part C77404
J1: Conn_01x04; PinHeader_1x04_P2.54mm_Vertical
L2: BLM18KG601SN1D; L0603; MPN BLM18KG601SN1D; LCSC Part C85833
R1, R2, R3: 10k; C0603
R4: 100k; R0603
R28: RC0603FR-0768KL; R0603; MPN RC0603FR-0768KL; LCSC Part C114633
U1: STM32H743ZIT6; LQFP-144_L20.0-W20.0-P0.50-LS22.0-BL
Y1: ECS-80-12-33Q-GN-TR; CRYSTAL-SMD_4P-L3.2-W2.5-BL

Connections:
3V3_OK: U1.3 (PE4); also elsewhere on the board
+3.3V: C1.1, C2.1, C3.1, C5.2, C6.2, C7.2, C10.2, C12.2, C14.1, C15.1, C16.1, C17.1, J1.1, L2.1, R2.1, R3.1, U1.6 (VBAT), U1.17 (VDD), U1.30 (VDD), U1.39 (VDD), U1.52 (VDD), U1.62 (VDD), U1.72 (VDD), U1.84 (VDD), U1.95 (VDDUSB), U1.108 (VDD), U1.121 (VDD), U1.131 (VDD), U1.144 (VDD); also elsewhere on the board
BL_PWM: U1.100 (PA8); also elsewhere on the board
DISP_CS: U1.134 (PB4); also elsewhere on the board
DISP_DC: U1.133 (PB3); also elsewhere on the board
DISP_MOSI: U1.135 (PB5); also elsewhere on the board
DISP_RST: U1.110 (PA15); also elsewhere on the board
DISP_SCK: U1.41 (PA5); also elsewhere on the board
FUEL_ALERT: U1.4 (PE5); also elsewhere on the board
GND: C1.2, C2.2, C3.2, C4.2, C5.1, C6.1, C7.1, C8.2, C9.1, C10.1, C11.1, C12.1, C13.2, C14.2, C15.2, C16.2, C17.2, C46.1, C47.1, C48.1, J1.4, R1.1, R28.1, U1.16 (VSS), U1.31 (VSSA), U1.38 (VSS), U1.51 (VSS), U1.61 (VSS), U1.83 (VSS), U1.94 (VSS), U1.107 (VSS), U1.120 (VSS), U1.130 (VSS), Y1.2 (GND), Y1.4 (GND); also elsewhere on the board
HP_DET: U1.36 (PA2)
I2C_SCL: U1.139 (PB8); also elsewhere on the board
I2C_SDA: U1.140 (PB9); also elsewhere on the board
I2S2_ADCDAT: U1.75 (PB14); also elsewhere on the board
I2S2_BCLK: U1.74 (PB13); also elsewhere on the board
I2S2_DACDAT: U1.76 (PB15); also elsewhere on the board
I2S2_LRCK: U1.73 (PB12); also elsewhere on the board
KEY_COL0: U1.65 (PE12); also elsewhere on the board
KEY_COL1: U1.66 (PE13); also elsewhere on the board
KEY_COL2: U1.67 (PE14); also elsewhere on the board
KEY_COL3: U1.68 (PE15); also elsewhere on the board
KEY_ROW0: U1.58 (PE7); also elsewhere on the board
KEY_ROW1: U1.59 (PE8); also elsewhere on the board
KEY_ROW2: U1.60 (PE9); also elsewhere on the board
KEY_ROW3: U1.63 (PE10); also elsewhere on the board
KEY_ROW4: U1.64 (PE11); also elsewhere on the board
MCU_DTR: U1.142 (PE1); also elsewhere on the board
MCU_MODEM_RST: U1.1 (PE2); also elsewhere on the board
MCU_MODEM_STATUS: U1.2 (PE3); also elsewhere on the board
MCU_RI_IRQ: U1.141 (PE0); also elsewhere on the board
MCU_UART_CTS: U1.47 (PB1); also elsewhere on the board
MCU_UART_RTS: U1.46 (PB0); also elsewhere on the board
MCU_UART_RX: U1.137 (PB7); also elsewhere on the board
MCU_UART_TX: U1.136 (PB6); also elsewhere on the board
unnamed: R1.2, U1.138 (BOOT0)
unnamed: C9.2, R3.2, U1.25 (NRST)
unnamed: R4.2, R28.2, U1.34 (PA0-WKUP)
unnamed: R2.2, U1.143 (PDR_ON)
unnamed: C11.2, U1.23 (PH0-OSC_IN), Y1.1 (IN/OUT)
unnamed: C8.1, U1.24 (PH1-OSC_OUT), Y1.3 (OUT/IN)
unnamed: C46.2, C47.2, C48.2, L2.2, U1.32 (VREF+), U1.33 (VDDA)
unnamed: C13.1, U1.71 (Vcap_1)
unnamed: C4.1, U1.106 (Vcap_2)
OUTER_CS: U1.124 (PG9); also elsewhere on the board
OUTER_DC: U1.125 (PG10); also elsewhere on the board
SD_CK: U1.113 (PC12); also elsewhere on the board
SD_CMD: U1.116 (PD2); also elsewhere on the board
SD_D0: U1.98 (PC8); also elsewhere on the board
SD_D1: U1.99 (PC9); also elsewhere on the board
SD_D2: U1.111 (PC10); also elsewhere on the board
SD_D3: U1.112 (PC11); also elsewhere on the board
SWCLK: J1.3, U1.109 (PA14)
SWDIO: J1.2, U1.105 (PA13)
USB_DN: U1.103 (PA11); also elsewhere on the board
USB_DP: U1.104 (PA12); also elsewhere on the board
VBUS: R4.1; also elsewhere on the board

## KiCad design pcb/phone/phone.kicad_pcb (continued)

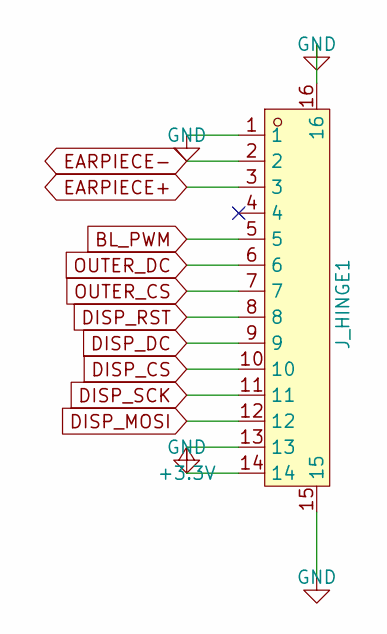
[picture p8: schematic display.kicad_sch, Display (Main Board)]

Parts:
J_HINGE1: 0.5K-HX-14PWB; FPC-SMD_14P-P0.50_HDGC_0.5K-HX-14PWB

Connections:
+3.3V: J_HINGE1.14; also elsewhere on the board
BL_PWM: J_HINGE1.5; also elsewhere on the board
DISP_CS: J_HINGE1.10; also elsewhere on the board
DISP_DC: J_HINGE1.9; also elsewhere on the board
DISP_MOSI: J_HINGE1.12; also elsewhere on the board
DISP_RST: J_HINGE1.8; also elsewhere on the board
DISP_SCK: J_HINGE1.11; also elsewhere on the board
EARPIECE+: J_HINGE1.3; also elsewhere on the board
EARPIECE-: J_HINGE1.2; also elsewhere on the board
GND: J_HINGE1.1, J_HINGE1.13, J_HINGE1.15, J_HINGE1.16; also elsewhere on the board
OUTER_CS: J_HINGE1.7; also elsewhere on the board
OUTER_DC: J_HINGE1.6; also elsewhere on the board

Board: 2 copper layers, 130 parts (0 on the bottom side), 104 nets, no tracks yet.

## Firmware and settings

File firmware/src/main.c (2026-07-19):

/*
 * SPDX-License-Identifier: Apache-2.0
 *
 * main.c — Phone firmware entry point
 *
 * VoLTE phone with display: places/receives calls via AT commands to
 * the SIM7600 modem, and shows call status on the ST7789V display.
 *
 * Architecture:
 *   - ISR (interrupt service routine): fires when the UART hardware
 *     receives a character. Reads from the hardware FIFO into a ring
 *     buffer. Runs in interrupt context — must be fast, no sleeping,
 *     no logging, no blocking.
 *   - Ring buffer: a circular queue. ISR writes to the tail, app
 *     reads from the head. Single-producer (ISR) / single-consumer
 *     (app) = no locking needed.
 *   - Application code: reads from the ring buffer with timeout.
 *     Can sleep while waiting (k_msleep) — no CPU spinning. This is
 *     the key advantage over polling: the app can do other work
 *     (render UI, process keypad) and the ISR catches every character
 *     that arrives, including async URCs like incoming-call notifications.
 *   - Display: ST7789V 2.0" 240×320 TFT on SPI1. LVGL renders text
 *     labels for call status (state, phone number, info line).
 *
 * Hardware connection (Waveshare HAT → Nucleo):
 *   HAT TXD  →  Nucleo PB7  (LPUART1_RX, Arduino D0)
 *   HAT RXD  →  Nucleo PB6  (LPUART1_TX, Arduino D1)
 *   HAT GND  →  Nucleo GND
 *
 * Display connection (Waveshare 2" LCD → Nucleo Arduino header):
 *   LCD VCC → 3.3V
 *   LCD GND → GND
 *   LCD DIN → D11 (PB5, SPI1 MOSI)
 *   LCD CLK → D13 (PA5, SPI1 SCK)
 *   LCD CS  → D10 (PD14, SPI1 CS)
 *   LCD DS  → D9  (PD15, Data/Command)
 *   LCD RST → D8  (PF3,  Reset)
 *   LCD BL  → D7  (PG12, Backlight)
 *
 * Keypad connection (Adafruit 4×4 membrane → Nucleo Arduino header):
 *   R1 → D3  (PE13, row 0)    C1 → A1  (PC0,  col 0)
 *   R2 → D4  (PE14, row 1)    C2 → A2  (PC3,  col 1)
 *   R3 → D5  (PE11, row 2)    C3 → A3  (PB1,  col 2)
 *   R4 → D6  (PE9,  row 3)    C4 → D2  (PG14, col 3)
 *
 * The Waveshare HAT has an onboard voltage translator (1.8V ↔ 3.3V).
 * On the final custom PCB, a TXB0108 will be needed between the
 * STM32H743 and the SIM7600NA-H raw module pins.
 */

#include <zephyr/kernel.h>
#include <zephyr/device.h>
#include <zephyr/drivers/uart.h>
#include <zephyr/drivers/display.h>
#include <zephyr/sys/ring_buffer.h>
#include <zephyr/logging/log.h>
#include <zephyr/input/input.h>
#include <zephyr/dt-bindings/input/input-event-codes.h>
#include <lvgl.h>
#include <stdio.h>
#include <string.h>

/* JetBrains Mono — custom LVGL bitmap fonts converted from the TTF
 * (see src/fonts/ and CMakeLists.txt). Three sizes:
 *   jetbrainsmono_10 — status bar (signal, time, battery)
 *   jetbrainsmono_14 — content, softkeys, menu, state labels
 *   jetbrainsmono_22 — dialer number, incall timer (hero content, bold) */
LV_FONT_DECLARE(jetbrainsmono_10);
LV_FONT_DECLARE(jetbrainsmono_14);
LV_FONT_DECLARE(jetbrainsmono_22);

LOG_MODULE_REGISTER(phone, LOG_LEVEL_INF);

/* LPUART1 is already configured in the board devicetree
 * (nucleo_h753zi.dts) at 115200 baud on PB6 (TX) / PB7 (RX). */
#define MODEM_UART_NODE DT_NODELABEL(lpuart1)

#define RX_RING_BUF_SIZE 1024
#define RESPONSE_TIMEOUT_MS 5000
#define RESPONSE_GAP_TIMEOUT_MS 500

static const struct device *modem_uart;

/* Ring buffer for received data.
 * The ISR writes incoming characters here; the application reads
 * them out. This decouples the fast ISR from the slower app code. */
RING_BUF_DECLARE(rx_ringbuf, RX_RING_BUF_SIZE);

/* UART interrupt service routine.
 * This runs in interrupt context — not a normal thread. It preempts
 * whatever the CPU was doing and must return quickly. Rules:
 *   - No sleeping (k_sleep, k_msleep — would crash)
 *   - No logging (LOG_INF — too slow, can deadlock)
 *   - No blocking calls
 *   - Just grab the data and get out
 *
 * Flow:
 *   1. uart_irq_update() — refresh the IRQ status (must call first)
 *   2. uart_irq_rx_ready() — check if RX data is available
 *   3. uart_fifo_read() — pull bytes from the hardware FIFO
 *   4. ring_buf_put() — store them in the ring buffer
 *
 * We read in chunks (up to 32 bytes at a time) because the UART FIFO
 * may have accumulated multiple characters between interrupts. */
static void modem_uart_isr(const struct device *dev, void *user_data)
{
    ARG_UNUSED(user_data);

    uart_irq_update(dev);

    if (uart_irq_rx_ready(dev)) {
        uint8_t read_buf[32];
        int len;

        /* Drain the hardware FIFO — keep reading until it's empty.
         * If we only read once, characters that arrived between
         * interrupts would be lost when the next byte overwrites
         * the FIFO. */
        while ((len = uart_fifo_read(dev, read_buf, sizeof(read_buf))) > 0) {
            ring_buf_put(&rx_ringbuf, read_buf, len);
        }
    }
}

/* Drain any pending data from the ring buffer.
 * Call this before sending a command to discard stale data. */
static void modem_drain(void)
{
    uint8_t tmp[64];
    while (ring_buf_get(&rx_ringbuf, tmp, sizeof(tmp)) > 0) {
        /* discard */
    }
}

/* Send a string to the modem.
 * uart_poll_out is fine for TX — it's synchronous (we send a command
 * then wait for the response). TX doesn't need interrupts because
 * we're never sending data asynchronously. */
static void modem_send(const char *cmd)
{
    LOG_INF("TX> %s", cmd);
    for (size_t i = 0; cmd[i] != '\0'; i++) {
        uart_poll_out(modem_uart, cmd[i]);
    }
}

/* Read modem response from the ring buffer with timeout.
 * This is application-level code — runs in a normal thread context
 * and can sleep. Returns when:
 *   - Overall timeout expires (RESPONSE_TIMEOUT_MS)
 *   - We got data but no new chars for RESPONSE_GAP_TIMEOUT_MS
 *   - Buffer is full
 *
 * The key difference from polling: we sleep with k_msleep(1) instead
 * of k_busy_wait(50). The ISR is catching characters into the ring
 * buffer in the background, so we don't need to poll frantically.
 * We can sleep peacefully and check the buffer periodically. */
static int modem_read(char *buf, size_t buf_size)
{
    size_t pos = 0;
    int64_t start = k_uptime_get();
    int64_t last_char = start;

    while (pos < buf_size - 1) {
        uint8_t ch;

        if (ring_buf_get(&rx_ringbuf, &ch, 1) == 1) {
            buf[pos++] = (char)ch;
            last_char = k_uptime_get();
            continue;
        }

        /* No data available — sleep and check timeouts.
         * k_msleep(1) is fine here because the ISR is filling the
         * ring buffer in the background. We won't miss anything. */
        k_msleep(1);
        int64_t now = k_uptime_get();
        if (now - start > RESPONSE_TIMEOUT_MS) {
            break;
        }
        if (pos > 0 && now - last_char > RESPONSE_GAP_TIMEOUT_MS) {
            break;
        }
    }

    buf[pos] = '\0';
    return pos;
}

/* Send an AT command and log the response. */
static void modem_at(const char *cmd)
{
    char rx_buf[512];

    modem_drain();
    modem_send(cmd);
    int len = modem_read(rx_buf, sizeof(rx_buf));
    if (len > 0) {
        LOG_INF("RX< %s", rx_buf);
    } else {
        LOG_WRN("No response (timeout %d ms)", RESPONSE_TIMEOUT_MS);
    }
    k_msleep(200);
}

/* Read a complete line from the ring buffer (terminated by \n).
 * Returns the line length (excluding null terminator), or 0 on timeout.
 * This is used in the URC monitor loop to process one line at a time. */
static int modem_readline(char *buf, size_t buf_size, int timeout_ms)
{
    size_t pos = 0;
    int64_t start = k_uptime_get();

    while (pos < buf_size - 1) {
        uint8_t ch;

        if (ring_buf_get(&rx_ringbuf, &ch, 1) == 1) {
            buf[pos++] = (char)ch;
            if (ch == '\n') {
                break;
            }
            continue;
        }

        k_msleep(1);
        if (k_uptime_get() - start > timeout_ms) {
            break;
        }
    }

    buf[pos] = '\0';
    return pos;
}

/* Strip trailing \r\n from a line for cleaner logging. */
static void strip_crlf(char *s)
{
    size_t len = strlen(s);
    while (len > 0 && (s[len - 1] == '\r' || s[len - 1] == '\n')) {
        s[--len] = '\0';
    }
}

/* URC (unsolicited result code) monitor loop.
 *
 * After placing a call, the modem sends async notifications:
 *   "VOICE CALL: BEGIN\r\n"   — call connected
 *   "VOICE CALL: END: xxxxxx\r\n" — call ended (6-digit reason code)
 *   "RING\r\n"                — incoming call ringing
 *
 * This loop reads lines from the ring buffer and acts on them:
 *   - RING → automatically answer with ATA
 *   - VOICE CALL: BEGIN → log call connected
 *   - VOICE CALL: END → log call ended, exit loop
 *   - Anything else → log it (echoes, OK, etc.)
 *
 * This is the first real use of the interrupt-driven UART for async
 * events — the modem sends these at any time, and the ring buffer
 * catches them while we sleep in modem_readline(). */
/* --- Call state machine ---
 *
 * The phone is a state machine driven by two inputs:
 *   1. Keypad keys (via the gpio-kbd-matrix input driver → callback →
 *      key_msgq → main loop)
 *   2. Async URCs from the modem (RING, VOICE CALL: BEGIN/END)
 *
 * States:
 *   PHONE_IDLE     — waiting, display "Idle", digits accumulate in dial
 *                    string, A → place call (ATD<string>;)
 *   PHONE_CALLING  — outgoing call in progress, display "Calling..."
 *                    B → cancel (AT+CHUP), URC BEGIN → connected
 *   PHONE_RINGING  — incoming call, display "Incoming call"
 *                    A → answer (ATA), B → reject (AT+CHUP),
 *                    URC BEGIN → connected
 *   PHONE_CONNECTED — call active, display "Connected"
 *                     B → hang up (AT+CHUP), URC END → idle
 *
 * The keypad driver runs in its own thread and emits input events to
 * our callback, which queues key characters into key_msgq. The main
 * loop drains the queue and calls handle_key(). The modem URCs come
 * through the ring buffer (modem_readline).
 *
 * The main loop polls both: drain key_msgq, read a line from the modem
 * with a short timeout, then act based on current state.
 * lv_timer_handler() is called each iteration to keep LVGL rendering. */

#define DIAL_STRING_MAX 20

enum phone_state {
    PHONE_IDLE,
    PHONE_CALLING,
    PHONE_RINGING,
    PHONE_CONNECTED,
};

static enum phone_state call_state = PHONE_IDLE;

/* UI screen state — separate from call state. Call states (CALLING,
 * RINGING, CONNECTED) override the screen regardless of ui_screen.
 * When IDLE, ui_screen determines what's shown.
 *   UI_DIALER         — idle/dialer (digits, call, menu access)
 *   UI_MENU           — main menu (Contacts, Messages, Settings)
 *   UI_CONTACTS       — contacts list (scroll, open)
 *   UI_CONTACT_DETAIL — contact name + number + actions (Call/Text/Edit/Delete)
 *   UI_MESSAGES       — conversations list (scroll, open)
 *   UI_CONVERSATION   — message thread with a contact
 *   UI_COMPOSE        — SMS text entry (mock — doesn't actually send) */
enum ui_screen {
    UI_DIALER,
    UI_MENU,
    UI_CONTACTS,
    UI_CONTACT_DETAIL,
    UI_MESSAGES,
    UI_CONVERSATION,
    UI_COMPOSE,
};

static enum ui_screen ui_screen = UI_DIALER;

/* --- Mock data (matches ui-mockup/index.html) ---
 *
 * Contacts and messages are hardcoded arrays for now. Real persistence
 * (Zephyr settings subsystem) and real SMS (SIM7600 AT+CMGS/CMGR) are
 * future features — this is the UI port with sample data. */
struct contact {
    const char *name;
    const char *number;  /* digits only, no spaces — ready for ATD */
};

static const struct contact contacts[] = {
    {"ALICE", "16075551234"},
    {"BOB",   "16075559876"},
    {"MOM",   "16075550001"},
    {"DAD",   "16075550002"},
    {"JEN",   "12125554242"},
};
#define CONTACT_COUNT (sizeof(contacts) / sizeof(contacts[0]))

struct message {
    bool from_me;       /* true = sent by us, false = received */
    const char *text;
};

struct conversation {
    const char *contact_name;
    const struct message *messages;
    int msg_count;
};

static const struct message alice_msgs[] = {
    {false, "hey, are you free tonight?"},
    {true,  "yeah, what's up?"},
    {false, "movie at 8?"},
    {true,  "sounds great"},
};
static const struct message bob_msgs[] = {
    {false, "did you finish the thing?"},
    {true,  "almost, tomorrow morning"},
};
static const struct message mom_msgs[] = {
    {false, "call me when you can"},
};

static const struct conversation conversations[] = {
    {"ALICE", alice_msgs, 4},
    {"BOB",   bob_msgs,   2},
    {"MOM",   mom_msgs,   1},
};
#define CONV_COUNT (sizeof(conversations) / sizeof(conversations[0]))

/* --- Navigation state --- */
static const char * const menu_items[] = {"CONTACTS", "MESSAGES", "SETTINGS"};
#define MENU_COUNT (sizeof(menu_items) / sizeof(menu_items[0]))
static int menu_index = 0;

static int contacts_index = 0;       /* scroll position in contacts list */
static int current_contact = 0;      /* which contact's detail we're viewing */
static int contact_action_index = 0; /* scroll position in contact detail actions */
static const char * const contact_actions[] = {"CALL", "TEXT", "EDIT", "DELETE"};
#define CONTACT_ACTION_COUNT 4

static int messages_index = 0;       /* scroll position in messages list */
static int current_conv = 0;         /* which conversation we're viewing */
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
int main(void)
{
    LOG_INF("Phone firmware starting...");
    LOG_INF("Board: %s", CONFIG_BOARD);

    /* Initialize display */
    display_dev = DEVICE_DT_GET(DT_CHOSEN(zephyr_display));
    if (!device_is_ready(display_dev)) {
        LOG_ERR("Display not ready!");
        return -1;
    }
    LOG_INF("Display (ST7789V) ready");

    /* Build the LVGL UI — TE-inspired industrial design with CRT surface:
     *   status_bar (top, 22px): grey panel, signal | network | time
     *   content (middle): state label (top) + number label (center)
     *   softkey_bar (bottom, 26px): grey panel, A/B/C/D context hints
     *   Grey borders separate zones. Amber reserved for content only.
     *   Scanlines drawn behind everything for CRT phosphor depth. */
    lv_obj_t *screen = lv_screen_active();
    lv_obj_set_style_bg_color(screen, lv_color_hex(UI_COLOR_BG), LV_PART_MAIN);

    /* Scanline background — faint horizontal lines every 3px for CRT depth */
    lv_obj_add_event_cb(screen, scanline_draw_cb, LV_EVENT_DRAW_MAIN, NULL);

    /* Status bar — grey panel at top, grey border below */
    lv_obj_t *status_bar = lv_obj_create(screen);
    lv_obj_set_size(status_bar, 240, 22);
    lv_obj_align(status_bar, LV_ALIGN_TOP_LEFT, 0, 0);
    lv_obj_set_style_bg_color(status_bar, lv_color_hex(UI_COLOR_PANEL), LV_PART_MAIN);
    lv_obj_set_style_bg_opa(status_bar, LV_OPA_COVER, LV_PART_MAIN);
    lv_obj_set_style_border_side(status_bar, LV_BORDER_SIDE_BOTTOM, LV_PART_MAIN);
    lv_obj_set_style_border_color(status_bar, lv_color_hex(UI_COLOR_BORDER), LV_PART_MAIN);
    lv_obj_set_style_border_width(status_bar, 1, LV_PART_MAIN);
    lv_obj_set_style_pad_all(status_bar, 2, LV_PART_MAIN);
    lv_obj_set_scrollbar_mode(status_bar, LV_SCROLLBAR_MODE_OFF);

    signal_label = lv_label_create(status_bar);
    lv_obj_set_style_text_color(signal_label, lv_color_hex(UI_COLOR_AMBER), LV_PART_MAIN);
    lv_obj_set_style_text_font(signal_label, &jetbrainsmono_10, LV_PART_MAIN);
    lv_label_set_text(signal_label, "SIG:|||");
    lv_obj_align(signal_label, LV_ALIGN_LEFT_MID, 0, 0);

    time_label = lv_label_create(status_bar);
    lv_obj_set_style_text_color(time_label, lv_color_hex(UI_COLOR_AMBER), LV_PART_MAIN);
    lv_obj_set_style_text_font(time_label, &jetbrainsmono_10, LV_PART_MAIN);
    lv_label_set_text(time_label, "--:--");
    lv_obj_align(time_label, LV_ALIGN_CENTER, 0, 0);

    battery_label = lv_label_create(status_bar);
    lv_obj_set_style_text_color(battery_label, lv_color_hex(UI_COLOR_AMBER), LV_PART_MAIN);
    lv_obj_set_style_text_font(battery_label, &jetbrainsmono_10, LV_PART_MAIN);
    lv_label_set_text(battery_label, "BAT:|||");
    lv_obj_align(battery_label, LV_ALIGN_RIGHT_MID, 0, 0);

    /* Content labels — created hidden, shown per screen by ui_render().
     *   title_label  — 14px, top of content (screen titles, call state)
     *   hero_label   — 22px bold, center (dial number, compose text, call number)
     *   list_label   — 14px, top-left below title (multi-line lists)
     *   timer_label  — 22px, below hero (call timer on connected screen)
     *   cursor_label — small "_" that blinks, after hero (dialer/compose) */
    title_label = lv_label_create(screen);
    lv_obj_set_style_text_font(title_label, &jetbrainsmono_14, LV_PART_MAIN);
    lv_obj_set_style_text_color(title_label, lv_color_hex(UI_COLOR_AMBER), LV_PART_MAIN);
    lv_obj_align(title_label, LV_ALIGN_TOP_MID, 0, 30);
    lv_obj_add_flag(title_label, LV_OBJ_FLAG_HIDDEN);

    hero_label = lv_label_create(screen);
    lv_obj_set_style_text_font(hero_label, &jetbrainsmono_22, LV_PART_MAIN);
    lv_obj_set_style_text_color(hero_label, lv_color_hex(UI_COLOR_AMBER_BRIGHT), LV_PART_MAIN);
    lv_obj_align(hero_label, LV_ALIGN_CENTER, 0, 0);
    lv_obj_add_flag(hero_label, LV_OBJ_FLAG_HIDDEN);

    list_label = lv_label_create(screen);
    lv_obj_set_style_text_font(list_label, &jetbrainsmono_14, LV_PART_MAIN);
    lv_obj_set_style_text_color(list_label, lv_color_hex(UI_COLOR_AMBER), LV_PART_MAIN);
    lv_obj_align(list_label, LV_ALIGN_TOP_LEFT, 8, 50);
    lv_obj_add_flag(list_label, LV_OBJ_FLAG_HIDDEN);

    timer_label = lv_label_create(screen);
    lv_obj_set_style_text_font(timer_label, &jetbrainsmono_22, LV_PART_MAIN);
    lv_obj_set_style_text_color(timer_label, lv_color_hex(UI_COLOR_AMBER_BRIGHT), LV_PART_MAIN);
    lv_obj_align(timer_label, LV_ALIGN_CENTER, 0, 30);
    lv_obj_add_flag(timer_label, LV_OBJ_FLAG_HIDDEN);

    cursor_label = lv_label_create(screen);
    lv_obj_set_style_text_font(cursor_label, &jetbrainsmono_22, LV_PART_MAIN);
    lv_obj_set_style_text_color(cursor_label, lv_color_hex(UI_COLOR_AMBER_BRIGHT), LV_PART_MAIN);
    lv_label_set_text(cursor_label, "_");
    lv_obj_align_to(cursor_label, hero_label, LV_ALIGN_OUT_RIGHT_MID, 2, 0);
    lv_obj_add_flag(cursor_label, LV_OBJ_FLAG_HIDDEN);

    /* Start the blinking cursor animation (cursor_label visibility is
     * controlled by ui_render via LV_OBJ_FLAG_HIDDEN; the animation
     * toggles opacity when the label is visible). */
    cursor_anim_start();

    /* Soft-key bar — grey panel at bottom, grey border above */
    lv_obj_t *softkey_bar = lv_obj_create(screen);
    lv_obj_set_size(softkey_bar, 240, 26);
    lv_obj_align(softkey_bar, LV_ALIGN_BOTTOM_LEFT, 0, 0);
    lv_obj_set_style_bg_color(softkey_bar, lv_color_hex(UI_COLOR_PANEL), LV_PART_MAIN);
    lv_obj_set_style_bg_opa(softkey_bar, LV_OPA_COVER, LV_PART_MAIN);
    lv_obj_set_style_border_side(softkey_bar, LV_BORDER_SIDE_TOP, LV_PART_MAIN);
    lv_obj_set_style_border_color(softkey_bar, lv_color_hex(UI_COLOR_BORDER), LV_PART_MAIN);
    lv_obj_set_style_border_width(softkey_bar, 1, LV_PART_MAIN);
    lv_obj_set_style_pad_all(softkey_bar, 4, LV_PART_MAIN);
    lv_obj_set_scrollbar_mode(softkey_bar, LV_SCROLLBAR_MODE_OFF);

    softkey_label = lv_label_create(softkey_bar);
    lv_obj_set_style_text_color(softkey_label, lv_color_hex(UI_COLOR_AMBER), LV_PART_MAIN);
    lv_obj_set_style_text_font(softkey_label, &jetbrainsmono_14, LV_PART_MAIN);
    lv_label_set_text(softkey_label, "");
    lv_obj_align(softkey_label, LV_ALIGN_CENTER, 0, 0);

    /* Boot screen — show "BOOTING..." as title before UI is ready */
    lv_label_set_text(title_label, "BOOTING...");
    lv_obj_clear_flag(title_label, LV_OBJ_FLAG_HIDDEN);
    lv_timer_handler();
    display_blanking_off(display_dev);
    LOG_INF("Display UI initialized (TE industrial + CRT scanlines)");

    /* The keypad matrix driver is initialized automatically by Zephyr
     * (the gpio-kbd-matrix device is ready at boot). The input callback
     * is registered at compile time via INPUT_CALLBACK_DEFINE. No
     * explicit init needed here — just verify the device is ready. */
    const struct device *keypad = DEVICE_DT_GET(DT_NODELABEL(kbd_matrix));
    if (!device_is_ready(keypad)) {
        LOG_ERR("Keypad matrix device not ready!");
        return -1;
    }
    LOG_INF("Keypad (gpio-kbd-matrix) ready — type number, A=Call, B=End, C=Backspace");

    /* Initialize modem UART */
    modem_uart = DEVICE_DT_GET(MODEM_UART_NODE);
    if (!device_is_ready(modem_uart)) {
        LOG_ERR("Modem UART (LPUART1) not ready!");
        return -1;
    }
    LOG_INF("Modem UART (LPUART1) ready");

    uart_irq_callback_user_data_set(modem_uart, modem_uart_isr, NULL);
    uart_irq_rx_enable(modem_uart);
    LOG_INF("Modem UART RX interrupts enabled");

    LOG_INF("Waiting 3s for modem to settle...");
    lv_label_set_text(title_label, "INITIALIZING...");
    lv_label_set_text(softkey_label, "WAITING FOR MODEM");
    lv_timer_handler();
    k_sleep(K_SECONDS(3));

    /* Verify modem is alive and on the network */
    LOG_INF("--- Modem checks ---");
    modem_at("AT\r\n");
    modem_at("AT+CSQ\r\n");
    modem_at("AT+CEREG?\r\n");

    call_state = PHONE_IDLE;
    dial_len = 0;
    dial_string[0] = '\0';
    ui_render();
    LOG_INF("=== Phone ready — type a number and press A to call ===");

    /* Main loop: drain keypad key queue + poll modem URCs, act based on
     * call state. The keypad driver runs in its own thread and feeds
     * key_msgq; we drain it here. modem_readline has a short timeout so
     * we check the queue frequently. lv_timer_handler keeps LVGL rendering.
     * The call timer is updated here when connected. */
    while (1) {
        char line[256];
        char key;

        /* Process any pending keypad keys (from the input callback) */
        while (k_msgq_get(&key_msgq, &key, K_NO_WAIT) == 0) {
            LOG_INF("Key: %c (state=%d)", key, call_state);
            handle_key(key);
        }
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

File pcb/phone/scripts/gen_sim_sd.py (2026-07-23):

#!/usr/bin/env python3
"""Generate sim_sd.kicad_sch - SIM card + microSD card + ESD protection."""
import uuid

SIM_SD_SCH_UUID = '7fc639d9-249c-4f41-85eb-7c2617f3c206'
ROOT_UUID = '451c3b43-1616-42cb-bf96-d436f4db82c2'

# Component positions
J_SIM_X, J_SIM_Y = 140.0, 100.0
J_SD_X, J_SD_Y   = 200.0, 100.0
U10_X, U10_Y     = 95.0, 100.0    # ESD for SIM
U11_X, U11_Y     = 250.0, 100.0   # ESD for SD
C38_X, C38_Y     = 140.0, 130.0   # SIM decoupling
C39_X, C39_Y     = 200.0, 140.0   # SD decoupling
R15_X, R15_Y     = 95.0, 130.0    # SIM data pull-up

STUB = 5.08
PWR_START = 150

def gen_uuid():
    return str(uuid.uuid4())

# Pin offsets from symbol definitions (relative to symbol origin)
SIM_PINS = {
    1: (-8.89, 6.35),    # VCC
    2: (-8.89, 3.81),    # RST
    3: (-8.89, 1.27),    # CLK
    5: (-8.89, -1.27),   # GND
    6: (-8.89, -3.81),   # VPP
    7: (-8.89, -6.35),   # I/O
    8: (8.89, -6.35),    # GND
    9: (8.89, -3.81),    # GND
    10: (8.89, 3.81),    # GND
    11: (8.89, 6.35),    # GND
}

SD_PINS = {
    1: (-10.16, 8.89),   # DAT2
    2: (-10.16, 6.35),   # CD/DAT3
    3: (-10.16, 3.81),   # CMD
    4: (-10.16, 1.27),   # VDD
    5: (-10.16, -1.27),  # CLK
    6: (-10.16, -3.81),  # VSS
    7: (-10.16, -6.35),  # DAT0
    8: (-10.16, -8.89),  # DAT1
    9: (10.16, -3.81),   # Shell/CD
    10: (10.16, -1.27),  # Shell
    11: (10.16, 1.27),   # Shell
    12: (10.16, 3.81),   # Shell
}

ESD_PINS = {
    1: (-13.97, 5.08),   # IO1
    2: (-13.97, 0),      # GND
    3: (-13.97, -5.08),  # IO2
    4: (13.97, -5.08),   # IO3
    5: (13.97, 0),       # IO4
    6: (13.97, 5.08),    # IO5
}

def fw(x1, y1, x2, y2):
    return '\t\t(wire\n\t\t\t(pts\n\t\t\t\t(xy %.2f %.2f) (xy %.2f %.2f)\n\t\t\t)\n\t\t\t(stroke\n\t\t\t\t(width 0)\n\t\t\t\t(type default)\n\t\t\t)\n\t\t\t(uuid "%s")\n\t\t)\n' % (x1, y1, x2, y2, gen_uuid())

def fgl(name, shape, x, y, orient):
    j = 'left' if orient == 0 else ('right' if orient == 180 else ('bottom' if orient == 90 else 'top'))
    s = '\t\t(global_label "%s"\n' % name
    s += '\t\t\t(shape %s)\n' % shape
    s += '\t\t\t(at %.2f %.2f %d)\n' % (x, y, orient)
    s += '\t\t\t(fields_autoplaced yes)\n'
    s += '\t\t\t(effects\n\t\t\t\t(font\n\t\t\t\t\t(size 1.27 1.27)\n\t\t\t\t)\n'
    s += '\t\t\t\t(justify %s)\n\t\t\t)\n' % j
    s += '\t\t\t(uuid "%s")\n' % gen_uuid()
    s += '\t\t\t(property "Intersheetrefs" "${INTERSHEET_REFS}"\n'
    s += '\t\t\t\t(at %.2f %.2f 0)\n' % (x, y)
    s += '\t\t\t\t(hide yes) (show_name no) (do_not_autoplace no)\n'
    s += '\t\t\t\t(effects\n\t\t\t\t\t(font\n\t\t\t\t\t\t(size 1.27 1.27)\n\t\t\t\t\t)\n'
    s += '\t\t\t\t\t(justify %s)\n\t\t\t\t)\n\t\t\t)\n\t\t)\n' % j
    return s

def fnc(x, y):
    return '\t\t(no_connect (at %.2f %.2f) (uuid "%s"))\n' % (x, y, gen_uuid())

def fpwr(lib_id, x, y, rot, ref, path):
    u = gen_uuid(); pu = gen_uuid()
    if '+3.3V' in lib_id:
        val = '+3.3V'; desc = 'Power symbol creates a global label with name \\"+3.3V\\"'
    else:
        val = 'GND'; desc = 'Power symbol creates a global label with name \\"GND\\" , ground'
    s = '\t\t(symbol\n'
    s += '\t\t\t(lib_id "%s")\n' % lib_id
    s += '\t\t\t(at %.2f %.2f %d)\n' % (x, y, rot)
    s += '\t\t\t(unit 1) (body_style 1) (exclude_from_sim no) (in_bom yes) (on_board yes) (in_pos_files yes) (dnp no) (fields_autoplaced yes)\n'
    s += '\t\t\t(uuid "%s")\n' % u
    s += '\t\t\t(property "Reference" "%s"\n' % ref
    s += '\t\t\t\t(at %.2f %.2f 0)\n' % (x, y)
    s += '\t\t\t\t(hide yes) (show_name no) (do_not_autoplace no)\n'
    s += '\t\t\t\t(effects (font (size 1.27 1.27)))\n\t\t\t)\n'
    s += '\t\t\t(property "Value" "%s"\n' % val
    s += '\t\t\t\t(at %.2f %.2f 0)\n' % (x, y)
    s += '\t\t\t\t(show_name no) (do_not_autoplace no)\n'
    s += '\t\t\t\t(effects (font (size 1.27 1.27)))\n\t\t\t)\n'
    s += '\t\t\t(property "Footprint" ""\n'
    s += '\t\t\t\t(at %.2f %.2f 0)\n' % (x, y)
    s += '\t\t\t\t(hide yes) (show_name no) (do_not_autoplace no)\n'
    s += '\t\t\t\t(effects (font (size 1.27 1.27)))\n\t\t\t)\n'
    s += '\t\t\t(property "Datasheet" ""\n'
    s += '\t\t\t\t(at %.2f %.2f 0)\n' % (x, y)
    s += '\t\t\t\t(hide yes) (show_name no) (do_not_autoplace no)\n'
    s += '\t\t\t\t(effects (font (size 1.27 1.27)))\n\t\t\t)\n'
    s += '\t\t\t(property "Description" "%s"\n' % desc
    s += '\t\t\t\t(at %.2f %.2f 0)\n' % (x, y)
    s += '\t\t\t\t(hide yes) (show_name no) (do_not_autoplace no)\n'
    s += '\t\t\t\t(effects (font (size 1.27 1.27)))\n\t\t\t)\n'
    s += '\t\t\t(pin "1" (uuid "%s"))\n' % pu
    s += '\t\t\t(instances (project "phone" (path "%s" (reference "%s") (unit 1))))\n' % (path, ref)
    s += '\t\t)\n'
    return s

def extract_sym(filepath, name):
    with open(filepath, 'r', encoding='utf-8') as f:
        c = f.read()
    m = '(symbol "' + name + '"'
    s = c.find(m)
    if s == -1:
        raise ValueError(name + ' not found in ' + filepath)
    d = 0; i = s
    while i < len(c):
        if c[i] == '(':
            d += 1
        elif c[i] == ')':
            d -= 1
            if d == 0:
                return c[s:i+1]
        i += 1

def fix_libid(sym, prefix):
    return sym.replace('(symbol "', '(symbol "' + prefix + ':', 1)
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

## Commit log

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2026-07-06 Add Zephyr firmware app skeleton; rename project dir (spaces break Zephyr)
    Create firmware/ directory with Zephyr application structure:
    - CMakeLists.txt (build manifest)
    - prj.conf (Kconfig: shell, logging, 4KB heap)
    - app.overlay (devicetree placeholder — grows incrementally)
    - src/main.c (heartbeat skeleton with LOG_INF)
    Build verified against nucleo_h753zi: 60KB flash (3%), 32KB RAM (3%).
    Renamed project dir from "Personal Projects" to "personal_projects" —
    Zephyr's devicetree preprocessor splits paths at spaces, causing fatal
    build errors. Updated AGENTS.md with firmware build command and path
    constraint note. Added firmware/build/ to .gitignore.
    Generated with [Devin](https://dev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
    [main.c]
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2026-07-14 MVP: MCU places/receives VoLTE calls with display + button control
    Established the full MCU-to-modem control path on STM32H753ZI + SIM7600NA-H:
    - Interrupt-driven UART with 1KB ring buffer (replaces polling - catches
    async URCs like RING without losing data)
    - ST7789V 2.0" 240x320 TFT display on SPI1 with LVGL text UI
    (status/number/info labels, Montserrat 28 font)
    - B1 user button (PC13) drives 4-state call state machine:
    IDLE->call, CALLING->cancel, RINGING->answer, CONNECTED->hangup
    - AT+CHUP for voice call hangup (ATH returns OK but doesn't end VoLTE)
    - CONFIG_MAIN_STACK_SIZE=4096 (fixed MPU stack overflow from local buffers)
    MVP success criterion met: place and receive voice cal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
    [main.c]
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2026-07-19 Redesign UI to TE industrial aesthetic and port all mockup screens
    Replace 80s sci-fi HUD (amber on black) with Teenage Engineering-inspired
    industrial design: layered grey palette, grey panels/borders, amber reserved
    for content only. JetBrains Mono font (converted from TTF via lv_font_conv)
    in 3 sizes replaces Unscii. Status bar: signal/time/battery (carrier removed).
    Migrate all 10 screens from the HTML mockup to LVGL firmware with mock data:
    dialer (blinking cursor), menu, contacts list, contact detail (real ATD call),
    messages list, conversation view, SMS compose (mock send), in-call (live timer),
    incoming, calling. Unified ui_render() architecture with 5 flexible labels.
    Add .gitigno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
    [main.c]
2026-07-19 Build KiCad parts library from JLC/LCSC + lock assembly method
    Downloaded 12 parts (9 ICs + 3 passives/LED) from LCSC via easyeda2kicad
    into pcb/phone/lib/ (KiCad V6+ format). Swapped clone parts for OEM
    (ST USBLC6/ESDA6V1, TI TXB0108PWR). Assembly method locked: JLCPCB PCBA,
    2-board MOQ — cheapest option, LCSC integration, consignment for 2 parts
    not on JLC (MAX9880A, TPS630201). Created parts-sourcing revisit prompt
    for remaining 13 items (2 ICs, 8 mechanical parts, 3 design decisions).
    Updated block diagram, BOM, constraints, project log, tracking doc.
    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
    [JLCPCB_BOM.xls, phone.kicad_pcb, phone.kicad_sch]
2026-07-19 Lock outer display + all FPC ZIF connectors
    Outer display re-selected from Wisevision N114 (0.7mm pitch — no JLC
    connectors exist) to EastRising ER-TFT1.14-2 (BuyDisplay, 8-pin 0.5mm
    FPC, ST7789V, $3.27). Both display panels purchased separately from PCB
    and assembled by user (ZIF plugs in post-assembly).
    All four FPC connectors locked to HDGC 0.5K-HX series (same series,
    hinged lid, double-sided contacts, 1mm height):
    - J7: 0.5K-HX-12PWB (C2919494) — main display
    - J10: 0.5K-HX-8PWB (C2919492) — outer display
    - J8/J9: 0.5K-HX-14PWB (C2919495) — hinge flex (2 qty)
    Double-sided contacts eliminate the top/bottom orientation risk for the
    main display FPC (datasheet mechanical drawing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
    [JLCPCB_BOM.xls]
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2026-07-22 Build power schematic + lock power IC pinouts/wiring
    Power section of phone.kicad_sch: USB-C (J1), MCP73831 charger (U6),
    TPS63021 buck-boost (U4), TPS7A02 LDO (U5), MAX17048 fuel gauge (U7),
    USBLC6-2 ESD (U10), J_BATT battery connector, STAT LED, passives.
    Documented pinouts/wiring for J1, U4, U5, U6, U7, U10 in block-diagram.md.
    Locked J_BATT = JST S2B-PH-SM4-TB (C295747). Resolved all power open
    questions: PG to MCU (EXTI + 10k pullup to +3.3V), TPS7A02 EN tie to IN,
    ALRT to MCU (EXTI + 10k pullup), I2C no conflict (MAX17048=0x36,
    ALC5651=0x1A), R_PROG=2k (500mA = 0.42C on 1200mAh), STAT=LED+470R.
    Corrections verified against datasheets: MAX17048 pinout (6 of 8 pins were
    wrong in docs,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
    [phone.kicad_sch]
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2026-07-22 Update schematic refs to new lib names + remove old library files
    - Update phone.kicad_sch: 46 symbol references changed from
    easyeda2kicad:SYMBOL to passives:/ics:/connectors:SYMBOL
    (19 unique symbols, both lib_id and symbol declarations)
    - Remove easyeda2kicad.kicad_sym (superseded by 4 split libraries)
    - Remove missing_parts.kicad_sym (merged into split libraries)
    - Remove superseded MAX9880A footprints (footprints.pretty/ — not tracked,
    removed from disk; MAX9880A was SUPERSEDED 2026-07-19 by ALC5651)
    - Remove superseded ultralibrarian.kicad_sym (MAX9880A symbol — not tracked,
    removed from disk)
    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
    [phone.kicad_sch]
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2026-07-23 WIP: mPCIe vs LGA modem exploration + connectors.kicad_sym encoding break
    Adds Mini PCIe connector (PCIE-52P40H_C444926) and footprint, plus
    modem_mpcie.kicad_sch / modem_lga.kicad_sch sheets to compare the two
    modem mounting options. Docs updated for the evaluation.
    NOTE: pcb/phone/lib/connectors.kicad_sym is currently broken -- a UTF-8
    BOM was prepended and all CJK strings got CP1252-mojibake'd (likely by
    a Windows editor saving the file). KiCad loads the library as empty
    because the S-expression parser chokes on the BOM before the opening
    paren. This commit preserves the broken state as a checkpoint; the
    encoding will be repaired in a follow-up commit.
    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
    [main.kicad_sch, modem_lga.kicad_sch, modem_mpcie.kicad_sch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]
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2026-07-23 Align docs to MPCIe modem plan: flat sheet + global labels
    Rewrite MCU<->Modem Link section in block-diagram.md for MPCIe variant:
    - 8 signals fit exactly one TXB0108 (6 UART + RST + STATUS), no second
    shifter needed (LGA needs 10+ with PWRKEY + DCD)
    - No PWRKEY on MPCIe edge connector (auto-powers on VCC, TBD with Techship)
    - WAKE# (pin 1) is a falling-edge interrupt, not a level-ready signal like
    LGA STATUS (pin 49) -- different semantics documented
    - Global label naming convention: MODEM_* (1.8V side), MCU_* (3.3V side),
    PCM_* (modem<->codec), USIM_* (modem<->SIM), MODEM_USB_* (modem USB)
    Fix USB naming conflict: modem USB renamed from USB_DP/USB_DN to
    MODEM_USB_DP/MODEM_USB_DN to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
    [main.kicad_sch, modem_lga.kicad_sch, modem_mpcie.kicad_sch]
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2026-07-23 Phase 3.2: Add MCU section (STM32H743ZIT6) to schematic
    - Placed U1 (STM32H743ZIT6, LQFP-144) at (99.06, 248.92)
    - 45 global labels on peripheral pins (UART, I2C, SPI, I2S2, SDMMC1,
    keypad, modem control, power monitoring, USB, SWD, backlight PWM)
    - 67 no-connect markers on unused/spare pins
    - 12x 100nF decoupling caps on VDD pins (C19-C30)
    - 2x 2.2uF VCAP caps on pins 71/106 (C17, C18)
    - 8MHz HSE crystal (Y1) + 2x 22pF load caps (C12, C13)
    - NRST: 10kΩ pullup (R8) + 100nF cap (C16)
    - BOOT0: 10kΩ pulldown (R9), PDR_ON: 10kΩ pullup (R10)
    - 59 power symbols for +3.3V/GND connections
    - ERC: 5 pre-existing power errors, 41 isolated-pin warnings (expected
    — external components not yet pl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
    [phone.kicad_sch]
2026-07-23 Phase 3.2 restructure: Split MCU into hierarchical sheet
    - Extract MCU section (STM32H743ZIT6 + decoupling + crystal) from root
    schematic into separate mcu.kicad_sch child sheet
    - Root phone.kicad_sch now contains only power section + hierarchical
    sheet box pointing to mcu.kicad_sch
    - Fixed label name conflicts: USB_DM -> USB_DN, PWR_3V3_OK -> 3V3_OK
    (to match power section canonical names)
    - Normalized lib_symbol indentation (subagent had inserted STM32/crystal
    at 4-tab instead of 2-tab)
    - Global labels kept (not converted to hierarchical labels) for cross-
    sheet connectivity without sheet pins
    - ERC: 5 pre-existing power errors, 41 warnings (39 isolated pins
    expected + 2 lib_sy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
    [mcu.kicad_sch, phone.kicad_sch]
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2026-07-23 Phase 3.3: Complete modem sheet + MCU power symbol cleanup
    Modem sheet (modem.kicad_sch):
    - MPCIe socket (U2), TXB0108 level shifter (U8), bulk caps (C31/C32), pullup (R11)
    - All 54 MPCIe pins wired: power, UART, PCM, USB, SIM, control signals
    - Power symbol lib_symbols extracted from KiCad power library
    - No PWR_FLAGs (power rails driven by root sheet regulators)
    - 0 ERC errors on modem sheet
    MCU sheet (mcu.kicad_sch):
    - Fixed 14 overlapping power symbol clusters (2.54mm -> 5.08mm+ spacing)
    - User manual pass: rotated and spaced components for readability
    - ERC unchanged: 5 pre-existing root sheet errors, 0 MCU errors
    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
    [mcu.kicad_sch]
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2026-07-23 Phase 3.4-3.8: Add codec, display, keypad sheets + cleanup temp files
    - codec.kicad_sch: ALC5651 codec, I2S level shifter, audio transducers
    - display.kicad_sch: main + outer display ZIF connectors, hinge flex
    - keypad.kicad_sch: 5x4 tactile switch matrix (20 switches)
    - phone.kicad_sch: added Codec, Display, Keypad sheet boxes
    - .gitignore: add ERC reports, kicad-cli output, MCP working files
    - Removed committed temp files (erc_*.txt, kicad_*.txt, output/)
    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
    [display.kicad_sch, keypad.kicad_sch, phone.kicad_sch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]
2026-07-23 Phase 3.6-3.7: Add SIM/SD sheet with ESD protection
    - sim_sd.kicad_sch: nano-SIM socket, microSD slot, 2x ESDA6V1-5SC6 ESD
    protection, decoupling caps, SIM data pull-up
    - phone.kicad_sch: added SIM_SD sheet box (page 7)
    - Fixed SD_CLK label to SD_CK to match MCU pin assignment
    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
    [phone.kicad_sch, sim_sd.kicad_sch]
2026-07-23 Fix keypad schematic: on-grid placement, correct matrix wiring, NC flags
    The keypad sheet had three issues from the subagent generation:
    1. All switches/wires/labels at 5mm spacing (off 1.27mm grid) causing
    endpoint_off_grid warnings and pin_not_connected errors
    2. Column wires connected to Pin1 X instead of Pin2 X, shorting rows
    to columns at every switch
    3. Row wires ran at Pin1 Y, passing through Pin2 positions
    Fix applied via fix_keypad_full.py:
    - Snapped all coordinates to 1.27mm grid (25.4mm switch spacing)
    - Row wires now run at SW_Y (switch center) with short vertical wires
    from Pin1 down to the row wire, avoiding Pin2 crossings
    - Row wires broken into segments between adjac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
    [keypad.kicad_sch]
2026-07-23 Fix display sheet: J_HINGE mounting tab pins 15/16 GND connection
    The J_HINGE connector (0.5K-HX-14PWB FPC) has 16 pins in its lib_symbol
    definition: 14 signal pins + 2 mounting tabs (pins 15/16). The mounting
    tabs need to be connected to GND.
    Two issues fixed:
    1. Removed phantom pin 15/16 definitions from the symbol instance that
    didn't match the 14-pin lib_symbol (but the lib_symbol itself does
    define 16 pins including the mounting tabs)
    2. The GND wires for pins 15/16 were 1.27mm short of the actual pin
    connection points. Extended wire endpoints from (133.81, 109.68) to
    (133.81, 108.41) and from (133.81, 151.59) to (133.81, 150.32) to
    reach the actual pin positions.
    Resul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
    [display.kicad_sch]
2026-07-24 Fix codec sheet: flip ALC5651-CG and TXB0108PWR embedded symbols Y-axis
    The codec subagent placed wires/NC flags at lib_symbol Y positions without
    accounting for KiCad's Y-axis negation when rendering symbols. This caused
    wires to connect to the wrong pins:
    - Wire at Y=152.86 (+3.3V) connected to Pin 19 (CPVPP) instead of Pin 1 (MICVDD)
    - Wire at Y=109.68 (+1V8) connected to Pin 2 (MICBIAS1) instead of Pin 18 (CPVDD)
    - NC flags were on the wrong pins
    - U9 (TXB0108PWR) had the same Y-mirroring issue
    Fix: flip Y coordinates in the embedded ALC5651-CG and TXB0108PWR symbol
    definitions in codec.kicad_sch only. This moves the pins to where the wires
    and NC flags already are, fixing all connecti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
    [codec.kicad_sch]
2026-07-24 Fix keypad: break column wires into segments at each Pin2 position
    Column wires were single long wires from (COL_X, 54.61) to (COL_X, 156.21).
    KiCad only connects wires to pins at endpoints/junctions, not midpoints.
    So Pin2 of SW5, SW9, SW13 (rows 1-3) were NOT connected to the column net.
    ERC didn't flag this because the pins are type "passive" (no ERC check
    for unconnected passive pins by default).
    Fix: Replace each long column wire with 6 segments between consecutive
    Pin2 positions (54.61, 80.01, 105.41, 130.81, 156.21) plus label and
    pull-down connections. Each Pin2 position is now a wire endpoint.
    Also removed orphaned junctions from the original generation.
    Result: Keypad sheet ERC-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
    [keypad.kicad_sch]
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2026-07-24 Split display sheet into main board + daughterboard
    The flip/clamshell design has two PCBs connected via hinge flex. The display
    sheet previously contained all display connectors on one sheet, which didn't
    match the physical architecture.
    Changes:
    - display.kicad_sch: Now contains ONLY J_HINGE (hinge flex connector) and
    its associated wires, labels, and power symbols. Title updated to
    "Display (Main Board)".
    - display_daughter.kicad_sch (new): Contains J_DISP (main display panel),
    J_DISP2 (outer display panel), J_EARPIECE (earpiece speaker), R14
    (backlight resistor), C37 (decoupling cap), and their associated wires,
    labels, and power symbols. Title: "Display Daughterboard".
    - phon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
    [display.kicad_sch, display_daughter.kicad_sch, phone.kicad_sch]
2026-07-24 Fix root sheet ERC errors: power pins and pin-to-pin conflicts
    Fixed all 5 ERC errors on the root sheet (power section):
    1. U4 (TPS63021DSJR) Pin 5 (VOUT): Changed from power_out to passive.
    Pin 4 and Pin 5 are both VOUT pins internally connected — having both
    as power_out causes a pin_to_pin conflict. Pin 4 remains power_out
    (drives +3.3V net), Pin 5 is now passive.
    2. U6 (MCP73831-2ACI_MC) Pin 4 (VBAT): Changed from power_out to passive.
    Pin 3 and Pin 4 are both VBAT pins internally connected — same issue.
    Pin 3 remains power_out (drives +BATT net), Pin 4 is now passive.
    3. U4 Pin 1 (VINA) not driven: Added +BATT power symbol (#PWR024) at
    (119.38, 44.45) connecting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
    [phone.kicad_sch]
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2026-07-24 User edits: keypad rewiring, sheet reorder, ERC severity reverts, R24 fix
    Keypad (keypad.kicad_sch):
    - Rotated all 20 switches 270 degrees for vertical contact orientation
    - Wired all 4 pins on each switch (pins 1&2 to column, pins 3&4 to row)
    - Removed all 37 no_connect markers on pins 3&4
    - Cleaned up to 25.4mm (1-inch) grid spacing
    - Added pull-down resistors to all 4 columns (was only KEY_COL3)
    Root sheet (phone.kicad_sch):
    - Reordered sub-sheet blocks (Display_Daughter before SIM_SD)
    - Cleaned up PWR_FLAG symbol formatting/indentation
    - Reordered PWR_FLAG and +BATT symbol placement
    - Repositioned +3.3V power symbol (#PWR32) at pin 190.5,200.66
    Project setti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
    [codec.kicad_sch, display.kicad_sch, display_daughter.kicad_sch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]
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2026-07-24 Add J_HINGE2 hinge connector to display daughterboard
    The display daughterboard (display_daughter.kicad_sch) was missing its
    hinge connector — it had J_DISP, J_DISP2, and J_EARPIECE but no connector
    to receive the flex cable from the main board's J_HINGE.
    Added J_HINGE2 (connectors:0.5K-HX-14PWB, 14-pin 0.5mm FPC) at (130, 130)
    with the same pin-to-net mapping as J_HINGE on the main board:
    Pin 1: +3.3V Pin 8: OUTER_CS Pin 15: GND (mounting)
    Pin 2: GND Pin 9: OUTER_DC Pin 16: GND (mounting)
    Pin 3: DISP_MOSI Pin 10: BL_PWM
    Pin 4: DISP_SCK Pin 11: NC (spare)
    Pin 5: DISP_CS Pin 12: EARPIECE+
    Pin 6: DISP_DC Pin 13: EARPIECE-
    Pin 7: DISP_RST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
    [display_daughter.kicad_sch]
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2026-07-24 Fix 32 of 35 lib_symbol_mismatch warnings by syncing embedded symbols
    Synced embedded lib_symbols in .kicad_sch files with library versions:
    - power.kicad_sch: Replaced PWR_FLAG with KiCad system library version
    (old embedded version was missing flag graphics, wrong pin angle/name,
    missing ki_keywords, empty description, reference not hidden)
    - power.kicad_sch: Replaced XFL4020-152MEC with library version
    (arc graphics reordered)
    - keypad.kicad_sch: Replaced SKQGABE010 with library version
    (graphics reordered + missing Manufacturer/MPN/LCSC properties)
    - keypad.kicad_sch: Replaced RC0603JR-0710KL with library version
    (missing Manufacturer/MPN/LCSC properties)
    - mcu.kicad_sch: STM32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
    [keypad.kicad_sch, mcu.kicad_sch, power.kicad_sch]
2026-07-24 Fix all 152 endpoint_off_grid warnings by snapping coordinates to 1.27mm grid
    The endpoint_off_grid warnings were caused by components placed at round mm
    coordinates (130, 230, 160, 200, 95, etc.) that are not multiples of KiCad's
    1.27mm default grid. The schematic symbols for all connectors (FPC 0.5mm,
    JST PH 2mm, MPCIe 0.8mm) use 2.54mm pin spacing which aligns to the 1.27mm
    grid — the warnings were NOT inherent to fine-pitch connectors.
    Fix: Applied a "snap to grid" operation to all (at X Y) and (xy X Y)
    coordinates in the post-lib_symbols section of 4 schematic files:
    - display.kicad_sch (90 off-grid coords fixed)
    - display_daughter.kicad_sch (212 off-grid coords fixed)
    - codec.kicad_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
    [codec.kicad_sch, display.kicad_sch, display_daughter.kicad_sch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]
2026-07-24 Fix all 9 isolated_pin_label warnings — 196→3 total warnings
    Removed 9 global labels for draft-state signals and replaced with no_connect
    markers. These signals were connected to only one pin (the source) with no
    destination component placed yet. The missing components (SWD header, load
    switch, VBUS divider, modem USB connector, net status LED) are deferred to
    a proper schematic editing session where lib_symbols can be added properly.
    Signals fixed (all marked no_connect, destination component deferred):
    - USIM_DET (modem): 6-pin SIM socket has no DET pin — not needed
    - SD_DET (sim_sd): Card detect will be polled in firmware — not needed
    - MODEM_USB_DN/DP (modem): Modem USB deferred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
    [mcu.kicad_sch, modem.kicad_sch, sim_sd.kicad_sch]
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2026-07-24 Add deferred components: VBUS divider, MCU_MODEM_PWR_EN pull-down, SWD header, NET_STATUS LED
    MCU sheet:
    - R11 (10k): MCU_MODEM_PWR_EN pull-down to GND
    - R12 (100k) + R13 (47k): VBUS_SENSE voltage divider from VBUS to GND
    - J3 (Conn_01x04): SWD programming header (SWCLK, SWDIO, +3.3V, GND)
    - Removed 4 no_connect markers (MCU_MODEM_PWR_EN, VBUS_SENSE, SWCLK, SWDIO)
    Modem sheet:
    - R12 (1k) + LED1 (LTST-C191TBKT): NET_STATUS indicator LED
    - Removed 1 no_connect marker (NET_STATUS)
    ERC: 0 errors, 4 warnings (all lib_symbol_mismatch — 3 pre-existing + 1 new for J3)
    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
    [mcu.kicad_sch, modem.kicad_sch]
2026-07-24 Add power slide switch, modem bulk caps, reverse load switch decision
    - SW1 (ALPS SSSS811101) added to power sheet: controls TPS63021 EN pin
    (ON: +BATT->R1->SW1->EN, OFF: EN->SW1->GND). Allows charging while off.
    - C40 (470uF tantalum) + C41/C42 (10uF ceramic) added to modem sheet
    near MPCIe VCC pins for 2A+ LTE burst handling.
    - Reversed load switch decision: SIM7600 sleep mode + PWRKEY make it
    redundant. Removed R11 (MCU_MODEM_PWR_EN pull-down), added no_connect
    on PE6.
    - Registered temp_switch/temp_470uf/temp_10uf libraries in sym-lib-table
    and fp-lib-table (resolves 3 library-link ERC warnings).
    - Final ERC: 0 errors, 6 warnings (all lib_symbol_mismatch, harmless).
    - Updated do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
    [mcu.kicad_sch, modem.kicad_sch, power.kicad_sch]
2026-07-24 Clean up pcb directory: remove one-off scripts, organize generators
    - Deleted 28 tracked one-off Python scripts (check_*, fix_*, cleanup_*,
    analyze_*, etc.) that were used during iterative schematic debugging.
    - Deleted 32 untracked scripts, 50+ ERC reports, lock files, and temp
    outputs from the working tree.
    - Moved 6 gen_*.py sheet generator scripts to pcb/phone/scripts/ with
    a README explaining their purpose and usage.
    - Updated .gitignore to prevent future accumulation of ERC reports,
    lock files, generated netlists, and one-off scripts.
    - pcb/phone/ now contains only KiCad project files (.kicad_sch, .kicad_pro,
    .kicad_pcb, .kicad_prl, sym-lib-table, fp-lib-table) + lib/ + scrip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
    [gen_codec_sch.py, gen_display_sch.py, gen_keypad_sch.py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]
2026-07-25 Cleanup: remove rejected part symbols, one-off scripts, stale datasheets
    - Remove 7 rejected symbols from easyeda2kicad.kicad_sym (PJ-327C-4A,
    PJ-3250-5A, PJ-3240-5A, TYPE-C16PLC-H10.0, PJ-327A5JJ, PJ-327-P5,
    TYPEC-306DDW-ARP16) — replaced by Tensility 54-00298 and GCT USB4085-GF-A
    - Delete 10 one-off inspection scripts (check_*.py, find_*.py, dump_*.py,
    extract_*.py) — keep only gen_*.py schematic generators
    - Delete rejected datasheets (pj3126-5a, pj3240-5a, pj3250-5a, pj3f07-5p,
    N114 superseded display)
    - Delete generated BOM/POS CSV files
    - Add alps-ssss2.pdf and gct-usb4085.pdf to reference README index
    - Include all schematic changes from previous sessions (SD pullups, VBUS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
    [codec.kicad_sch, display.kicad_sch, display_daughter.kicad_sch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]
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2026-07-29 Project file audit cleanup: delete stale files, merge temp libs, fix docs
    Delete stale/duplicate/garbage files identified by full project audit:
    - easyeda2kicad.kicad_sym + missing_parts.kicad_sym (stale 1-symbol
    duplicates of symbols already in main libs; rebuild workflow broken)
    - rebuild_lib.py + update_sch_refs.py + extract_pins.py (one-time
    migration scripts that no longer work — source files deleted)
    - add_headphone_jack.py (dangerous — wiped codec sheet 2026-07-28)
    - check_desc.py (one-off utility referencing stale file)
    - main.kicad_sch (empty orphan, not referenced by project)
    - bom_run.csv + 12 erc_*.txt + 2 ~*.lck (regenerable KiCad output)
    Merge temp libraries into main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
    [main.kicad_sch, modem.kicad_sch, power.kicad_sch]
2026-07-29 Fix top-level sheet: page numbering, title block, doc sync
    - Fix duplicate page number: Keypad was page 4 (same as Codec),
    renumbered to page 9. Pages now unique 1-9 across all sheets.
    - Add title block to root sheet with project metadata (title,
    date, rev, architecture summary comments).
    - Update block-diagram.md: document actual hierarchical schematic
    approach (was stale — said "flat, no hierarchical sheets").
    Old text struck through and marked SUPERSEDED.
    - Fix 3D model paths in 2 footprints (temp_470uf/temp_switch ->
    easyeda2kicad) to complete the library merge from prior commit.
    ERC validated: 0 errors, 15 warnings (all pre-existing, unchanged).
    Generated with [Devin](http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
    [phone.kicad_sch]
2026-07-29 Fix power sheet: isolate U8 VINA pin from +BATT, correct doc pin numbers
    VINA (U8 pin 1) was wrongly tied to +BATT. Per TI TPS63021 datasheet Rev G,
    VINA is internally supplied from VIN and must only connect to a 0.1uF bypass
    cap (C37) to GND. External wiring reintroduces switching noise TI eliminated.
    Added PWR_FLAG #FLG03 on the isolated VINA net to satisfy ERC.
    Also fixed block-diagram.md line 66: pins 10/11 are VIN (not VOUT), pin 12
    is EN. Corrected to "VIN (pin 10, 11) <- +BATT; VOUT (pin 4, 5) -> +3.3V"
    and added missing 2x 10uF input caps to the component list.
    ERC: 0 errors, 62 warnings (all pre-existing).
    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
    [power.kicad_sch]
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

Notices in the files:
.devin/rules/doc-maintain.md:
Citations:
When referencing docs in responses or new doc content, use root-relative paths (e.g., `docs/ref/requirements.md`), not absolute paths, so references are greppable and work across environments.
